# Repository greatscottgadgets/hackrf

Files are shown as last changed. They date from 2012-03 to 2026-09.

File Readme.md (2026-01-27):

# HackRF

This repository contains hardware designs and software for HackRF,
a low cost, open source Software Defined Radio platform.

HackRF One

(photo by fd0 from https://github.com/fd0/hackrf-one-pictures)

principal author: Michael Ossmann <mike@ossmann.com>

Information on HackRF and purchasing HackRF: https://greatscottgadgets.com/hackrf/

--------------------

# Documentation

Documentation for HackRF can be viewed on [Read the Docs](https://hackrf.readthedocs.io/en/latest/). The raw documentation files for HackRF are in the [docs folder](https://github.com/mossmann/hackrf/tree/master/docs) in this repository and can be built locally by installing [Sphinx Docs](https://www.sphinx-doc.org/en/master/usage/installation.html) and running `make html`. Documentation changes can be submitted through pull request and suggestions can be made as GitHub issues. 

To create a PDF of the HackRF documentation from the HackRF repository while on Ubuntu:
* run `sudo apt install latexmk texlive-latex-extra`
* navigate to hackrf/docs on command line
* run the command `make latex`
* run the command `make latexpdf`

--------------------

# Getting Help

Before asking for help with HackRF, check to see if your question is listed on the [troubleshooting page](https://hackrf.readthedocs.io/en/latest/troubleshooting.html).

For assistance with HackRF general use or development, please look at the [issues on the GitHub project](https://github.com/greatscottgadgets/hackrf/issues). This is the preferred place to ask questions so that others may locate the answer to your question in the future.

We invite you to join our community discussions on [Discord](https://discord.gg/rsfMw3rsU8). Note that while technical support requests are welcome here, we do not have support staff on duty at all times. Be sure to also submit an issue on GitHub if you've found a bug or if you want to ensure that your request will be tracked and not overlooked.

If you wish to see past discussions and questions about HackRF, you may also view the [mailing list archives](https://pairlist9.pair.net/pipermail/hackrf-dev/).

GitHub issues on this repository that are labelled "technical support" by Great Scott Gadgets employees can expect a response time of two weeks. We currently do not have expected response times for other GitHub issues or pull requests for this repository.

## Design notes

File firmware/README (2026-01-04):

The primary firmware source code for USB HackRF devices is hackrf_usb.  Most of
the other directories contain firmware source code for test and development.
The common directory contains source code shared by multiple HackRF firmware
projects.  The cpld directory contains HDL source for the CPLD.

The firmware is set up for compilation with the GCC toolchain available here:

https://developer.arm.com/open-source/gnu-toolchain/gnu-rm/downloads

Required dependency:

https://github.com/mossmann/libopencm3

If you are using git, the preferred way to install libopencm3 is to use the
submodule:

$ cd ..
$ git submodule init
$ git submodule update

To build and install a standard firmware image for HackRF One:

$ cd hackrf_usb
$ mkdir build
$ cd build
$ cmake ..
$ make
$ hackrf_spiflash -w hackrf_usb.bin

If you have a HackRF Pro, add -DBOARD=PRALINE to the cmake command.
If you have a Jawbreaker, add -DBOARD=JAWBREAKER to the cmake command.
If you have a rad1o, use -DBOARD=RAD1O instead.

If you get the "`arm-none-eabi-gcc` is not a full path and was not found in the PATH"
error during `cmake ..`, install the
[ARM GNU toolchain](https://developer.arm.com/Tools%20and%20Software/GNU%20Toolchain).
This toolchain is pre-packaged on many platforms and distributions, e.g. on Debian/Ubuntu
you can run `sudo apt-get install gcc-arm-none-eabi` to install it.

If you get the "ModuleNotFoundError: No module named 'yaml'" error during `make`,
run `pip install pyyaml` to install the Python yaml pip package.

It is possible to use a USB Device Firmware Upgrade (DFU) method to load
firmware into RAM.  This is normally only required to recover a device that has
had faulty firmware loaded, but it can also be useful for firmware developers.

For loading firmware into RAM with DFU you will need:

http://dfu-util.sourceforge.net/

To start up HackRF One or HackRF Pro in DFU mode, hold down the DFU button
while powering it on or while pressing and releasing the RESET button.  Release
the DFU button after the 3V3 LED illuminates.

A .dfu file is built by default when building firmware.  Alternatively you can
use a known good .dfu file from a release package.  Load the firmware into RAM
with:

$ dfu-util --device 1fc9:000c --alt 0 --download hackrf_usb.dfu

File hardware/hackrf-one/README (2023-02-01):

HackRF One is a wideband software radio transceiver with a USB interface.

hardware notes:

Schematic and layout files were designed in KiCad, an open source electronic
design automation package.

order of copper layers:
    Copper 1:  C1F (front)
    Copper 2:  C2
    Copper 3:  C3
    Copper 4:  C4B (back)

PCB description: 4 layer PCB 1.6 mm
    Copper    1   0.035 mm
    Prepreg 1-2   0.2104 mm
    Copper    2   0.0152 mm
    Core    2-3   1.065 mm
    Copper    3   0.0152 mm
    Prepreg 3-4   0.2104 mm
    Copper    4   0.035 mm

7628 prepreg with Er=4.6 (+/- 0.1)
required impedance: 50 ohm (+/- 5%) 11.55 mil microstrip impedance
double side solder mask green
single side silkscreen white
5 mil min trace width and
5 mil min isolation

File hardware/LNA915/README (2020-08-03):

Copyright (c) 2014-2020 Great Scott Gadgets <info@greatscottgadgets.com>

These files are part of HackRF.

This is a free hardware design; you can redistribute it and/or modify
it under the terms of the GNU General Public License as published by
the Free Software Foundation; either version 2, or (at your option)
any later version.

This design is distributed in the hope that it will be useful,
but WITHOUT ANY WARRANTY; without even the implied warranty of
MERCHANTABILITY or FITNESS FOR A PARTICULAR PURPOSE.  See the
GNU General Public License for more details.

You should have received a copy of the GNU General Public License
along with this design; see the file COPYING.  If not, write to
the Free Software Foundation, Inc., 51 Franklin Street,
Boston, MA 02110-1301, USA.

LNA915 is a SAW filter and LNA for the 902 to 928 MHz ISM band.  It is designed
for in-line connection between an antenna and HackRF One and is powered by the
HackRF One.

hardware notes:

Schematic and layout files were designed in KiCad, an open source electronic
design automation package.

The PCB is designed to fit the Crystek SMA-KIT-1.5MF housing.

order of copper layers:
    Copper 1:  F (front)
    Copper 2:  In1
    Copper 3:  In2
    Copper 4:  B (back)

PCB description: 4 layer PCB 0.8 mm
    Copper       1:  0.035 mm (1 oz)
    Dielectric 1-2:  0.2 mm prepreg
    Copper       2:  0.0175 mm (0.5 oz)
    Dielectric 2-3:  0.265 mm core
    Copper       3:  0.0175 mm (0.5 oz)
    Dielectric 3-4:  0.2 mm prepreg
    Copper       4:  0.035 mm (1 oz)

7628 prepreg with Er=4.6
double side solder mask green
double side silkscreen white
7 mil minimum trace width
5 mil minimum isolation

PCBs of this specification are available from JLCPCB (JLC7628 4-layer 0.8 mm stackup).

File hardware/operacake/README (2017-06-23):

Copyright 2012 - 2016 Great Scott Gadgets

These files are part of HackRF.

This is a free hardware design; you can redistribute it and/or modify
it under the terms of the GNU General Public License as published by
the Free Software Foundation; either version 2, or (at your option)
any later version.

This design is distributed in the hope that it will be useful,
but WITHOUT ANY WARRANTY; without even the implied warranty of
MERCHANTABILITY or FITNESS FOR A PARTICULAR PURPOSE.  See the
GNU General Public License for more details.

You should have received a copy of the GNU General Public License
along with this design; see the file COPYING.  If not, write to
the Free Software Foundation, Inc., 51 Franklin Street,
Boston, MA 02110-1301, USA.

Opera Cake is an RF switching add-on for HackRF One.

hardware notes:

Schematic and layout files were designed in KiCad, an open source electronic
design automation package.

order of copper layers:
    Copper 1:  C1F (front)
    Copper 2:  C2
    Copper 3:  C3
    Copper 4:  C4B (back)

PCB description: 4 layer PCB 0.0646 in
    Copper       1:  1 oz copper (1.4 mil)
    Dielectric 1-2:  6.7 mil prepreg
    Copper       2:  0.5 oz copper (0.7 mil)
    Dielectric 2-3:  47 mil core
    Copper       3:  0.5 oz copper (0.7 mil)
    Dielectric 3-4:  6.7 mil prepreg
    Copper       4:  1 oz copper (1.4 mil)

FR408 or similar substrate with Er=3.66 (+/- 0.1)
double side solder mask green
double side silkscreen white
6 mil min trace width and
6 mil min isolation

PCBs of this specification are available from OSH Park.

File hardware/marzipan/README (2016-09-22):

Copyright 2012 - 2016 Great Scott Gadgets

These files are part of HackRF.

This is a free hardware design; you can redistribute it and/or modify
it under the terms of the GNU General Public License as published by
the Free Software Foundation; either version 2, or (at your option)
any later version.

This design is distributed in the hope that it will be useful,
but WITHOUT ANY WARRANTY; without even the implied warranty of
MERCHANTABILITY or FITNESS FOR A PARTICULAR PURPOSE.  See the
GNU General Public License for more details.

You should have received a copy of the GNU General Public License
along with this design; see the file COPYING.  If not, write to
the Free Software Foundation, Inc., 51 Franklin Street,
Boston, MA 02110-1301, USA.

Marzipan is a wideband software radio transceiver capable of running Linux.

hardware notes:

Schematic and layout files were designed in KiCad, an open source electronic
design automation package.

order of copper layers:
    Copper 1:  C1F (front)
    Copper 2:  C2
    Copper 3:  C3
    Copper 4:  C4B (back)

PCB description: 4 layer PCB 0.062 in
    Copper        1   0.5 oz foil plated to approximately 0.0017 in
    Dielectric  1-2   0.0119 in
    Copper        2   1 oz foil (0.0014 in)
    Dielectric  2-3   0.0280 in
    Copper        3   1 oz foil (0.0014 in)
    Dielectric  3-4   0.0119 in
    Copper        4   0.5 oz foil plated to approximately 0.0017 in

FR4 or similar substrate with Er=4.5 (+/- 0.1)
double side solder mask green
single side silkscreen white
6 mil min trace width and
6 mil min isolation

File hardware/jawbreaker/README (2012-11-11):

Copyright 2012 Michael Ossmann

These files are part of HackRF.

This is a free hardware design; you can redistribute it and/or modify
it under the terms of the GNU General Public License as published by
the Free Software Foundation; either version 2, or (at your option)
any later version.

This design is distributed in the hope that it will be useful,
but WITHOUT ANY WARRANTY; without even the implied warranty of
MERCHANTABILITY or FITNESS FOR A PARTICULAR PURPOSE.  See the
GNU General Public License for more details.

You should have received a copy of the GNU General Public License
along with this design; see the file COPYING.  If not, write to
the Free Software Foundation, Inc., 51 Franklin Street,
Boston, MA 02110-1301, USA.

Jawbreaker is the first complete HackRF platform, a wideband software radio
transceiver with a USB interface.

hardware notes:

Schematic and layout files were designed in KiCad, an open source electronic
design automation package.

order of copper layers:
    Copper 1: Front
    Copper 2: Inner3
    Copper 3: Inner2
    Copper 4: Back

PCB description: 4 layer PCB 0.062 in
    Copper        1   0.5 oz foil plated to approximately 0.0017 in
    Dielectric  1-2   0.0119 in
    Copper        2   1 oz foil (0.0014 in)
    Dielectric  2-3   0.0280 in
    Copper        3   1 oz foil (0.0014 in)
    Dielectric  3-4   0.0119 in
    Copper        4   0.5 oz foil plated to approximately 0.0017 in
FR4 or similar substrate with Er=4.5 (+/- 0.1)
double side solder mask black
double side silkscreen white
6 mil min trace width and
6 mil min isolation

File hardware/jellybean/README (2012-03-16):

Copyright 2012 Michael Ossmann

These files are part of HackRF.

This is a free hardware design; you can redistribute it and/or modify
it under the terms of the GNU General Public License as published by
the Free Software Foundation; either version 2, or (at your option)
any later version.

This design is distributed in the hope that it will be useful,
but WITHOUT ANY WARRANTY; without even the implied warranty of
MERCHANTABILITY or FITNESS FOR A PARTICULAR PURPOSE.  See the
GNU General Public License for more details.

You should have received a copy of the GNU General Public License
along with this design; see the file COPYING.  If not, write to
the Free Software Foundation, Inc., 51 Franklin Street,
Boston, MA 02110-1301, USA.

Jellybean is a microcontroller platform based on the LPC43xx.  It is designed
to control Lemondrop.

hardware notes:

Schematic and layout files were designed in KiCad, an open source electronic
design automation package.

order of copper layers:
    Front
    Inner3
    Inner2
    Back

PCB description: 4 layer PCB 1.6 mm
    Copper        1   35 um
    Dielectric  1-2   0.35 mm
    Copper        2   18 um
    Dielectric  2-3   0.76 mm
    Copper        3   18 um
    Dielectric  3-4   0.35 mm
    Copper        4   35 um
DE104iML or equivalent substrate (Er=4.42@2.4GHz TanD=0.016)
double side solder mask black
double side silkscreen white
6 mil min trace width and
6 mil min isolation

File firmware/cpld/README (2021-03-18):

The primary CPLD image is: sgpio_if/default.xsvf

This is a binary file built from HDL source in sgpio_if.  You do not need
Xilinx tools unless you want to make your own modifications.

CPLD images are automatically included in HackRF firmware.  You do not normally
need to update the bitstream stored in the CPLD's flash memory as it is
superseded by the image loaded into SRAM by the firmware.

If you want to update the bitstream in CPLD flash for some reason, first update
the firmware, libhackrf, and hackrf-tools.
Then:

$ hackrf_cpldjtag -x sgpio_if/default.xsvf

After a few seconds, three LEDs should start blinking.  This indicates that the
CPLD has been programmed successfully.  Reset the HackRF device by pressing the
RESET button or by unplugging it and plugging it back in.

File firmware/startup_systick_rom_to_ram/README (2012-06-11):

This program is an example of the startup sequence for HackRF (Jellybean with
Lemondrop attached).
LED1, LED2, and LED3 are blinking at exactly a frequency of 1Hz upon success.

Required Lemondrop -> Jellybean connections:

SCL: Lemondrop P7 pin 3 -> Jellybean P6 pin 3
SDA: Lemondrop P7 pin 5 -> Jellybean P6 pin 5
SDA: Lemondrop P7 pin 6 -> Jellybean P6 pin 6
VCC: Lemondrop P4 pin 2, 4, or 6 -> Jellybean P17 pin 2, 4, or 6
1V8: Lemondrop P11 pin 2, 4, or 6 -> Jellybean P16 pin 2, 4, or 6
GND: Lemondrop P5 -> Jellybean P13

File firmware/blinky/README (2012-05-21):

This is the simplest example firmware for HackRF.  It flashes three LEDs.

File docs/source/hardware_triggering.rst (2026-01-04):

.. _hardware_triggering:

===================
Hardware Triggering
===================

HackRF transmit and receive operations can be synchronized with another HackRF or with other external equipment by using the trigger input and output. Triggering provides time synchronization with error of less than one sample period.

HackRF Pro has two configurable SMA ports, P1 and P2, which can be set up to provide both clock synchronization and triggering.

HackRF One has CLKIN and CLKOUT ports for clock synchronization, but hardware triggering requires opening the case to access the P28 header.

Clock Synchronization
~~~~~~~~~~~~~~~~~~~~~

When triggering one HackRF from another, it is often desirable to first ensure that the two devices share a common frequency reference. This has an added benefit of grounding the HackRFs to each other, eliminating one of the wires required for triggering. See :ref:`External Clock Interface <external_clock_interface>` for instructions.

Either HackRF may serve as the clock source for the other regardless of which is providing the trigger output.

Usage
~~~~~

Use ``hackrf_info`` to discover the serial numbers of both HackRFs. Using the serial number of the HackRF to be triggered, use ``hackrf_transfer -H`` to set up a triggered operation. For example:

* ``hackrf_transfer -H -d <serial number> -a 0 -l 32 -g 32 -r rx1.cs8``

The command will print "Waiting for trigger..." until a trigger signal is detected on the device's trigger input.

In another terminal, use the serial number of the triggering HackRF One to initiate an operation to take place at the same time as the triggered operation. For example:

* ``hackrf_transfer -d <serial number> -a 0 -l 32 -g 32 -r rx2.cs8``

Note that no special argument is required to activate the trigger output.

Both ``hackrf_transfer`` commands will start sampling RF signals at the same time, accurate to less than one sample period.

Additional Devices
~~~~~~~~~~~~~~~~~~

Multiple HackRFs may be triggered by a single HackRF. Ensure that all the devices share a common ground and then connect one device's trigger output to the trigger inputs of the other devices (with jumpers connected via a breadboard, for example).

Equipment other than a HackRF may be connected to a HackRF's trigger input or output. The trigger signal is a 3.3 V pulse that triggers on the rising edge.

HackRF One Triggering Requirements
~~~~~~~~~~~~~~~~~~~~~~~~~~~~~~~~~~

To connect two HackRF Ones for triggering you will need:

    * a male-to-male jumper wire for 0.1" pin headers
    * an SMA cable for clock synchronization or a second jumper wire

.. _open_your_hackrf_one:

Open Your HackRF One
~~~~~~~~~~~~~~~~~~~~

If your HackRF Ones are not bare boards, you will need to open up their cases to access the pin headers on the HackRF Ones. Each HackRF One case has small plastic clips holding it together. These clips may be damaged when the case is opened, but typically the case can still be used after such damage. Please follow the instructions in `this video <https://www.youtube.com/watch?v=zuXJtpTSEJM>`__ by `Jared Boone <https://twitter.com/sharebrained>`__ to open your HackRF One cases.

Identify the Trigger Pins
~~~~~~~~~~~~~~~~~~~~~~~~~

HackRF One has four normally-populated pin headers, three of which are arranged in a 'C' shape. On the circuit board these are marked P28, P22, and P20. P28 is the header nearest to the center of the board. Locate pins 15 (trigger output) and 16 (trigger input) on header P28.

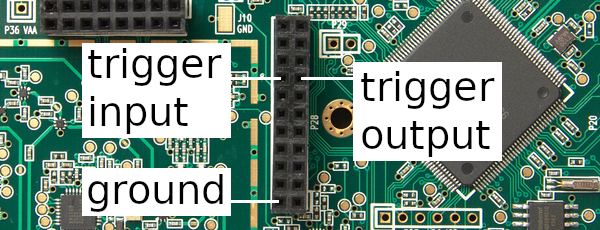
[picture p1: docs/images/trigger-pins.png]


Connect the Trigger Output to the Trigger Input
~~~~~~~~~~~~~~~~~~~~~~~~~~~~~~~~~~~~~~~~~~~~~~~

First ensure that the two devices share a common ground. This may be accomplished by connecting one's CLKIN to the other's CLKOUT as recommended above. Alternatively, connect a jumper wire from P28 pin 2 on one HackRF One to P28 pin 2 on the other HackRF One.

Next use a jumper wire to connect P28 pin 15 (trigger output) on one HackRF One to P28 pin 16 (trigger input) on the other HackRF One.

References
~~~~~~~~~~

HackRF's trigger mechanism was contributed by the authors of `Synchronisation of Low-Cost Open Source SDRs for Navigation Applications <http://spcomnav.uab.es/docs/conferences/Bartolucci_NAVITEC_2016.pdf>`__ which provides details about the implementation and background.

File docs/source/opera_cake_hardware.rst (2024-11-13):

========
Hardware
========

Block Diagram
~~~~~~~~~~~~~

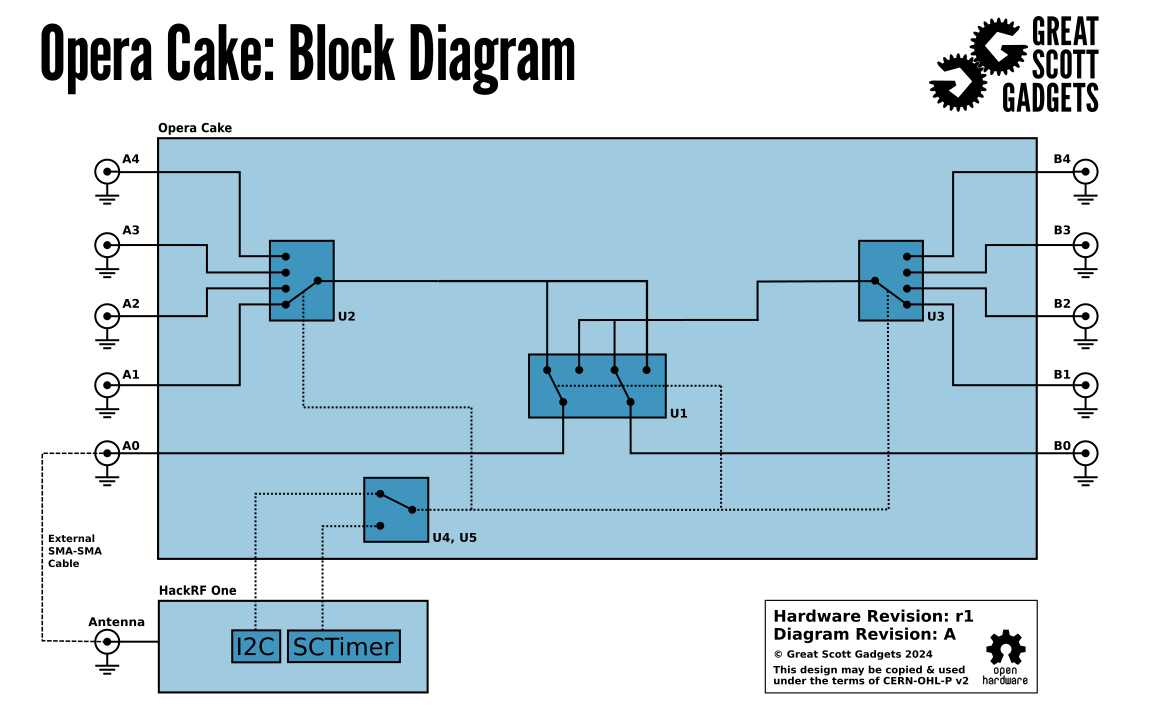
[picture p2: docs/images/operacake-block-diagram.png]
Opera Cake Block Diagram


Banks
~~~~~

The ports on Opera Cake are grouped in two banks (or "sides"), one on each end of the board. Bank A consists of ports A0 through A4 while bank B consists of ports B0 through B4.

Ports
~~~~~

Opera Cake has two primary ports, A0 and B0, each of which can be switched to any of eight secondary ports, A1-A4 and B1-B4. Each primary port is always connected to one secondary port. By default, A0 is connected to A1, and B0 is connected to B1. It is not possible to connect both primary ports to secondary ports in the same bank at the same time.

LEDs
~~~~

Port selections are indicated by LEDs next to each port's connector. Port A0 and the secondary port connected to A0 are indicated with a green LED. Port B0 and the secondary port connected to B0 are indicated with a yellow LED.

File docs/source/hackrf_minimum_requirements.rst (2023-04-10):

============================================
Minimum Host System Requirements for HackRF
============================================

HackRF requires you to supply 500 mA at 5 V DC to your HackRF via the USB port. If your host computer has difficulty meeting this requirement, you may need to use a powered USB hub.

There is no specific minimum CPU requirement for the host computer when using a HackRF, but SDR is generally a CPU-intensive application. If you have a slower CPU, you may be unable to run certain SDR software or you may only be able to operate at lower sample rates.

Most users will want to stream data to or from the HackRF at high speeds. This requires that the host computer supports Hi-Speed USB. Some Hi-Speed USB hosts are better than others, and you may have multiple host controllers on your computer. If you have difficulty operating your HackRF at high sample rates (10 Msps to 20 Msps), try using a different USB port on your computer. If possible, arrange things so that the HackRF is the only device on the bus.

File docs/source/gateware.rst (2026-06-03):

================================================
Gateware
================================================

One of the significant hardware changes in :ref:`HackRF Pro <hackrf_pro>` is the replacement of the CPLD with a FPGA. While the older CPLD primarily provided glue logic between the MCU and RF front end, the FPGA in HackRF Pro introduces more logic and DSP capability. This enables offloading digital signal processing tasks from the MCU.

FPGAs are highly flexible devices whose behavior is defined by *gateware*: hardware descriptions that configure the internal logic fabric. HackRF Pro gateware is written in `Amaranth HDL <https://amaranth-lang.org/>`__, a Python-based hardware description language.

The specific FPGA device used in HackRF Pro is the Lattice iCE40UP5K, which features 
5280 LUT4s and 8 dedicated DSP (multiply-accumulate) blocks. We rely on the `open-source iCE40 FPGA toolchain <https://github.com/YosysHQ/icestorm>`__ to build the required bitstreams that are bundled in the firmware.

All gateware source code lives under `firmware/fpga/` in the HackRF repository. Top-level designs reside in `firmware/fpga/top/` and are the primary entry points for different operational modes.

By default, a standard gateware configuration is loaded at boot. However, the firmware can dynamically reconfigure the FPGA at runtime to switch between different gateware variants.

Standard gateware
~~~~~~~~~~~~~~~~~

The standard gateware is used by default when the firmware has not requested an alternative bitstream.

The standard gateware provides a balanced configuration optimized for general-purpose operation. It implements configurable digital signal processing paths for the reception and transmission paths, capable of (limited) frequency translation and supporting a wide range of sample rates.

Block diagram
^^^^^^^^^^^^^

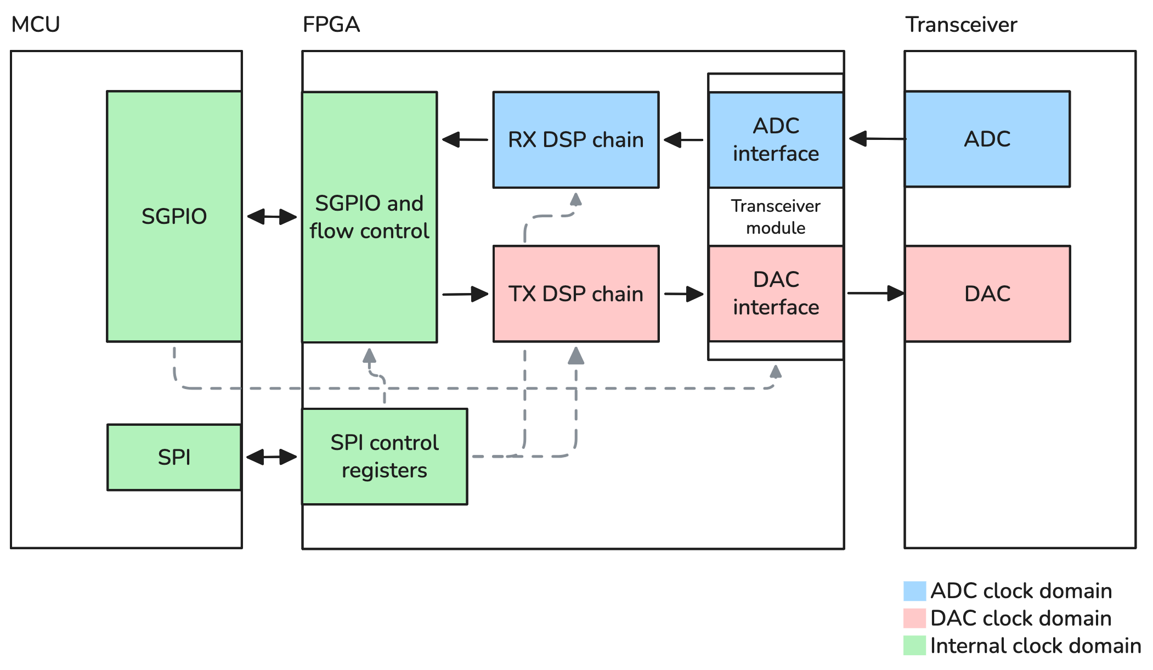
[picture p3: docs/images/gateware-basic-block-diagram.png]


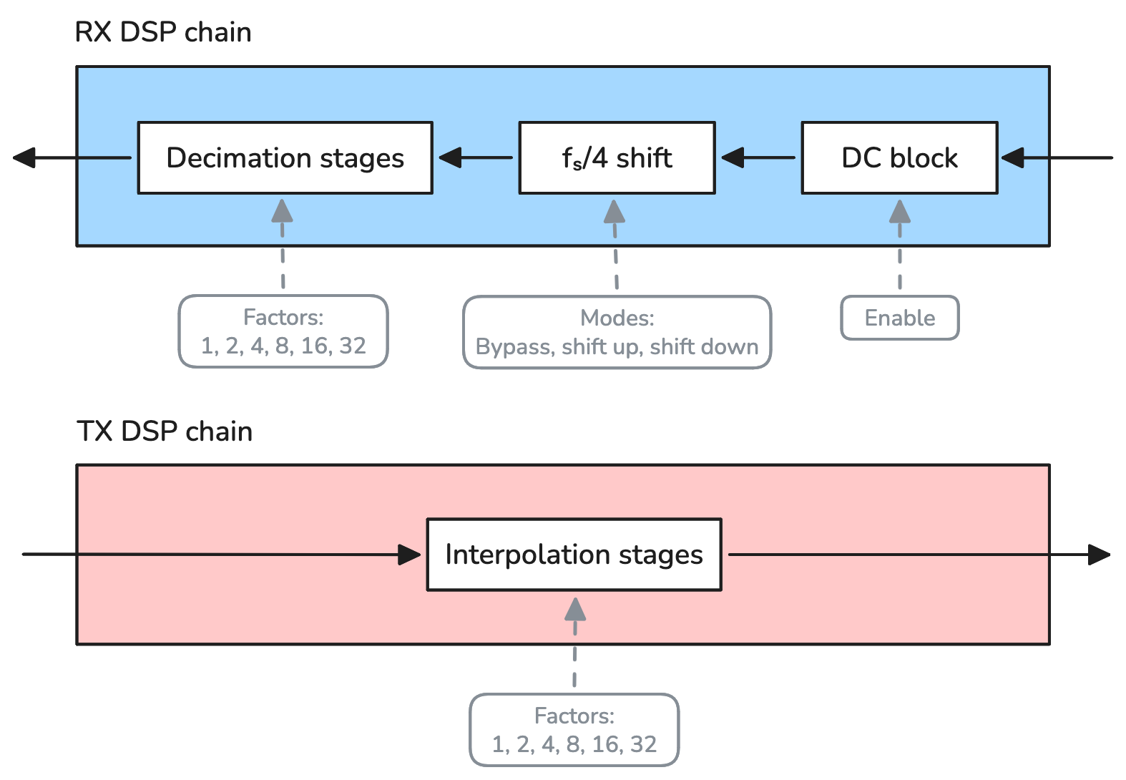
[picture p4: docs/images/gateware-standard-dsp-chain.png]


Features
^^^^^^^^
* 8-bit I, 8-bit Q data format
* Receiver signal chain:
    * Optional DC offset removal (DC blocker)
    * Configurable fs/4 shifter (quarter sample rate): bypass, shift up or shift down
    * Configurable decimation rates: 1x, 2x, 4x, 8x, 16x, 32x
* Transmitter signal chain:
    * Configurable interpolation rates: 1x, 2x, 4x, 8x, 16x, 32x
* SPI control interface for register configuration
* Double data rate (DDR) interface to RF transceiver
* Interface to MCU (SGPIO)

Half-precision gateware
~~~~~~~~~~~~~~~~~~~~~~~

The half-precision gateware reduces sample width to 4 bits per I/Q component, enabling higher throughput within the constraints of the USB interface (up to 40 Msps).

This configuration is intended for applications where bandwidth is more critical than dynamic range, such as wideband spectrum monitoring.

Block diagram
^^^^^^^^^^^^^



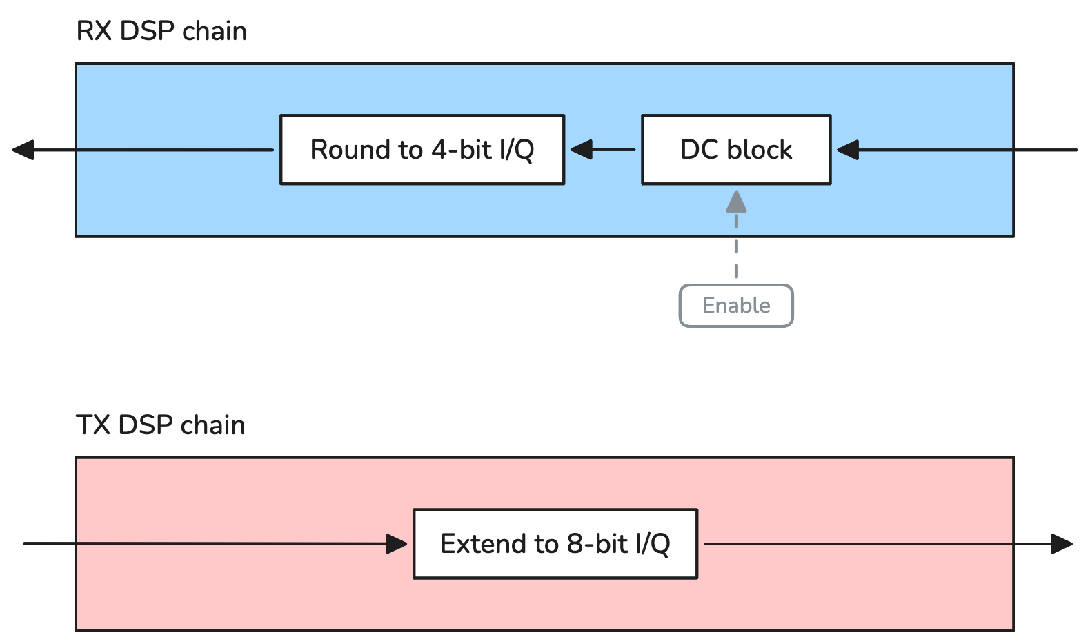
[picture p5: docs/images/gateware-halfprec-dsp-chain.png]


Features
^^^^^^^^
* 4-bit I, 4-bit Q data format
* Receiver signal chain:
    * Optional DC offset removal (DC blocker)
    * Round to 4-bit I/Q
* Transmitter signal chain:
    * Extend width to 8-bit I/Q
* SPI control interface for register configuration
* Double data rate (DDR) interface to RF transceiver
* Interface to MCU (SGPIO)

Extended-precision gateware (RX and TX)
~~~~~~~~~~~~~~~~~~~~~~~~~~~~~~~~~~~~~~~

The extended-precision gateware increases internal signal processing precision and output sample width to improve signal quality. The main drawback is that the minimum decimation or interpolation factor is 16x. Due to increased logic requirements, this gateware is split in two top-level designs (RX and TX).

Samples are 16-bit I/Q, while the effective number of bits (ENOB) depends on the selected configuration and typically ranges between 9 and 11 bits.

The increased dynamic range of the output makes it particularly useful for weak and/or narrowband signals.

Block diagram (RX)
^^^^^^^^^^^^^^^^^^

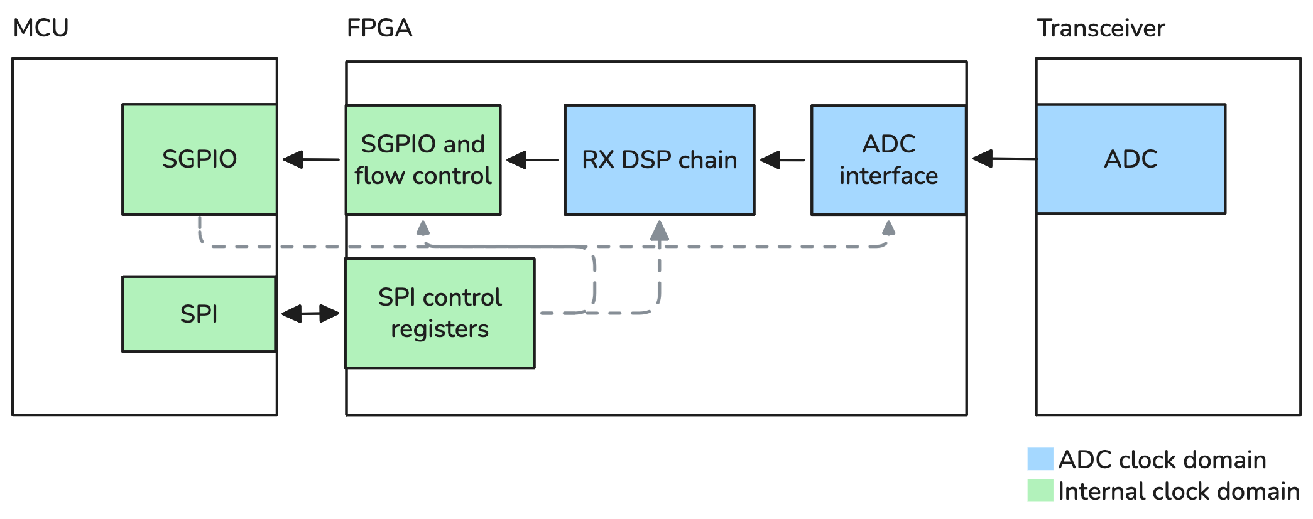
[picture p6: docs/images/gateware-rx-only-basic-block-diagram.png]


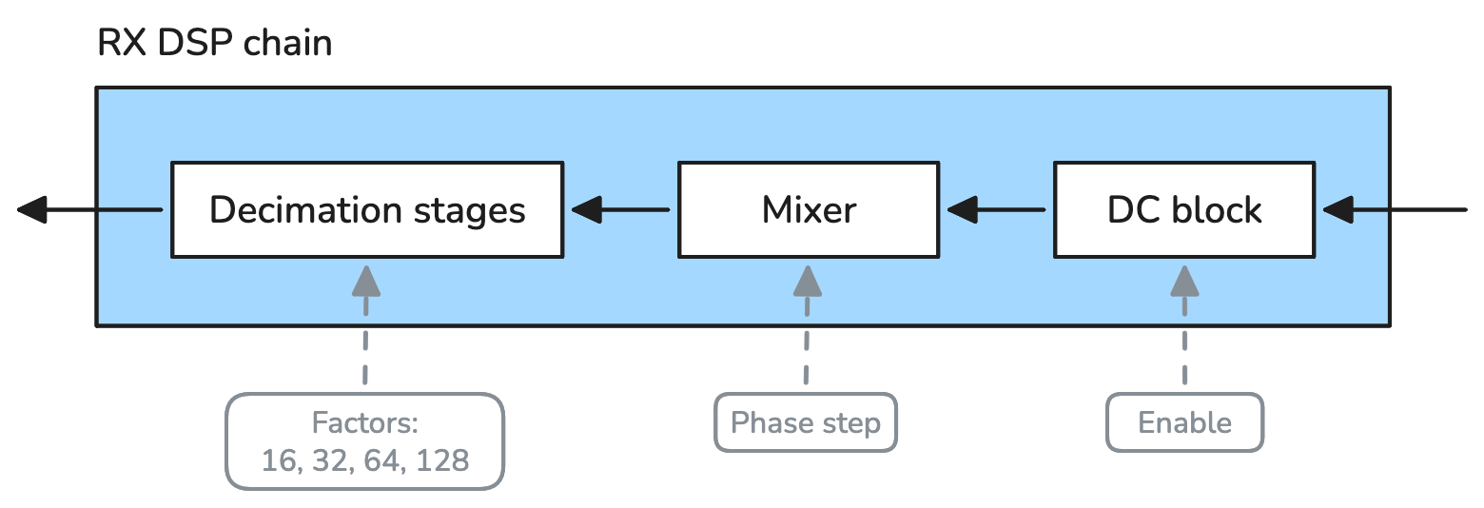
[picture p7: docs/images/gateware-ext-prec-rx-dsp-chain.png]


Block diagram (TX)
^^^^^^^^^^^^^^^^^^

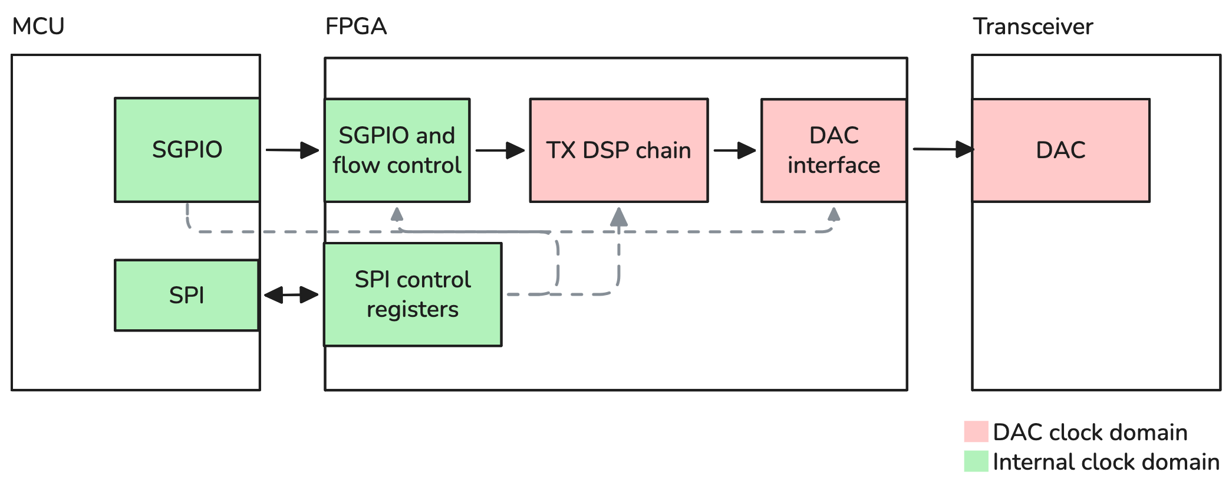
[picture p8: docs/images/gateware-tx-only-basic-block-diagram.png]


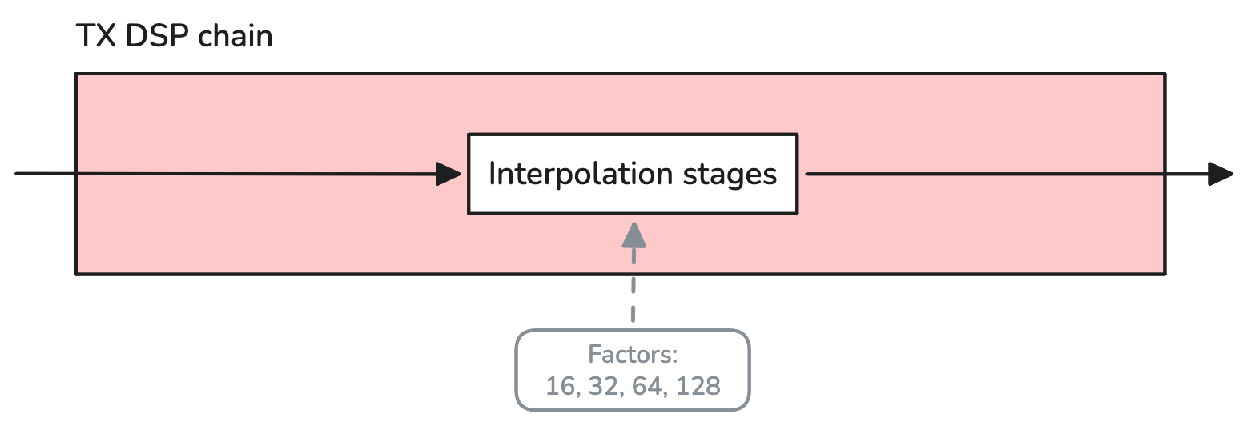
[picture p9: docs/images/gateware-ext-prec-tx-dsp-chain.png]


Features
^^^^^^^^
* 16-bit I, 16-bit Q data format
* Receiver signal chain (RX extended-precision gateware):
    * Optional DC offset removal (DC blocker)
    * Configurable mixer (in fs/128 steps)
    * Configurable decimation rates: 16x, 32x, 64x, 128x
* Transmitter signal chain (TX extended-precision gateware):
    * Configurable interpolation rates: 16x, 32x, 64x, 128x
* SPI control interface for register configuration
* Double data rate (DDR) interface to RF transceiver
* Interface to MCU (SGPIO)

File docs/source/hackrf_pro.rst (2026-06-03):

================================================
HackRF Pro
================================================

.. _hackrf_pro:

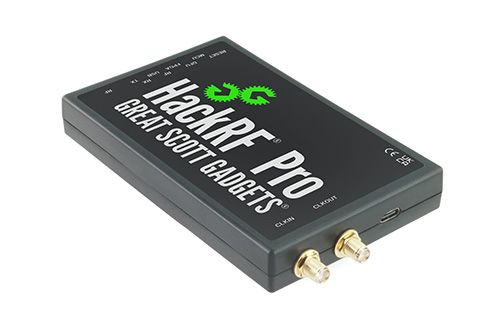
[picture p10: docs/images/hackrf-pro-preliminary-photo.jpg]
HackRF Pro


HackRF Pro is the current hardware platform for the HackRF project. It is a Software Defined Radio peripheral capable of transmission or reception of radio signals from 100 kHz to 6 GHz. HackRF Pro is designed to be backwards compatible with software and hardware developed for use with
:ref:`HackRF One <hackrf_one>`,
whilst introducing many new features and improvements.

| `Product page <https://greatscottgadgets.com/hackrf/pro/>`_
| `Where to buy <https://greatscottgadgets.com/hackrf/pro/#purchasing>`_

Features
~~~~~~~~

    * 100 kHz to 6 GHz operating frequency
    * Tunable from 0 Hz to 7.1 GHz
    * Half-duplex transceiver
    * Up to 20 million samples per second
    * 8-bit quadrature samples (8-bit I and 8-bit Q)
    * Compatible with GNU Radio, SDR#, and more
    * Software-configurable RX and TX gain and baseband filter
    * Software-controlled RF port power (50 mA at 3.3 V)
    * SMA RF connector
    * SMA clock input and output for synchronization and triggering
    * Convenient buttons for programming
    * Internal pin headers for expansion
    * High-Speed USB 2.0 with Type-C connector
    * USB-powered
    * Open source hardware

Compared to HackRF One, HackRF Pro introduces a host of new and updated features, including:

    * Wider operating frequency range
    * Improved RF performance with flatter frequency response
    * Modern USB Type-C connector
    * Built-in TCXO crystal oscillator for superior timing stability
    * Logic upgrade from a CPLD to a power-efficient FPGA
    * Elimination of the DC spike
    * Extended-precision mode with 16-bit samples for low sample rates (typical ENOB: 9-11)
    * Half-precision mode with 4-bit samples at up to 40 Msps
    * More RAM and flash memory for custom firmware
    * Installed shielding around the radio section
    * Trigger input and output accessible through clock connectors
    * Cutout in the PCB provides space for future add-ons
    * Improved power management
    * Enhanced RF port protection
    * Facility to hardware-disable transmit mode

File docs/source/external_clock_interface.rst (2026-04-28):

========================
External Clock Interface
========================

.. _external_clock_interface:

HackRF Pro
~~~~~~~~~~

HackRF Pro has two configurable SMA ports, P1 and P2. By default, P1 is configured as CLKIN and P2 as CLKOUT. The default behaviour of these signals is as described for HackRF One below.

A second CLKIN signal is available on header P22 pin 2. Unlike HackRF One, HackRF Pro's P22_CLKIN is a separate signal from P1_CLKIN. To enable P22_CLKIN instead of P1_CLKIN use ``hackrf_clock -c p22``.

Various internal signals can be connected to P1 or P2 instead of the default CLKIN and CLKOUT signals. Use ``hackrf_clock -1`` or ``hackrf_clock -2`` to select a different signal.

HackRF One
~~~~~~~~~~

HackRF One produces a 10 MHz clock signal on the CLKOUT SMA port. The signal is a 3.3 V, 10 MHz square wave intended for a high impedance load.

The CLKIN SMA port on HackRF One is a high impedance input that expects 3.3 V square wave at 10 MHz. Do not exceed 3.3 V or drop below 0 V on this input. Do not connect a clock signal at a frequency other than 10 MHz (unless you modify the firmware to support this). You may directly connect the CLKOUT port of one HackRF One to the CLKIN port of another HackRF.

The CLKIN signal is also connected to header P22 pin 2. Unlike HackRF Pro, HackRF One has only one CLKIN signal shared between P22 pin 2 and the CLKIN port. Do not connect input signals to both CLKIN and P22 pin 2 simultaneously.

HackRF One uses CLKIN instead of the internal crystal when a clock signal is detected on CLKIN. The switch to or from CLKIN only happens when a transmit or receive operation begins.

To verify that a signal has been detected on CLKIN, use ``hackrf_clock -i``. The expected output with a clock detected is `CLKIN status: clock signal detected`. The expected output with no clock detected is `CLKIN status: no clock signal detected`.

To activate CLKOUT, use ``hackrf_clock -o 1``. To switch it off, use ``hackrf_clock -o 0``.

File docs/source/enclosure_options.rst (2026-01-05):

Enclosure Options
~~~~~~~~~~~~~~~~~

Commercial versions of both HackRF Pro and HackRF One from Great Scott Gadgets ship with an injection molded plastic enclosure but are also designed to fit two optional enclosures:

    * Hammond 1455J1201: Both HackRF Pro and HackRF One fit this extruded aluminum enclosure and other similar models from Hammond Manufacturing. In order to use the enclosure's end plates, you will have to drill them. An end plate template can be found in the HackRF One KiCad layout.

    * Acrylic sandwich: You can also use a laser cut acrylic enclosure with either HackRF Pro or HackRF One. This is a good option for access to the expansion headers. A design can be found in the HackRF hardware directory. Use any laser cutting service or purchase from a `reseller <https://greatscottgadgets.com/hackrf/acrylic-case/>`__.

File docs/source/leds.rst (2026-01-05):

====
LEDs
====

HackRF Pro
~~~~~~~~~~

When HackRF Pro is plugged in to a USB host, four LEDs should turn on: MCU, FPGA, RF, and USB. The MCU LED indicates that the primary internal power supply is working properly and that firmware is running. The FPGA and RF LEDs indicate that firmware has switched on additional internal power supplies. The USB LED indicates that the HackRF Pro is communicating with the host over USB.

HackRF One
~~~~~~~~~~

When HackRF One is plugged in to a USB host, four LEDs should turn on: 3V3, 1V8, RF, and USB. The 3V3 LED indicates that the primary internal power supply is working properly. The 1V8 and RF LEDs indicate that firmware is running and has switched on additional internal power supplies. The USB LED indicates that the HackRF One is communicating with the host over USB.

Both versions
~~~~~~~~~~~~~

The RX and TX LEDs indicate that a receive or transmit operation is currently in progress.

Each LED is a single color. There are no multi-colored LEDs on either HackRF One or HackRF Pro. Adjacent LEDs are different colors in order to make them easier to distinguish from one another. The colors do not mean anything.

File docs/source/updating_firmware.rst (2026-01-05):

.. _updating_firmware:

================================================
Updating Firmware
================================================

HackRF devices ship with firmware on the SPI flash memory. The firmware can be updated with a USB cable and host computer.

These instructions allow you to upgrade the firmware in order to take advantage of new features or bug fixes.

Updating the SPI Flash Firmware
~~~~~~~~~~~~~~~~~~~~~~~~~~~~~~~

To update the firmware on HackRF Pro, use the hackrf_spiflash program:

.. code-block :: sh

	hackrf_spiflash -w hackrf_pro_usb.bin

You can find the firmware binary (hackrf_pro_usb.bin) in the firmware-bin directory of the latest `release package <https://github.com/greatscottgadgets/hackrf/releases/latest>`__ or you can compile your own from the `source <https://github.com/greatscottgadgets/hackrf/tree/master/firmware>`__. For HackRF One or other platforms, use the ".bin" file with the appropriate name for your platform such as hackrf_one_usb.bin. If you compile from source, the file will be called hackrf_usb.bin.

The hackrf_spiflash program is part of hackrf-tools.

When writing a firmware image to SPI flash, be sure to select firmware with a filename ending in ".bin".

After writing the firmware to SPI flash, you may need to reset the HackRF device by pressing the RESET button or by unplugging it and plugging it back in.

If you get an error that mentions HACKRF_ERROR_NOT_FOUND, it is often a permissions problem on your OS.

.. _recovering_firmware:

Only if Necessary: Recovering the SPI Flash Firmware
~~~~~~~~~~~~~~~~~~~~~~~~~~~~~~~~~~~~~~~~~~~~~~~~~~~~

If the firmware installed in SPI flash has been damaged or if you are programming a home-made HackRF for the first time, you will not be able to immediately use the hackrf_spiflash program as listed in the above procedure. Follow these steps instead:

    #. Follow the DFU Boot instructions to start the HackRF in DFU boot mode.
    #. Type ``dfu-util --device 1fc9:000c --alt 0 --download hackrf_pro_usb.dfu`` to load firmware from a release package into RAM. For HackRF One or other platforms, use the ".dfu" file with the appropriate name for your platform such as hackrf_one_usb.dfu.
    #. Follow the SPI flash firmware update procedure above to write the ".bin" firmware image to SPI flash.

Only if Necessary: DFU Boot
~~~~~~~~~~~~~~~~~~~~~~~~~~~

DFU boot mode is normally only needed if the firmware is not working properly or has never been installed.

The LPC43xx microcontroller on HackRF is capable of booting from several different code sources. By default, HackRF boots from SPI flash memory (SPIFI). It can also boot HackRF in DFU (USB) boot mode. In DFU boot mode, HackRF will enumerate over USB, wait for code to be delivered using the DFU (Device Firmware Update) standard over USB, and then execute that code from RAM. The SPIFI is normally unused and unaltered in DFU mode.

To start up HackRF Pro or HackRF One in DFU mode, hold down the DFU button while powering it on or while pressing and releasing the RESET button. Then release the DFU button. On HackRF One, the 3V3 LED should illuminate. On HackRF Pro, all LEDs should remain off. At this point the HackRF is ready to receive firmware over USB.

To start up Jawbreaker in DFU mode, short two pins on one of the "BOOT" headers while power is first supplied. The pins that must be shorted are pins 1 and 2 of header P32 on Jawbreaker. Header P32 is labeled "P2_8" on most Jawbreakers but may be labeled "2" on prototype units. Pin 1 is labeled "VCC". Pin 2 is the center pin. After DFU boot, you should see VCCLED illuminate and note that 1V8LED does not illuminate. At this point Jawbreaker is ready to receive firmware over USB.

You should only use a firmware image with a filename ending in ".dfu" over DFU, not firmware ending in ".bin".

Obtaining DFU-Util
~~~~~~~~~~~~~~~~~~

On fresh installs of your OS, you may need obtain a copy of DFU-Util. For most Linux distributions it should be available as a package, for example on Debian/Ubuntu

.. code-block :: sh

	sudo apt-get install dfu-util

If you are using a platform without a dfu-util package, build instruction can be found `here on the dfu-util source forge build page <http://dfu-util.sourceforge.net/build.html>`__.

.. code-block :: sh

	cd ~
	sudo apt-get build-dep dfu-util
	sudo apt-get install libusb-1.0-0-dev
	git clone git://git.code.sf.net/p/dfu-util/dfu-util
	cd dfu-util
	./autogen.sh
	./configure
	make
	sudo make install

Now you will have the current version of DFU Util installed on your system.

Updating the CPLD
~~~~~~~~~~~~~~~~~

Older versions of HackRF firmware (prior to release 2021.03.1) require an additional step to program a bitstream into the CPLD.

To update the CPLD image, first update the SPI flash firmware, libhackrf, and hackrf-tools to the version you are installing. Then:

.. code-block :: sh

	hackrf_cpldjtag -x firmware/cpld/sgpio_if/default.xsvf

After a few seconds, three LEDs should start blinking. This indicates that the CPLD has been programmed successfully. Reset the HackRF device by pressing the RESET button or by unplugging it and plugging it back in.

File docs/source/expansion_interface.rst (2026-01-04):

Expansion Interface
~~~~~~~~~~~~~~~~~~~

The common HackRF expansion interface consists of headers P20, P22, and P28. These headers are present on both HackRF Pro and HackRF One, and support hardware add-ons including PortaPack and Opera Cake.

P20 GPIO
^^^^^^^^

Providing access to GPIO, ADC, RTC, and power.

.. list-table :: 
  :header-rows: 1
  :widths: 1 1 

  * - Pin 
    - Function
  * - 1   
    - VBAT
  * - 2   
    - RTC_ALARM (One) / PB_5 (Pro)
  * - 3   
    - VCC (One) / 3V3AUX (Pro)
  * - 4   
    - WAKEUP
  * - 5   
    - GPIO3_8
  * - 6   
    - GPIO3_0 (One) / GPIO3_9 (Pro)
  * - 7   
    - GPIO3_10
  * - 8   
    - GPIO3_11
  * - 9   
    - GPIO3_12
  * - 10  
    - GPIO3_13
  * - 11  
    - GPIO3_14
  * - 12  
    - GPIO3_15
  * - 13  
    - GND
  * - 14  
    - ADC0_6
  * - 15  
    - GND
  * - 16  
    - ADC0_2
  * - 17  
    - VBUSCTRL
  * - 18  
    - ADC0_5
  * - 19  
    - GND
  * - 20  
    - ADC0_0
  * - 21  
    - VBUS
  * - 22  
    - VIN

P22 I2S
^^^^^^^

I2S, SPI, I2C, UART, GPIO, and clocks.

.. list-table :: 
  :header-rows: 1
  :widths: 1 1 

  * - Pin     
    - Function
  * - 1   
    - CLKOUT (One) / P2 (Pro)
  * - 2   
    - CLKIN
  * - 3   
    - RESET
  * - 4   
    - GND
  * - 5   
    - I2C1_SCL
  * - 6   
    - I2C1_SDA
  * - 7   
    - SPIFI_MISO (One) / PB_1 (Pro)
  * - 8   
    - SPIFI_SCK (One) / PB_3 (Pro)
  * - 9   
    - SPIFI_MOSI (One) / PA_4 (Pro)
  * - 10  
    - GND
  * - 11  
    - VCC (One) / 3V3AUX (Pro)
  * - 12  
    - I2S0_RX_SCK (One) / PA_3 (Pro)
  * - 13  
    - I2S0_RX_SDA (One) / I2S0_TX_SDA (Pro)
  * - 14  
    - I2S0_RX_MCLK (One) / PB_0 (Pro)
  * - 15  
    - I2S0_RX_WS
  * - 16  
    - I2S0_TX_SCK
  * - 17  
    - I2S0_TX_MCLK
  * - 18  
    - GND
  * - 19  
    - U0_RXD
  * - 20  
    - U0_TXD
  * - 21  
    - P2_9
  * - 22  
    - P2_13
  * - 23  
    - P2_8
  * - 24  
    - SDA
  * - 25  
    - CLK6 (One) / AUX_CLK2 (Pro)
  * - 26  
    - SCL

P28 SD
^^^^^^

SDIO, GPIO, clocks, and CPLD.

.. list-table :: 
  :header-rows: 1
  :widths: 1 1 

  * - Pin     
    - Function
  * - 1   
    - VCC (One) / 3V3AUX (Pro)
  * - 2   
    - GND
  * - 3   
    - SD_CD
  * - 4   
    - SD_DAT3
  * - 5   
    - SD_DAT2
  * - 6   
    - SD_DAT1
  * - 7   
    - SD_DAT0
  * - 8   
    - SD_VOLT0
  * - 9   
    - SD_CMD
  * - 10  
    - SD_POW
  * - 11  
    - SD_CLK
  * - 12  
    - GND
  * - 13  
    - GCK2 (One) / P5_6 (Pro)
  * - 14  
    - GCK1 (One) / P5_7 (Pro)
  * - 15  
    - Trigger out: B1AUX14 (One) / TRIGGER.OUT (Pro)
  * - 16  
    - Trigger in: B1AUX13 (One) / TRIGGER.IN (Pro)
  * - 17  
    - CPLD_TCK
  * - 18  
    - BANK2F3M2 (One) / PE_0 (Pro)
  * - 19  
    - CPLD_TDI (One) / I2S0_RX_SDA (Pro)
  * - 20  
    - BANK2F3M6 (One) / P9_1 (Pro)
  * - 21  
    - BANK2F3M12 (One) / P5_3 (Pro)
  * - 22  
    - BANK2F3M4 (One) / P1_7 (Pro)

P9 Baseband (HackRF One)
^^^^^^^^^^^^^^^^^^^^^^^^

A direct analog interface to the high speed dual ADC and dual DAC.

.. list-table ::
  :header-rows: 1
  :widths: 1 1

  * - Pin
    - Function
  * - 1
    - GND
  * - 2
    - GND
  * - 3
    - GND
  * - 4
    - RXBBQ-
  * - 5
    - RXBBI-
  * - 6
    - RXBBQ+
  * - 7
    - RXBBI+
  * - 8
    - GND
  * - 9
    - GND
  * - 10
    - TXBBI-
  * - 11
    - TXBBQ+
  * - 12
    - TXBBI+
  * - 13
    - TXBBQ-
  * - 14
    - GND
  * - 15
    - GND
  * - 16
    - GND

Additional unpopulated headers and test points are available for test and development, but they may be incompatible with some enclosure or expansion options.

Refer to the schematics and component documentation for more information.

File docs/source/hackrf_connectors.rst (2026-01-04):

==========
Connectors
==========

The connectors on both HackRF Pro and HackRF One are SMA.

**Note:** SMA connectors and RP-SMA connectors are visually very similar. If you connect an RP-SMA antenna to a HackRF, it will seem to connect snugly but won't function at all because neither the male nor female side has a center pin. RP-SMA connectors are most common on 2.4 GHz antennas and are popular on Wi-Fi equipment. Adapters are available.

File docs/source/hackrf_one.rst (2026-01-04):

================================================
HackRF One
================================================

.. _hackrf_one:

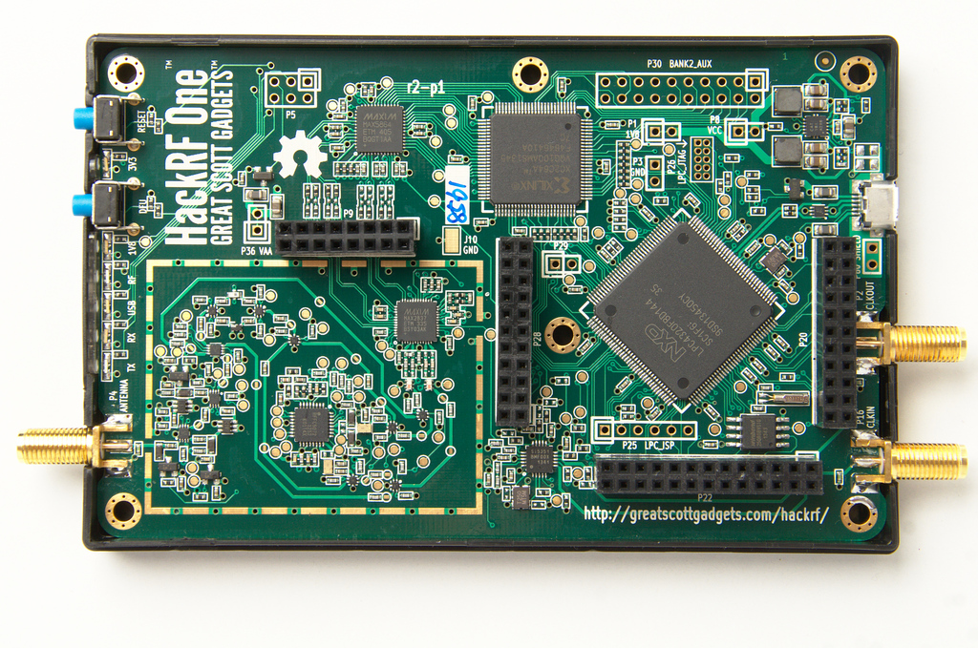
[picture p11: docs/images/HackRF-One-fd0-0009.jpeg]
HackRF One


HackRF One was the first production hardware platform for the HackRF project. It is a Software Defined Radio peripheral capable of transmission or reception of radio signals from 1 MHz to 6 GHz. Designed to enable test and development of modern and next generation radio technologies, HackRF One is an open source hardware platform that can be used as a USB peripheral or programmed for stand-alone operation.

| `Product page <https://greatscottgadgets.com/hackrf/one/>`_
| `Where to buy <https://greatscottgadgets.com/hackrf/one/#purchasing>`_

Features
~~~~~~~~

    * half-duplex transceiver
    * operating freq: 1 MHz to 6 GHz
    * supported sample rates: 2 Msps to 20 Msps (quadrature)
    * resolution: 8 bits
    * interface: High Speed USB (with USB Micro-B connector)
    * power supply: USB bus power
    * software-controlled antenna port power (max 50 mA at 3.0 to 3.3 V)
    * SMA female antenna connector (50 ohms)
    * SMA female clock input and output for synchronization
    * convenient buttons for programming
    * pin headers for expansion
    * portable
    * open source

Maximum input power
~~~~~~~~~~~~~~~~~~~

The maximum input power of HackRF One is -5 dBm. Exceeding -5 dBm can result in permanent damage!

In theory, HackRF One can safely accept up to 10 dBm with the front-end RX amplifier disabled. However, a simple software or user error could enable the amplifier, resulting in permanent damage. It is better to use an external attenuator than to risk damage.

Minimum detectable input power
~~~~~~~~~~~~~~~~~~~~~~~~~~~~~~

This isn't a question that can be answered for a general purpose SDR platform such as HackRF. Any answer would be very specific to a particular application. For example, an answerable question might be: What is the minimum power level in dBm of modulation M at frequency F that can be detected by HackRF One with software S under configuration C at a bit error rate of no more than E%? Changing any of those variables (M, F, S, C, or E) would change the answer to the question. Even a seemingly minor software update might result in a significantly different answer. To learn the exact answer for a specific application, you would have to measure it yourself.

HackRF's concrete specifications include operating frequency range, maximum sample rate, and dynamic range in bits. These specifications can be used to roughly determine the suitability of HackRF for a given application. Testing is required to finely measure performance in an application. Performance can typically be enhanced significantly by selecting an appropriate antenna, external amplifier, and/or external filter for the application.

Typical maximum transmit power
~~~~~~~~~~~~~~~~~~~~~~~~~~~~~~

HackRF One's maximum TX power varies by operating frequency:

    * 1 MHz to 10 MHz: 5 dBm to 15 dBm, generally increasing as frequency increases (see this `blog post <https://greatscottgadgets.com/2015/05-15-hackrf-one-at-1-mhz/>`__)
    * 10 MHz to 2170 MHz: 5 dBm to 15 dBm, generally decreasing as frequency increases
    * 2170 MHz to 2740 MHz: 13 dBm to 15 dBm
    * 2740 MHz to 4000 MHz: 0 dBm to 5 dBm, decreasing as frequency increases
    * 4000 MHz to 6000 MHz: -10 dBm to 0 dBm, generally decreasing as frequency increases

Through most of the frequency range up to 4 GHz, the maximum TX power is between 0 and 10 dBm. The frequency range with best performance is 2170 MHz to 2740 MHz.

Overall, the output power is enough to perform over-the-air experiments at close range or to drive an external amplifier. If you connect an external amplifier, you should also use an external bandpass filter for your operating frequency.

Before you transmit, know your laws. HackRF One has not been tested for compliance with regulations governing transmission of radio signals. You are responsible for using your HackRF One legally.

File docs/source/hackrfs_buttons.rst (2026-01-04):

=======
Buttons
=======

This information is applicable to both HackRF Pro and HackRF One.

The **RESET button** resets the microcontroller. This is a reboot that should result in a USB re-enumeration.

The **DFU button** invokes a USB DFU bootloader located in the microcontroller's ROM. This bootloader makes it possible to unbrick a HackRF with damaged firmware because the ROM cannot be overwritten.

The DFU button only invokes the bootloader during reset. This means that it can be used for other functions by custom firmware.

To invoke DFU mode: Press and hold the DFU button. While holding the DFU button, reset the HackRF either by pressing and releasing the RESET button or by powering on the HackRF. Release the DFU button.

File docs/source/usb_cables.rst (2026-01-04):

==========
USB Cables
==========

The USB cable you choose can make a big difference in what you see when using your HackRF and especially when using it around between 120 and 480 MHz where USB is doing all its work.

    #. Use a shielded USB cable. The best way to guarantee RF interference from USB is to use an unshielded cable. You can test that your cable is shielded by using a continuity tester to verify that the shield on one connector has continuity to the shield on the connector at the other end of the cable.

    #. Use a short USB cable. Trying anything larger than a 6ft cable may yield poor results. The longer the cable, the more loss you can expect and when making this post a 15ft cable was tried and the result was the HackRF would only power up half way.

    #. For best results, select a cable with a ferrite core. These cables are usually advertised to be noise reducing and are recognizable from the plastic block towards one end.

Screenshot before and after changing to a noise reducing cable (`view full size image <http://i.imgur.com/e64LASK.jpg>`__): 

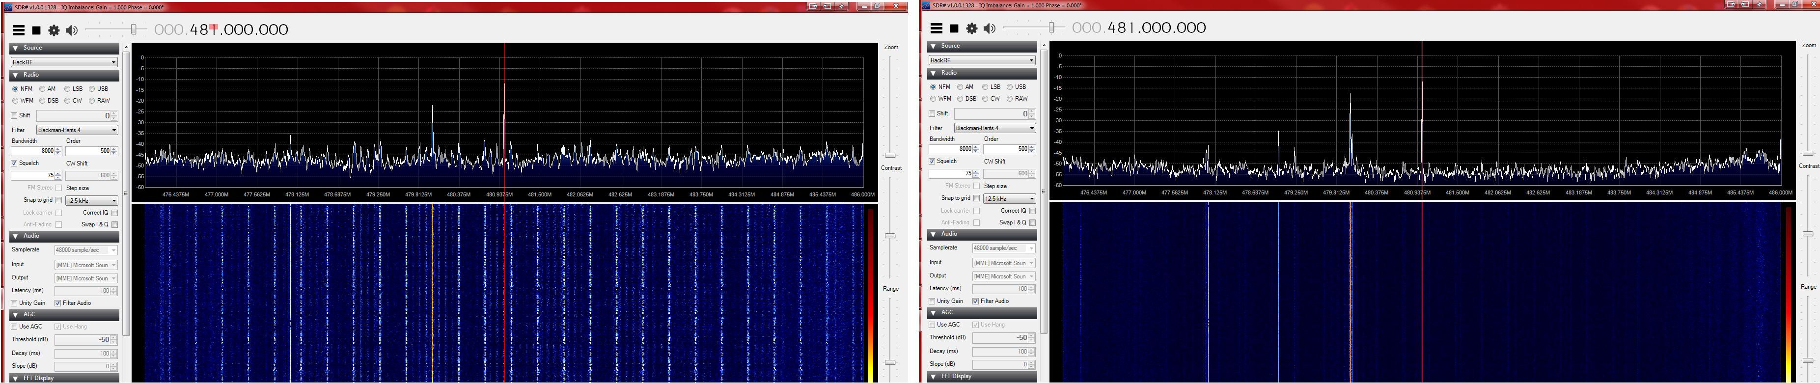
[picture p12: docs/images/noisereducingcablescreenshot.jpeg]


A shielded cable with ferrite core was used in the right-hand image.

The before and after images were both taken with the preamp on and the LNA and VGA both set to 24db.

Why isn't my HackRF detectable after I plug it into my computer?
~~~~~~~~~~~~~~~~~~~~~~~~~~~~~~~~~~~~~~~~~~~~~~~~~~~~~~~~~~~~~~~~~~~~

If your HackRF isn't immediately detectable it is very possible that your USB cable is not meeting HackRF's requirements. HackRF requires quite a bit of supply current and solid USB 2.0 high speed communications to operate. It is common for HackRF to reveal cables with deficiencies such as carrying power but not data, carrying data but not enough power, etc. Please try multiple cables to resolve this issue. More than once people have gotten their HackRF to work after trying their fifth cable.

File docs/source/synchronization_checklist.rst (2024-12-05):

.. _synchronization_checklist:

================================================
Synchronization Checklist
================================================

There are many scenarios where you may want to use multiple HackRF One devices
synchronized with each other. For instance, multiple devices can be used with a
phased antenna array to implement direction finding or beamforming.

If you're having trouble achieving fully synchronized operation, the following
checklist may be useful for troubleshooting:

* **Are you running the latest firmware and host software versions?**

    There have been many bug fixes, so please use the latest releases.

* **Are you applying settings to the right target devices?**

    With more than one HackRF device connected, you need to take care to specify
    which device should be used where. When using our command line tools, use the
    ``-d`` option with a serial number on the command line to specify which
    device each command should target.

* **Are all HackRFs sharing a clock?**

    If the HackRFs are not sharing a clock, frequencies and sample rates will
    not match exactly. See the
    :ref:`external clock interface <external_clock_interface>`
    section for how to connect the clock signals.

* **Is the clock input being detected?**

    Use ``hackrf_clock`` with the ``-i`` option to check for clock input.
    Use the ``-d`` option to specify the serial number.

    This requires ``2022.09.1`` or later host software.

    The older way of checking using ``hackrf_debug`` will not work correctly on
    some hardware revisions.

* **If the clock source is CLKOUT of another HackRF, has it been enabled?**

    Use ``hackrf_clock`` with the ``-o`` option to enable the clock output.
    Use the ``-d`` option to specify the serial number.

* **Is the CLKIN waveform correct?**

    * It should be a 10 MHz square wave between 0 V and 3.0 to 3.3 V.
    * A sine wave is OK, but may give greater phase noise.
    * An unbuffered TCXO output may not have sufficient voltage.
    * Some hardware revisions are less tolerant of out-of-spec
      clock input than others.

* **Is your hardware faulty?**

    Some HackRF clones were sold with a non-functional CLKIN port.

* **Are all HackRFs being started together using hardware triggering?**

    If hardware triggering is not used, start times will not match exactly.
    See the :ref:`hardware triggering <hardware_triggering>` section for how
    to connect the necessary trigger signals.

    Use ``hackrf_transfer`` with the ``-H`` option to wait for trigger input.

    If launching multiple ``hackrf_transfer`` instances, make sure that those
    running with ``-H`` have had time to reach the ``Waiting for trigger...``
    state before the trigger signal is sent.

    .. note:: There is currently no support for hardware triggering via the
              Osmocom or Soapy blocks in GNU Radio. The Osmocom block may look
              like it supports this but the options have no effect. 

* **Are any samples being lost due to USB throughput problems?**

    If RX samples are dropped or TX samples delayed, signals will become out
    of sync.

    Use ``hackrf_debug -S`` on each HackRF after running your software to check
    if there were throughput problems. If the shortfall count reported is
    non-zero, some samples were dropped on RX or late for TX, and signals will
    be out of sync as a result.

    This requires ``2022.09.1`` or later host software.

    To force shortfalls to stop the device at runtime, use
    ``hackrf_debug -T 0 -R 0`` to set zero tolerance for shortfalls.

* **Are your HackRFs sharing a USB bus?**

    A single HackRF One at 20 MHz sample rate uses practically all the bandwidth
    of a single USB 2.0 bus. Unless using very low sample rates, each HackRF
    should be connected to its own bus.

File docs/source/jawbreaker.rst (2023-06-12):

==========
Jawbreaker
==========

HackRF Jawbreaker is the beta test hardware platform for the HackRF project.

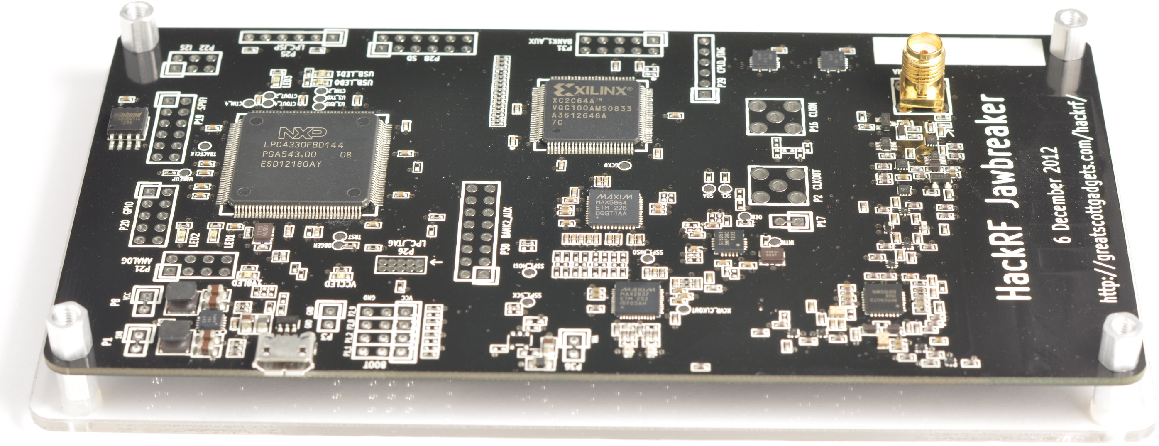
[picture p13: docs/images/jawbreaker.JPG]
Jawbreaker


(Jawbreaker picture provided by `fd0 <https://github.com/fd0>`__ with Creative Commons License CC BY 3.0.)

Features
~~~~~~~~

    * half-duplex transceiver
    * operating freq: 30 MHz to 6 GHz
    * supported sample rates: 8 Msps to 20 Msps (quadrature)
    * resolution: 8 bits
    * interface: High Speed USB (with USB Micro-B connector)
    * power supply: USB bus power
    * portable
    * open source

Hardware Documentation
~~~~~~~~~~~~~~~~~~~~~~

Schematic diagram, assembly diagram, and bill of materials can be found at `https://github.com/greatscottgadgets/hackrf/tree/master/hardware <https://github.com/greatscottgadgets/hackrf/tree/master/hardware>`__

Transmit Power
~~~~~~~~~~~~~~

The maximum TX power for Jawbreaker varies by operating frequency:

    * 30 MHz to 100 MHz: 5 dBm to 15 dBm, increasing as frequency decreases
    * 100 MHz to 2300 MHz: 0 dBm to 10 dBm, increasing as frequency decreases
    * 2170 MHz to 2740 MHz: 10 dBm to 15 dBm
    * 2700 MHz to 4000 MHz: -5 dBm to 5 dBm, increasing as frequency decreases
    * 4000 MHz to 6000 MHz: -15 dBm to 0 dBm, increasing as frequency decreases

Overall, the output power is enough to perform over-the-air experiments at close range or to drive an external amplifier. If you connect an external amplifier, you should also use an external bandpass filter for your operating frequency.

Before you transmit, know the laws for the region you are transmitting in. Jawbreaker has not been tested for compliance with regulations governing transmission of radio signals. You are responsible for using your Jawbreaker legally.

SMA, not RP-SMA
~~~~~~~~~~~~~~~

The connectors on Jawbreaker are SMA, not RP-SMA. SMA connectors and RP-SMA connectors look extremely similar, the difference is that SMA connectors have a center pin. RP-SMA connectors are common on 2.4 GHz antennas and are popular on Wi-Fi equipment. If you connect an RP-SMA antenna to Jawbreaker, it will seem to connect snugly but won't function at all because neither the male nor female side has a center pin. 

Recommended PCB and Antenna Changes
~~~~~~~~~~~~~~~~~~~~~~~~~~~~~~~~~~~

Jawbreaker has an SMA antenna connector and it also includes a built-in PCB antenna intended for operation near 900 MHz. The built-in PCB antenna isn't a very good antenna. A paperclip stuck into the SMA connector of the Jawbreaker is likely to be better. We recommend that you free your Jawbreaker to operate with better antennas by cutting the PCB trace to the PCB antenna with a knife. This enables the SMA connector to be used without interference from the PCB antenna.

The trace to be cut is between the two solder pads inside a box labeled R44. There is an arrow printed on the board that points to the R44 box. A video that demonstrates the antenna modification is on YouTube: `HackRF Antenna Modification <http://youtu.be/B2gwgNoqMxI>`__.

Due to a manufacturing error, there is solder on the pads in box R44 that you should try to remove before you cut the trace. R44 may appear as a single solder blob. If you have a soldering iron and solder wick/braid, use a soldering iron and fine solder wick to remove as much solder as you can from the two R44 pads. Then, use a pen knife to gently cut away the area between the two R44 pads. Make multiple, gentle cuts, instead of one or two forceful cuts. As you cut, you'll break through the black solder mask, then the copper trace between the pads, and stop when you reach fiberglass. Remove the copper trace completely, so just the two R44 pads remain. Use a multimeter or continuity tester to verify that the two R44 pads are no longer connected. If you don't have a soldering iron, you can cut through the copper trace and the solder blob all at once, but it requires a bit more effort. The only reason not to cut the PCB trace is if you want to try Jawbreaker but don't have any antenna with an SMA connector (or adapter).

If you want to restore the PCB antenna for some reason, you can install a 10 nF capacitor or a 0 ohm resistor on the R44 pads or you may be able to simply create a solder bridge.

Expansion Interface
~~~~~~~~~~~~~~~~~~~

LPC
^^^
Boot config
+++++++++++

Default boot configuration is SPIFI. Install headers and jumpers (and optionally resistors) to reconfigure.

.. list-table :: 
  :header-rows: 1
  :widths: 1 1 1 1 1

  * - Pin 	
    - P43 	
    - P32 	
    - P42 	
    - P27
  * - 1 	
    - VCC 	
    - VCC 	
    - VCC 	
    - VCC
  * - 2 	
    - P2_9 	
    - P2_8 	
    - P1_2 	
    - P1_1
  * - 3 	
    - GND 	
    - GND 	
    - GND 	
    - GND

The table below shows which pins to short per header for a given selection.

.. list-table :: 
  :header-rows: 1
  :widths: 1 1 1 1 1

  * - Selection 	
    - P43 	
    - P32 	
    - P42 	
    - P27
  * - USART0 	
    - 2-3 	
    - 2-3 	
    - 2-3 	
    - 2-3
  * - SPIFI 	
    - 2-3 	
    - 2-3 	
    - 2-3 	
    - 1-2
  * - USB0 	
    - 2-3 	
    - 1-2 	
    - 2-3 	
    - 1-2
  * - USSP0 	
    - 2-3 	
    - 1-2 	
    - 1-2 	
    - 1-2
  * - USART3 	
    - 1-2 	
    - 2-3 	
    - 2-3 	
    - 2-3

P19 SPIFI Intercept header
++++++++++++++++++++++++++

Traces may be cut to install header and jumpers or use off-board SPI flash.

.. list-table :: 
  :header-rows: 1
  :widths: 1 1

  * - Pin 	
    - Function
  * - 1 	
    - Flash DO
  * - 2 	
    - SPIFI_MISO
  * - 3 	
    - Flash DI
  * - 4 	
    - SPIFI_MOSI
  * - 5 	
    - Flash CLK
  * - 6 	
    - SPIFI_SCK
  * - 7 	
    - Flash CS
  * - 8 	
    - SPIFI_CS
  * - 9 	
    - Flash Hold
  * - 10 	
    - SPIFI_SIO3
  * - 11 	
    - Flash WP
  * - 12 	
    - SPIFI_SIO2

P20 GPIO
++++++++

.. list-table :: 
  :header-rows: 1
  :widths: 1 1

  * - Pin 	
    - Function
  * - 1 	
    - GPIO3_8
  * - 2 	
    - GPIO3_9
  * - 3 	
    - GPIO3_10
  * - 4 	
    - GPIO3_11
  * - 5 	
    - GPIO3_12
  * - 6 	
    - GPIO3_13
  * - 7 	
    - GPIO3_14
  * - 8 	
    - GPIO3_15
  * - 9 	
    - GND
  * - 10 	
    - GND

P21 Analog
++++++++++

.. list-table :: 
  :header-rows: 1
  :widths: 1 1

  * - Pin 	
    - Function
  * - 1 	
    - GND
  * - 2 	
    - ADC0_6
  * - 3 	
    - GND
  * - 4 	
    - ADC0_2
  * - 5 	
    - GND
  * - 6 	
    - ADC0_5
  * - 7 	
    - GND
  * - 8 	
    - ADC0_0

P22 I2S
+++++++

.. list-table :: 
  :header-rows: 1
  :widths: 1 1

  * - Pin 	
    - Function
  * - 1 	
    - VCC
  * - 2 	
    - I2S0_TX_SDA
  * - 3 	
    - I2S0_TX_WS
  * - 4 	
    - I2S0_TX_SCK
  * - 5 	
    - I2S0_TX_MCLK
  * - 6 	
    - GND

P25 LPC_ISP
+++++++++++

.. list-table :: 
  :header-rows: 1
  :widths: 1 1

  * - Pin 	
    - Function
  * - 1 	
    - GND
  * - 2 	
    - ISP
  * - 3 	
    - NC
  * - 4 	
    - U0_RXD
  * - 5 	
    - U0_TXD
  * - 6 	
    - RESET

P26 LPC_JTAG
++++++++++++

.. list-table :: 
  :header-rows: 1
  :widths: 1 1

  * - Pin 	
    - Function
  * - 1 	
    - VCC
  * - 2 	
    - TMS
  * - 3 	
    - GND
  * - 4 	
    - TCK
  * - 5 	
    - GND
  * - 6 	
    - TDO
  * - 7 	
    - NC
  * - 8 	
    - TDI
  * - 9 	
    - GND
  * - 10 	
    - RESET

P28 SD
++++++

.. list-table :: 
  :header-rows: 1
  :widths: 1 1

  * - Pin 	
    - Function
  * - 1 	
    - GND
  * - 2 	
    - VCC
  * - 3 	
    - SD_CD
  * - 4 	
    - SD_DAT3
  * - 5 	
    - SD_DAT2
  * - 6 	
    - SD_DAT1
  * - 7 	
    - SD_DAT0
  * - 8 	
    - SD_VOLT0
  * - 9 	
    - SD_CMD
  * - 10 	
    - SD_POW
  * - 11 	
    - SD_CLK
  * - 12 	
    - NC

CPLD
^^^^

P29 CPLD_JTAG
+++++++++++++

.. list-table :: 
  :header-rows: 1
  :widths: 1 1

  * - Pin 	
    - Function
  * - 1 	
    - CPLD_TMS
  * - 2 	
    - CPLD_TDI
  * - 3 	
    - CPLD_TDO
  * - 4 	
    - CPLD_TCK
  * - 5 	
    - GND
  * - 6 	
    - NCC

P30 BANK2_AUX
+++++++++++++

.. list-table :: 
  :header-rows: 1
  :widths: 1 1

  * - Pin 	
    - Function
  * - 1 	
    - B2AUX1
  * - 2 	
    - B2AUX2
  * - 3 	
    - B2AUX3
  * - 4 	
    - B2AUX4
  * - 5 	
    - B2AUX5
  * - 6 	
    - B2AUX6
  * - 7 	
    - B2AUX7
  * - 8 	
    - B2AUX8
  * - 9 	
    - B2AUX9
  * - 10 	
    - B2AUX10
  * - 11 	
    - B2AUX11
  * - 12 	
    - B2AUX12
  * - 13 	
    - B2AUX13
  * - 14 	
    - B2AUX14
  * - 15 	
    - B2AUX15
  * - 16 	
    - B2AUX16

P31 BANK1_AUX
+++++++++++++

.. list-table :: 
  :header-rows: 1
  :widths: 1 1

  * - Pin 	
    - Function
  * - 1 	
    - B1AUX9
  * - 2 	
    - B1AUX10
  * - 3 	
    - B1AUX11
  * - 4 	
    - B1AUX12
  * - 5 	
    - B1AUX13
  * - 6 	
    - B1AUX14
  * - 7 	
    - B1AUX15    
  * - 8 	
    - B1AUX16
  * - 9 	
    - GND
  * - 10 	
    - GND

External clock
^^^^^^^^^^^^^^

P2 CLKOUT
+++++++++

Install C165 and R92 as necessary to match output. For CMOS output, install 0 ohm resistor in place of C165; do not install R92.

.. list-table :: 
  :header-rows: 1
  :widths: 1 1

  * - Pin 	
    - Function
  * - 1 	
    - CLKOUT
  * - 2 	
    - GND
  * - 3 	
    - GND
  * - 4 	
    - GND
  * - 5 	
    - GND

P16 CLKIN
+++++++++

Install C118, C164, R45, R84 and R85 as necessary to match input.

For CMOS input, install 0 ohm resistors in place of C118 and C164; do not install R45, R84, or R85.

.. list-table :: 
  :header-rows: 1
  :widths: 1 1

  * - Pin 	
    - Function
  * - 1 	
    - CLKIN
  * - 2 	
    - GND
  * - 3 	
    - GND
  * - 4 	
    - GND
  * - 5 	
    - GND

P17 CLKIN_JMP
+++++++++++++

Cut P17 short (trace) to enable external clock input. If short is cut, a jumper should be used on P17 at all times when an external clock is not connected to P16.

.. list-table :: 
  :header-rows: 1
  :widths: 1 1

  * - Pin 	
    - Function
  * - 1 	
    - GND
  * - 2 	
    - CLKIN

More
^^^^

Additional headers are available. See the `board files <https://github.com/greatscottgadgets/hackrf/tree/master/hardware/jawbreaker>`__ for additional details.

Differences between Jawbreaker and HackRF One
~~~~~~~~~~~~~~~~~~~~~~~~~~~~~~~~~~~~~~~~~~~~~

Jawbreaker was the beta platform that preceded HackRF One. HackRF One incorporates the following changes and enhancements (at minimum):

    * Antenna port: No modification is necessary to use the SMA antenna port on HackRF One.
    * PCB antenna: Removed.
    * Size: HackRF One is smaller at 120 mm x 75 mm (PCB size).
    * Enclosure: The commercial version of HackRF One from Great Scott Gadgets ships with an injection molded plastic enclosure. HackRF One is also designed to fit other enclosure options.
    * Buttons: HackRF One has a RESET button and a DFU button for easy programming.
    * Clock input and output: Installed and functional without modification.
    * USB connector: HackRF One features a new USB connector and improved USB layout.
    * Expansion interface: More pins are available for expansion, and pin headers are installed on HackRF One.
    * Real-Time Clock: An RTC is installed on HackRF One.
    * LPC4320 microcontroller: Jawbreaker had an LPC4330.
    * RF shield footprint: An optional shield may be installed over HackRF One's RF section.
    * Antenna port power: HackRF One can supply up to 50 mA at 3.0 to 3.3 V DC on the antenna port for compatibility with powered antennas and other low power amplifiers.
    * Enhanced frequency range: The RF performance of HackRF One is better than Jawbreaker, particularly at the high and low ends of the operating frequency range. HackRF One can operate at 1 MHz or even lower.

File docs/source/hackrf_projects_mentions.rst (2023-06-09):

================================================
HackRF Community Projects and Mentions
================================================

Have you done something cool with HackRF or mentioned HackRF in one of your presentations? Let us know and we might post a link here!

* `HackRF vs. Tesla Model S <https://www.youtube.com/watch?v=575TcQJJWok>`__ (Sam Edwards)
* `Jawbreaker/VFD spectrum analyzer <http://www.sharebrained.com/2013/05/21/maker-faire-radio-spectrum-analyzer/>`__ (Jared Boone)
* `LEGO car <http://ossmann.blogspot.com/2013/06/hackrf-lego-car.html>`__ (Michael Ossmann)
* `wireless microphones <http://www.sharebrained.com/2013/06/15/wireless-microphones-and-hackrf/>`__ (Jared Boone)
* `Tesla Charging Port Opener <https://github.com/rgerganov/tesla-opener>`__ (Radoslav Gerganov)
* `Hacking my smart tooth brush <https://kuenzi.dev/toothbrush/>`__ (Cyrill Künzi)

Retired Projects
~~~~~~~~~~~~~~~~

* Automotive Remote Keyless Entry Systems (Mike Kershaw)
* Decoding Pocsag Pagers With The HackRF (BinaryRF)
* Sniffing GSM with HackRF (BinaryRF)

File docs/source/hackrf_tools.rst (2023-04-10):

============
HackRF Tools
============

Great Scott Gadgets provides some commandline tools for interacting with HackRF. 
    * **hackrf_info** Read device information from HackRF such as serial number and firmware version.

    * **hackrf_transfer** Send and receive signals using HackRF. Input/output files are 8-bit signed quadrature samples.

    * **hackrf_sweep**, a command-line spectrum analyzer.

    * **hackrf_clock** Read and write clock input and output configuration.

    * **hackrf_operacake** Configure Opera Cake antenna switch connected to HackRF.

    * **hackrf_spiflash** A tool to write new firmware to HackRF. See: :ref:`Updating Firmware <updating_firmware>`.

    * **hackrf_debug** Read and write registers and other low-level configuration for debugging.

hackrf_sweep
~~~~~~~~~~~~

Usage
^^^^^

.. code-block:: sh 

    [-h] # this help
    [-d serial_number] # Serial number of desired HackRF
    [-a amp_enable] # RX RF amplifier 1=Enable, 0=Disable
    [-f freq_min:freq_max] # minimum and maximum frequencies in MHz
    [-p antenna_enable] # Antenna port power, 1=Enable, 0=Disable
    [-l gain_db] # RX LNA (IF) gain, 0-40dB, 8dB steps
    [-g gain_db] # RX VGA (baseband) gain, 0-62dB, 2dB steps
    [-w bin_width] # FFT bin width (frequency resolution) in Hz, 2445-5000000
    [-1] # one shot mode
    [-N num_sweeps] # Number of sweeps to perform
    [-B] # binary output
    [-I] # binary inverse FFT output
    -r filename # output file

Output fields
^^^^^^^^^^^^^

``date, time, hz_low, hz_high, hz_bin_width, num_samples, dB, dB, ...``

Running ``hackrf_sweep -f 2400:2490`` gives the following example results:

.. list-table :: 
  :header-rows: 1
  :widths: 1 1 1 1 1 1 1 1 1 1 1

  * - Date  
    - Time  
    - Hz Low    
    - Hz High   
    - Hz bin width  
    - Num Samples   
    - dB    
    - dB    
    - dB    
    - dB    
    - dB
  * - 2019-01-03    
    - 11:57:34.967805   
    - 2400000000    
    - 2405000000    
    - 1000000.00    
    - 20    
    - -64.72    
    - -63.36    
    - -60.91    
    - -61.74    
    - -58.58
  * - 2019-01-03    
    - 11:57:34.967805   
    - 2410000000    
    - 2415000000    
    - 1000000.00    
    - 20    
    - -69.22    
    - -60.67    
    - -59.50    
    - -61.81    
    - -58.16
  * - 2019-01-03    
    - 11:57:34.967805   
    - 2405000000    
    - 2410000000    
    - 1000000.00    
    - 20    
    - -61.19    
    - -70.14    
    - -60.10    
    - -57.91    
    - -61.97
  * - 2019-01-03    
    - 11:57:34.967805   
    - 2415000000    
    - 2420000000    
    - 1000000.00    
    - 20    
    - -72.93    
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

Each sweep across the entire specified frequency range is given a single time stamp.

The fifth column tells you the width in Hz (1 MHz in this case) of each frequency bin, which you can set with ``-w``. The sixth column is the number of samples analyzed to produce that row of data.

Each of the remaining columns shows the power detected in each of several frequency bins. In this case there are five bins, the first from 2400 to 2401 MHz, the second from 2401 to 2402 MHz, and so forth.

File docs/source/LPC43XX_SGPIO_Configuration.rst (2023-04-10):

================================================
LPC43xx SGPIO Configuration
================================================

The LPC43xx SGPIO peripheral is used to move samples between USB and the ADC/DAC chip (MAX5864). The SGPIO is a peripheral that has a bunch of 32-bit shift registers. These shift registers can be configured to act as a parallel interface of different widths. For HackRF, we configure the SGPIO to transfer eight bits at a time. The SGPIO interface can also accept an external clock, which we use to synchronize transfers with the sample clock.

In the current HackRF design, there is a CPLD which manages the interface between the MAX5864 and the SGPIO interface. There are four SGPIO signals that control the SGPIO data transfer:

    * Clock: Determines when a value on the SGPIO data bus is transferred.
    * Direction: Determines whether the MAX5864 DA (ADC) data is driven onto the SGPIO lines, or if the SGPIO lines drive the data bus with data for the MAX5864 DD (DAC) signals.
    * Data Valid: Indicates a sample on the SGPIO data bus is valid data.
    * Transfer Enable: Allows SGPIO to synchronize with the I/Q data stream. The MAX5864 produces/consumes two values (quadrature/complex value) per sample period -- an I value and a Q value. These two values are multiplexed on the SGPIO lines. This signal suspends data valid until the I value should be transferred.

Why not use GPDMA to transfer samples through SGPIO?
~~~~~~~~~~~~~~~~~~~~~~~~~~~~~~~~~~~~~~~~~~~~~~~~~~~~

It would be great if we could, as that would free up lots of processor time. Unfortunately, the GPDMA scheme in the LPC43xx does not seem to support peripheral-to-memory and memory-to-peripheral transfers with the SGPIO peripheral.

You might observe that the SGPIO peripheral can generate requests from SGPIO14 and SGPIO15, using an arbitrary bit pattern in the slice shift register. The pattern in the slice determines the request interval. That's a good start. However, how do you specify which SGPIO shadow registers are read/written at each request, and in which order those registers are transferred with memory? It turns out you can't. In fact, it appears that an SGPIO request doesn't cause any transfer at all, if your source or destination is "peripheral". Instead, the SGPIO request is intended to perform a memory-to-memory transfer synchronized with SGPIO. But you're on your own as far as getting data to/from the SGPIO shadow registers. I believe this is why the SGPIO camera example in the user manual describes an SGPIO interrupt doing the SGPIO shadow register transfer, and the GPDMA doing moves from one block of RAM to another.

Perhaps if we transfer only one SGPIO shadow register, using memory-to-memory? Then we don't have to worry about the order of SGPIO registers, or which ones need to be transferred. It turns out that when you switch over to memory-to-memory transfers, you lose peripheral request generation. So the GPDMA will transfer as fast as possible -- far faster than words are produced/consumed by SGPIO.

I'd really love to be wrong about all this, but all my testing has indicated there's no workable solution to using GPDMA that's any better than using SGPIO interrupts to transfer samples. If you want some sample GPDMA code to experiment with, please contact Jared (sharebrained on #hackrf in Discord or IRC).

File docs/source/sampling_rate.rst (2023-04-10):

Sampling Rate and Baseband Filters
~~~~~~~~~~~~~~~~~~~~~~~~~~~~~~~~~~

Using a sampling rate of less than 8MHz is not recommended. Partly, this is because the MAX5864 (ADC/DAC chip) isn't specified to operate at less than 8MHz, and therefore, no promises are made by Maxim about how it performs. But more importantly, the baseband filter in the MAX2837 has a minimum bandwidth of 1.75MHz. It can't provide enough filtering at 2MHz sampling rate to remove substantial signal energy in adjacent spectrum (more than +/-1MHz from the tuned frequency). The MAX2837 datasheet suggests that at +/-1MHz, the filter provides only 4dB attenuation, and at +/-2MHz (where a signal would alias right into the center of your 2MHz spectrum), it attenuates about 33dB. That's significant. Here's a picture:

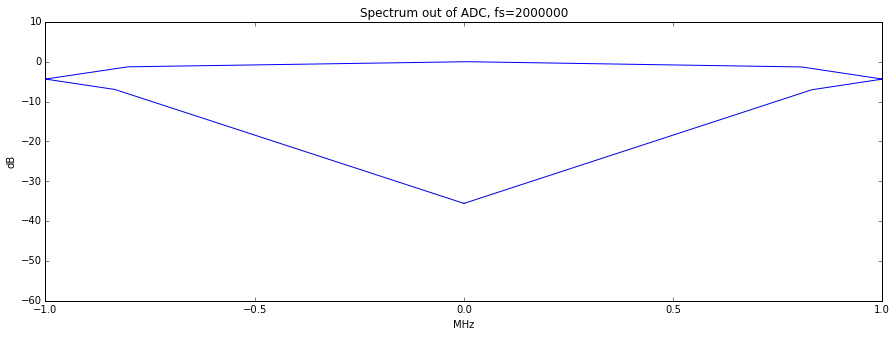
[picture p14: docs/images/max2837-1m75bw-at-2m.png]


At 8MHz sampling rate, and using the minimum 1.75MHz bandwidth filter, this is the response:

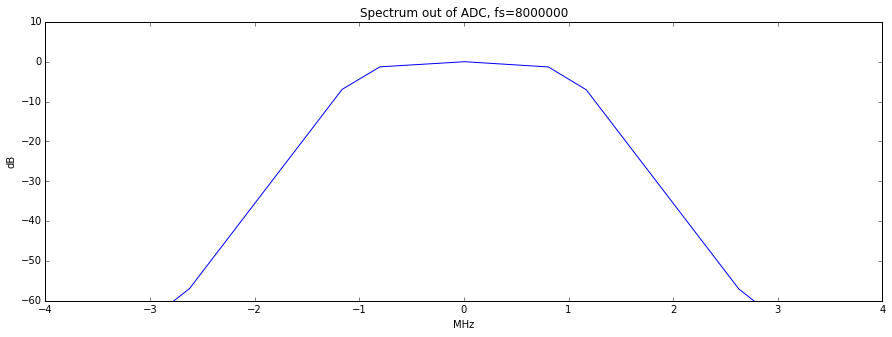
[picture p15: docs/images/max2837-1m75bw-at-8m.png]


You can see that the attenuation is more than 60dB at +/-2.8MHz, which is more than sufficient to remove significant adjacent spectrum interference before the ADC digitizes the baseband. If using this configuration to get a 2MHz sampling rate, use a GNU Radio block after the 8MHz source that performs a 4:1 decimation with a decently sharp low pass filter (complex filter with a cut-off of <1MHz).

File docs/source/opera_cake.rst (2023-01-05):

==========
Opera Cake
==========

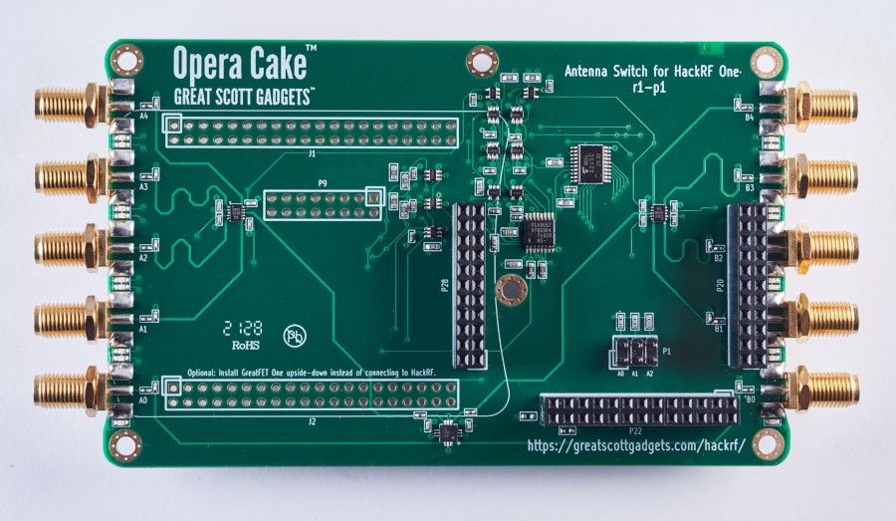
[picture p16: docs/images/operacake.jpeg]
Opera Cake


Opera Cake is an antenna switching add-on board for HackRF One. Consisting of two 1x4 switches, Opera Cake also has a cross-over switch that permits operation as a 1x8 switch. Up to eight Opera Cakes may be stacked onto a single HackRF One provided that each Opera Cake is configured with a different board address.

Opera Cake can be used as a 1x8 switch to connect your HackRF One to a variety of antennas at once, such as a long wire antenna for HF bands, a discone for VHF and UHF, a dipole for 2.4 GHz, and a dish for a satellite band. Once connected to your Opera Cake you can switch between all of your antennas in software instead of making physical hardware swaps.

When set up as a pair of 1x4 switches you could use Opera Cake as a switched filter bank. To do this, connect port A1 to B1, A2 to B2, A3 to B3, and A4 to B4 through physical SMA filters and cables of your choosing. This setup allows you to change your transmit or receive to be through the filter of your choosing without having to reconnect hardware every time you would like to use a different filter.

Opera Cake is configured with the ``hackrf_operacake`` command-line tool.

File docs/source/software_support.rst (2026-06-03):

===========================================
Third-Party Software Compatible With HackRF
===========================================

Software That Has Direct Support For HackRF
~~~~~~~~~~~~~~~~~~~~~~~~~~~~~~~~~~~~~~~~~~~

* GQRX

    * `http://gqrx.dk/ <http://gqrx.dk/>`__

* GNU Radio

    * https://www.gnuradio.org/

* GNU Radio Mode-S/ADS-B

    * `https://github.com/bistromath/gr-air-modes <https://github.com/bistromath/gr-air-modes>`__

* QSpectrumAnalyzer

    * `https://github.com/xmikos/qspectrumanalyzer <https://github.com/xmikos/qspectrumanalyzer>`__

* SDR# 

    * `https://airspy.com/download/ <https://airspy.com/download/>`__
    * Windows OS only
    * Only nightly builds currently support HackRF One  

* SDR Console

    * https://www.sdr-radio.com/Console

* Spectrum Analyzer GUI for hackrf_sweep for Windows 

    * `https://github.com/pavsa/hackrf-spectrum-analyzer <https://github.com/pavsa/hackrf-spectrum-analyzer>`__

* Universal Radio Hacker (Windows/Linux) 

    * `https://github.com/jopohl/urh <https://github.com/jopohl/urh>`__

* Web-based APRS tracker 

    * `https://xakcop.com/aprs-sdr <https://xakcop.com/aprs-sdr/>`__

* SigDigger (Windows/Linux/macOS)

    * `https://github.com/BatchDrake/SigDigger <https://github.com/BatchDrake/SigDigger>`__
    * Supports HackRF through SoapySDR / SoapyHackRF

Software That Can Use Data From HackRF
~~~~~~~~~~~~~~~~~~~~~~~~~~~~~~~~~~~~~~
* Baudline 

    * `http://www.baudline.com/ <http://www.baudline.com/>`__ 
    * Can view/process HackRF data, e.g. hackrf_transfer

* Inspectrum 

    * `https://github.com/miek/inspectrum <https://github.com/miek/inspectrum>`__
    * Capture analysis tool with advanced features

* Matlab

    .. code-block :: sh

        fid = open('samples.bin',  'r');
        len = 1000; % 1000 samples
        y = fread(fid, 2*len, 'int8');
        y = y(1:2:end) + 1j*y(2:2:end);
        fclose(fid)

Troubleshooting Recommendations
~~~~~~~~~~~~~~~~~~~~~~~~~~~~~~~

Many of these tools require libhackrf and at times HackRF Tools. It may help you to have updated libhackrf and HackRF Tools when troubleshooting these applications. 

It is also strongly suggested, and usually required, that your HackRF Tools and HackRF firmware match.

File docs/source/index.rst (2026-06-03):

==================================
Welcome to HackRF's documentation!
==================================

.. toctree::
   :maxdepth: 2
   :caption: User Documentation

   getting_help
   troubleshooting
   synchronization_checklist
   hackrf_projects_mentions

.. toctree::
   :maxdepth: 2
   :caption: Hardware Platforms

   hackrf_pro
   hackrf_one
   rad1o
   jawbreaker

.. toctree::
   :maxdepth: 2
   :caption: Hardware Information

   hackrf_minimum_requirements
   list_of_hardware_revisions
   hardware_components 
   leds 
   hackrfs_buttons
   hackrf_connectors
   external_clock_interface
   expansion_interface
   hardware_triggering
   enclosure_options    
   usb_cables
   rf_shield_installation   

.. toctree::
   :maxdepth: 2
   :caption: Firmware

   updating_firmware
   firmware_development_setup
   LPC43XX_Debugging
   LPC43XX_SGPIO_Configuration

.. toctree::
   :maxdepth: 2
   :caption: Software

   installing_hackrf_software
   hackrf_tools
   software_support
   sampling_rate
   setting_gain
   virtual_machines

.. toctree::
   :maxdepth: 2
   :caption: Gateware

   gateware

.. toctree::
   :maxdepth: 2
   :caption: Opera Cake Documentation

   opera_cake
   opera_cake_faq
   opera_cake_hardware
   opera_cake_board_addressing
   opera_cake_port_configuration
   opera_cake_modes_of_operation

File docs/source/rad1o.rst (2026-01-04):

=====
rad1o
=====

rad1o is the badge from the 2015 Chaos Communication Camp.

The rad1o badge contains a full-featured SDR (software defined radio) half-duplex transceiver, operating in a frequency range of about 50 MHz - 4000 MHz, and is software compatible to the HackRF.

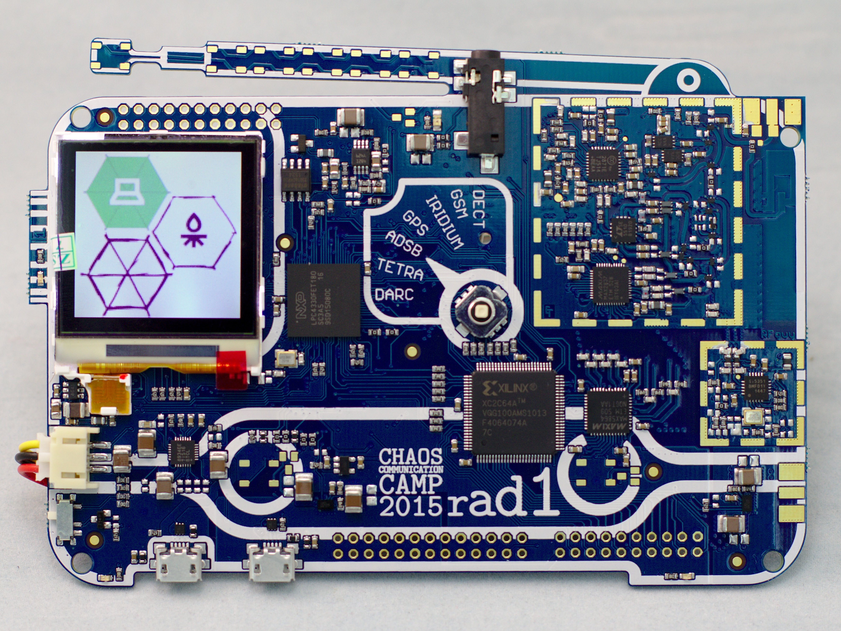
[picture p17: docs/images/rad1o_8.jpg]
rad1o


(rad1o picture provided by Christoph Krichenbauer with Creative Commons License CC-BY-NC_SA)

More information can be found at the `rad1o badge wiki <https://rad1o.badge.events.ccc.de/start>`__

Compared to HackRF One, the rad1o badge uses a different mixer (MAX2871) with a reduced frequency range.

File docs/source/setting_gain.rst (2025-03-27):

============================
Setting Gain Controls for RX
============================

Gain controls
~~~~~~~~~~~~~

HackRF One provides three different analog gain controls on RX and two on TX.

The three RX gain controls are at these stages:

- RF ("amp", 0 or ~11 dB)
- IF ("lna", 0 to 40 dB in 8 dB steps)
- baseband ("vga", 0 to 62 dB in 2 dB steps)
 
The two TX gain controls are at these stages:

- RF (0 or ~11 dB)
- IF (0 to 47 dB in 1 dB steps)

Note: in some documents, the RF gain was erroneously quoted to be 14 dB. The confusion was based on the fact that the MGA-81563 amplifier is advertised as a "14 dBm" amplifier, but that specifies its output power, not its amplification. See `Martin Ling's comment on issue #1059 <https://github.com/greatscottgadgets/hackrf/issues/1059#issuecomment-1060038293>`__ for some details!

The TX and RX RF amplifiers have two settings: on or off. In the off state, the amps are completely bypassed. They nominally provide around 11 dB of gain when on, but the actual amount of gain varies by frequency. In general, expect less gain at higher frequencies. For fine control of gain, use the IF and/or baseband gain options.

A good default setting to start with is RF=0 (off), IF=16, baseband=16. Increase or decrease the IF and baseband gain controls roughly equally to find the best settings for your situation. Turn on the RF amp if you need help picking up weak signals. If your gain settings are too low, your signal may be buried in the noise. If one or more of your gain settings is too high, you may see distortion (look for unexpected frequencies that pop up when you increase the gain) or the noise floor may be amplified more than your signal is.

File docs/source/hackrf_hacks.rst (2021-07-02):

================================================
HackRF Hacks
================================================

Have you done something cool with HackRF? Let us know and we will post a link here!

    * `Jawbreaker/VFD spectrum analyzer <http://www.sharebrained.com/2013/05/21/maker-faire-radio-spectrum-analyzer/>`__ (Jared Boone), see also the `extended demo on Hak5 <http://hak5.org/episodes/hak5-1417>`__
    * `wireless microphones <http://www.sharebrained.com/2013/06/15/wireless-microphones-and-hackrf/>`__ (Jared Boone)
    * `LEGO car <http://ossmann.blogspot.com/2013/06/hackrf-lego-car.html>`__ (Michael Ossmann)
    * `automotive remote keyless entry systems <http://blog.kismetwireless.net/2013/08/playing-with-hackrf-keyfobs.html>`__ (Mike Kershaw)
    * `Sniffing GSM with HackRF <http://binaryrf.com/viewtopic.php?t=6&f=9>`__ (BinaryRF - Unavailable as of 19Nov2014: `archived version <https://web.archive.org/web/20140228134513/http://binaryrf.com/viewtopic.php?f=9&t=6>`__)
    * `Decoding Pocsag Pagers With The HackRF <http://binaryrf.com/viewtopic.php?f=9&t=8>`__ (BinaryRF - Unavailable as of 19Nov2014: `archived version <https://web.archive.org/web/20130825000155/http://binaryrf.com/viewtopic.php?f=9&t=8>`__)
    * `HackRF vs. Tesla Model S <https://www.youtube.com/watch?v=575TcQJJWok>`__ (Sam Edwards)

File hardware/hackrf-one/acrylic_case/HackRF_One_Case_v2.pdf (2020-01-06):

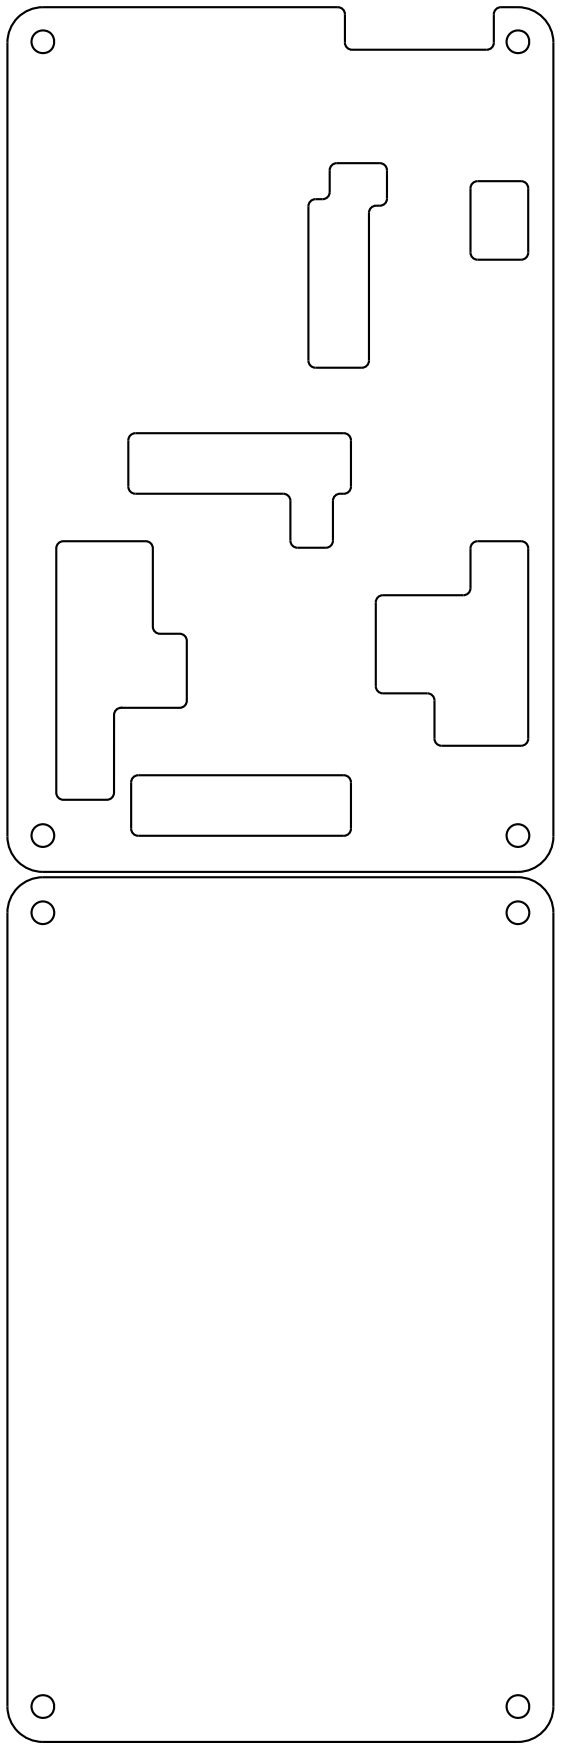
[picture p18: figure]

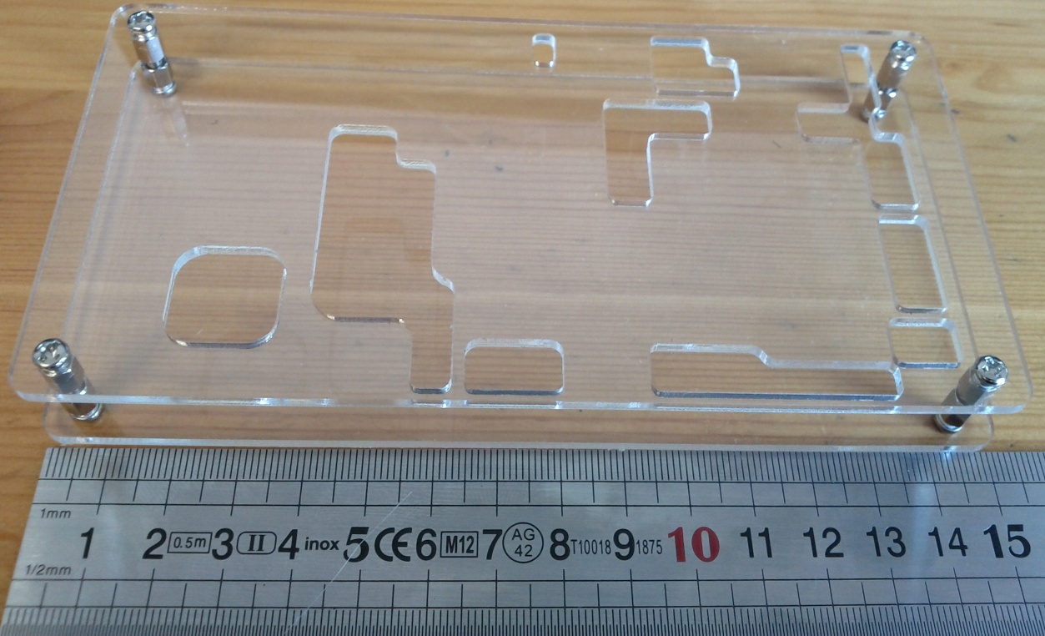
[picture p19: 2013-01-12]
hardware/jawbreaker/SoBv1_DP17298/SoBv1-DP17298-jawbreaker.jpg

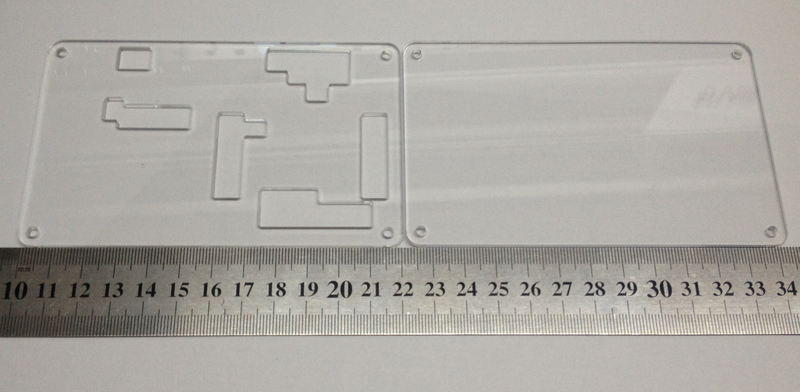
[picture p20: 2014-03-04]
hardware/hackrf-one/PlasticCase_CAD/HackRF_One_Case.png

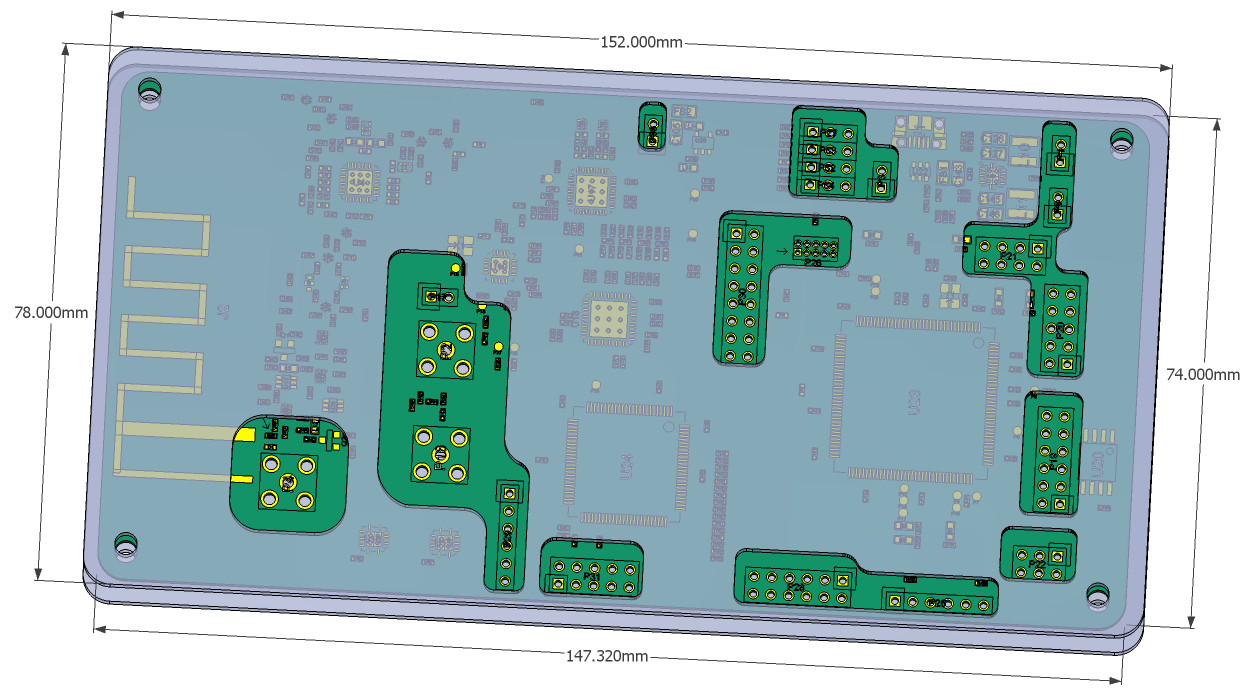
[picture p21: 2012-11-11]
hardware/jawbreaker/SoBv1_DP17298/jawbreaker_and_case.png

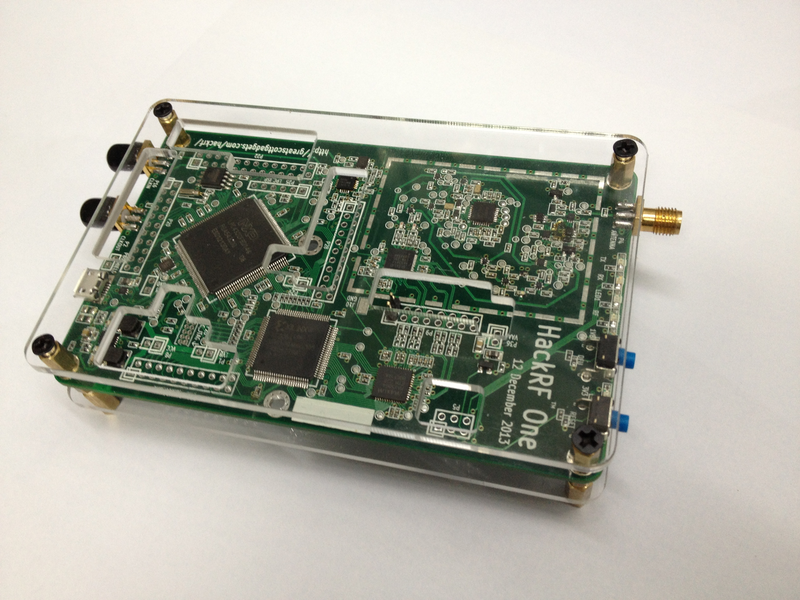
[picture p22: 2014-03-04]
hardware/hackrf-one/PlasticCase_CAD/Case_With_HackRF.png

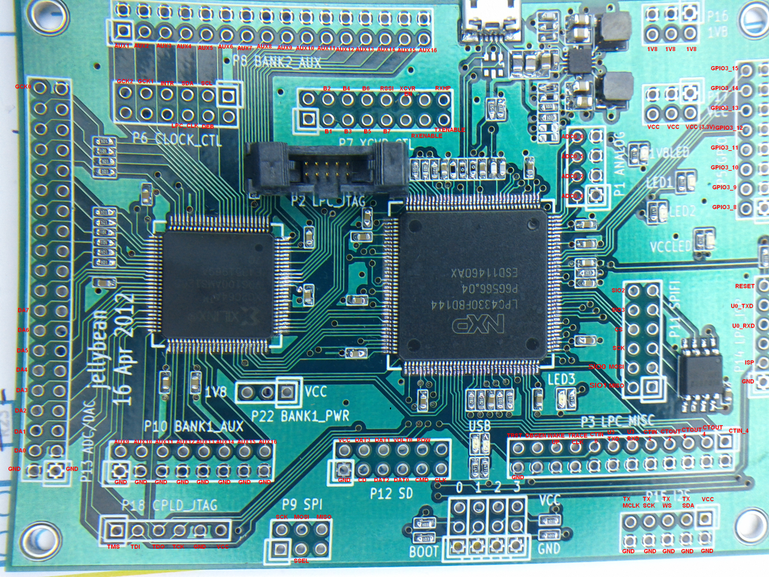
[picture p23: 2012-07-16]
hardware/jellybean/JellyBean_pins.png

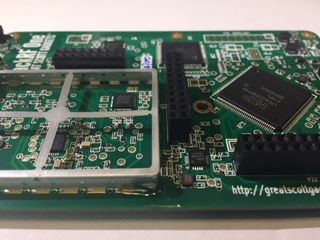
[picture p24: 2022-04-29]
docs/images/rf_shield_4.jpg

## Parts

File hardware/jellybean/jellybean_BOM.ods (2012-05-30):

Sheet: JellyBean_BOM
Ref | Value | Manufacturer | Footprint | Details | DigiKey Quantity | DigiKey PN
R1 | 0 | Panasonic | ERJ-3GEY0R00V | RES 0.0 OHM 1/10W 0603 SMD | 2 | P0.0GCT-ND
R2 | 0 | Panasonic | ERJ-3GEY0R00V | RES 0.0 OHM 1/10W 0603 SMD
R18 | 100 | Panasonic | ERJ-3GEYJ101V | RES 100 OHM 1/10W 5% 0603 SMD | 10 | P100GCT-ND
R19 | 100 | Panasonic | ERJ-3GEYJ101V | RES 100 OHM 1/10W 5% 0603 SMD
R20 | 100 | Panasonic | ERJ-3GEYJ101V | RES 100 OHM 1/10W 5% 0603 SMD
R21 | 100 | Panasonic | ERJ-3GEYJ101V | RES 100 OHM 1/10W 5% 0603 SMD
R22 | 100 | Panasonic | ERJ-3GEYJ101V | RES 100 OHM 1/10W 5% 0603 SMD
R23 | 100 | Panasonic | ERJ-3GEYJ101V | RES 100 OHM 1/10W 5% 0603 SMD
R24 | 100 | Panasonic | ERJ-3GEYJ101V | RES 100 OHM 1/10W 5% 0603 SMD
R25 | 100 | Panasonic | ERJ-3GEYJ101V | RES 100 OHM 1/10W 5% 0603 SMD
R26 | 100 | Panasonic | ERJ-3GEYJ101V | RES 100 OHM 1/10W 5% 0603 SMD
R27 | 100 | Panasonic | ERJ-3GEYJ101V | RES 100 OHM 1/10W 5% 0603 SMD
R12 | 470 | Panasonic | ERJ-3GEYJ471V | RES 470 OHM 1/10W 5% 0603 SMD | 7 | P470GCT-ND
R13 | 470 | Panasonic | ERJ-3GEYJ471V | RES 470 OHM 1/10W 5% 0603 SMD
R15 | 470 | Panasonic | ERJ-3GEYJ471V | RES 470 OHM 1/10W 5% 0603 SMD
R29 | 470 | Panasonic | ERJ-3GEYJ471V | RES 470 OHM 1/10W 5% 0603 SMD
R3 | 470 | Panasonic | ERJ-3GEYJ471V | RES 470 OHM 1/10W 5% 0603 SMD
R8 | 470 | Panasonic | ERJ-3GEYJ471V | RES 470 OHM 1/10W 5% 0603 SMD
R9 | 470 | Panasonic | ERJ-3GEYJ471V | RES 470 OHM 1/10W 5% 0603 SMD
R30 | 1k8 | Panasonic | ERJ-3GEYJ182V | RES 1.8K OHM 1/10W 5% 0603 SMD | 2 | P1.8KGCT-ND
R31 | 1k8 | Panasonic | ERJ-3GEYJ182V | RES 1.8K OHM 1/10W 5% 0603 SMD
R16 | 10k | Panasonic | ERJ-3GEYJ103V | RES 10K OHM 1/10W 5% 0603 SMD | 13 | P10KGCT-ND
R17 | 10k | Panasonic | ERJ-3GEYJ103V | RES 10K OHM 1/10W 5% 0603 SMD
R28 | 10k | Panasonic | ERJ-3GEYJ103V | RES 10K OHM 1/10W 5% 0603 SMD
R32 | 10k | Panasonic | ERJ-3GEYJ103V | RES 10K OHM 1/10W 5% 0603 SMD
R39 | 10k | Panasonic | ERJ-3GEYJ103V | RES 10K OHM 1/10W 5% 0603 SMD
R4 | 10k | Panasonic | ERJ-3GEYJ103V | RES 10K OHM 1/10W 5% 0603 SMD
R40 | 10k | Panasonic | ERJ-3GEYJ103V | RES 10K OHM 1/10W 5% 0603 SMD
R41 | 10k | Panasonic | ERJ-3GEYJ103V | RES 10K OHM 1/10W 5% 0603 SMD
R42 | 10k | Panasonic | ERJ-3GEYJ103V | RES 10K OHM 1/10W 5% 0603 SMD
R43 | 10k | Panasonic | ERJ-3GEYJ103V | RES 10K OHM 1/10W 5% 0603 SMD
R5 | 10k | Panasonic | ERJ-3GEYJ103V | RES 10K OHM 1/10W 5% 0603 SMD
R6 | 10k | Panasonic | ERJ-3GEYJ103V | RES 10K OHM 1/10W 5% 0603 SMD
R7 | 10k | Panasonic | ERJ-3GEYJ103V | RES 10K OHM 1/10W 5% 0603 SMD
R14 | 12k | Panasonic | ERJ-3EKF1202V | RES 12.0K OHM 1/10W 1% 0603 SMD | 1 | P12.0KHCT-ND
R10 | 15k | Panasonic | ERJ-3GEYJ153V | RES 15K OHM 1/10W 5% 0603 SMD | 1 | P15KGCT-ND
R11 | 33k | Panasonic | ERJ-3GEYJ333V | RES 33K OHM 1/10W 5% 0603 SMD | 1 | P33KGCT-ND
R36 | 160k+560k in parallel (to obtain 3,3V instead of 2.7V) | Panasonic | ERJ-3EKF1603V | RES 160K OHM 1/10W 1% 0603 SMD | 1 | P160KHCT-ND
R35 | 180k | Panasonic | ERJ-3EKF1803V | RES 180K OHM 1/10W 1% 0603 SMD | 1 | P180KHCT-ND
R37 | 360k | Panasonic | ERJ-3EKF3603V | RES 360K OHM 1/10W 1% 0603 SMD | 1 | P360KHCT-ND
R38 | 560k | Panasonic | ERJ-3EKF5603V | RES 560K OHM 1/10W 1% 0603 SMD | 2 | P560KHCT-ND
C24 | 22pF | Murata | GRM1885C1H220JA01D | CAP CER 22PF 50V 5% NP0 0603 | 10 | 490-1411-1-ND
C18 | 47pF | Murata | GRM1885C1H470JA01D | CAP CER 47PF 50V 5% NP0 0603 | 10 | 490-1419-1-ND
C1 | 100nF | Murata | GRM188R71C104KA01D | CAP CER 0.1UF 16V 10% X7R 0603 | 30 | 490-1532-1-ND
C10 | 100nF | Murata | GRM188R71C104KA01D | CAP CER 0.1UF 16V 10% X7R 0603
C11 | 100nF | Murata | GRM188R71C104KA01D | CAP CER 0.1UF 16V 10% X7R 0603
C12 | 100nF | Murata | GRM188R71C104KA01D | CAP CER 0.1UF 16V 10% X7R 0603
C13 | 100nF | Murata | GRM188R71C104KA01D | CAP CER 0.1UF 16V 10% X7R 0603
C14 | 100nF | Murata | GRM188R71C104KA01D | CAP CER 0.1UF 16V 10% X7R 0603
C15 | 100nF | Murata | GRM188R71C104KA01D | CAP CER 0.1UF 16V 10% X7R 0603
C17 | 100nF | Murata | GRM188R71C104KA01D | CAP CER 0.1UF 16V 10% X7R 0603
C19 | 100nF | Murata | GRM188R71C104KA01D | CAP CER 0.1UF 16V 10% X7R 0603
C2 | 100nF | Murata | GRM188R71C104KA01D | CAP CER 0.1UF 16V 10% X7R 0603
C20 | 100nF | Murata | GRM188R71C104KA01D | CAP CER 0.1UF 16V 10% X7R 0603
C22 | 100nF | Murata | GRM188R71C104KA01D | CAP CER 0.1UF 16V 10% X7R 0603
C23 | 100nF | Murata | GRM188R71C104KA01D | CAP CER 0.1UF 16V 10% X7R 0603
C25 | 100nF | Murata | GRM188R71C104KA01D | CAP CER 0.1UF 16V 10% X7R 0603
C26 | 100nF | Murata | GRM188R71C104KA01D | CAP CER 0.1UF 16V 10% X7R 0603
C29 | 100nF | Murata | GRM188R71C104KA01D | CAP CER 0.1UF 16V 10% X7R 0603
C3 | 100nF | Murata | GRM188R71C104KA01D | CAP CER 0.1UF 16V 10% X7R 0603
C32 | 100nF | Murata | GRM188R71C104KA01D | CAP CER 0.1UF 16V 10% X7R 0603
C33 | 100nF | Murata | GRM188R71C104KA01D | CAP CER 0.1UF 16V 10% X7R 0603
C4 | 100nF | Murata | GRM188R71C104KA01D | CAP CER 0.1UF 16V 10% X7R 0603
C5 | 100nF | Murata | GRM188R71C104KA01D | CAP CER 0.1UF 16V 10% X7R 0603
C7 | 100nF | Murata | GRM188R71C104KA01D | CAP CER 0.1UF 16V 10% X7R 0603
C8 | 100nF | Murata | GRM188R71C104KA01D | CAP CER 0.1UF 16V 10% X7R 0603
C9 | 100nF | Murata | GRM188R71C104KA01D | CAP CER 0.1UF 16V 10% X7R 0603
C16 | 100pF | Murata | GRM1885C1H101JA01D | CAP CER 100PF 50V 5% NP0 0603 | 10 | 490-1427-1-ND
C6 | 4u7 | Taiyo Yuden | LMK212BJ475KD-T | CAP CER 4.7UF 10V 10% X5R 0805 | 1 | 587-1297-1-ND
C21 | 10uF | Murata | GRM21BR61A106KE19L | CAP CER 10UF 10V 10% X5R 0805 | 10 | 490-1709-1-ND
C27 | 10uF | Murata | GRM21BR61A106KE19L | CAP CER 10UF 10V 10% X5R 0805
C28 | 10uF | Murata | GRM21BR61A106KE19L | CAP CER 10UF 10V 10% X5R 0805
C30 | 10uF | Murata | GRM21BR61A106KE19L | CAP CER 10UF 10V 10% X5R 0805
C31 | 10uF | Murata | GRM21BR61A106KE19L | CAP CER 10UF 10V 10% X5R 0805
L1 | 4u7 | Taiyo Yuden | NRG4026T4R7M | INDUCTOR 4.7UH 1.6A 20% SMD | 2 | 587-2382-1-ND
L2 | 4u7 | Taiyo Yuden | NRG4026T4R7M | INDUCTOR 4.7UH 1.6A 20% SMD
FB1 | FILTER | Murata | BLM21PG221SN1D | FERRITE CHIP 220 OHM 2000MA 0805 | 1 | 490-1054-1-ND
U1 | GSG-IP4220CZ6 | NXP | IP4220CZ6,125 | IC USB DUAL ESD PROTECT 6TSOP | 1 | 568-3529-1-ND
J1 | GSG-USB-MICRO-B | FCI | 10103594-0001LF | CONN RCPT STD MICRO USB TYPE B | 1 | 609-4050-1-ND
U4 | GSG-XC2C64A-7VQG100C | Xilinx | XC2C64A-7VQG100C | IC CR-II CPLD 64MCELL 100-VQFP | 1 | 122-1409-ND
U2 | LPC43XXFBD144 | NXP | LPC4330FBD144,551 | IC MCU 32BIT 144LQFP | 1 | 568-9450-ND
U5 | TPS62410 | Texas Instruments | TPS62410DRCR | IC BUCK SYNC DUAL ADJ 0.8A 10SON | 1 | 296-25488-1-ND
D3 | LED3 | Everlight | QTLP601CRTR | LED RED STD BRIGHT 0603 SMD | 1 | 1080-1407-1-ND
D5 | 1V8LED | Everlight | QTLP600CYTR | LED YLW SUPER BRIGHT 0606 SMD | 3 | 1080-1404-1-ND
D2 | LED2 | Everlight | QTLP600CYTR | LED YLW SUPER BRIGHT 0606 SMD
D7 | USBLED0 | Everlight | QTLP600CYTR | LED YLW SUPER BRIGHT 0606 SMD
D1 | LED1 | Everlight | QTLP601C4TR | LED GREEN STD BRIGHT 0603 SMD | 3 | 1080-1405-1-ND
D6 | USBLED1 | Everlight | QTLP601C4TR | LED GREEN STD BRIGHT 0603 SMD
D4 | VCCLED | Everlight | QTLP601C4TR | LED GREEN STD BRIGHT 0603 SMD
U3 | W25Q80BV | Winbond | W25Q80BVSSIG | IC FLASH 8MBIT 8SOIC | 1 | W25Q80BVSSIG-ND
P2 | LPC_JTAG | Samtec Inc | EHF-105-01-L-D | CONN HEADER .05" 10POS DUAL T/H | 1 | SAM8205-ND
P16 | 1V8
P13 | ADC/DAC
P1 | ANALOG
P10 | BANK1_AUX
P22 | BANK1_PWR
P8 | BANK2_AUX
P4 | BOOT0
P19 | BOOT1
P20 | BOOT2
P21 | BOOT3
P6 | CLOCK_CTL
P18 | CPLD_JTAG
R33 | DNP
R34 | DNP
P5 | GPIO
P15 | I2S
P14 | LPC_ISP
P3 | LPC_MISC
P12 | SD
P9 | SPI
P11 | SPIFI
P7 | XCVR_CTL
P17 | VCC

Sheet: ImportPart_DigiKey
2,P0.0GCT-ND
10,P100GCT-ND
7,P470GCT-ND
2,P1.8KGCT-ND
13,P10KGCT-ND
1,P12.0KHCT-ND
1,P15KGCT-ND
1,P33KGCT-ND
1,P160KHCT-ND
1,P180KHCT-ND
1,P360KHCT-ND
2,P560KHCT-ND
10,490-1411-1-ND
10,490-1419-1-ND
30,490-1532-1-ND
10,490-1427-1-ND
1,587-1297-1-ND
10,490-1709-1-ND
2,587-2382-1-ND
1,490-1054-1-ND
1,568-3529-1-ND
1,609-4050-1-ND
1,122-1409-ND
1,568-9450-ND
1,296-25488-1-ND
1,1080-1407-1-ND
3,1080-1404-1-ND
3,1080-1405-1-ND
1,W25Q80BVSSIG-ND
1,SAM8205-ND

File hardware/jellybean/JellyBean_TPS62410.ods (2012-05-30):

 | TPS62410 VCC |  | TPS62410 1V8
R36 (OHM) | 160000 | R35 (OHM) | 180000
R38 (OHM) | 560000 | R37 (OHM) | 360000
 | VCC (Converter1) |  | 1V8
Out Voltage | 2,7 | Out Voltage | 1,8
After Fix 3.3V
 | TPS62410 VCC
R36 (OHM) | 124444 | 160KOHM in // with 560KOHM
R38 (OHM) | 560000
 | VCC (Converter1)
Out Voltage | 3,3

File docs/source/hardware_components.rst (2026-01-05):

================================================
Hardware Components
================================================

Block Diagrams
~~~~~~~~~~~~~~

HackRF Pro Block Diagram
^^^^^^^^^^^^^^^^^^^^^^^^

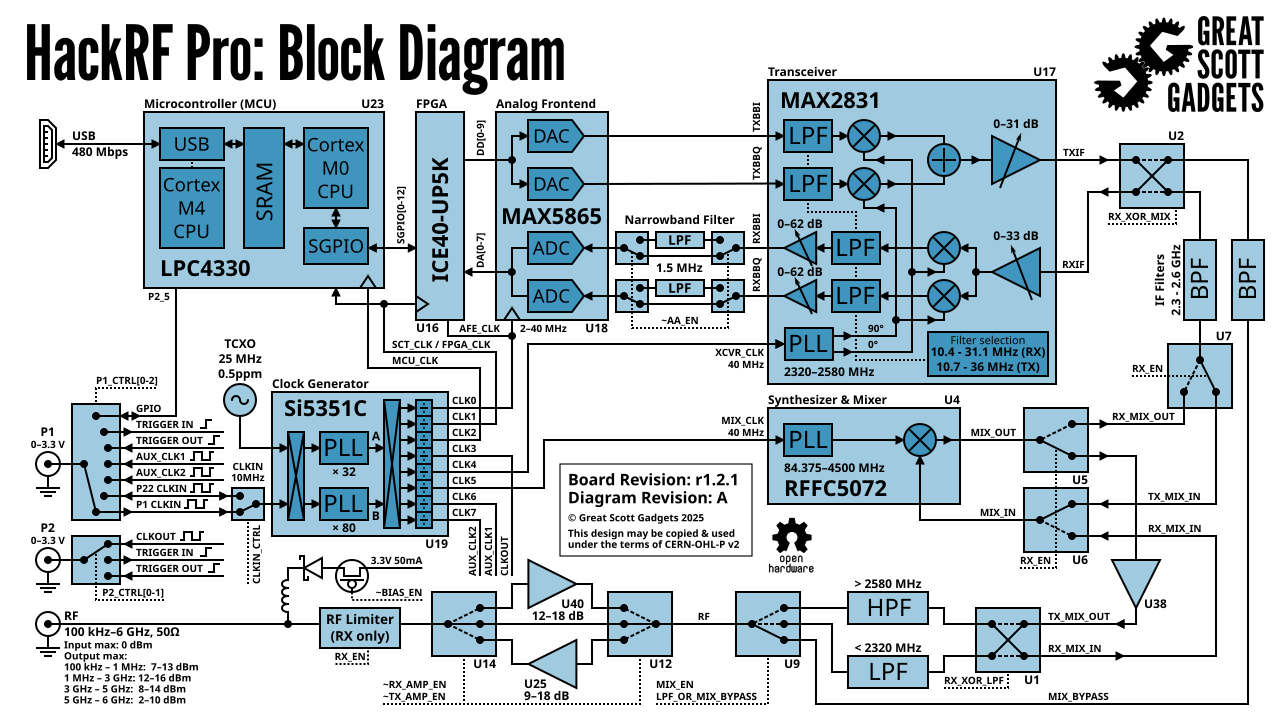
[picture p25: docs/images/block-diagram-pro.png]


|

HackRF One r1-r8 Block Diagram
^^^^^^^^^^^^^^^^^^^^^^^^^^^^^^

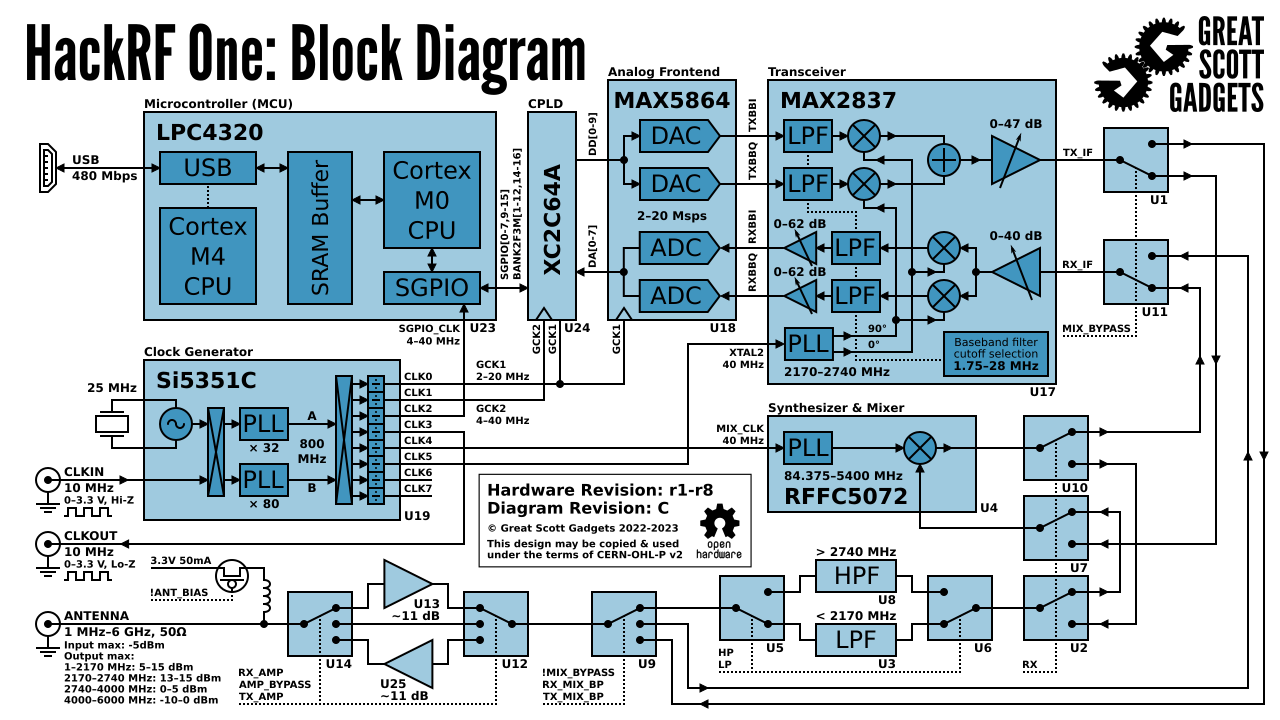
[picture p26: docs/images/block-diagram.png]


|

HackRF One r9 Block Diagram
^^^^^^^^^^^^^^^^^^^^^^^^^^^

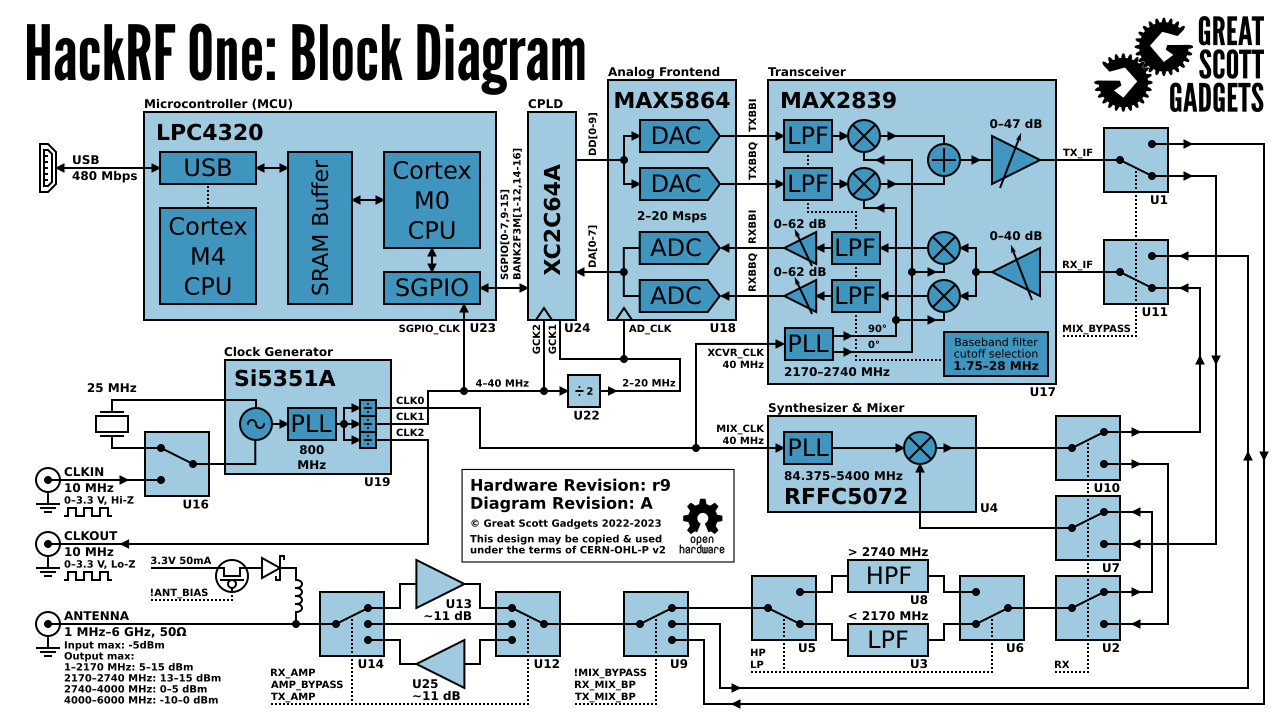
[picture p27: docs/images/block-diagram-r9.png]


|

Key Components
~~~~~~~~~~~~~~

Major parts used in HackRF:

* `MAX2831 2.3 to 2.6 GHz transceiver <https://www.analog.com/en/products/max2831.html>`__
    * Used on HackRF Pro.
    * `Datasheet <https://www.analog.com/media/en/technical-documentation/data-sheets/MAX2831-MAX2832.pdf>`__

* `MAX2837 2.3 to 2.7 GHz transceiver <https://www.analog.com/en/products/max2837.html>`__
    * Used on HackRF One (except revision r9), Jawbreaker and rad1o.
    * `Datasheet <https://www.analog.com/media/en/technical-documentation/data-sheets/max2837.pdf>`__
* `MAX2839 2.3 to 2.7 GHz transceiver <https://www.analog.com/en/products/max2839.html>`__
    * Substitution for MAX2837, used on HackRF One revision r9.
    * `Datasheet <https://www.analog.com/media/en/technical-documentation/data-sheets/max2839.pdf>`__
* `MAX5864 ADC/DAC <https://www.analog.com/en/products/max5864.html>`__
    * `Datasheet <https://www.analog.com/media/en/technical-documentation/data-sheets/MAX5864.pdf>`__
* `Si5351 clock generator <http://www.silabs.com/products/clocksoscillators/clock-generator/Pages/lvcmos-clocks-5-outputs.aspx>`__
    * `AN619: Manually Generating an Si5351 Register Map <http://www.silabs.com/Support%20Documents/TechnicalDocs/AN619.pdf>`__
    * `Datasheet <http://www.silabs.com/Support%20Documents/TechnicalDocs/Si5351.pdf>`__ - see AN619 for the complete register map.
    * `Other Documentation <http://www.silabs.com/products/clocksoscillators/clock-generators-and-buffers/Pages/clock+vcxo.aspx>`__ - includes application notes, user guides, and white papers.
* `ice40 UltraPlus FPGA <https://www.latticesemi.com/en/Products/FPGAandCPLD/iCE40UltraPlus>`__ (HackRF Pro)
* CoolRunner-II CPLD (all other platforms)
* `LPC43xx ARM Cortex-M4 microcontroller <http://www.nxp.com/products/microcontrollers-and-processors/arm-processors/lpc-arm-cortex-m-mcus/lpc-dual-core-cortex-m0-m4f/lpc4300:MC_1403790133078>`__
    * `User Manual <http://www.nxp.com/documents/user_manual/UM10503.pdf>`__
    * `Datasheet <http://www.nxp.com/documents/data_sheet/LPC4350_30_20_10.pdf>`__
    * `Other Documentation (LPC4330FBD144) <http://www.nxp.com/products/microcontrollers/cortex_m4/lpc4300/LPC4330FBD144.html#documentation>`__ - includes errata and application notes.
    * `ARM-standard JTAG/SWD connector pinout <http://www.keil.com/support/man/docs/ulink2/ulink2_hw_connectors.htm>`__
    * `BSDL file for the LPC43xx (For boundary scan) <http://www.lpcware.com/system/files/LPC18xx_43xx%20BSDL%20files%2020121127_0.zip>`__
* `RFFC5072 mixer/synthesizer <http://www.rfmd.com/store/rffc5072-1.html>`__
    * `Datasheet <http://www.rfmd.com/CS/Documents/RFFC5071_2DS.pdf>`__
    * `Other Documentation <http://www.rfmd.com/store/rffc5072-1.html>`__ ; click "Technical Documents" - includes programming guides and application notes.
* `W25Q32 32M-bit Flash <https://www.winbond.com/resource-files/W25Q32JV%20RevJ%2012242024%20Plus.pdf>`__ (HackRF Pro)
* `W25Q80BV 8M-bit Flash <https://www.winbond.com/resource-files/w25q80bv%20revk%2020151203.pdf>`__ (all other platforms)

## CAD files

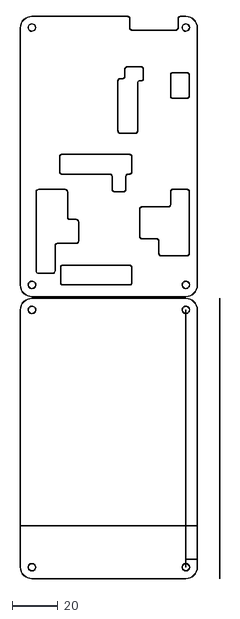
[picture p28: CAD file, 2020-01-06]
hardware/hackrf-one/acrylic_case/HackRF_One_Case_v2.dxf
86.7 x 244.8

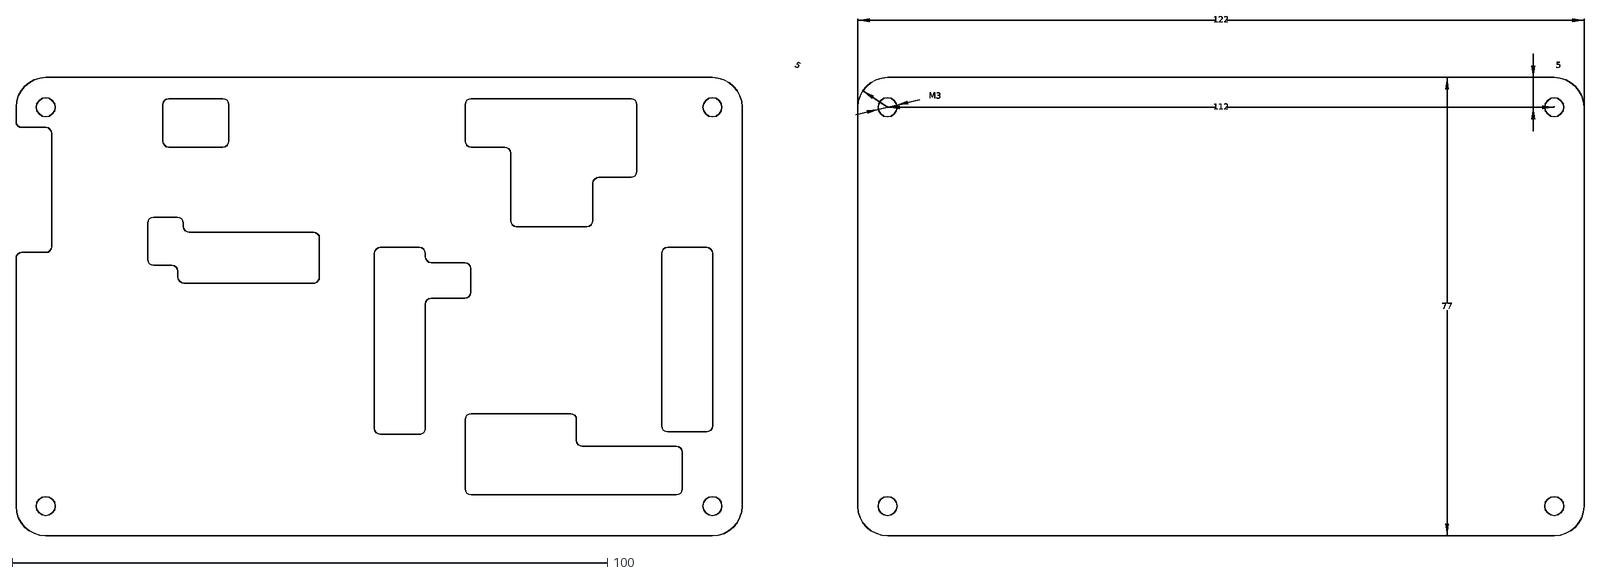
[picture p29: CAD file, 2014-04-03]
hardware/hackrf-one/PlasticCase_CAD/HackRF_One_Case_With_Button_CutOuts.dxf
5
M3
112
122
77

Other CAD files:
hardware/jawbreaker/SoBv1_DP17298/SoBv1-DP17298-jawbreaker-Bottom.skp
hardware/jawbreaker/SoBv1_DP17298/SoBv1-DP17298-jawbreaker-Top.skp

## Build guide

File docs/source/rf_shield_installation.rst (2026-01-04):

===============================================
RF Shield Installation Instructions
===============================================

HackRF Pro ships with an RF shield as standard.

Official Great Scott Gadgets HackRF Ones do not come from the factory with an RF shield installed around the radio section of the PCB. They do, however, have pads in place so that one may be installed if a user has a reason and an inclination to do so. The reason that they do not come preinstalled is that early testing revealed that the RF shield did little to improve the performance of the HackRF One. The recommended RF shield is the BMI-S-230-F-R (frame) with the BMI-S-230-C (shield). A two part RF shield is recommended because the shield section can be removed to allow access to the RF section of the HackRF One. This can be important if it becomes necessary to probe any part of the RF section, or to replace any parts of the RF section. However, even with a two part RF shield, it can be difficult to access the RF section of the HackRF One in certain situations. The following steps are a basic set of instructions for installing a RF shield on a HackRF One.

**CAUTION: Soldering a RF shield onto a HackRF One comes with a certain amount of risk. Beyond the inherent risks of soldering itself, this process may damage the HackRF One and no warranty is available to cover damage incurred from this process. If you do choose to install a RF shield on your HackRF One please proceed with caution.**

1. Remove the HackRF One from the injection molded plastic case. 

  **BE WARNED: Opening the plastic case of your HackRF One will most likely destroy the tabs that hold it together.**  

  Instructions for removing a HackRF One from its case can be found :ref:`here <open_your_hackrf_one>`.

2. Prepare the HackRF One PCB for soldering on the shield frame, by adding flux to the RF shield pads around the radio section on the PCB.

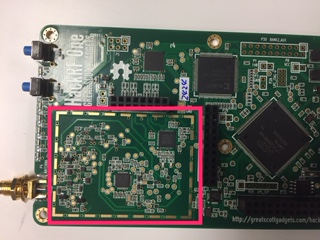
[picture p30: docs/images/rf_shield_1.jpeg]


3. Place the RF shield frame on the HackRF One, aligning it so that it makes contact with all of the pads around the RF section of the board.

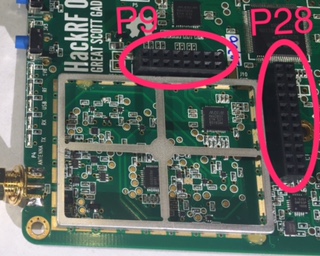
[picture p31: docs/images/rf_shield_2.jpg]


4. Solder the shield to one pad to anchor it to the H1. Visually inspect the frame to assure that it is still aligned properly.

+---------------------------------------+---------------------------------------+
| 
+---------------------------------------+---------------------------------------+

5. Connect the frame to another pad on the opposite side from the first connection. Again, check that the frame is still aligned properly.

+---------------------------------------+---------------------------------------+
| 
+---------------------------------------+---------------------------------------+

6. Connect at least one more pad, and then remove the pick and place bridge from the frame. *Removing the pick and place bridge is optional, but it is recommended.*

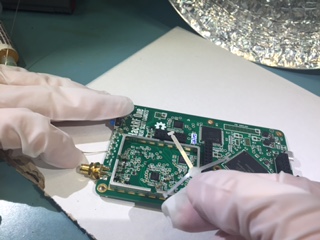
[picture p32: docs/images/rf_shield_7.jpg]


7. Continue soldering the rest of the pads to the frame.

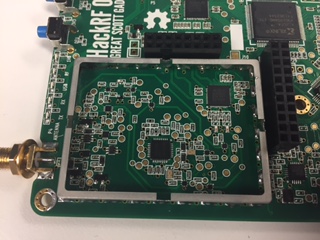
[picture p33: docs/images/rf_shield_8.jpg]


8. Clean the flux and soldering residue with the appropriate solvent for the type of flux used. Be sure to let the HackRF One dry completely before plugging it in to a power source.

9. Place the RF shield onto the frame and snap it into place.

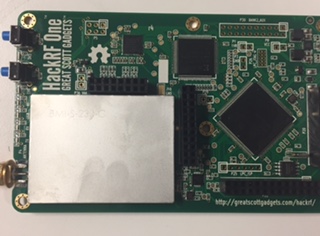
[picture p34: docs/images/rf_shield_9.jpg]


10. If desired, put the HackRF One back into the plastic case, if it is still able to click together.

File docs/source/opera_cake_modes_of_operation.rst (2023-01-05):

==================
Modes of Operation
==================

Opera Cake supports three modes of operation: ``manual``, ``frequency``, and ``time``. The operating mode can be set with the ``--mode`` or ``-m`` option, and the active operating mode is displayed with the ``--list`` or ``-l`` option.

Manual Mode
~~~~~~~~~~~

The default mode of operation is ``manual``. In manual mode, fixed port connections are configured with the ``-a`` and ``-b`` options as in the :ref:`port configuration examples <portconfiguration>`. If the operating mode has been changed, it can be changed back to manual mode with:

.. code-block:: sh

	hackrf_operacake -m manual

Frequency Mode
~~~~~~~~~~~~~~

In frequency mode, the A0 port connection switches automatically whenever the HackRF is tuned to a different frequency. This is useful when antennas for different frequency bands are connected to various ports.

The bands are specified in priority order. The final band specified will be used for frequencies not covered by the other bands specified.

To assign frequency bands to ports you must use the ``-f <port:min:max>`` option for each band, with the minimum and maximum frequencies specified in MHz. For example, to use port A1 for 100 MHz to 600 MHz, A3 for 600 MHz to 1200 MHz, and B2 for 0 MHz to 4 GHz:

.. code-block:: sh

	hackrf_operacake -m frequency -f A1:100:600 -f A3:600:1200 -f B2:0:4000

If tuning to precisely 600 MHz, A1 will be used as it is listed first. Tuning to any frequency over 4 GHz will use B2 as it is the last listed and therefore the default port.

Only the A0 port connection is specified in frequency mode. Whenever the A0 connection is switched, the B0 connection is also switched to the secondary port mirroring A0's secondary port. For example, when A0 switches to B2, B0 is switched to A2.

Once configured, an Opera Cake will remain in frequency mode until the mode is reconfigured or until the HackRF One is reset. You can pre-configure the Opera Cake in frequency mode, and the automatic switching will continue to work while using other software.

Although multiple Opera Cakes on a single HackRF One may be set to frequency mode at the same time, they share a single switching plan. This can be useful, for example, for a filter bank consisting of eight filters.

Time Mode
~~~~~~~~~

In time mode, the A0 port connection switches automatically over time, counted in units of the sample period. This is useful for experimentation with pseudo-doppler direction finding.

To cycle through four ports, one port every 1000 samples:

.. code-block:: none

	hackrf_operacake -m time -t A1:1000 -t A2:1000 -t A3:1000 -t A4:1000

When the duration on multiple ports is the same, the ``-w`` option can be used to set the default dwell time:

.. code-block:: none

	hackrf_operacake --mode time -w 1000 -t A1 -t A2 -t A3 -t A4

Only the A0 port connection is specified in time mode. Whenever the A0 connection is switched, the B0 connection is switched to the secondary port mirroring A0's secondary port. For example, when A0 switches to B2, B0 is switched to A2.

Once configured, an Opera Cake will remain in time mode until the mode is reconfigured or until the HackRF One is reset. You can pre-configure the Opera Cake in time mode, and the automatic switching will continue to work while using other software.

Although multiple Opera Cakes on a single HackRF One may be set to time mode at the same time, they share a single switching plan.

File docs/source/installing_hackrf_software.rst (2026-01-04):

.. _operating_system_tips:

==========================
Installing HackRF Software
==========================

HackRF software includes HackRF Tools and libhackrf. HackRF Tools are the commandline utilities that let you interact with your HackRF. libhackrf is a low level library that enables software on your computer to operate with HackRF. 

Install Using Package Managers
~~~~~~~~~~~~~~~~~~~~~~~~~~~~~~

Unless developing or testing new features for HackRF, we highly recommend that most users use build systems or package managers provided for their operating system. **Our suggested operating system for use with HackRF is Ubuntu**.

FreeBSD
+++++++

You can use the binary package: ``# pkg install hackrf``

You can also build and install from ports:

.. code-block :: sh

	# cd /usr/ports/comms/hackrf
	# make install

Linux: Arch
+++++++++++

.. code-block :: sh

	pacman -S hackrf

Linux: Fedora / Red Hat
+++++++++++++++++++++++

``sudo dnf install hackrf -y``

Linux: Gentoo
+++++++++++++

.. code-block :: sh

	emerge -a net-wireless/hackrf-tools

Linux: Ubuntu / Debian
++++++++++++++++++++++

``sudo apt-get install hackrf``

OS X (10.5+): Homebrew
++++++++++++++++++++++

``brew install hackrf``

OS X (10.5+): MacPorts
++++++++++++++++++++++

``sudo port install hackrf``

Windows: Binaries
+++++++++++++++++

Windows users can use `radioconda <https://github.com/ryanvolz/radioconda>`__ to get the required binaries installed.

Alternatively, binaries are available as build artifacts under the 'Actions'-tab on github `here <https://github.com/greatscottgadgets/hackrf/actions>`__ (GitHub Login needed).

-----------

Installing From Source
~~~~~~~~~~~~~~~~~~~~~~

Linux / OS X / \*BSD: Building HackRF Software From Source
++++++++++++++++++++++++++++++++++++++++++++++++++++++++++

Acquire the source for the HackRF tools from either a `release archive <https://github.com/greatscottgadgets/hackrf/releases>`__ or git: ``git clone https://github.com/greatscottgadgets/hackrf.git``

Once you have the source downloaded, the host tools can be built as follows:

.. code-block :: sh

	cd hackrf/host
	mkdir build
	cd build
	cmake ..
	make
	sudo make install
	sudo ldconfig

If you have HackRF hardware, you may need to :ref:`update the firmware <updating_firmware>` to match the host tools versions.

Windows: Building HackRF Software From Source
+++++++++++++++++++++++++++++++++++++++++++++

Install `Visual Studio Community <https://visualstudio.microsoft.com/vs/community/>`__ (2015 or later) and `CMake <https://cmake.org/>`__ (at least version 3.21.4).

Install library dependencies using `vcpkg <https://vcpkg.io/en/>`__:

.. code-block :: winbatch

	git clone https://github.com/microsoft/vcpkg
	cd vcpkg
	bootstrap-vcpkg.bat
	vcpkg install libusb fftw3 pthreads pkgconf

Open the Visual Studio Developer Command Prompt, and change to the directory where you unpacked the HackRF source.

The following steps assume you installed vcpkg in ``C:\vcpkg``.

Configure CMake and build the code:

.. code-block :: winbatch

	set PKG_CONFIG=C:\vcpkg\installed\x64-windows\tools\pkgconf\pkgconf.exe
	set PKG_CONFIG_PATH=C:\vcpkg\installed\x64-windows\lib\pkgconfig
	set CMAKE_TOOLCHAIN_FILE=C:\vcpkg\scripts\buildsystems\vcpkg.cmake
	cmake -B host\build host
	cmake --build host\build

CMake will generate a ``HackRF.sln`` project file which you can open in Visual Studio for editing and development.

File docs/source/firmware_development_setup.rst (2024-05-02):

================================================
Firmware Development Setup
================================================

Firmware build instructions are included in the repository under firmware/README:

`https://github.com/greatscottgadgets/hackrf/blob/master/firmware/README <https://github.com/greatscottgadgets/hackrf/blob/master/firmware/README>`__

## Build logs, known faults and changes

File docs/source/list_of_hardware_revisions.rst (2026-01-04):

================================================
Hardware Revisions
================================================

Hardware revisions exist mainly to deal with changes in component availability. Each revision of a product meets the same performance specifications that are measured in the factory.

HackRF Pro
~~~~~~~~~~

The initial production revision of HackRF Pro is r1.2.1.

HackRF One
~~~~~~~~~~

HackRF One r1–r4
^^^^^^^^^^^^^^^^

The first revision of HackRF One shipped by Great Scott Gadgets starting in 2014 was labeled r1. Subsequent manufacturing runs incremented the revision number up to r4 without modification to the hardware design. Manufacturing years: 2014–2020

HackRF One r5
^^^^^^^^^^^^^

This experimental revision has not been manufactured.

HackRF One r6
^^^^^^^^^^^^^

SKY13350 RF switches were replaced by SKY13453. Although the SKY13453 uses simplified control logic, it did not require a firmware modification. Hardware revision detection pin straps were added. Manufacturing year: 2020

HackRF One r7
^^^^^^^^^^^^^

SKY13453 RF switches were reverted to SKY13350. USB VBUS detection resistor values were updated. Manufacturing year: 2021

HackRF One r8
^^^^^^^^^^^^^

SKY13350 RF switches were replaced by SKY13453. Manufacturing years: 2021–2022

HackRF One r9
^^^^^^^^^^^^^

MAX2837 was replaced by MAX2839. Si5351C was replaced by Si5351A with additional clock distribution. A series diode was added to the antenna port power supply. Manufacturing year: 2023

HackRF One r10
^^^^^^^^^^^^^^

This revision is based on r8, reverting most of the changes made in r9. A series diode was added to the antenna port power supply. Manufacturing year: 2024

Hardware Revision Identification
~~~~~~~~~~~~~~~~~~~~~~~~~~~~~~~~

HackRF Ones manufactured by Great Scott Gadgets have the revision number printed on the PCB top silkscreen layer near the MAX5864 (U18).

Starting with HackRF One r6, hardware revisions are detected by firmware and reported by ``hackrf_info``.

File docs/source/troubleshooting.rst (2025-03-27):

.. _troubleshooting:

================================================
Troubleshooting
================================================

HackRF not detected / "No HackRF boards found."
~~~~~~~~~~~~~~~~~~~~~~~~~~~~~~~~~~~~~~~~~~~~~~~

If the software you're using is unable to detect the HackRF hardware and/or `hackrf_info` returns "No HackRF boards found.", this can be caused by a number of different software or hardware issues.

Solution
--------

    #. If you are using a PortaPack addon, make sure to select "HackRF" mode from the main menu.

    #. If you are using a virtual machine or Windows Subsystem for Linux (WSL), make sure that it is configured to pass through the USB device.

    #. Check whether the device appears in ``lsusb`` (Linux), Device Manager (Windows), or System Report (macOS). If it doesn't not appear, it could either be a firmware issue, an issue with the cable, or another hardware issue.

    #. Try booting the HackRF in DFU mode by holding the "DFU" button when plugging in the device. It should now appear as `NXP Semiconductors LPC4330FET180 [ARM Cortex M4 + M0] (device firmware upgrade mode)` in the locations listed above. If it does appear, then it was likely a firmware issue and you can follow the instructions to :ref:`recover the SPI flash firmware <recovering_firmware>`.

    #. If the device does not appear in DFU mode then it is likely to be an issue with the USB cable. Charge-only cables (which do not include the data lines) have become very common and will cause this symptom. Ideally, test the cable you're using with another device that does some sort of data transfer to be sure that it works, or just try other cables.

    #. If the device still does not appear, it may be a less common issue or possibly a fault with the hardware. See :doc:`Getting Help <getting_help>` for information on where to ask for more support, and please include as much detail as you can about what you've already tried.

.. _bigspike:

There is a big spike in the center of the received spectrum
~~~~~~~~~~~~~~~~~~~~~~~~~~~~~~~~~~~~~~~~~~~~~~~~~~~~~~~~~~~

If you see a large spike in the center of your FFT display regardless of the frequenecy you are tuned to, you are seeing a DC offset (or component or bias). The term "DC" comes from "Direct Current" in electronics. It is the unchanging aspect of a signal as opposed to the "alternating" part of the signal (AC) that changes over time.

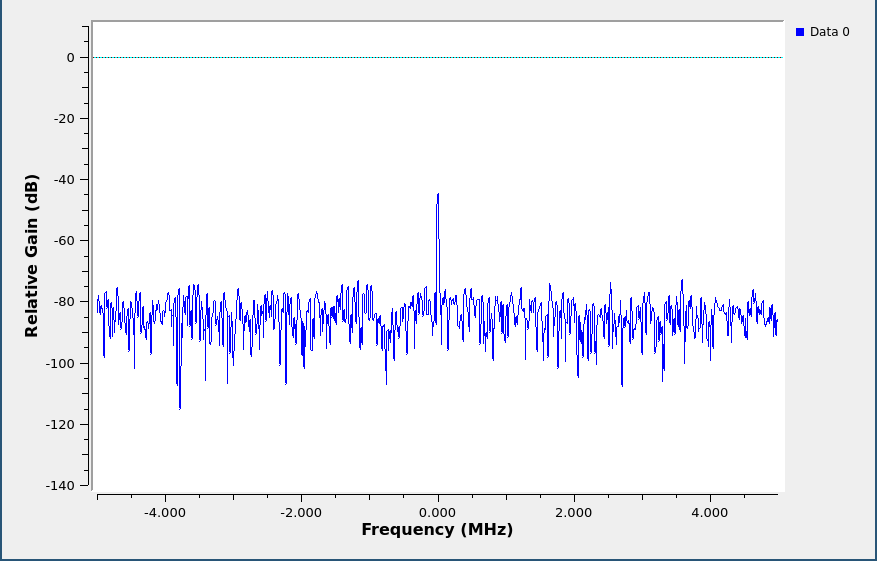
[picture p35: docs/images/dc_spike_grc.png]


   DC spike

Take, for example, the signal represented by the digital sequence:

.. code-block:: sh

	-2, -1, 1, 6, 8, 9, 8, 6, 1, -1, -2, -1, 1, 6, 8, 9, 8, 6, 1, -1, -2, -1, 1, 6, 8, 9, 8, 6, 1, -1

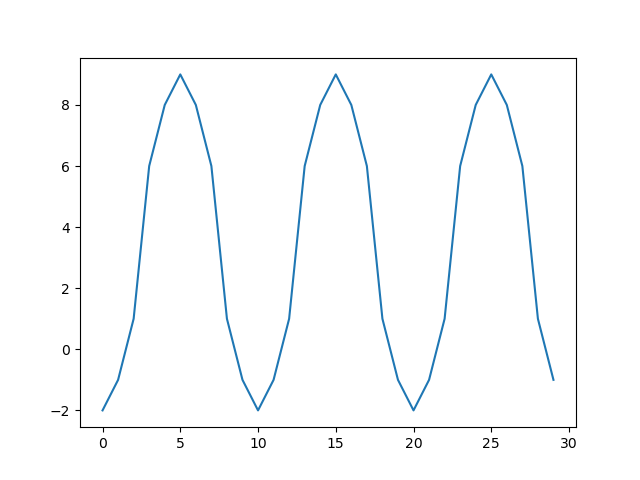
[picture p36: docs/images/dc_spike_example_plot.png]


   Example signal

This periodic signal contains a strong sinusoidal component spanning from -2 to 9. If we plot the spectrum of this signal, you can see one spike at the frequency of this sinusoid and a second spike at 0 Hz (DC).

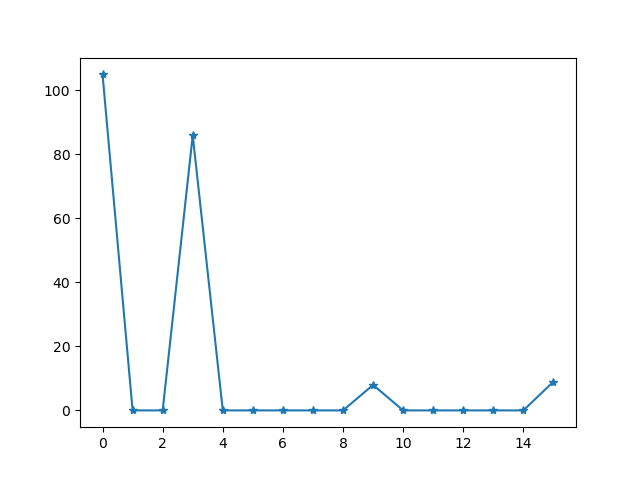
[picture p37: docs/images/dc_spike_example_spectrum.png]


   Spectrum of example signal

If the signal spanned from values -2 to 2 (centered around zero), there would be no DC offset. Since it is centered around 3.5 (the number midway between -2 and 9), there is a DC component.

Samples produced by HackRF are measurements of radio waveforms, but the measurement method is prone to a DC bias introduced by HackRF. It's an artifact of the measurement system, not an indication of a received radio signal. DC offset is not unique to HackRF; it is common to all quadrature sampling systems.

A high DC offset is also one of a few symptoms that can be caused by a software version mismatch. A common problem is that people run an old version of gr-osmosdr with newer firmware.

Solution
--------

There are a few options:

    #. Ignore it. For many applications it isn't a problem. You'll learn to ignore it.

    #. Avoid it. The best way to handle DC offset for most applications is to use offset tuning; instead of tuning to your exact frequency of interest, tune to a nearby frequency so that the entire signal you are interested in is shifted away from 0 Hz but still within the received bandwidth. If your algorithm works best with your signal centered at 0 Hz (many do), you can shift the frequency in the digital domain, moving your signal of interest to 0 Hz and your DC offset away from 0 Hz. HackRF's high maximum sampling rate can be a big help as it allows you to use offset tuning even for relatively wideband signals.

    #. Correct it. There are various ways of removing the DC offset in software. However, these techniques may degrade parts of the signal that are close to 0 Hz. It may look better, but that doesn't necessarily mean that it is better from the standpoint of a demodulator algorithm, for example. Still, correcting the DC offset is often a good choice.

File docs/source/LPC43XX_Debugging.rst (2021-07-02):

================================================
LPC43xx Debugging
================================================

Various debugger options for the LPC43xx exist.

Black Magic Probe
~~~~~~~~~~~~~~~~~

`https://github.com/blacksphere/blackmagic <https://github.com/blacksphere/blackmagic>`__

An example of using gdb with the Black Magic Probe:

.. code-block :: sh

	arm-none-eabi-gdb -n blinky.elf
	target extended-remote /dev/ttyACM0
	monitor swdp_scan
	attach 1
	set {int}0x40043100 = 0x10000000
	load
	cont

It is possible to attach to the M0 instead of the M4 if you use jtag_scan instead of swdp_scan, but the Black Magic Probe had some bugs when trying to work with the M0 the last time I tried it.  

LPC-Link
~~~~~~~~

(included with LPCXpresso boards)

TitanMKD has had some success. See the tutorial in hackrf/doc/LPCXPresso_Flash_Debug_Tutorial.pdf or .odt (PDF and OpenOffice document) Doc Link [https://github.com/mossmann/hackrf/tree/master/doc)

ST-LINK/V2
~~~~~~~~~~

Hardware Configuration
^^^^^^^^^^^^^^^^^^^^^^

Start with an STM32F4-Discovery board. Remove the jumpers from CN3. Connect the target's SWD interface to CN2 "SWD" connector.

Software Configuration
^^^^^^^^^^^^^^^^^^^^^^

I'm using libusb-1.0.9.

Install OpenOCD-0.6.0 dev
+++++++++++++++++++++++++

.. code-block:: sh

	# Cloned at hash a21affa42906f55311ec047782a427fcbcb98994
	git clone git://openocd.git.sourceforge.net/gitroot/openocd/openocd
	cd openocd
	./bootstrap
	./configure --enable-stlink --enable-buspirate --enable-jlink --enable-maintainer-mode
	make
	sudo make install

OpenOCD configuration files
+++++++++++++++++++++++++++

openocd.cfg

.. code-block:: sh

	#debug_level 3
	source [find interface/stlink-v2.cfg]
	source ./lpc4350.cfg

lpc4350.cfg

.. code-block :: sh

	set _CHIPNAME lpc4350
	set _M0_CPUTAPID 0x4ba00477
	set _M4_SWDTAPID 0x2ba01477
	set _M0_TAPID 0x0BA01477
	set _TRANSPORT stlink_swd

	transport select $_TRANSPORT

	stlink newtap $_CHIPNAME m4 -expected-id $_M4_SWDTAPID
	stlink newtap $_CHIPNAME m0 -expected-id $_M0_TAPID

	target create $_CHIPNAME.m4 stm32_stlink -chain-position $_CHIPNAME.m4
	#target create $_CHIPNAME.m0 stm32_stlink -chain-position $_CHIPNAME.m0

target.xml, nabbed from an OpenOCD mailing list thread, to fix a communication problem between GDB and newer OpenOCD builds.

.. code-block:: sh

	<?xml version="1.0"?>
	<!DOCTYPE target SYSTEM "gdb-target.dtd">
	<target>
	  <feature name="org.gnu.gdb.arm.core">
	    <reg name="r0" bitsize="32" type="uint32"/>
	    <reg name="r1" bitsize="32" type="uint32"/>
	    <reg name="r2" bitsize="32" type="uint32"/>
	    <reg name="r3" bitsize="32" type="uint32"/>
	    <reg name="r4" bitsize="32" type="uint32"/>
	    <reg name="r5" bitsize="32" type="uint32"/>
	    <reg name="r6" bitsize="32" type="uint32"/>
	    <reg name="r7" bitsize="32" type="uint32"/>
	    <reg name="r8" bitsize="32" type="uint32"/>
	    <reg name="r9" bitsize="32" type="uint32"/>
	    <reg name="r10" bitsize="32" type="uint32"/>
	    <reg name="r11" bitsize="32" type="uint32"/>
	    <reg name="r12" bitsize="32" type="uint32"/>
	    <reg name="sp" bitsize="32" type="data_ptr"/>
	    <reg name="lr" bitsize="32"/>
	    <reg name="pc" bitsize="32" type="code_ptr"/>
	    <reg name="cpsr" bitsize="32" regnum="25"/>
	  </feature>
	  <feature name="org.gnu.gdb.arm.fpa">
	    <reg name="f0" bitsize="96" type="arm_fpa_ext" regnum="16"/>
	    <reg name="f1" bitsize="96" type="arm_fpa_ext"/>
	    <reg name="f2" bitsize="96" type="arm_fpa_ext"/>
	    <reg name="f3" bitsize="96" type="arm_fpa_ext"/>
	    <reg name="f4" bitsize="96" type="arm_fpa_ext"/>
	    <reg name="f5" bitsize="96" type="arm_fpa_ext"/>
	    <reg name="f6" bitsize="96" type="arm_fpa_ext"/>
	    <reg name="f7" bitsize="96" type="arm_fpa_ext"/>
	    <reg name="fps" bitsize="32"/>
	  </feature>
	</target>

Run ARM GDB
~~~~~~~~~~~

Soon, I should dump this stuff into a .gdbinit file.

.. code-block:: sh

	arm-none-eabi-gdb -n
	target extended-remote localhost:3333
	set tdesc filename target.xml
	monitor reset init
	monitor mww 0x40043100 0x10000000
	monitor mdw 0x40043100   # Verify 0x0 shadow register is set properly.
	file lpc4350-test.axf    # This is an ELF file.
	load                     # Place image into RAM.
	monitor reset init
	break main               # Set a breakpoint.
	continue                 # Run to breakpoint.
	continue                 # To continue from the breakpoint.
	step                     # Step-execute the next source line.
	stepi                    # Step-execute the next processor instruction.
	info reg                 # Show processor registers.

More GDB tips for the GDB-unfamiliar:

.. code-block:: sh

	# Write the variable "buffer" (an array) to file "buffer.u8".
	dump binary value buffer.u8 buffer

	# Display the first 32 values in buffer whenever you halt
	# execution.
	display/32xh buffer

	# Print the contents of a range of registers (in this case the
	# CGU peripheral, starting at 0x40050014, for 46 words):
	x/46 0x40050014

And still more, for debugging ARM Cortex-M4 Hard Faults:

.. code-block :: sh

	# Assuming you have a hard-fault handler wired in:
	display/8xw args

	# Examine fault-related registers:

	# Configurable Fault Status Register (CFSR) contains:
	# CFSR[15:8]: BusFault Status Register (BFSR)
	#   "Shows the status of bus errors resulting from instruction
	#   prefetches and data accesses."
	#   BFSR[7]: BFARVALID: BFSR contents valid.
	#   BFSR[5]: LSPERR: fault during FP lazy state preservation.
	#   BFSR[4]: STKERR: derived bus fault on exception entry.
	#   BFSR[3]: UNSTKERR: derived bus fault on exception return.
	#   BFSR[2]: IMPRECISERR: imprecise data access error.
	#   BFSR[1]: PRECISERR: precise data access error, faulting
	#            address in BFAR.
	#   BFSR[0]: IBUSERR: bus fault on instruction prefetch. Occurs
	#            only if instruction is issued.
	display/xw 0xE000ED28

	# BusFault Address Register (BFAR)
	# "Shows the address associated with a precise data access fault."
	# "This is the location addressed by an attempted data access that
	# was faulted. The BFSR shows the reason for the fault and whether
	# BFAR_ADDRESS is valid..."
	# "For unaligned access faults, the value returned is the address
	# requested by the instruction. This might not be the address that
	# faulted."
	display/xw 0xE000ED38

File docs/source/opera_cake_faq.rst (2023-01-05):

=====================================
Frequently Asked Questions
=====================================

Why the name 'Opera Cake'?
~~~~~~~~~~~~~~~~~~~~~~~~~~

Internally at Great Scott Gadgets, HackRF related boards are code named with a candy or confection name. The Opera Cake code name was fun enough that we didn't change from it when we released the project.

When was Opera Cake first for sale?
~~~~~~~~~~~~~~~~~~~~~~~~~~~~~~~~~~~

Great Scott Gadgets first released Opera Cake for sale in 2022. The open source project for Opera Cake has been available since 2016 from Great Scott Gadgets.

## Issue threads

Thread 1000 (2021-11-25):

I have no clue how to set up the Opera Cake

0xGSMonkey, 2021-11-25:
I have no clue what to do to set up the opera cake after I built it.

I keep getting "Operacakes found: None" error

I am not sure what I am supposed to do in order to get it to work.

gozu42, 2021-11-25:
what version of hackrf firmware + userspace are you using?
please post the output of "hackrf_info".

0xGSMonkey, 2021-11-25:
Lol, it could be that I solder some things together wrong. I just thought about that. I don't have the LEDs soldered on.

But, requested info:
hackrf_info version: git-5f1536c*
libhackrf version: git-5f1536c*(0.6)
Firmware Version: 2018.01.1 (API:1.02)

I took out the Index, serial number, board id and part id.

gozu42, 2021-11-25:
that userland is from 2021-04, the firmware is ... a bit older.
can you please update both to current git head?
there has been at least one change related to operacake since april, and even though i dont think it matters here, it would help if everyone involved is staring at the same code while trying to figure this out.

0xGSMonkey, 2021-11-26:
hackrf_info version: git-26c0f70
libhackrf version: git-26c0f70 (0.6)
Firmware Version: git-26c0f70 (API:1.05)

root@user-Space-Shuttle-888:/home/user/Hacking/hackrf/firmware/hackrf_usb/build# hackrf_operacake -l
Opera Cakes found: None

I really believe I might have messed up putting the board together. It shorts the board out when I stack Opera Cake on top of the HackRF One. Unless there It isn't shorting out the HackRF

gozu42, 2021-11-26:
great.
if you want someone to take a look at your soldering, please post reasonably high resolution pictures of your board.
"shorts the board out" doesnt sound too good, really.

but we can continue a bit without that too.
if you look at the code for "hackrf_operacake -l" [here](https://github.com/greatscottgadgets/hackrf/blob/22267f3b8e71bd064337921444b0e40509f47b43/host/hackrf-tools/src/hackrf_operacake.c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), it basicly just calls hackrf_get_operacake_boards, for which the other end is [here](https://github.com/greatscottgadgets/hackrf/blob/22267f3b8e71bd064337921444b0e40509f47b43/firmware/hackrf_usb/usb_api_operacake.c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), and that just returns the currently-known-to-the-firmware list of operacakes.
that list gets populated during operacake_init [here](https://github.com/greatscottgadgets/hackrf/blob/22267f3b8e71bd064337921444b0e40509f47b43/firmware/common/operacake.c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), and is basicly just some i2c probing.
which means if the list is empty, that probing fails, meaning the hackrf firmware fails to talk (in the right way) to the PCA9557PW on the operacake board.
so, besides investigating the general "shorting out the board" situation, i would recommend to focus on that for now.

0xGSMonkey, 2021-11-26:
I got it. I think. But, if I have any more problems I will definitely let everyone know. If this thread can stay open for the next couple of weeks I would appreciate that. But, yeah my soldering definitely needs some work. One of the capacitors on the board is not on the pad at all. I am going to try to fix that this week if I can.

hackrf_info:
hackrf_info version: git-5f1536c*
libhackrf version: git-5f1536c*(0.6)
Firmware Version: git-22267f3 (API:1.05) [+]

[+] this branch(?) seemed to fix it. or I got super lucky. And it just didn't short.

After compiling from github source and not using the tar.bz2 file I was able to get opera cake to work.

gozu42, 2021-11-26:
note that in this last post your hackrf_info+libhackrf versions have gone back to the 2021-04 version (5f1536c), i would recommend you stick to the "git head" version (26c0f70) you had 2h earlier for anything operacake related.
(there really has been a lot of work on operacake in the last months)

for reworking the soldering and testing the result, recommend you start with the i2c connection, and then work towards the sma sockets, if that makes any sense. also, populating the LEDs means you get visual feedback on what the switches think they are doing, which might help a lot.

keeping the issue open for a while is probably no problem, straithe is _supposed_ to be on vacation and not closing it, but i also thought it meant not _labeling_ issues. but, even if you or someone else closes it, you can always just reopen it if another question pops up.

for slightly more interactive support, you could also join #hackrf on [the GSG discord](https://discord.gg/rsfMw3rsU8).

straithe, 2021-11-29:
I'm happy to keep this issue for a while. The advice given by @gozu42 is sound.

I will be adding a lot more documentation on Opera Cake over the next while as Great Scott Gadgets ramps up production. ☺️

straithe, 2021-12-28:
@0xGSMonkey do you need any more assistance, or may I close this issue?

straithe, 2022-01-28:
I'm going to close this as there hasn't been a response in a while, but please open a new issue if you need further assistance.

Closed 2022-01-28.

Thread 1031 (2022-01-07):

HackRF One no work and very very hot

sastre, 2022-01-07:
Hi people.
I have a problem with my HackRF One. I will try to explain the problem
- I have been using it during some years with SDR#: all OK.
- A few years ago, I bought the Portapack H2 with HAVOC firmware: all OK
- 4 days ago, I tried to update the HAVOC to MAYHEM firmware.
- My PC correctly detected but I could not get the update because my version of Windows is old (apparently ...)
- I confirm you my USB cable work OK and I have not made any hardware modifications. Only try to update the firmware
- After what I have described, when I had to use the USB cable to charge HackRF One+Portapack H2, the device do not well
- Sometimes the LCD mean with light or the blue Led of rotary encoder mean On.
- Then, I disconnected the HackRF one from Portapack H2 to check both devices to check it separately.
- Finally, I discovered that, after 1 sec or less after connecting the USB cable, the main IC (LPC4320 ...) reaches a very very very high temperature.
- If I switch on with the Portapack H2 with your internal LiPo battery, (without USB cable) the exact same thing happens.

 I can not belive...
Both devices always work OK. Together or alone. But now, no work
Could someyone help me?
```

gozu42, 2022-01-08:
lets debug this in steps, starting with just the hackrf.
please remove the portapack from the hackrf.
press+hold the DFU button, plug in the hackrf (or press+release reset if already plugged in), release the DFU button.
do you see an NXP dfu device on the host after this?

do you have any linux around, even if its just a random raspi or so? (in my exp, that makes usb debugging somewhat easier)

also, could you please post pictures of the front and back of the hackrf board?

sastre, 2022-01-08:
Hi! The portapack already disconnected from the HackRF One. When I switch
on with the USB cable the HackRF One not work and the IC LPC4320... gets
very very hot in 1 second only.
I have used DFU and RESET buttons but the problem remind. I have not Linux.
Only I have W10 32bits.
I think that there is some electronic component of HackRF One damaged ...

El sáb, 8 ene 2022 a las 1:50, gozu42 ***@***.***>) escribió:

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

straithe, 2022-01-10:
Which version of the Portapack do you have? Can you add a picture here?

sastre, 2022-01-10:
I use Portapack H2 (see photos). Until a few days ago, I always use HackRF
One with Portapack H2 Havoc firmware HAVOC with no problem

El lun, 10 ene 2022 a las 8:51, Straithe ***@***.***>)
escribió:

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

straithe, 2022-01-10:
I do not see any photos. If you are responding to this GitHub issue from email, attachments will not be seen.

Can you make sure you get pictures of all USB ports while your HackRF is in the Portapack?

sastre, 2022-01-10:
And now?

El lun, 10 ene 2022 a las 23:22, Straithe ***@***.***>)
escribió:

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

straithe, 2022-01-10:
Can you please open your issue in GitHub and respond with pictures via the website and not through your email?

sastre, 2022-01-11:
OK. Here the photos of may portapack H2
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

Closed 2022-01-11.

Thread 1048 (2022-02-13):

possible hardware defect

ecc1, 2022-02-13:
I have 2 HackRF Ones. I've been using one for years, and it works fine. The other was still in a sealed box until today, when I wanted to upgrade the firmware on both units. The second unit seems to be defective.

### Steps to reproduce
Use gqrx to listen to a local FM station.

### Expected behaviour
FM reception should continue indefinitely.

### Actual behaviour
Reception stops after approximately 5 minutes (sooner if changing frequency), with error messages like
"Failed to stop RX streaming (-1000)" and
"hackrf_set_freq(4.51291e+08) has failed (-1000) No such device (it may have been disconnected)".

### Version information
Debian testing
hackrf and libhackrf0 packages version  2021.03.1-2

hackrf_info version: unknown
libhackrf version: unknown (0.6)
Found HackRF
Index: 0
Serial number: 0000000000000000909864c8389869cf
Board ID Number: 2 (HackRF One)
Firmware Version: 2021.03.1 (API:1.04)
Part ID Number: 0xa000cb3c 0x006a435e

Photos of the suspect unit are attached. I have some basic test equipment (multimeter, oscilloscope) if there's anything I should check.

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

martinling, 2022-02-13:
You say you have one unit failing and the other working - have you tried them both on the exact same USB cable plugged into the same port? It sounds like it's just disappearing off the USB bus completely, so I'd just like to rule out any other hardware factors.

ecc1, 2022-02-13:
Yes, I'm just switching the micro end of the USB cable from one unit to the other.

martinling, 2022-02-13:
It may be worth checking again with current git master versions of the firmware & host packages, as there are a few intermittent bugs caused by race conditions that we've fixed since the 2021.03.01 release.

In particular, we had some problems that were showing up as a loss of reception when changing parameters in gqrx (#883) and those were fixed with the changes in PR #1029.

ecc1, 2022-02-13:
But is there enough variability between hardware builds that this problem could occur consistently with one unit and never with another?

straithe, 2022-02-14:
No. That is abnormal.

martinling, 2022-02-14:
For firmware problems that have a race condition involved it's plausible for one unit to be more prone than another, e.g. due to slight differences in oscillator frequencies.

I'm certainly not ruling out a hardware fault here - but it does seem odd to have a fault that shows up only after several minutes _and_ happens more quickly if making changes in gqrx. It's hard to see what failure mechanism would give that sort of result, whereas I just fixed several race conditions with very similar symptoms.

So it'd be interesting to know if you get the same result on current master - or for that matter the previous 2018.01.1 release, since that release seems to have been less prone to timing bugs. If the behaviour is the same with other firmware versions, then it seems like it must be a hardware fault, albeit a strange one. Whereas if it works with some different version, then that may indicate there is yet another race condition I need to track down and fix in the firmware.

So I would much rather find it's a hardware fault! We have a simple solution for those: you contact your reseller for a return.

roadmutt, 2022-02-14:
I need to re solder a tiny little resistor on one of my hacked sdrs

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

ecc1, 2022-02-14:
I built and flashed the current firmware from git, but the same problem occurs:

> Failed to stop RX streaming (-1000)
> Failed to close HackRF (-1000) No such device (it may have been disconnected)

It doesn't always take 5 minutes to fail; sometimes it happens almost immediately (that was the case for the released version too).

martinling, 2022-02-14:
OK, thank you for the additional testing to confirm.

It seems pretty clear that this is a hardware fault. You can contact your reseller to arrange a return.

Closed 2022-02-24.

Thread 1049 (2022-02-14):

i put 19v in the rf :(

andreasr81, 2022-02-14:
hi, i make a dump mistak yesterday, i switched the sat cable that providing 19v for the lnb and put it in my hackrf, the hackrf is still recognicing by the pc for a moment, and is also receiving,  but near the usb plug its getting very hot,  and the usb light beginn to dimming i think there is a shortage somewhere, maybe someone had a simular problem and no what to do?

martinling, 2022-02-14:
Hmm. I'm impressed that it's still working at all after getting 19V on the RF input, since that would lead to current going through the body diode of Q4 into VAA, and from there through Q3 into VCC. I would have expected widespread damage to parts all over the board.

But perhaps that route has also somehow saved you, if something downstream managed to effectively clamp the input to a lower level, burning itself out in the process. So it might be possible to repair if you want to do so.

If you can identify exactly which component is getting hot, then if you're lucky, replacing that component might be sufficient. Close to the USB port, my guesses would be either the regulator U21 in the corner, or the TVS array U15.

In fact U15 seems quite likely, since the current path I described above might continue backwards through the regulator and the body diode of Q5, eventually getting clamped to ~6.5V by U15. For a brief period, that might make the event survivable.

If U15 is the problem, you can actually remove it completely for testing purposes. Its function is to protect the USB VBUS and data lines from transient voltage events. So the HackRF will be vulnerable to static discharge at the USB port without it, but it will still connect to a host.

andreasr81, 2022-02-15:
thanks a lot for giving me that informations, i have to ask a friend to help me there.

helmet21, 2022-04-12:
Hi!

Sorry to post in a closed issue but I tried to access the discord to send my question but was unable due to problems with the registration process. Also I thought it might be better to post in this issue since my question is very similar.

I also suspect I fed voltage into the RF input and the result is a component becoming very hot. The HackRF seems to turn on normally for a second or two but then the LEDs start flickering and dim.

I checked the components and there is one becoming very hot (almost instantly goes to 47 degrees celsius). The text on the component says "CAT OCI AVHR" but I can't find any information about it online and I can't find it on the schematics.

So I was wondering if maybe someone could tell me which component this is and how I can find a replacement.

Best regards
helmet21

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

straithe, 2022-04-12:
Please open a new GitHub issue and we'll be happy to help you out.

Closed 2022-03-17.

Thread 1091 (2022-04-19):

Multiple questions regarding the clocking signals

Algafix, 2022-04-19:
### Introduction

I was using the HackRF with a TCXO and the firmware 2018.01.1 to transmit a signal, but the RF signal produced was drifting. So I decided to output an RF sinusoidal signal at 40MHz and compare it with the one produced at the clock out port using an oscilloscope. Then I saw that the RF signal was not stable and was drifting all the time. In other words, when setting the trigger on the clock out signal, the RF signal was a blur: changing phase all the time.

### Exploring solutions

Therefore I decided to check the clocking signals produced by the Si5351C and realized that they are completely different that the ones indicated on the block diagram on this github:
* The CLK4 is transmitting to the RFFC5072 a 50MHz clocking signal
* The CLK7 is on.

So, assuming that this had to do with the firmware revision, I installed the 2021.03.1. Now, when I check the registers of the Si5351C, I see exactly the values indicated in the block diagram. But comparing the values with the 2018.01.1 I realize that:
* The CLK1 signal is Inverted
* The CLK4 signal is Inverted and at 40MHz.

### Questions

After exploring the documentation for the HackRF and the chips, I have some unresolved doubts:

* What is the reason behind inverting some clocking signals?
* Why was the RFFC5072 clock frequency changed from 50MHz to 40MHz?
  * Can I select an arbitrary frequency (assuming that the Si5351 can generate it)?
* Reading the lemondrop report on the signal phases I realized that maybe setting the MS4 as input for the CLK5 may help with the drifting problem (as both PLL would receive the same 40MHz signal), has someone tried that?

Thank you for the great work with HackRF.

mossmann, 2022-04-28:
>     * What is the reason behind inverting some clocking signals?
>
>     * Why was the RFFC5072 clock frequency changed from 50MHz to 40MHz?

The CPLD clock (CLK1) was inverted to increase timing margin. The RFFC5072 reference clock (CLK4) was changed to 40 MHz in an effort to reduce spurious emissions (which can show up as spurs in RX mode). Reducing the number of different clock frequencies on the board also reduces the number of clock harmonics. It was inverted with the intent that it would have the opposite phase of the similar MAX2837 reference clock (CLK5) in hopes that this would reduce power consumption noise at the clock generator.

>       * Can I select an arbitrary frequency (assuming that the Si5351 can generate it)?

You could modify that clock frequency in firmware if the new frequency is supported by both the RFFC5072 and the Si5351C. You can see how such a modification was made in acaf0d1.

>     * Reading the lemondrop report on the signal phases I realized that maybe setting the MS4 as input for the CLK5 may help with the drifting problem (as both PLL would receive the same 40MHz signal), has someone tried that?

I actually thought that this was done in acaf0d1, but it looks like it was not. The intent was to have CLK4 and CLK5 always be perfectly out of phase, and I believe they must share a multisynth for that to be the case. If you try it, please let us know how it goes!

Algafix, 2022-05-12:
Thank you for the answers and clarifications!

To discard other problems I did the same tests with an external much more precise clock generator instead of the TCXO. It took me a while since the clock signal was centered at 0V and the HackRF asks for 0V to 3.3V. But with a capacitor, 2 resistors and the Vcc pin I raised the signal from -1.6V/1.6V to 0V/3.3V.

My experiments with this external clock signal where precise enough, so I guess the problem was a faulty TCXO.

I did play with the RFFC5072 and its synths without getting any conclusive results. I had work to do and, once it worked out with the external clock, I did not progress further on that side. If in the future I see any improvement I'll let you know!

Thanks again!

Closed 2022-05-12.

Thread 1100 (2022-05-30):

Do not confuse the power injector connectors when connecting

H6LS1S, 2022-05-30:
### Steps to reproduce
1. Connect the power injector ( for Mini Whip )  to the HackRF One with the reverse side
2. Apply 9V power
3. Congrats you broke something

### Actual behaviour
I collected all the necessary parts for the Mini Whip antenna and confused up the inputs on the power injector. HackRF began to whistle strangely (similar to the whistle of chokes or an electrolytic capacitor). Without the injector HackRF works longer and even outputs some kind of signal in CubicSDR. But after a while (10 seconds + - ) the USB turns off. Two coils near the USB input (marking *H) get very hot.

By LED indication:
- constantly 3v3
- flickers 1v8 and RF
- the other are disabled

Can you please tell me what I broke?

### Version information

**hackrf_info output:**
hackrf_info version: unknown
libhackrf version: unknown (0.6)
Found HackRF
Index: 0
Serial number: 0000000000000000f77c60dc299656c3
Board ID Number: 2 (HackRF One)
Firmware Version: 2021.03.1 (API:1.04)
Part ID Number: 0xa000cb3c 0x00664358

martinling, 2022-05-30:
The bad news is that all sorts of things could be damaged. Excess voltage at the RF port can get onto the 3.3V rail through the body diode of Q4 in the bias tee circuit. In theory the resulting voltages can fry everything on the board.

The good news is that in practice, it seems that often either the regulator (U21) or the USB TVS array (U15) will clamp the downstream voltages to a low enough level to prevent damage, burning themselves out but saving the rest of the components.

The coils you mention getting hot are associated with the regulator (U21) - it's the chip between those two coils, and is probably where the heat is coming from. In at least one case (#668) a board with the same symptoms could be salvaged by replacing U21. However, it's also possible that the regulator is only getting hot because components downstream of it have failed, and are now drawing too much current from the regulator.

Unfortunately, that part (TPS62410DRCR) is out of stock in most places right now, so it might be hard to replace.

H6LS1S, 2022-05-31:
I was able to find TPS62410DRCR it at my place, in Kharkiv UA, I hope the warehouse was not damaged - http://www.kosmodrom.com.ua/prodlist.php?name=TPS62410

martinling, 2022-05-31:
That's great news to find some there, I hope the supplier is OK and been able to get back to business. Let us know how you get on.

Closed 2022-06-13.

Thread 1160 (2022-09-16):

[Tech Support]:

waldo545, 2022-09-16:
### Have you read the HackRF [troubleshooting documentation](https://hackrf.readthedocs.io/en/latest/troubleshooting.html)?

yes

### What outcome were you hoping for?

After a great exposition of Rf, hackrf stopped receiving. Changed U13 and hoped to fix the device

### What outcome actually happened?

What happened was that it didn't received anything.
I have observed that in test point 52 there is 3,5V and in test point 49 0V, so no voltage in U13 and no antenna switch in U14

### What operating systems are you seeing the problem on?

Debian Bullseye

### What is the output of ```hackrf_info```?

eduardo@waldo2:~$ hackrf_info
hackrf_info version: unknown
libhackrf version: unknown (0.5)
Found HackRF
Index: 0
Serial number: 000000000000000017c467dc3962a4c3
Board ID Number: 2 (HackRF One)
Firmware Version: 2021.03.1 (API:1.04)
Part ID Number: 0xa000cb3c 0x00544756

### Are you using any third-party software?

GNU Radio, Gqrx

### Are you using any third-party hardware?

No

mmm545, 2022-09-16:
Does test point P49 become high when turning on the RF AMP option in your software?

waldo545, 2022-09-17:
Thanks for the comment,
That was the point, I had not enabled the rf amp, I think I'm too old for this rock and roll.
Nevertheless sensitivity is very low, so I'll have to keep looking the other circuitry phases for if another MGA or SKY has passed away.
I'll be in touch with the progress, if any.
Thanks again mmm545
waldo

waldo545, 2022-09-17:
Sorry, issue is closed

Closed 2022-09-18.

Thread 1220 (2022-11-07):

[Question]: HackRf not being recognized by USB

jozamm, 2022-11-07:
### What would you like to know?

Dear all,

I have a PortaPack H2 with an internal battery

I charged the battery and by mistake plugged the port into Quick charge port 3.0.  It seems that the battery charged correctly than all lights switched off

After this event the HackRFone + PortPack H2 did not work. After removing the PortaPack and attaching the HackRF to the Laptop alone, only the 3.3V, RF and 1.8V LED's came on and no USB connectivity. Under Linux I could not open the device. When trying to use the DFU method the 3.3V and RF LED's light up with no USB connection. Previously it worked with the laptop so it not a port and cable issue.

I ran some other tests as follows and I totally baffled

Tests run
DC Voltage on 1.8V and 3.3V correct - Checked by multimeter
Current Consumption 170mA, DFU mode 70mA (Approx)

The LPC oscillator is running at 25MHz - Checked by Oscilloscope at XTAL pins
I checked the W25Q80, the LPC is accessing it as I aw activity using an oscilloscope on the CLK, DI and DO lines
There is no activity on the D+ and D- USB Lines
I ran some other activity tests for example I2S0_TX_SCK and there is a signal on it.
So the LPC seems to be running

Both in normal and DFU mode it is not detected in Linux, tried on Linux 22.10 latest hackrf package

Maybe there is a problem with U15 - VBUS54CV?

I troubleshooted the PortaPack H2 board and there is a short circuit caused by the battery charger IC but that is another story
Thanks for any help, Much appreciated

straithe, 2022-11-07:
Can you please re-open this issue as a technical support issue?

Closed 2022-11-07.

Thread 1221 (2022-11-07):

[Tech Support]: HackRf not being recognized by USB

jozamm, 2022-11-07:
### Have you read the HackRF [troubleshooting documentation](https://hackrf.readthedocs.io/en/latest/troubleshooting.html)?

yes

### What outcome were you hoping for?

Correct Operation of HackRF

### What outcome actually happened?

I charged the battery and by mistake plugged the port into Quick charge port 3.0.  It seems that the battery charged correctly than all lights switched off

After this event the HackRFone + PortPack H2 did not work. After removing the PortaPack and attaching the HackRF to the Laptop alone, only the 3.3V, RF and 1.8V LED's came on and no USB connectivity. Under Linux I could not open the device. When trying to use the DFU method the 3.3V and RF LED's light up with no USB connection. Previously it worked with the laptop so it not a port and cable issue.

I ran some other tests as follows and I totally baffled

Tests run

DC Voltage on 1.8V and 3.3V correct - Checked by multimeter
Current Consumption 170mA, DFU mode 70mA (Approx)
The LPC oscillator is running at 25MHz - Checked by Oscilloscope at XTAL pins
I checked the W25Q80, the LPC is accessing it as I saw activity using an oscilloscope on the CLK, DI and DO lines
There is no activity on the D+ and D- USB Lines

I ran some other activity tests for example I2S0_TX_SCK and there is a signal on it.

So the LPC seems to be running

### What operating systems are you seeing the problem on?

Windows 10
Ubuntu Linux 20.04 and 22.10

Both in normal and DFU mode the board is not detected in Linux, tried on Linux 22.10 latest hackrf package

### What is the output of ```hackrf_info```?

HackRf said that No Boards Detected

### Are you using any third-party software?

No

### Are you using any third-party hardware?

Board was attached PortaPack H2 when it stopped working

straithe, 2022-11-07:
In your description it says that you have tried the board on Windows and Linux, but that the board is not detected on Linux. Is the board detected on Windows?

jozamm, 2022-11-07:
Hi,

On windows it is not detected neither in normal mode nor DFU mode.

However I noted that the LPC went into DFU mode because when I switched to DFU the W25Q80 was not accessed by the LPV

straithe, 2022-11-07:
The outcome you have listed is "correct operation of HackRF One". Could you please be more detailed? What do you want to be able to do with the HackRF?

jozamm, 2022-11-07:
Hi, I need to get HackRF to establish a USB connection to the PC. That way I would confirm that it works.

After connect it to PortaPack H2 again

Thanks

straithe, 2022-11-07:
Can you please add a picture of your HackRF (not in the Portapack) to this issue?

jozamm, 2022-11-07:
Hi I, Here is a photo

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

straithe, 2022-11-07:
This is not a Great Scott Gadgets HackRF. It sounds like you do have a hardware issue. Please contact the person or company that you purchased your HackRF from to see if they can offer you a replacement.

Closed 2022-11-07.

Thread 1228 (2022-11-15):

[Question]: How to enable Bias Tee in HackRF One to power an antenna or amplifier?

alexeysirenko, 2022-11-15:
### What would you like to know?

Hello. I was unable to find a way to power an LNA using HackRF built-in ability to supply 3.3V over the coax cable. For instance, with RTL-SDR dongles it can be done simply using a bash script. With Hack RF it is not that easy. I found a couple of, as I thought, solutions, based on the `hackrf_transfer` utility (I used the one that comes with the PothosSDR software):
`hackrf_transfer -p 1` - it should have enabled the power, but this command can not be executed without extra parameters, that, if applied, start transferring data to/from the device and, since the device is busy, it no longer can be used as a source in SDR# or other similar software. Is there a workaround? For SDR# in particular. Thank you

P.S. I am using SDR# because of the plugins, I've heard that some other tools like SDR++ have an `enable bias tee` checkbox available for the HackRF, but if the only option would be to move to another software utility, I'll have to buy some other SDR receiver instead, unfortunately, so I am hoping for a solution suitable for SDR# too

P.P.S. This is the solution that I found, but it does not work:
https://www.reddit.com/r/RTLSDR/comments/8om4tg/biast_for_hackrf_on_sdr/
This is what I receive when I follow the instructions:
```
hackrf_transfer -p 1

specify one of: -t, -c, -r, -w

Usage:

-h # this help

[-d serial_number] # Serial number of desired HackRF.

-r <filename> # Receive data into file (use '-' for stdout).

-t <filename> # Transmit data from file (use '-' for stdin).

-w # Receive data into file with WAV header and automatic name.

# This is for SDR# compatibility and may not work with other software.

[-f freq_hz] # Frequency in Hz [0MHz to 7250MHz].

[-i if_freq_hz] # Intermediate Frequency (IF) in Hz [2150MHz to 2750MHz].

[-o lo_freq_hz] # Front-end Local Oscillator (LO) frequency in Hz [84MHz to 5400MHz].

[-m image_reject] # Image rejection filter selection, 0=bypass, 1=low pass, 2=high pass.

[-a amp_enable] # RX/TX RF amplifier 1=Enable, 0=Disable.

[-p antenna_enable] # Antenna port power, 1=Enable, 0=Disable.

[-l gain_db] # RX LNA (IF) gain, 0-40dB, 8dB steps

[-g gain_db] # RX VGA (baseband) gain, 0-62dB, 2dB steps

[-x gain_db] # TX VGA (IF) gain, 0-47dB, 1dB steps

[-s sample_rate_hz] # Sample rate in Hz (2-20MHz, default 10MHz).

[-n num_samples] # Number of samples to transfer (default is unlimited).

[-c amplitude] # CW signal source mode, amplitude 0-127 (DC value to DAC).

[-R] # Repeat TX mode (default is off)

[-b baseband_filter_bw_hz] # Set baseband filter bandwidth in Hz.

Possible values: 1.75/2.5/3.5/5/5.5/6/7/8/9/10/12/14/15/20/24/28MHz, default <= 0.75 * sample_rate_hz.

[-C ppm] # Set Internal crystal clock error in ppm.
```

P.P.P.S. I assume that there is a `hackrf_set_antenna_enable(1: uint)` function in hackrf.dll which is called by the `hackrf_transfer` util. So the best way would have been to have a checkbox added to the SDR# that, apparently, uses the same library, and when the device is started, calls this function. It is strange that this functionality is not implemented, but I really need the ability to power up an amplifier via bias tee as soon as possible, so a workaround would be fine

martinling, 2022-11-16:
The `hackrf_transfer` program shows you the usage message because you haven't given it anything to actually do. It's expecting to be given one of the `-r` (RX) `-t` (TX) or `-c` (CW signal generator) options. The `-p` option just makes it turn on the bias tee whilst it does that operation.

As soon as the HackRF leaves TX or RX mode, the firmware turns the bias tee off. I think that when that advice on Reddit was written, that user must have been using some old firmware version which failed to turn the bias tee off.

The right way for this to work is that SDR# needs to add a checkbox for the bias tee, and call the `hackrf_set_antenna_enable` function. There isn't any way to force it by running a helper program first, because the firmware turns the bias tee off as soon as it goes back to idle mode.

If you need a quick workaround without the hassle of modifying the SDR# UI, I see two options:

- Build your own copy of SDR# from source, adding a call to `hackrf_set_antenna_enable(device, 1)`. The place to put this would be just before wherever it calls `hackrf_start_rx`.

- Build your own copy of the HackRF firmware from source, and add a call to `rf_path_set_antenna(rf_path, 1)`. The place to put this would be in the `RF_PATH_DIRECTION_RX` block in `rf_path_set_direction`.

Either option would force the HackRF to always have the bias tee on when in RX mode.

straithe, 2022-11-28:
@alexeysirenko it looks like your question has been answered. May I close this issue?

alexeysirenko, 2022-11-29:
Yes, thank you

Closed 2022-11-29.

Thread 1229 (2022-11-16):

HELP ! Broken hardware component.. How to fix it ?

HaroGaro1312, 2022-11-16:
### What would you like to know?

  Hi,

  A few weeks ago I’ve bought a HackRF One  (Great Scott Gadgets) and a Portapack H2+ (clone), when I tried to mount the Portapack onto the HackRF One unfortunately the battery pushed onto a component and finished to broke the component.. (see the pictures)
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
the Portapack was initially hard to fit on, so I didn’t noticed when it reached the component.. I left that on side for a few weeks because I was disgusted of what happened.. But now I’m back.

  So, anyway, here’s my questions, does anyone have a solution for that ? Or an idea to fix it ? If it’s fixable of course.. Oh god.. Please tell me that’s fixable..

  I precise the HackRF One is still recognized on mac m1 with hackrf_info

  The broken piece’s still hanging on but if I push a little bit under and on the side of it, the broken mark disappears (see the 2nd picture) but I think that doesn’t solve anything, am I wrong ? (I know that doesn’t solve anything but right now like the UFOs "I want to believe" that will work..)

  Well if it doesn’t work (lol).. No seriously if you’ve got an idea of where I can get this component to replace the original broken one please tell me.. (See pictures) 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 And If I can repair it, is there is anything to do on the software/firmware or I just have to replace the component ? Or maybe if you know a repair shop where I can send the HackRF One for repair (if possible in France or Europe but even if it’s in US or New Zealand, I’ll take it). Honestly I’ll take any solution that can help me so if you have one please tell me, because I really need help..

  Well, a very big thanks in advance to anyone who come to help, seriously thank you very much if you can help on that problem.

  Cordially, Anthony.

mmm545, 2022-11-16:
It's totally fixable! It's a 4.7μH inductor, the original part is NRG4026T4R7M, however other parts like the LQH44PN4R7MPRL is a good option.

martinling, 2022-11-16:
That part is a 4.7uH inductor which is part of the 5V to 3.3V DC-DC converter circuit. Physically, it's a coil of wire wound around a ferrite spool, and what you've cracked is just a corner of the flat plate at one end of the spool.

Honestly, missing that piece is unlikely to affect anything. If the coil were broken, the HackRF wouldn't function at all. If the broken corner will come away cleanly you can probably just remove it and leave it off. If it's still partially attached, it may be best not to pull on it. To keep the broken part in place you could drip a spot of liquid cyanoacrlyate glue into the crack and hold it shut till it dries.

If you do want to replace the part it's a straightforward soldering job. The part suggested above would be fine, another option is NRS4018T4R7MDGJ. Anything that's 4x4mm with the same inductance and similar current rating.

HaroGaro1312, 2022-11-17:
Hello

  Oooooh thanks !! I was so freaked out ! That was terrible, thanks very much for your fast answers both of you, it reassures me so much !

  The little part is still attached to the rest, so i push on the side (like on the 2nd picture) and I just have to put a little drop of superglue and that's it ? Cyanoacrylate is superglue right ? (Sorry my English isn't very good)

I will just have a last problem, it's that the battery will still touch the inductor and impeach to put the HackRF with the Portapack in the case so I was wondering if maybe you've got an idea of which battery will be good for the HackRF to replace the original one which is a bit too thick ? I mean do you know which Ampere value is the battery ? (I don't have a multimeter around me) The one I've got have a little PCB attached to it and the values are 3.7V / 2500mAh (see the picture) 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so have you got idea of a battery with the same value but less thick ?

  Thanks again for your answer, I'm glad that seems not as severe as I was thinking at the beginning, and thank you by advance if you know the right battery to use if you don't that's not a problem, anyway thanks again for all you help,

  Cordially, Anthony.

martinling, 2022-11-17:
Yes cyanoacrylate is the type called "super glue" or "crazy glue" in most places.

For the battery issues you'll need to take that up with the manufacturer of your PortaPack. The [original PortaPack design](https://www.sharebrained.com/) doesn't use an internal battery. It's something the clones have added.

HaroGaro1312, 2022-11-17:
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

  Well, it seems to be good, the cyanoacrylate have take in really fast so it was easy, I just had to pushed a bit on the side with a little screwdriver put a bit of superglue with a guitar cord and that was finished in 5min !

  Thank you very much for your answers if I had a problem with this part now I have the reference and a repair technic so thank you !

  If you know the answer to my precedent post, which type of battery choose to replace the original one which is too thick to fit in the case with the Portapack so if someone got an answer, I'll take it !

  Well anyway, thank you again very much for all your help and answers, really thank you very much for all.

  Cordially, Anthony.

mmm545, 2022-11-17:
You're welcome!
You may close this issue unless you need further help!

Closed 2022-11-22.

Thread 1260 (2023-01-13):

hackrf_sweep sometimes doesn't work on Raspberry Pi Zero 2 W

CodingSylvi, 2023-01-13:
### What type of issue is this?

permanent - occurring repeatedly

### What issue are you facing?

After about five to ten times of running the hackrf_sweep function on the Raspberry Pi Zero 2 W, it stops working and outputs:
0 total sweeps completed, 0.00 sweeps/second

My question is, if it's supposed to work on the Raspberry Pi Zero 2 W.
(I have tried the same thing on the Raspberry Pi 4 B, and it doesn't work.)

### What are the steps to reproduce this?

run   $ hackrf_sweep -f 10:6010 -B -w 1000000 -l 16 -g 24 -1    repeatedly

### Can you provide any logs? (output, errors, etc.)

$ uname -a
Linux raspberry pi 5.10.103-v7+ #1529 SMP Tue Mar 8 12:21:37 GMT 2022 armv7l GNU/Linux

$ hackrf_info
hackrf_info version: git-b6acd66c
libhackrf version: git-b6acd66c (0.7)
Found HackRF
Index: 0
Serial number: 00000000000000000f77c60dc279182c3
Board ID Number: 2 (HackRF One)
Firmware Version: git-6f26b74e (API:1.07)
Part ID Number: 0xa000cb3c 0x00544754
Hardware Revision: r7
Hardware appears to have been manufactured by Grat Scott Gadgets.
Hardware supported by installed firmware:
	HackRF One

CodingSylvi, 2023-01-18:
I checked, and I already have the newest `libusb` version installed.
Has somebody already tested `hackrf_sweep` on the relatively new Raspberry Pi Zero 2 W.
Is it possible that the problem is related to the usb connection (speed, supply voltage, ...)
Maybe the problem is my fault:
I am calling `hackrf_sweep` as a subprocess in a python program repeatedly.
$ hackrf_sweep -f 10:6010 -B -w 1000000 -l 16 -g 24 -1

martinling, 2023-01-18:
Running it repeatedly shouldn't be an issue. This is exactly what [QSpectrumAnalyzer](https://github.com/xmikos/qspectrumanalyzer) does behind the scenes, for instance. Could you try running that and see if it works?

USB problems could certainly be involved. A HackRF One is a fairly demanding USB 2.0 device: it draws close to the maximum allowed current, requires high speed operation, can use nearly all the available bandwidth, and wants as little latency as possible. So it can certainly show up problems on platforms with poor USB implementations. Poor quality USB cables are also sometimes a cause - can you try a different one?

A useful test of the USB stack is to just try RX mode with buffer stats enabled:
`hackrf_transfer -r /dev/null -s 10e6 -B`

This should print lines like:
`19.9 MiB / 1.000 sec = 19.9 MiB/second, average power -35.4 dBfs, 5280 bytes free in buffer, 0 overruns, longest 0 bytes`

Then try increasing from the 10Msps sample rate `10e6` and see where you start getting overruns. Many hosts will get some if you go up to 20Msps but lower rates should be OK. However, even if the host is struggling to maintain throughput, this should not cause sweeps to stop completely, they will just take longer. Something else is going wrong there.

Another useful bit of info would be to retrieve the M0 state with `hackrf_debug -S` after a sweep run fails:

This will print something like:
```
M0 state:
Requested mode: 0 (IDLE) [complete]
Active mode: 0 (IDLE)
M0 count: 30046496 bytes
M4 count: 30031872 bytes
Number of shortfalls: 0
Longest shortfall: 0 bytes
Shortfall limit: 0 bytes
Mode change threshold: 30048256 bytes
Next mode: 0 (IDLE)
Error: 0 (NONE)
```

If however the counts are all zeros, that would indicate that the HackRF had been reset while running the sweep, which could be due to not getting enough power from the USB port.

dmaltsiniotis, 2023-01-19:
Running many sweep one-shots (starting and stopping the device in rapid succession) has been known (#916) in previous versions of the firmware/hackrf libs to cause the HackRF One to get into a state where it needs to be reset. This looks awfully familiar to that issue. Also, unless I am mistaken, I think QSpectrumAnalyzer works on the stream of continuous data coming from hackrf_sweep, and not in a loop calling start() and stop() in rapid one-shot successions.

However that issue was resolved with the refactor of how USB transfers are handled with libusb, so unfortunately I'm at a bit of a loss as for additional recommendations beyond those already suggested.

straithe, 2023-04-07:
I'm closing this as there hasn't been a response in over 30 days. Please re-open this issue or open a new one if you still need assistance.

khs4github, 2023-06-04:
My colleague CodingSylvi raised the technical support request "hackrf_sweep sometimes doesn't work on Raspberry Pi Zero 2 W #1260". I should finish the content.

As recommended on January 18th I tested the USB stack by "hackrf_transfer -r /dev/null -s 10e6 -B".
10e06, 11e06, 12e06 and 13e06 work fine without overruns. From 14e06 and above it doesn't work anymore.

Is there a simple way to limit the sampling rate?
Thank you for your support!

martinling, 2023-06-05:
In sweep mode the sampling rate is fixed at 20Msps.

However, during sweep the device is only sampling 1/3 of the time, so the USB data rate in sweep mode is only 6.66Msps. Given that you've tested up to 13Msps successfully with `hackrf_transfer`, I don't think USB throughput capability of the Pi is your problem.

Your problem might be related to the way that the `hackrf_sweep` subprocess is created and used by your Python program. If the output stream is not being read promptly enough, or is directed to a pipe with an insufficient buffer size, then the `hackrf_sweep` process could be blocked in a print call, preventing it from reading further data from the device.

Try simply running your `hackrf_sweep` command in a loop from the shell:

```$ while 1; do hackrf_sweep -f 10:6010 -B -w 1000000 -l 16 -g 24 -1; done```

Do you still see failures then? If not, then the problem is with the Python program.

khs4github, 2023-06-13:
The situation is:
* Raspberry Pi Zero 2W
* Raspberry Pi OS with desktop, May 3rd 2023, 64-bit (6.1)
* Connections:
** microUSB/PWR IN for Power
** microUSB/USB 2.0 OTG: HackRF One with an Adapter to USB A
** MINI HDMI PORT: not used

* WLAN with a fixed IP-Adress
* Putty as Terminal

What happens:
* "hackrf_transfer -r /dev/null -s 10e6 -B" => 0 overruns
* "hackrf_transfer -r /dev/null -s 12e6 -B" => 0 overruns
* "hackrf_transfer -r /dev/null -s 14e6 -B" => overruns!

* "hackrf_info" see file below.
* "hackrf_sweep -f 10:6010 -w 1000000 -l 16 -g 24 -1" for 2...3 times
  => "0 total sweeps completed, 0.00 sweeps/second" see file below.
* "hackrf_debug -S" see file below.

* Using htop: There seems to be enough memory and CPU.

File:
[TerminalRPI_01.txt](https://github.com/greatscottgadgets/hackrf/files/11739402/TerminalRPI_01.txt)

What could my next steps be?
+ Raspberry Pi OS Lite?
+ 64-bit => 32-bit
+ Installing from github "cmake .." brings the following warning:
  CMake Warning (dev) at /usr/share/cmake-3.18/Modules/FindPackageHandleStandardArgs.cmake:273 (message):
  The package name passed to `find_package_handle_standard_args` (LIBUSB)
  does not match the name of the calling package (USB1).  This can lead to
  problems in calling code that expects `find_package` result variables
  (e.g., `_FOUND`) to follow a certain pattern.
  ???
+ I could document the entire installation in detail?
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
khs4github, 2023-08-22:
If I can help in any way, e.g. test with a modified version, please let me know!
In any case, thank you very much!

martinling, 2023-10-27:
Thanks to @ai6aj there is now a proposed fix for this on PR #1366. I don't have an RPi Zero 2 W to test with, so if anyone here is able to test the git branch from #1366 and see if it fixes the issue on that platform, that would be much appreciated.

ai6aj, 2023-10-27:
I'm quite interested to see if this fixes the issue as well.  I don't have a Pi Zero 2W but I developed/tested on a RPi 4 and I'm amazed at how incredibly slow planning is on that platform.  The Zero 2W has a slower processor and is bound to be even worse.

If you use the -W option to store FFTW wisdom, subsequent runs are pretty fast.

khs4github, 2023-10-27:
I will try to run the tests on Raspberry Pi 4B and Raspberry Pi Zero 2W with buster, bullseye and bookworm in the next 2 weeks.

ai6aj, 2023-10-27:
FFTW's documentation suggests using the "estimate" plan if you need a plan to execute quickly.  I just tried **-P estimate** _without_ using wisdom and it starts up quite quickly on the RPi 4.  If the FFT it produces works fast enough on the Pi 2W I suggest making it the default.

khs4github, 2023-10-31:
So far I have assembled the software as follows:
- sudo apt install cmake build-essential pkg-config git
- sudo apt install libusb-1.0-0-dev usbutils libfftw3-3 libfftw3-dev ... J
- sudo apt update
- sudo apt upgrade
- mkdir LPSpec
- cd LPSpec
- git clone http://github.com/mossmann/hackrf.git
- cd hackrf
- git checkout v2023.01.1
- cd host
- mkdir build
- cd build
- cmake ..
- make
- sudo make install
- sudo ldconfig
- python3 --version
- hackrf_info
- hackrf_sweep -f 10:6000 -w 100000 -1
- hackrf_sweep -f 10:6000 -w 100000

What needs to be done to incorporate the changed release?

martinling, 2023-10-31:
I think this should be sufficient:
```
git remote add ai6aj https://github.com/ai6aj/hackrf.git
git fetch ai6aj
git checkout ai6aj_20231023_1366
make
sudo make install
```
Then re-run `hackrf_sweep` to test.

khs4github, 2023-11-02:
**Raspberry PI 4B/4GB/bullseye/64-bit:**
Creating the new version of hackrf_sweep works as described:
- sudo apt install cmake build-essential pkg-config git
- sudo apt install libusb-1.0-0-dev usbutils libfftw3-3 libfftw3-dev ... J
- sudo apt update
- sudo apt upgrade
- mkdir LPSpec
- cd LPSpec
- git clone http://github.com/mossmann/hackrf.git
- cd hackrf
- git checkout v2023.01.1
- git remote add ai6aj https://github.com/ai6aj/hackrf.git
- git fetch ai6aj
- git checkout ai6aj_20231023_1366
- cd host
- mkdir build
- cd build
- cmake ..
- make
- sudo make install
- sudo ldconfig
WiFi was switched off to obtain comparable results, the result seems to be good:
"hackrf_info" is OK.
"hackrf_sweep -f 10:6000 -w 100000 -1" is OK
"hackrf_sweep -f 10:6000 -w 100000" is OK even after more than 10 hours, the memory consumption remains constant (approx. 424M), there is no swapping (0K/100.0M).

**Should certain numbers be determined for comparison ("hackrf_sweep -f ???") or is it enough for hackrf_sweep to run and the result to be OK?**

martinling, 2023-11-02:
That looks like it's fixed! The swept frequency range shouldn't affect this so that test looks sufficient to me.

Thank you @khs4github for your work on testing this, and @ai6aj for the fix.

I'm going to approve PR #1368 now, and once that's merged this issue will be automatically closed.

khs4github, 2023-11-07:
**Raspberry PI Zero 2 W/bullseye/64-bit:**
I have now created and tested the new release on the Raspberry Pi Zero 2 W exactly as described above for the Raspberry Pi 4B. In addition, it makes sense to use a swap file with 2048 MB on the Raspberry Pi Zero 2 W.
WiFi was switched off to obtain comparable results, the result seems to be good:
"hackrf_info" is OK.
"hackrf_sweep -f 10:6000 -w 100000 -1" is OK
"hackrf_sweep -f 10:6000 -w 100000" is OK even after more than 10 hours, the memory consumption remains constant.
On the Raspberry Pi 4B there are approx. 51000 sweeps in 37600 seconds, on the Raspberry Pi Zero 2 W there are approx. 17800 sweeps in 36000 seconds.

On the weak Raspberry Pi Zero 2 W, the 4 cores of the CPU are constantly occupied at approx. 100%, 55%, 25% and 5%.
This means that hackrf_sweep now runs (albeit correspondingly slowly) on the Raspberry Pi Zero 2 W.

When will there be a new release of the software including this fix?
Thank you very much!

perfectglitch, 2023-12-03:
A dirty hack that worked for me on Raspberry 3B with Python (I do this after every time after hackrf_sweep subprocess has finished):

`pip install pyusb`

`
from usb.core import find as finddev
dev = finddev(idVendor=0x1d50, idProduct=0x6089)
dev.reset()
`

Closed 2023-11-02.

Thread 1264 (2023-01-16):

TVS Diode/ Board issue

pat28475, 2023-01-16:
### Have you read the HackRF [troubleshooting documentation](https://hackrf.readthedocs.io/en/latest/troubleshooting.html)?

yes

### What outcome were you hoping for?

Hello,

I recently had an issue with my Hack RF and it seems the center conductor for the coax connector became loose and took the pad off the board with it. During my attempt to re flow the solder, I believe the TVS Diode fell off and I cannot find it. It still receives signal by jumping the trace further up the line, I did not check transmitting.
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

### What outcome actually happened?

I would like some help either replacing the broken and missing diode or some guidance on what to do.

Thank you!

### What operating systems are you seeing the problem on?

Windows 11, various SDR programs

### What is the output of ```hackrf_info```?

N/A

### Are you using any third-party software?

N/A

### Are you using any third-party hardware?

EMI Shield

martinling, 2023-01-16:
The TVS diode is connected between signal and ground, so its absence won't stop the HackRF from working, but it does leave the RF port exposed to ESD damage.

The original part is [Murata LXES15AAA1-100](https://media.digikey.com/pdf/Data%20Sheets/Murata%20PDFs/LXES15AAA1-100.pdf). That part is now obsolete but you can use any similarly specified one. The key requirement is that it should have very low capacitance (the original is 0.05pF), otherwise it will degrade performance at high frequencies.

pat28475, 2023-01-17:
Perfect! Thank you!

pat28475, 2023-01-18:
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

I found this one, just wondering what are your thoughts. Thank you again

https://m.littelfuse.com/~/media/electronics/datasheets/pulseguard_esd_suppressors/littelfuse_pulseguard_pgb1_datasheet.pdf.pdf

martinling, 2023-01-18:
The capacitance on that looks fine. It doesn't supress an ESD spike as much as the original part but should still provide some protection. But this is an area where there are no perfect solutions - there's a limit to how much can be done if you still want to be able to get 6GHz signals through.

pat28475, 2023-01-19:
Okay I will keep looking and make a decision soon. Thank you

straithe, 2023-02-23:
I'm closing this as there hasn't been an update in over 30 days. Please re-open this issue or open a new one if you still need assistance.

Closed 2023-02-23.

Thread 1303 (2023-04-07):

External Crystal

apppie123, 2023-04-07:
### What would you like to know?

I've been having issues with my HackRF device with external 0.1ppm TCXO from amazon.
The HackRF used to work fine to transmit GPS signals, but since a week the GPS receiver is starting to have issues with getting a lock. I have the HackRF powered 24/7 for a month or two now.

This is the crystal I'm using:
https://www.amazon.com/Precision-External-PPM0-1-HackRF-Application/dp/B07NXSFFLB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

Perhaps this one is prone to drift over time? Current temperature in the room is about 10 degree celsius.

I ordered the 0.5ppm from NooElec but I believe that one doesn't work with the more recent HackRF's.
I have not found any other crystals, other than ordering PCB's myself and soldering one together.

Anyone have any ideas? Perhaps suggestions for an OCXO?
https://www.amazon.com/Frequency-Standard-Oscillator-Reference-Constant/dp/B0BQYXYKHJ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

straithe, 2023-04-07:
Please know that some TCXOs do not meet the 3.3 V signal requirement of HackRF One even though they are advertised as working with HackRF. These TCXOs happened to work with older hardware versions of HackRF One, but do not work with the latest revision. I suggest double checking any TCXOs you are looking at to make sure they meet that 3.3 V requirement.

apppie123, 2023-04-07:
I have read that in another issue(I think I went through all of them by now). This first one has been working for weeks without issues, so I don't know if the TCXO is the issue(due to temperature?) or if there is something else. I don't have a freq. counter unfortunately.

It's hard to find a compatible TCXO or OCXO that would not require to order circuitboards.

straithe, 2023-05-04:
Your best way to move forward is to contact the company you purchased your TCXO from.

Closed 2023-05-04.

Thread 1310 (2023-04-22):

My HackRF is receiving a Signal at least 20db less than it Should

erd0spy, 2023-04-22:
### Have you read the HackRF [troubleshooting documentation](https://hackrf.readthedocs.io/en/latest/troubleshooting.html)?

yes

### What outcome were you hoping for?

## Steps to reproduce
1. Used 2 HackRF One devices with the same antenna, same software, same USB port, and at the same time
2. Utilized GQRX (latest version)
3. Conducted an experiment: Attempted to receive any signal

### What outcome actually happened?

I had borrowed a HackRF from my Professor because the signal strength of my HackRF (for both RX and TX) was very low and could not receive almost any signal except FM signals. Although both appeared to be the same, in my measurements with GQRX and other software, I noticed that my own HackRF received at least 20dB less signal strength than my Professor's HackRF. In my tests with a signal analyzer in the laboratory, I could hardly see the signal I was sending.

HackRF Images:

The one belonging to my professor was on the left, and mine was on the right

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

I tested with the same antenna, same USB cable, same USB port, and at the same time.

## GQRX Images:

My Professor's HackRF:

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

My HackRF:

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

## PCB of My HackRF:

Front:
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

Back:
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

### What operating systems are you seeing the problem on?

Ubuntu 20.04

### What is the output of ```hackrf_info```?

```bash
$ hackrf_info
hackrf_info version: git-ebe1ca00
libhackrf version: git-ebe1ca00 (0.8)
Found HackRF
Index: 0
Serial number: 0000000000000000a06063c82547b45f
Board ID Number: 2 (HackRF One)
Firmware Version: 2022.09.1 (API:1.06)
Part ID Number: 0xa000cb3c 0x0057435c
Hardware Revision: older than r6
Hardware supported by installed firmware:
    HackRF One
```

### Are you using any third-party software?

Gnu Radio, GQRX

### Are you using any third-party hardware?

No

martinling, 2023-04-22:
The screenshots don't show your gain settings. Were you using the same settings on the "Input controls" tab in both cases? I think GQRX may save these separately for different units.

erd0spy, 2023-04-22:
>

Yes, I am using same gain settings.

erd0spy, 2023-04-22:
> The screenshots don't show your gain settings. Were you using the same settings on the "Input controls" tab in both cases? I think GQRX may save these separately for different units.

Yes, I am using same gain settings.

erd0spy, 2023-04-22:
When I transmitted a signal using hackrf_transfer with my own HackRF, I was unable to see any results on the signal analyzer.

erd0spy, 2023-04-22:
I'm certain that something is malfunctioning for both TX and RX, even though the firmware and device seem to be functioning properly.

martinling, 2023-04-22:
I noticed from your photos that the CLKOUT port is damaged, as if perhaps the unit has been dropped and landed on it.

If the board has been exposed to a large shock then there are a lot of possible ways it may have been damaged, e.g. cracked capacitors or solder joints, which might explain the performance issues.

Are you testing with or without the RF amplifiers enabled? Those are fairly easy to replace, but damage elsewhere may be harder to track down.

erd0spy, 2023-04-23:
LNA and VGA Gain seem to work. Although it does not allow me to receive more signals, it increases the value of the current signal. When I test it in C programs, the value HACKRF_SUCCESS is returned for the lna_gain, vga_gain, amp_enable, and antenna_enable functions (although I'm not sure this can be used for hardware failure testing). Unfortunately, it may have been damaged by hardware damage.

straithe, 2023-05-26:
I am closing this issue as hardware damage, as suggested by @martinling, is likely the cause of the issues you are seeing.

Closed 2023-05-26.

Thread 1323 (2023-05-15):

Broken timing in hackrf_transfer on OpenBSD, due to SIGALRM being delivered to transfer thread

bsdmp, 2023-05-15:
### What type of issue is this?

permanent - occurring repeatedly

### What issue are you facing?

while doing simple `hackrf_transfer -r /dev/null` I face following error

`Couldn't transfer any bytes for one second.`

full log:

```
call hackrf_set_sample_rate(10000000 Hz/10.000 MHz)
call hackrf_set_hw_sync_mode(0)
call hackrf_set_freq(900000000 Hz/900.000 MHz)
Stop with Ctrl-C
 7.9 MiB / 1.006 sec =  7.8 MiB/second, average power -28.5 dBfs
 7.6 MiB / 1.000 sec =  7.6 MiB/second, average power -28.4 dBfs
 7.6 MiB / 2.000 sec =  3.8 MiB/second, average power -28.5 dBfs
 0.0 MiB / 1.000 sec =  0.0 MiB/second, average power -nan dBfs

Couldn't transfer any bytes for one second.

Exiting... hackrf_is_streaming() result: streaming stopped (-1003)
Total time: 5.00616 s
hackrf_stop_rx() done
hackrf_close() done
hackrf_exit() done
fclose() done
exit
```

`v2021.03.1` works fine though, I have done a bisect and it came up to the following commit:

```
a09e9a20ed42567b1fe979ab4db12f9f2590b2a4 is the first bad commit
commit a09e9a20ed42567b1fe979ab4db12f9f2590b2a4
Author: Martin Ling <martin-git@earth.li>
Date:   Fri Aug 5 15:43:25 2022 +0100

    Overhaul timing in hackrf_transfer.

    Rather than using sleep() for 1s at a time, set up an interval timer
    that will fire once per second, and wait in the main loop for either
    this or some other event.

    On POSIX, the timing is set up with setitimer(), which generates a
    SIGALRM signal each time the timer fires. The main loop runs pause() to
    wait for any signal.

    On Windows, the timing is set up using CreateWaitableTimer, which
    provides an event handle that is set each time the timer fires. The main
    loop runs WaitForMultipleObjects() to wait on this and an interrupt
    event.

    The TX and RX callbacks can now stop the main loop immediately when they
    stop streaming. This fixes #1019.

 host/hackrf-tools/src/hackrf_transfer.c | 71 ++++++++++++++++++++++++++++++---
```

### What are the steps to reproduce this?

run `hackrf_transfer -r /dev/null` on `OpenBSD 7.3 GENERIC.MP#1175 amd64` (openbsd current)

### Can you provide any logs? (output, errors, etc.)

```
# hackrf_info
hackrf_info version: 2023.01.1
libhackrf version: 2023.01.1 (0.8)
Found HackRF
Index: 0
Serial number: XXXX
Board ID Number: 2 (HackRF One)
Firmware Version: 2023.01.1 (API:1.07)
Part ID Number: XXX XXX
Hardware Revision: older than r6
Hardware supported by installed firmware:
    HackRF One
```

martinling, 2023-05-15:
Thanks for taking the time to bisect this to my commit.

OpenBSD is not a platform we actively develop and test on, and I don't personally have a system available to reproduce this at the moment, so all I have to go on for the moment is the symptoms in your logs.

From those symptoms, I'm not sure what's going wrong. In theory, the timing code introduced in this commit should work on any POSIX-compatible system, and indeed I think this particular API originated in BSD in the first place.

Something fishy is definitely happening though, because after setting up the interval timer and `SIGALRM`, the first two messages happen on time, but the third is a whole second late:

```
 7.9 MiB / 1.006 sec
 7.6 MiB / 1.000 sec
 7.6 MiB / 2.000 sec
```

If the OS is implementing the timer and signals correctly I don't understand how that can happen, given what `hackrf_transfer` is doing at that point. Since you're not running with `-B` to enable `display_stats`, there's hardly anything happening in the main loop - all it does is call `pause` to wait for the signal, `gettimeofday` to see how much time has passed, and then `fprintf` to write the message. The values in the message all come from global variables.

So either the signal is arriving a whole second late, or the main thread is getting blocked for a whole second. But I don't see what could be blocking it. The USB I/O is all happening in a separate thread.

I wonder if the whole process is hanging for a second, due to some USB I/O issue perhaps? It may be that this commit merely makes an existing problem now cause an error, when it previously didn't.

martinling, 2023-05-21:
Ah, that makes sense, and I think your testing with that change confirms that must be what's going on - the signal is sometimes delivered to the transfer thread rather than the main thread.

I'm not sure modifying libhackrf like that is the right fix, though. It works for the specific case of `SIGALRM` as used by `hackrf_transfer`, but other programs may run into this issue with other signals.

I think ideally, libraries should not be messing with decisions about signals. As a process-wide issue, that's normally a matter for the author of the overall program. However, since libhackrf creates its own threads behind the scenes, I guess we have to make the decisions about how we configure those threads.

A better solution might be for libhackrf to mask *all* signals for its internal threads, which should ensure they always stay out of the way of whatever signal handling the program is doing. There may be some downside to this I haven't thought of, though.

martinling, 2023-05-22:
That looks reasonable to me. Could you submit it as a pull request please?

Closed 2023-09-13.

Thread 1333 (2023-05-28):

Receiving and transmitting problem.

ArekPL77, 2023-05-28:
### Have you read the HackRF [troubleshooting documentation](https://hackrf.readthedocs.io/en/latest/troubleshooting.html)?

no

### What outcome were you hoping for?

N/A

### What outcome actually happened?

I have a problem that I cannot solve. Please advise.
I bought my first HackRf device a few years ago, it worked flawlessly until a path on the PCB from the antenna socket broke. I added a piece of wire between the antenna socket and the resistor on the PCB, but the device no longer worked as before. It transmits and receives with very low power. I have now bought a new device - and here's a surprise it transmits and receives just as poorly as the old damaged device.

I understand that a component in the old one was damaged, but why does the new one have the same problem? Please advise why this is so?

What component was damaged in the old device? Can I replace it myself?

I am attaching pictures showing the remote control signal reception from the RTL-SDR and the damaged and new HackRF to show how poorly they receive signals. At HackRF I marked the signals with a circle, you can hardly see them.

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

### What operating systems are you seeing the problem on?

Windows 10

### What is the output of ```hackrf_info```?

N/A

### Are you using any third-party software?

SDRSharp

### Are you using any third-party hardware?

original antenna

straithe, 2023-05-28:
Please add a picture of your board to this issue.

chris451gh, 2023-07-10:
Perform the following test:
Tune to a strong signal. Enable 'amp'. If the signal does not increase, the mga amp is blown, and with that it takes out two of them also the output buffer amp, which cuts down the output power. This is caused by ESD or a voltage more than 4 volts on the antenna. There is a tvs diode on the input but it does not limit the voltage enough. Replace the buffer amps MGA81563.
To prevent these from blowing out only operate with a limiter and dc block or a band pass filter, high pass filter or dc block.  I have 2 portapack mayhem's here and have changed these amps out twice on one unit and once on the other. Then, your amp(1) amp(0) setting will work and the signal will increase 12db when the amp is enabled. The reason TX is weak with a blown amp is it puts dc current on the RF switch which prevents it from working correctly. TX out will be down 20-30db and RX will be down 10-12db(with amp).
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

ArekPL77, 2023-09-25:
Hi. I am sorry that I write back so late, but I had a contract of several months and I was not at home.
Thank you for your interest in the problem and reply to my post.
Could you get to me how to turn on 'AMP'?

straithe, 2023-09-25:
How you turn on the amo depends on the software you are using with your HackRF. Please consult that manual for the software.

chris451gh, 2023-09-25:
OK for most versions of hackrf mayhem, turn it on with a click of selector button,
for the H2. H1 I think has a separate button for power. If you see LED but no display play with R L U D Center while turning it on that enab les the display.
From on hit center and click receive, then select audio, pick Audio RX.
It says NFM 161.975 32 32 ____signal bar___ 84
Or whatever freq it was last on, or default freq.
Highlight the first 32.  Below appears amp 0, use the knob to set this to 1.
If the amp is working the waterfall will brighten up, and signal to noise on a known signal that its tuned to will go up 14 db. If the amp is no good it will drop.
if something else is also bad there will be no signals. In the US it is convenient to tune in national weather service 162.4-162.55, and you can tune to 500.000 you will see a strong signal with lots of sidebands, rotate amp on it should turn red over much of the center.
For transmit, tune to a frequency

chris451gh, 2023-09-25:
for transmit: turn on the Hackrf. Click to pass the logo page.
Here make note of the software version at the bottom and write down.
Select utilities. Select signal generator.
Set up a receiver on a test channel such as 435mhz.
set the transmit frequency there, I used 499.9mhz. Using touch screen set start
Adjust gain until the signal is weak to moderate on the receiver 0-45db
Now highlight amp and rotate knob, 0 or 1 for off and on.
It should be about 14db stronger with amp set to 1. If the output amp is good then
from 3 feet away the signal will be full scale and should be even stronger with amp on.
I got full scale on an Icom R20 in NFM mode 3 feet way with gain 0 amp 0.
It gets stronger by 14db(more quieting) with amp on.
If the amp is bad the signal may be -70dbm, very weak and not too good with gain up.
If the signal gets stronger as gain goes up the variable gain amp and the switch are good, but the swich chip does not work right with a blown amp, becuase the blown chip obstructs the signal from getting through the switch, I think because its putting load on the input output of the switch chip and it doesnt work the way it should when that happens.
The fix is to replace the surface mount amp chips. I never had to change the switch chip nor the variable gain amps. Just the MGA815 amps. I got a strip of 10 of them from Ebay. There is an equivalent chip by hittite that would work as a replacement. I have not tested that. I run a limiter with most antennas so 2 units continue to work fine with that sma limiter (mini-circuits). That keeps voltage and too much power off of the input and output. I think its ESD or ground loops that are enough to blow the preamp chips. I have had to replace the L band chips in Icom receivers because they got blown too.

straithe, 2023-09-25:
@ArekPL77 please note that @chris451gh's advice only works if you are using a Portapack and the Mayhem firmware. Are you using a Portapack?

ArekPL77, 2023-09-28:
I did as you advised.
I attach links to the movies I recorded.
    http://hostuje.net/file.php?id=351938364179ff8088f416adfe0916e7
    http://hostuje.net/file.php?id=0d8a052e8a0b7de6e3fcfdebb2ff4914
Could you judge if I have done your instructions well?

When enabling AMP in both cases, the signal clearly weakened. So it seems to me that MGA81563 elements are damaged.
I ordered them from Aliexpress, they should come in about 3 weeks. Should only these elements replace?

straithe, 2023-12-11:
It does seem as though your device has a hardware issue. Please contact the person you bought your HackRF + Portapack from for further support.

Closed 2024-02-06.

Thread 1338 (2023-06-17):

Receiving and transmitting problem.

ArekPL77, 2023-06-17:
### Have you read the HackRF [troubleshooting documentation](https://hackrf.readthedocs.io/en/latest/troubleshooting.html)?

yes

### What outcome were you hoping for?

N/A

### What outcome actually happened?

I have a problem that I cannot solve. Please advise.
I bought my first HackRf device a few years ago, it worked flawlessly until a path on the PCB from the antenna socket broke. I added a piece of wire between the antenna socket and the resistor on the PCB, but the device no longer worked as before. It transmits and receives with very low power. I have now bought a new device - and here's a surprise it transmits and receives just as poorly as the old damaged device.

I understand that a component in the old one was damaged, but why does the new one have the same problem? Please advise why this is so?

What component was damaged in the old device? Can I replace it myself?

I am attaching pictures showing the remote control signal reception from the RTL-SDR and the damaged and new HackRF to show how poorly they receive signals. At HackRF I marked the signals with a circle, you can hardly see them.

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

### What operating systems are you seeing the problem on?

Windows 10

### What is the output of ```hackrf_info```?

N/A

### Are you using any third-party software?

SDRSharp

### Are you using any third-party hardware?

original antenna

straithe, 2023-09-13:
I am closing this issue as a duplicate to #1333

Closed 2023-09-13.

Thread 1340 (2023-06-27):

Phase sync coherence between two Hackrf One

ViniFS, 2023-06-27:
### Have you read the HackRF [troubleshooting documentation](https://hackrf.readthedocs.io/en/latest/troubleshooting.html)?

yes

### What outcome were you hoping for?

I was hoping for a time sampling GUI showing both HackRF One as RX sampling the same CW signal with synchronized samples of both IQs. A phase difference is OK but with constant jitter. It could be done by SMA clock or headers hardware triggering synchronization.

### What outcome actually happened?

When seeing the data of both HackRF One, one was being used as trigger so it's IQ was fixed on the same position in the visualization window, but the other one kept moving uncoordinatedly through the time domain. I have tried using on HackRF One to trigger the other one on both SMA connectors and also on headers pointed as hardware triggering, and I have tried also using an external square wave genrrator to trigger both of them. All these ways showed the same results.

### What operating systems are you seeing the problem on?

Linux 22.04

### What is the output of ```hackrf_info```?

N/A

### Are you using any third-party software?

GNU Radio

### Are you using any third-party hardware?

N/A

straithe, 2023-10-19:
Thank you for opening this issue. Unfortunately, I'm not sure I understand what you need assistance with. I feel you may be trying to get help with GNU Radio, is that correct?

888XFX888, 2023-11-21:
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

hello  I also encountered this issue, but I used the method you mentioned to synchronize both hardware sampling and clock. However, after collecting the signal through gnuradio, I calculated the phase difference between the two hackrfs. This parameter is not stable and fluctuates in the range of - pi to pi. I am not sure what is causing this.

888XFX888, 2023-11-21:
I used a **2.4GHz RF signal source  connect to the RF input ports of two hackrfs after passing through the power divider.**

At the same time, I also input the **same 10Mhz clock signal** on the clock input port. as well as  I **used the code**  `hackrf_ Transfer - r 1- d 600463dc2b426ec7- H 1 | hackrf_ Transfer - r 2- d 600463dc30a245c7- H 1 `Enable synchronous 。

Here is my GRC flowchart

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

But the phase I collected in this way is not stable,It will have a slow change。

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

 and **I want to know what is causing it**. Is there any other reason that can cause **unstable phase difference**

888XFX888, 2023-11-21:
This is my graduate project, and I really need your help. Thank you very much

888XFX888, 2023-11-21:
This is my graduate project, and I really need your help. Thank you very much

martinling, 2023-11-21:
Hi @888XFX888,

The OsmoSDR source block is misleading you a bit here. It can be used with a lot of different devices but does not support all features on all of them.  Although it has options for clock source and time source, those settings do not do anything for HackRF. These options are currently only implemented in OsmoSDR for the USRP and BladeRF.

The external clock input is used automatically on HackRF if it is detected, so you do not need any setting in the GNU Radio source block to select this. However you should check that your clock input is suitable and that it is being detected. You can check this on the command line with `hackrf_clock -i`, which should display either `CLKIN status: clock signal detected` or `CLKIN status: no clock signal detected`. The clock signal should normally be a 3.3V square wave, though a sine wave is also OK. If the peak-to-peak voltage of the clock signal is less than 3V, whether it will work depends on which revision of the hardware you have.

Getting the two HackRFs to start sampling at exactly the same time (within 1 sample period) is not currently possible using GNU Radio. The simplest solution is to use `hackrf_transfer` with the `-H` option to capture the samples instead.  You can use the `-r <filename>` option on each `hackrf_transfer` command to tell it where to save the samples, and then use two `File Source` blocks in your GNU Radio flowgraph to read those samples, instead of using the OsmoSDR source. If you need to process in realtime, you could pipe each `hackrf_transfer` process to a TCP socket using `netcat` or a similar program, and use two `TCP Source` blocks in the flowgraph to receive the samples. Or, you could modify the [OsmoSDR code](https://github.com/osmocom/gr-osmosdr/blob/master/lib/hackrf/hackrf_source_c.cc) to make it support hardware sync, using the `hackrf_set_hw_sync_mode` function.

schneider42, 2023-11-21:
Is the hardware sync actually allowing for phase coherence between two HackRFs? I think that is what the OP wants to achieve. Start of sampling withing a certain time period is not good enough for them. They want a stable phase between the two devices between two runs.

martinling, 2023-11-22:
Hi @888XFX888,

That's a good trick you've found which I hadn't thought of. Because OsmoSDR never changes the hardware sync mode at all, it does indeed work to use `hackrf_transfer` with the `-H` option to enable hardware sync before starting GNU Radio.

Your time sink plot comes out wrong because the output format of `hackrf_transfer` is not floating point but rather signed 8-bit values directly from the ADC. You can use an `IChar to Complex` block with a scale factor of 127 to convert the data:

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

Could you please post the output of `hackrf_info` with both your HackRFs connected?

888XFX888, 2023-11-23:
Hi，@martinling.

Here is my hackrf_info :
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

martinling, 2023-11-23:
Hi @888XFX888,

Thanks for the info.

I wanted to see what hardware you were using, because the phase drift you see suggests that the clock synchronization is not working properly, and the possible causes for that depend on the hardware revision.

However, your boards were not manufactured by Great Scott Gadgets. So I cannot be sure of all the hardware details, and the boards have not been through our factory testing. There may be some hardware problem preventing the clock synchronization from working, but you would need to ask for support for that from the manufacturer or seller you bought them from.

It may be helpful for me to explain some background here about the external clock support.

In HackRF One revisions r1 to r8, the clock generator for the board is an Si5351C, which has built-in support for an external clock input. During the global chip shortage in 2020 onwards, the Si5351C part was not available, and we had to redesign the board to use the Si5351A instead, which does not have this feature. We needed to add some additional circuitry to enable support for an external clock input when using the Si5351A. This was done in the r9 version of the hardware design.

During the shortage, at least one manufacturer produced clones of the HackRF One that simply swapped the Si5351C for the Si5351A, without adding the additional circuitry. These clones did not work with an external clock at all, but were sold with the CLKIN port anyway. So in general I do not trust other manufacturers to ensure that this feature works properly.

Your boards identify as the r9 version, which means that in theory they should have the extra circuitry. And you say that the clock input is detected with `hackrf_clock`. But because the boards were not made by GSG, I cannot be sure that all the hardware is correct. The design may have been modified, or necessary components could have been substituted or left out.

888XFX888, 2023-12-07:
Hi，@martinling

It's been a while, and I finally found the problem with the unstable phase difference.

After replacing the received data cable, the phase difference between the two hackrfs received data became very stable.

I think it may be a problem with the data cable that causes unstable or unsynchronized data transmission, and these unstable or unsynchronized data can lead to problems with the final calculated phase difference.

So，There's no problem with Si5351A.

Thank you very much for your previous answer。

martinling, 2023-12-07:
Ah! That would make sense. If the USB link were unreliable due to a poor cable, then that would cause retransmissions to be needed, but at some point the buffer on the device will overflow and samples would have to be dropped, which would cause the two signals to get of sync.

This could have been detected using `hackrf_debug -S`  to check the shortfall counts, but I didn't think of it.

It seems that it would be useful to have a checklist for synchronization issues in the documentation. I'll open an issue for that.

martinling, 2023-12-07:
I've now put together a checklist in issue #1386 for troubleshooting synchronisation between multiple HackRFs, including all the points discussed here. At some point this should be transferred into the [HackRF documentation](https://hackrf.readthedocs.io/en/latest/).

I'm going to close this issue now since @888XFX888 has resolved their problem and there hasn't been an update from @ViniFS since their original post. If anyone's still having trouble after going through the checklist, please open a new issue and we'll do our best to help.

AlMasz2837, 2024-03-07:
hi, is it possible to set the frequency of a rectangular pulse or submit it to hackrf.  frequency less than 10 MHz, for example 1 kHz, with an amplitude of 3.3 V?

AlMasz2837, 2024-03-07:
hi, is it possible to set the frequency of a rectangular pulse or submit it to hackrf. frequency less than 10 MHz, for example 1 kHz, with an amplitude of 3.3 V?

Saiqin, 2024-07-19:
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

Hi all i do the same synchronization like above illustration, why i still have the delay for the two device.
thanks.

martinling, 2024-07-19:
@Saiqin please go through the checklist in #1386, and then open your own issue if you're still having problems.

Closed 2023-12-07.

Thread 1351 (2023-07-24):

TCXO Not Detected (Firmware Version:2023.01.01)

muuzoo, 2023-07-24:
### What type of issue is this?

transient - occurring only once

### What issue are you facing?

I have two Hackrf One devices. The TCXO module detected on one device but not the other.

Information about the working device with TCXO:

```
hackrf_info
hackrf_info version: git-13dacd81
libhackrf version: git-13dacd81 (0.8)
Found HackRF
Index: 0
Serial number: 0000000000000000579c61dc232a609f
Board ID Number: 2 (HackRF One)
Firmware Version: local-57ed3eb (API:1.04)
Part ID Number: 0xa000cb3c 0x005d4766

hackrf_debug --si5351c -n 0 -r
[  0] -> 0x01

hackrf_clock -a
MS0:
	clock control = Up, Frac Mode, PLL src A, MULTISYNTH SELF, 8 mA
	p1 = 4608
	p2 = 0
	p3 = 0
	output divider = 2
MS1:
	clock control = Up, Int Mode, PLL src A, Inverted, MULTISYNTH 0 4, 2 mA
	p1 = 4608
	p2 = 0
	p3 = 1
	Output (800Mhz PLL): 20.0000000000 Mhz
	output divider = 1
MS2:
	clock control = Up, Int Mode, PLL src A, MULTISYNTH 0 4, 2 mA
	p1 = 4608
	p2 = 0
	p3 = 1
	Output (800Mhz PLL): 20.0000000000 Mhz
	output divider = 1
MS3:
	clock control = Down, Int Mode, PLL src A, XTAL, 2 mA
	p1 = 0
	p2 = 0
	p3 = 0
	output divider = 1
MS4:
	clock control = Up, Int Mode, PLL src A, Inverted, MULTISYNTH SELF, 6 mA
	p1 = 2048
	p2 = 0
	p3 = 1
	Output (800Mhz PLL): 40.0000000000 Mhz
	output divider = 1
MS5:
	clock control = Up, Int Mode, PLL src A, MULTISYNTH SELF, 4 mA
	p1 = 2048
	p2 = 0
	p3 = 1
	Output (800Mhz PLL): 40.0000000000 Mhz
MS6:
	clock control = Down, Int Mode, PLL src A, XTAL, 2 mA
	p1_int = 0
	output divider = 1
MS7:
	clock control = Down, Int Mode, PLL src A, XTAL, 2 mA
	p1_int = 0
	output divider = 1
```

Information about the  failed device:

```
hackrf_info
hackrf_info version: git-13dacd81
libhackrf version: git-13dacd81 (0.8)
Found HackRF
Index: 0
Serial number: 0000000000000000f75461dc278e3fc3
Board ID Number: 4 (HackRF One)
Firmware Version: 2023.01.1 (API:1.07)
Part ID Number: 0xa000cb3c 0x005d435d
Hardware Revision: r9
Hardware does not appear to have been manufactured by Great Scott Gadgets.
Hardware supported by installed firmware:
    HackRF One

hackrf_debug --si5351c -n 0 -r
[  0] -> 0x51

hackrf_clock -a
MS0:
	clock control = Up, Int Mode, PLL src A, MULTISYNTH SELF, 6 mA
	p1 = 2048
	p2 = 0
	p3 = 1
	Output (800Mhz PLL): 40.0000000000 Mhz
	output divider = 1
MS1:
	clock control = Up, Frac Mode, PLL src A, MULTISYNTH SELF, 4 mA
	p1 = 4608
	p2 = 0
	p3 = 0
	output divider = 1
MS2:
	clock control = Down, Int Mode, PLL src A, XTAL, 2 mA
	p1 = 0
	p2 = 0
	p3 = 0
	output divider = 1
MS3:
	clock control = Down, Frac Mode, PLL src A, XTAL, 2 mA
	p1 = 0
	p2 = 0
	p3 = 0
	output divider = 1
MS4:
	clock control = Down, Frac Mode, PLL src A, XTAL, 2 mA
	p1 = 0
	p2 = 0
	p3 = 0
	output divider = 1
MS5:
	clock control = Down, Frac Mode, PLL src A, XTAL, 2 mA
	p1 = 0
	p2 = 0
	p3 = 0
	output divider = 1
MS6:
	clock control = Down, Int Mode, PLL src A, XTAL, 2 mA
	p1_int = 0
	output divider = 1
MS7:
	clock control = Down, Int Mode, PLL src A, XTAL, 2 mA
	p1_int = 0
	output divider = 1
```

### What are the steps to reproduce this?

Just install external TCXO module  (ex: Tiny TCXO 0.5 PPM) on connector P22

### Can you provide any logs? (output, errors, etc.)

_No response_

Caian, 2023-08-01:
I'm also experiencing this issue with a newly bought TXCO and HackRF One (Same board ID number 4 and FW)

dmaltsiniotis, 2023-08-01:
What TCXO is in use here? It's been found recently that some popular TCXO's on the market do not conform to the the proper voltage specifications the HackRF One requires. Previous board revisions have been more forgiving about misbehaving TCXO's but more recent revisions require TCXO's to perform within spec.

Caian, 2023-08-01:
> What TCXO is in use here? It's been found recently that some popular TCXO's on the market do not conform to the the proper voltage specifications the HackRF One requires. Previous board revisions have been more forgiving about misbehaving TCXO's but more recent revisions require TCXO's to perform within spec.

It's a generic TCXO that the seller sent with HackRF. I'll see if I can get better one.

muuzoo, 2023-08-02:
I tried two different TCXOs on r9 board and it didn't work. I also have Portapack H2 and the TCXO on it didn't work either with r9 board.

Here is the image of TCXOs:

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

straithe, 2023-08-24:
Do you have purchasing links to the TCXOs? I'll need to see specs for them. You'll want to make sure that they are 3.3 V.

sreevaishnav-git, 2023-08-24:
@straithe both the TCXO's OP posted are rated for 3.3V. I am also experiencing the same problem.

sreevaishnav-git, 2023-08-24:
@straithe I'm also experiencing the same issue. I have a tiny TCXO (left blue one on the above pic). [Link](https://robosavvy.co.uk/hackrf-one-tiny-tcxo-10mhz-0-5ppm-tcxo-module.html)

jolyfra, 2023-08-26:
I see the same behavior with my v9 in 2023.01.1 but there is a mismatch between hackrf_clock -i => Ok and hackrf_debug --si5351c -n 0 -r => Ko

$ hackrf_clock -i
CLKIN status: clock signal detected

$ hackrf_debug --si5351c -n 0 -r
[  0] -> 0x51

Is there any other way to verify TCXO detection?

It is stated in the HackRF release note that on v9 the Si5351C has been replaced by a Si5351A.
Does the current firmware really take this into account?

https://hackrf.readthedocs.io/en/latest/list_of_hardware_revisions.html
https://www.skyworksinc.com/en/Products/Timing/CMOS-Clock-Generators

straithe, 2023-09-13:
> @straithe I'm also experiencing the same issue. I have a tiny TCXO (left blue one on the above pic). [Link](https://robosavvy.co.uk/hackrf-one-tiny-tcxo-10mhz-0-5ppm-tcxo-module.html)

I'm not seeing whether this TCXO is 3.3 V. Can you confirm with the reseller?

straithe, 2023-09-13:
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

There are some TCXO modules out there which are not compatible with the R9 hardware since they do not output the necessary voltage. We've always specified that a 3.3.V signal is required. Some modules were apparently being sold that didn't provide enough voltage, yet worked by chance with earlier HackRF One revisions.

straithe, 2023-09-13:
@muuzoo have you been able to find a TCXO with 3.3 V?

Caian, 2023-09-15:
> Do you have purchasing links to the TCXOs? I'll need to see specs for them. You'll want to make sure that they are 3.3 V.

I bough it in a bundle with HackRF https://www.aliexpress.com/item/32972753170.html

straithe, 2023-09-15:
> > Do you have purchasing links to the TCXOs? I'll need to see specs for them. You'll want to make sure that they are 3.3 V.
>
> I bough it in a bundle with HackRF https://www.aliexpress.com/item/32972753170.html

Please contact that seller to verify that the TCXO is 3.3 V.

sizzlik, 2023-09-27:
on my devices i noticed that none of the small TCXO like the nooelec work on R9 clones, no matter wich seller, but the bulky silver ones do.

straithe, 2023-10-11:
I am closing this issue as there has not been a response from the original poster in over a month. If you are not the original poster and still need assistance, please open a new issue.

Closed 2023-10-11.

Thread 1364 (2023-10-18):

Which MOSFETs and high-pass filters are used in HackRF?

surpscare, 2023-10-18:
I've got my RX amplifier additional transistor (Q1) fried, so once I enable the AMP tick in the receiver, the sensitivity drops significantly, and the driving MOSFET begins to heat up so much that it starts producing a light smoke. The MGA-81563 itself is still intact though, and it does not make any heat, but the absence of additional power from the transistor makes it closely unable to receive something at the 5G band from a distance of more than 10 centimeters away. Which SMD transistor can be used for replacement?
Also, for some reason, the Highpass SAW filter broke down, despite that all other elements in the chain including SKY13350's are okay, and the device got nearly blind to anything above 2740MHz and also no TX output at all. I had to short-circuit it to regain the ability to RX/TX in the microwave band, but now the mirror signals from the lower bands are present, so an external filter must be used to eliminate them. Which SAW filter can be used for a replacement?

martinling, 2023-10-18:
The original part for Q1 is Yangzhou Yangjie YJL2301C. Many similar transistors could also be used. The DC supply current that it needs to carry to the MGA-81563 is at most around 50mA, but allow plenty of headroom on the current rating.

The original part for the highpass filter U8 is TDK DEA162400HT-8004B1. This is out of production, but there are similar types available that could be substituted, such as DEA162400HT-8053A1.

Note that the full BOM can be found in the [release packages](https://github.com/greatscottgadgets/hackrf/releases) from this repository, in `doc/hardware/hackrf-one-bom.csv`. Part numbers are also included in the KiCAD schematic files.

Closed 2023-10-23.

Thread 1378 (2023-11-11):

Correct Driver for SDR# on Windows 10?

AlexLandherr, 2023-11-11:
### What would you like to know?

I’m in the process of setting up my HackRF One for Windows 10 with SDR#, WXtoImg and Orbitron.

My SDR# version is `v1.0.0.1361`; which is the version that worked with the “VB-Cable” audio driver for piping audio from SDR# to WXtoImg.

I think I have the right driver for the HackRF One based on that SDR# is receiving data and the FFT and waterfall diagrams are updating.

What worries me is the indicator lights on the HackRF One seen below:
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

Does the indicator lights seem okay to someone more experienced?

And what Zadig shows me:
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

I’m only using it for reception of APT signals (137 MHz).

My antenna is the “V-dipole” kit from RTL-SDR.

martinling, 2023-11-11:
You have 3.3V (green), 1.8V (yellow) and RF (red) LEDs lit indicating that the three power supplies are on, you have the USB (green) LED indicating that it's connected to the host, and you have the RX (yellow) LED indicating that it's in receive mode. That all looks correct.

If you press the stop button in SDR# then you should see the RX LED go out. If you transmit then the TX LED (red) will come on. Aside from that you should not normally see the others change.

However, I think you may have missed a little assembly detail. If you find the original plastic case that came with your HackRF One, inside it will be a transparent plastic piece that goes over the LEDs. You can take that out and put it in the aluminium case - there is a recess in the end panel that it fits into. It's not essential, but it helps prevent the light from the LEDs leaking over to the adjacent holes, which makes it clearer which are lit and which are not.

The Zadig screenshot looks fine, but note that there should be no need to use Zadig at all. Any instructions suggesting you need to use it are long out of date. Since 2016 the firmware includes a WCID descriptor which tells Windows to use the WinUSB driver, so everything is automatic. This is indicated by the green tick and WINUSB text in the Zadig screenshot.

AlexLandherr, 2023-11-11:
Ok, thanks!

I tried for almost a week to find anything current for 2023 or so. Did not find much.

I do have a few follow-up questions if that's okay:

1. Is there any modern way for me to connect SDR# with Orbitron so that SDR# can receive Doppler corrections?
For some older versions of SDR# there's plenty of instructions that use a plugin called "SatelliteTracker2" for which I have the files. I have no idea if they work with modern SDR# releases.

2. Due to the layout of my house I have to use an SMA cable that is a few meters long (that is two connected ones from separate RTL-SDR V-dipole antenna kits).
This makes the signal received by HackRF look somewhat weak (poor SNR I think is the right term).
Other than shortening the SMA cable length what can I do to improve the SNR situation?

Closed 2023-11-18.

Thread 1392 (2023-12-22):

HackRF One: Replace micro-USB with USB type C

raleighlittles, 2023-12-22:
### What feature would you like to see and why?

Can someone update the HackRF One to use a USB-c connector instead of a microUSB? The pinout and everything else can stay the same (no interface updates, etc), I just need it to have the USB-c connector.

Thanks for your consideration.

M0rn1ng574r, 2023-12-25:
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

It's a very good idea, I thought the same thing, technically it's possible for charging, but wouldn't there be a problem for data transmission?

M0rn1ng574r, 2023-12-25:
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

It's a very good idea, I thought the same thing, technically it's possible for charging, but wouldn't there be a problem for data transmission?

raleighlittles, 2023-12-25:
No, there shouldn't be a problem, USB-c is backwards compatible with the USB 2.0 interface.

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

You would just need to remove the micro USB connector, replace it with a USB-c one, and then reroute the 4 standard USB pins: VBUS, GND, D+ and D-. The other pins can just be set to low (I think, not 100% sure, but they _can_ be unused).

> It's a very good idea, I thought the same thing, technically it's possible for charging, but wouldn't there be a problem for data transmission?

CRD716, 2024-03-05:
Wonder if there would be any use for a 3.1 speed connection.

tdjastrzebski, 2024-04-14:
Changing connector to USB-C would be a very simple and very appreciated improvement.
Let's face it, USB-C gained wide acceptance everywhere and in 2024 it is really time to move forward.
Anyone who says that adapter could be uses clearly missies the point.
Note that, with more some improvements, this may allow for higher power supply voltage and more output power.

straithe, 2024-04-15:
USB-C is not a simple change to the board. As you've mentioned, there is a difference in power supply. That change alone would require a lot more engineering work than substituting one type of USB connector for another. If you want to understand the depth of changes required I recommend doing a deep dive into the different USB spec documents: https://usb.org/documents

raleighlittles, 2024-04-15:
@straithe I explained this in my original comment above.. the goal of this feature request was really just to replace the connector itself. You _can_ use the USB-c connector with the legacy USB 2.0 interface. Moving to the USB 3.0+ interface would, as you pointed out, require engineering work, but simply switching the connector type would just be a part replacement. All you would have to do is add a second set of V, G, D+, D- pin routes.

tdjastrzebski, 2024-04-15:
@straithe The change required to use full USB-C power delivery (PD) potential in sink mode, that is, ability to negotiate higher voltage and/or higher current is not a small change, likely additional chip like [TPS25730](https://www.ti.com/product/TPS25730) would be required to avoid dealing with CC lines directly.

However, the above is just an option. Simple socket change is much easier, would require just two 5.1k CC1/CC2 pull-down resistors and overshoot protection circuit (a TVS Schottky Diode and RC Snubber). To be super safe, half of the [LS24062RQ23](https://www.littelfuse.com/products/protection-ic/efuse/ls24062rq23) chip could be used. That is all what is needed.

ICantMakeThings, 2024-07-04:
https://github.com/ICantMakeThings/hackrf/blob/master/hardware/hackrf-one/hackrf-one.kicad_pcb
here, i also made a issue with USB-c
@raleighlittles

martinling, 2024-07-04:
We know that it would be possible to change the connector to USB-C, but there are some practical issues with doing so from a production and business point of view.

- We ship HackRF One with an injection molded enclosure, which has an opening sized for the smaller USB Micro-B connector. If we changed the board to use USB-C, we'd need to remake the mold tooling, which is expensive. We’d need to manufacture new enclosures, and discard all our existing stock of enclosures.

- There are many enclosures offered by other manufacturers, including all those designed for the various Portapack add-ons. Changing the connector type would break compatibility with those enclosures.

- Currently all revisions of HackRF One are equivalent and have the same SKU. This keeps things simple for stock keeping, returns, users integrating the device into other systems, etc. A connector swap would mean that newer and older units would no longer be interchangeable, which would add a lot of unnecessary complication to operations for GSG, our resellers, and end users.

It's hard to justify the upheaval of this change, when the USB-C connector doesn't offer any functional advantage for a USB 2.0 device. It's not going to get you faster speeds, or different power capabilities, or any other benefits except reversibility. We know some folks prefer all their things to be USB-C so that they can use their USB-C cables everywhere, but we also have a lot of users with a lot of Micro-B cables. We can't please everyone.

As such, we’re not planning to make this change. If you really want a HackRF with a USB-C connector, you're welcome to design and build your own. All our hardware is open source, so that everyone is free to make changes and remix our designs in ways that suit them better.

Commander-Crash, 2024-07-21:
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

I have tried this with a few usb-c breakout's it works for a moment but will get "SV#4" crash or total disconnection for no reason. I think its the way the USB clock is being generated IDK.

CoelacanthusHex, 2025-02-05:
> It's not going to get you faster speeds, or different power capabilities, or any other benefits except reversibility.

Actually, Type-C provides higher power capability although without Power Delivery, just puts two 5.1k Ohm Rd on CC. It's capable to 5V @ 3A while Type-A/Type-B/Micro-B only have 5V @ 1.5A power at maximum. 15W is double of 7.5W.

tdjastrzebski, 2025-02-05:
Usually max current @ 5V is even slightly higher: 3.15A.
It is possible because USB-C uses four parallel pins for Vcc and four pins for ground.

Closed 2024-07-04.

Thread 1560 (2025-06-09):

Lighting Strike

zglozman, 2025-06-09:
### What outcome were you hoping for?

I had a serrious lighting strike nearby, and it totally bricked my hackrf, no leds turn on when powered, can someone tell me where to start trouble shooting ?

### What outcome actually happened?

help

### What operating systems are you seeing the problem on?

Linux

### What is the output of ```hackrf_info```?

nothing

### Are you using any third-party software?

sdr

### Are you using any third-party hardware?

a

Moji14, 2025-06-10:
I hope this helps...
https://eshop.sectron.eu/en/lightning-arrestor-sma-m-sma-f/p-1371/

martinling, 2025-06-19:
If you're comfortable reading a schematic and probing with a meter then you could try to identify what's damaged.

If no LEDs are on then you don't have a 3.3V supply. That supply comes from the U21 regulator.

The 5V supply from USB flows through FB1 and Q5 to reach U21. It's also possible for U15 to fail short. Check the voltage at each component to see if the 5V supply is getting to U21.

If it is, then you may need to replace U21 and possibly other components associated with it.

Note however that a lightning strike is a serious event and there could be multiple damaged components, so even after recovering the power supplies the board may not be recoverable.

Closed 2025-07-17.

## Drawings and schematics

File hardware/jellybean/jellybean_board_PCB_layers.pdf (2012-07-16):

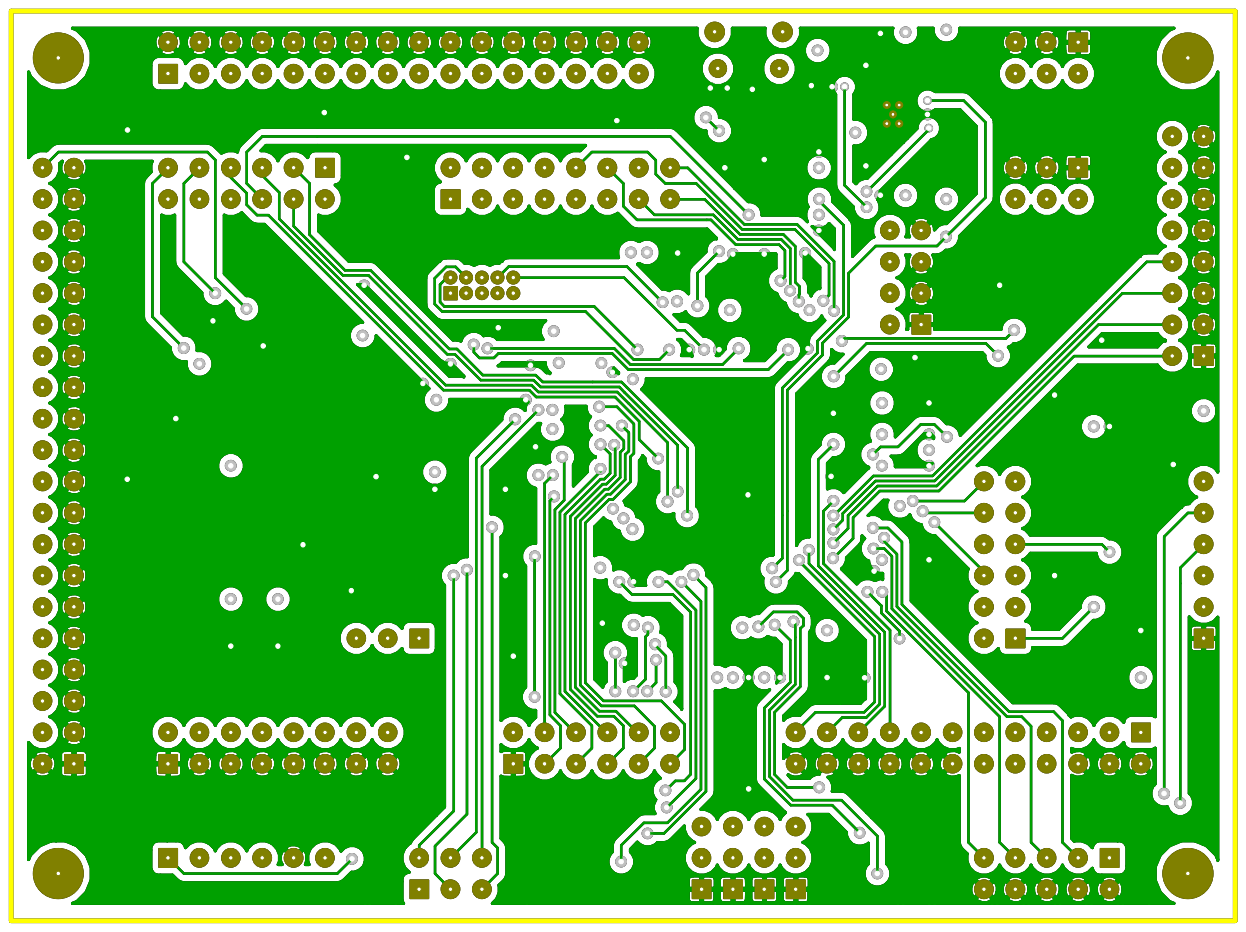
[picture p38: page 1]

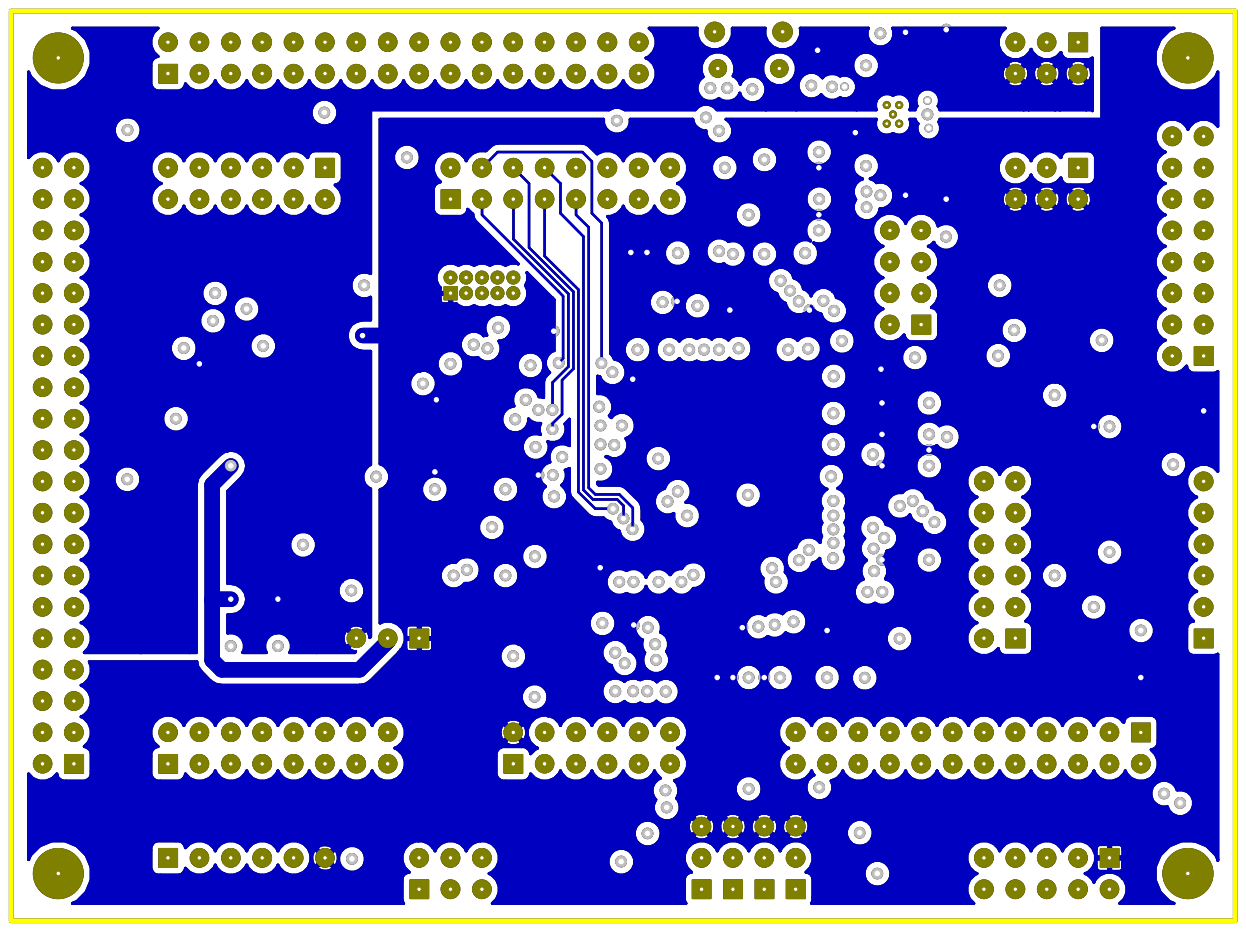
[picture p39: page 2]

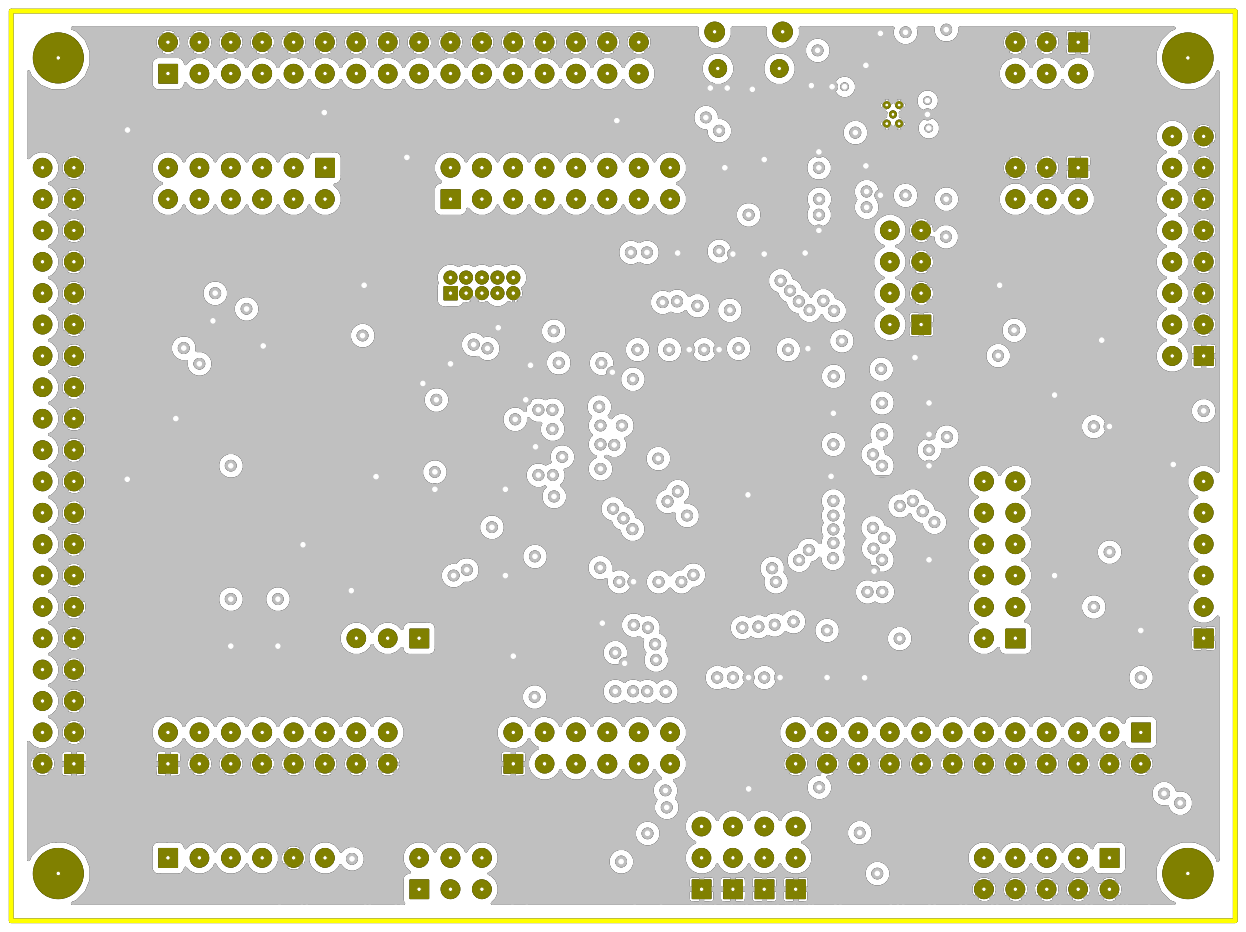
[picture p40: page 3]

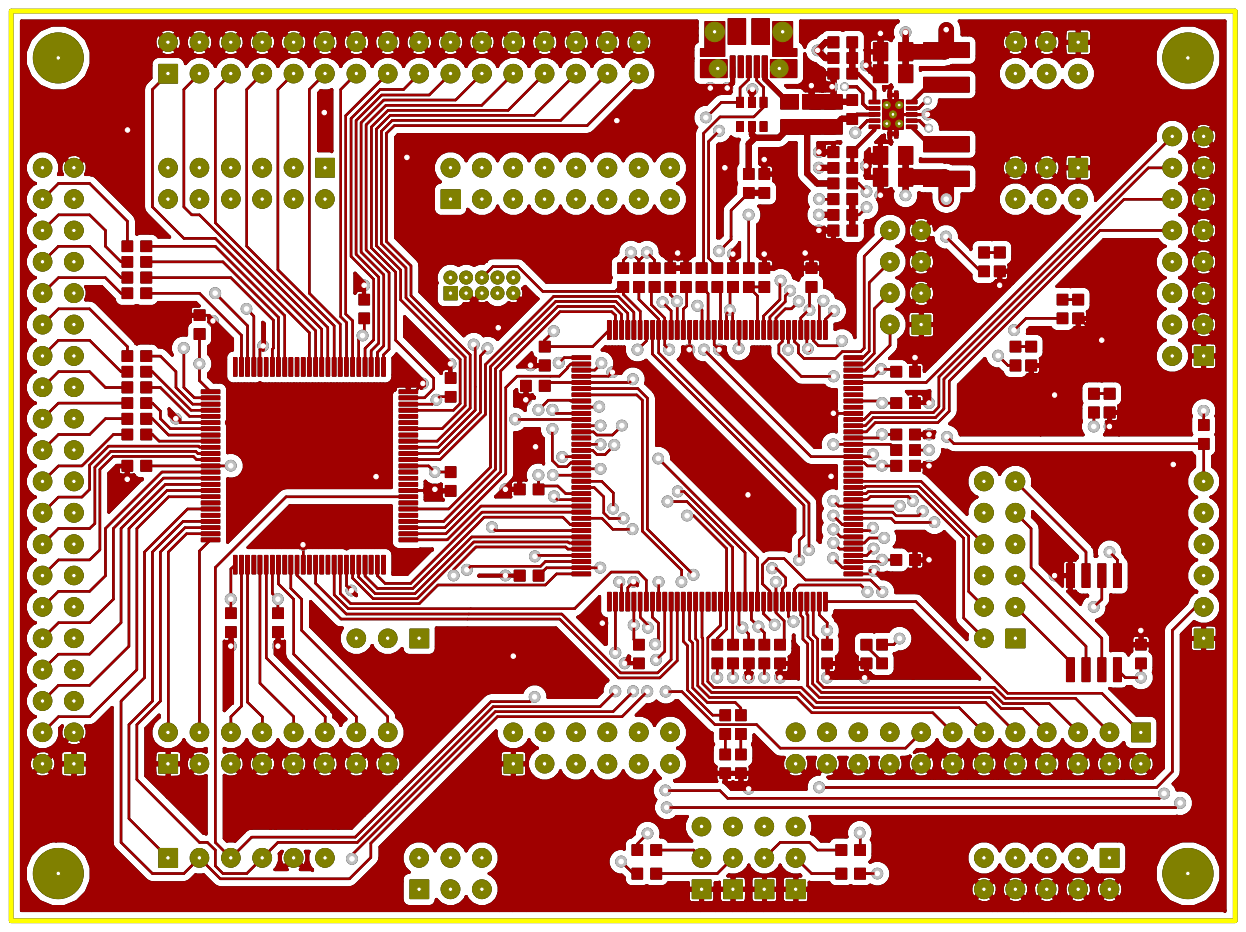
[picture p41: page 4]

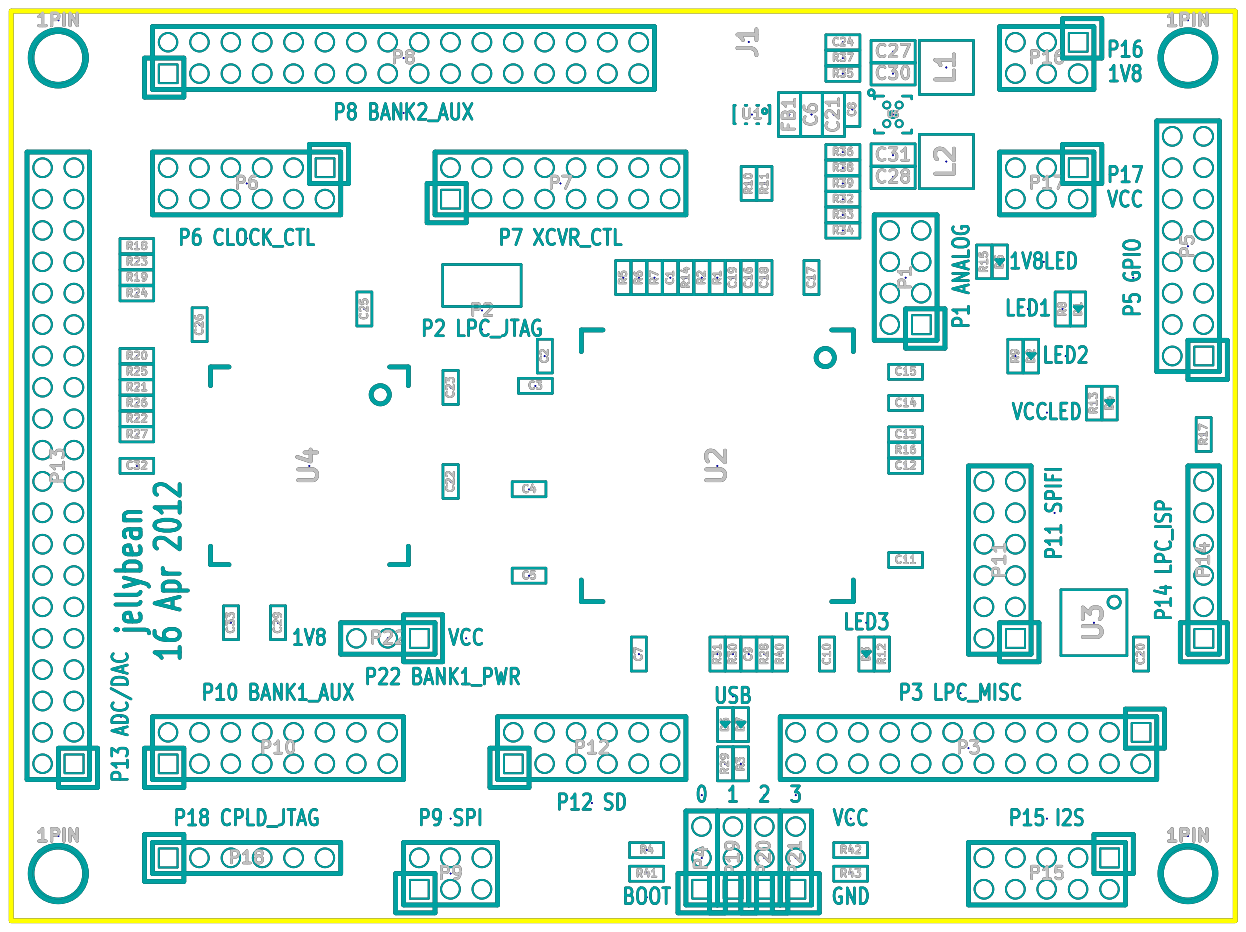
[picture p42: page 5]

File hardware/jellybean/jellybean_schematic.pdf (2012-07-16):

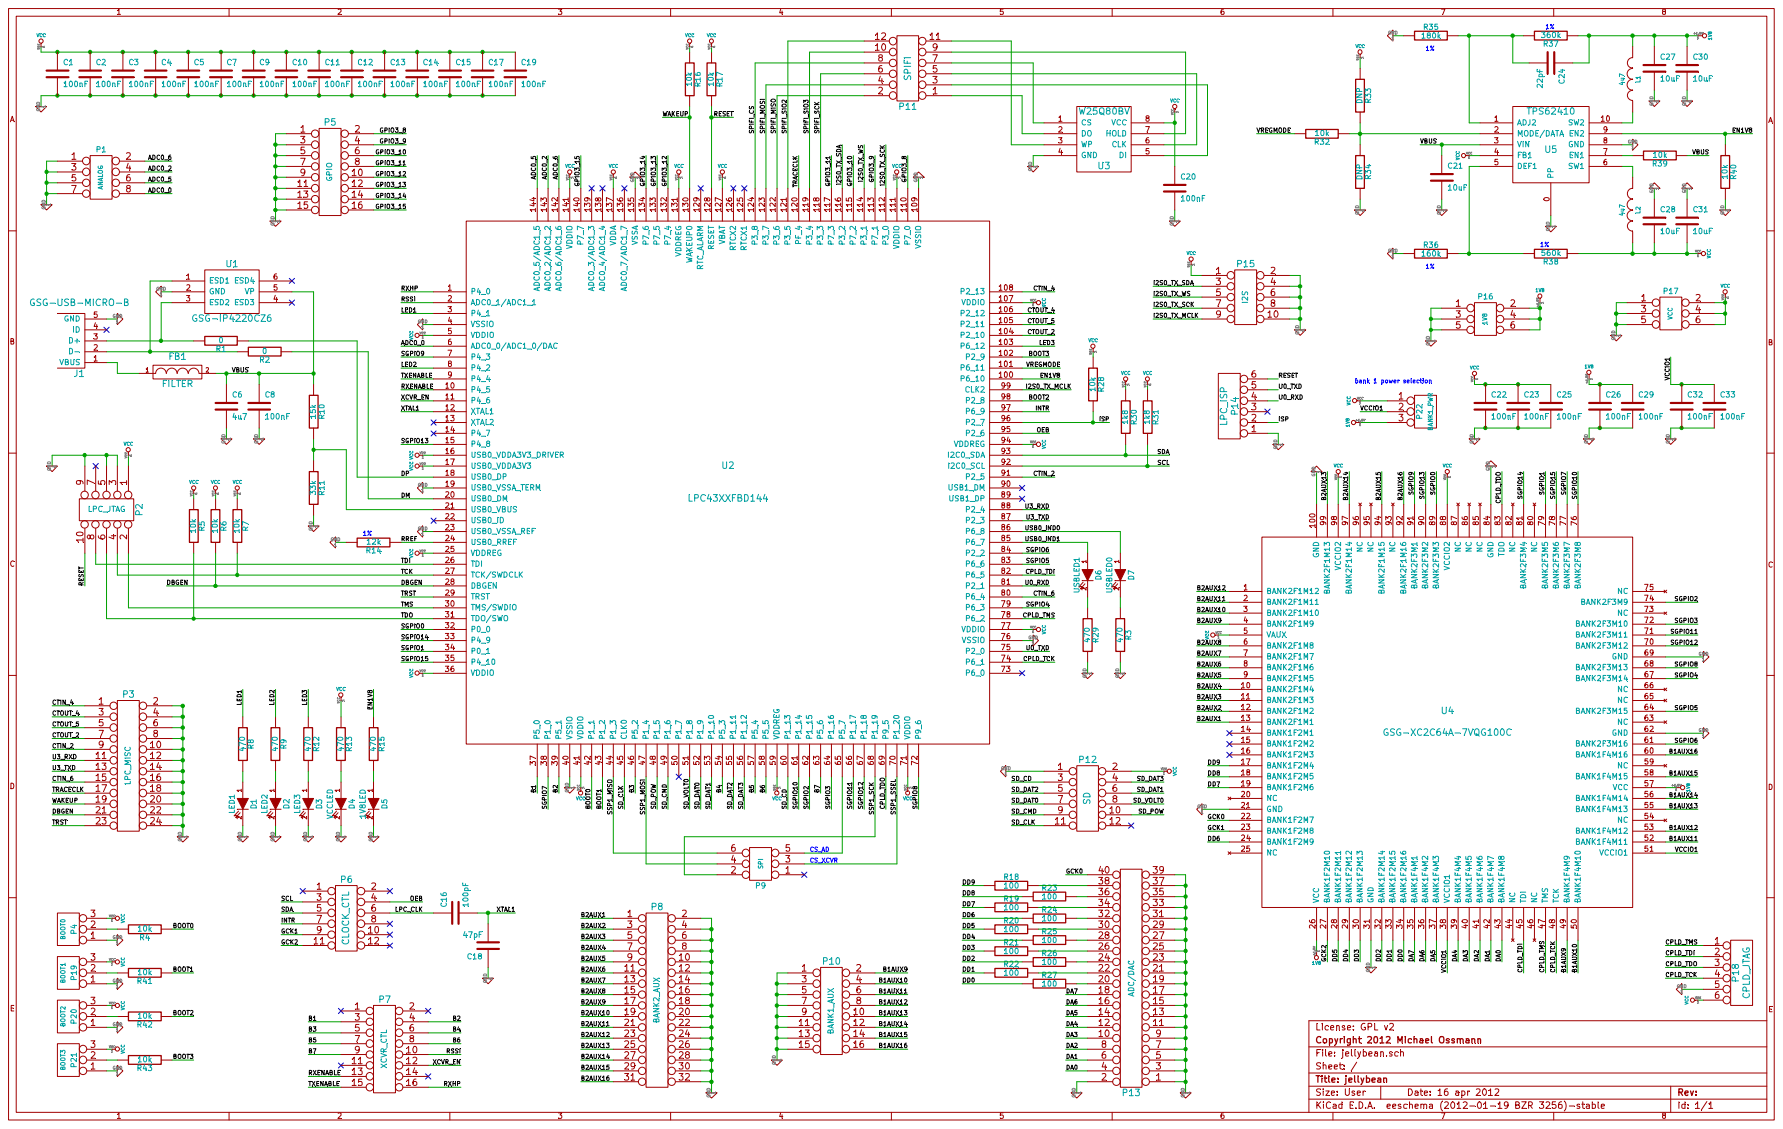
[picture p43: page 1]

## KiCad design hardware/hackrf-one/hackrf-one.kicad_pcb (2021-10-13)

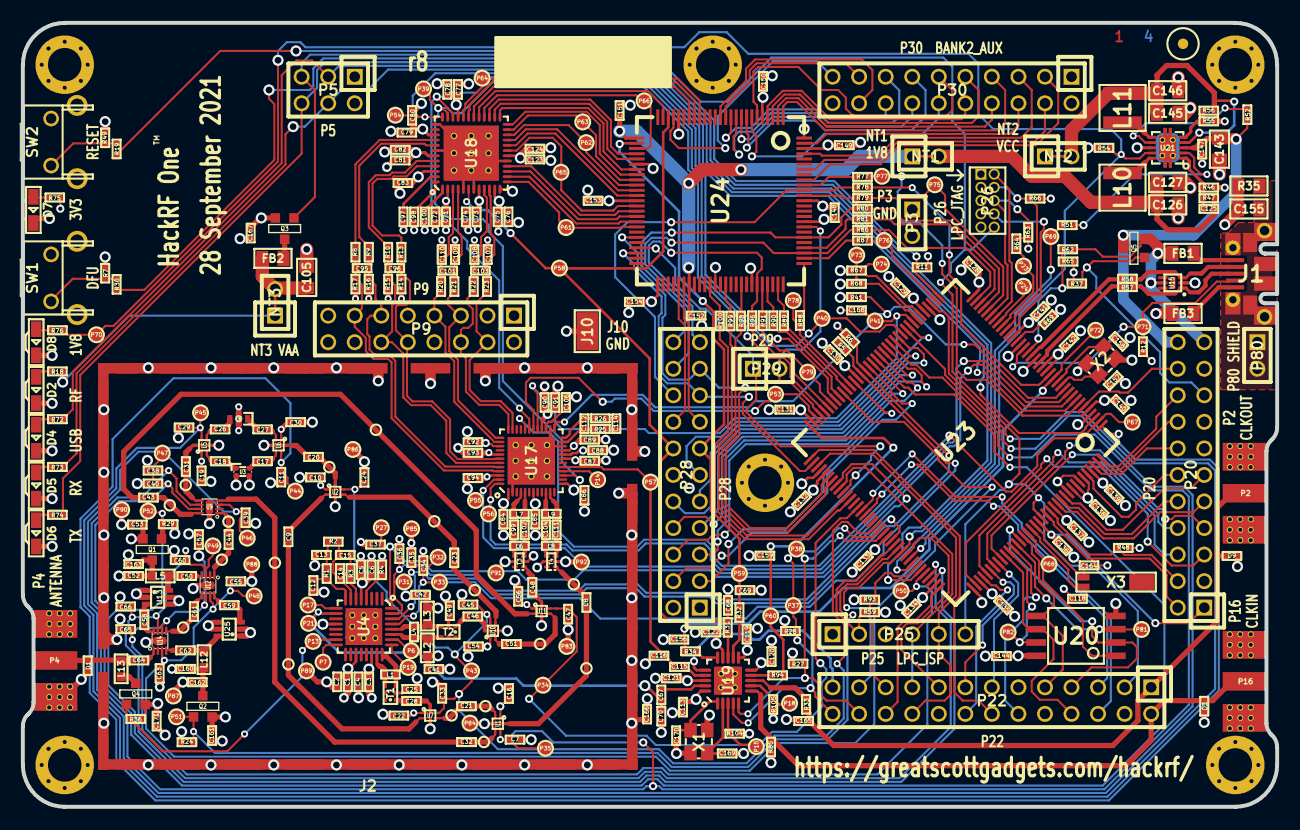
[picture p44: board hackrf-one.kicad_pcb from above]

Board: 4 copper layers, 120.0 x 75.0 mm, 431 parts (0 on the bottom side), 315 nets.

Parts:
C1, C3, C5, C7, C11, C24, C29, C33, C34, C35, C36, C37, C38, C39, C40, C45, C47, C55, C57, C60, C63, C65, C66, C67, C115, C125: 33pF; GSG-0402
C2, C4, C6, C10, C16, C19, C22, C30, C54, C56, C87, C88, C89, C92, C93, C162, C163: 10nF; GSG-0402
C8, C21, C32, C43, C48, C51, C84, C85, C86, C94, C95, C96, C99, C101, C102, C103, C107, C108, C109, C110: 22pF; GSG-0402
C9, C17, C18, C20, C23, C25, C28, C31, C44, C46, C49, C50, C58, C59, C61, C62, C64, C71, C73, C75, C77, C79, C81, C83, C91, C113, C119, C120, C121, C122, C123, C128, C129, C130, C131, C132, C133, C134, C135, C136, C137, C138, C139, C140, C141, C142, C144, C147, C148, C149, C150, C151, C152, C153, C154, C166, C167: 100nF; GSG-0402
C12, C13: 330pF; GSG-0402
C14: 8p2; GSG-0402
C15, C112: 180pF; GSG-0402
C26, C27, C116, C156: 47pF; GSG-0402
C41, C42, C52, C68, C69, C70, C90, C159, C160, C165, C168: 100pF; GSG-0402
C53, C106, C161, C171: 1uF; GSG-0402
C72, C74, C76, C78, C80, C82, C124: 2.2uF; GSG-0402
C97, C98, C100: 330nF; GSG-0402
C104, C111: 3pF; GSG-0402
C105, C126, C127, C143, C145, C146: 10uF; GSG-0805
C114: 3.3nF; GSG-0402
C118, C157, C158, C164: 18pF; GSG-0402
C155: DNP; GSG-0805
C169, C170: 1.8pF; GSG-0402
D1, D3, D9: GSG-DIODE-TVS-BI; GSG-0402
D2: VAALED; LTST-S220
D4: USBLED; LTST-S220
D5: RXLED; LTST-S220
D6: TXLED; LTST-S220
D7: VCCLED; LTST-S220
D8: 1V8LED; LTST-S220
FB1, FB2, FB3: FILTER; GSG-0805
J1: USB-MICRO-B; GSG-USB-MICROB-FCI-10103592-EXT
J2: RF-SHIELD-FRAME; GSG-SHIELD-BMI-S-230
J3: RF-SHIELD-COVER; GSG-NULL-MODULE
J4, J5, J6, J7, J8, J9: MOUNTING_HOLE; GSG-HOLE126MIL-COPPER
J10: GND_CLIP; GSG-TEST-POINT-S1751-46R
L1, L4, L6, L8, L9: DNP; GSG-0402
L2, L3, L5, L12, L13: 10uH; GSG-0603
L7: 6.2nH; GSG-0402
L10, L11: 4u7; GSG-NRG4026
MARK1MM: VAL**; GSG-MARK1MM
NT1: 1V8; HEADER-1x2-SHORTED
NT2: VCC; HEADER-1x2-SHORTED
NT3: VAA; HEADER-1x2-SHORTED
P2: CLKOUT; GSG-SMA-73251-2120
P3: GND; GSG-HEADER-NOMARK-1x2
P4: ANTENNA; GSG-SMA-73251-2120
P5: LEDS; GSG-HEADER-2x3
P6: GPO4; GSG-TESTPOINT-50MIL
P7: GPO2; GSG-TESTPOINT-50MIL
P9: BASEBAND; GSG-HEADER-2x8
P13: GPO1; GSG-TESTPOINT-50MIL
P14: XCVR_CLKOUT; GSG-TESTPOINT-50MIL
P15: INTR; GSG-TESTPOINT-50MIL
P16: CLKIN; GSG-SMA-73251-2120
P17: GPO6; GSG-TESTPOINT-50MIL
P18: OEB; GSG-TESTPOINT-50MIL
P19: GPO3; GSG-TESTPOINT-50MIL
P20: GPIO; GSG-HEADER-2x11
P21: REF_IN; GSG-TESTPOINT-50MIL
P22: I2S; GSG-HEADER-2x13
P23: DBGEN; GSG-TESTPOINT-50MIL
P24: TRST; GSG-TESTPOINT-50MIL
P25: LPC_ISP; GSG-HEADER-1x6
P26: LPC_JTAG; GSG-50MIL-HEADER-2x5-TH
P27: MIXER_SDATA; GSG-TESTPOINT-50MIL
P28: SD; GSG-HEADER-2x11
P29: CPLD_JTAG; GSG-HEADER-1x2
P30: BANK2_AUX; GSG-HEADER-2x10
P31: MIXER_SCLK; GSG-TESTPOINT-50MIL
P32: MIXER_ENX; GSG-TESTPOINT-50MIL
P33: MIXER_RESETX; GSG-TESTPOINT-50MIL
P34: MIX_BYPASS; GSG-TESTPOINT-50MIL
P35: !MIX_BYPASS; GSG-TESTPOINT-50MIL
P37: SCL; GSG-TESTPOINT-50MIL
P38: SDA; GSG-TESTPOINT-50MIL
P39: SSP1_SCK; GSG-TESTPOINT-50MIL
P40: SSP1_COPI; GSG-TESTPOINT-50MIL
P41: SSP1_CIPO; GSG-TESTPOINT-50MIL
P43: RX; GSG-TESTPOINT-50MIL
P44: HP; GSG-TESTPOINT-50MIL
P45: LP; GSG-TESTPOINT-50MIL
P46: TX_MIX_BP; GSG-TESTPOINT-50MIL
P47: RX_MIX_BP; GSG-TESTPOINT-50MIL
P48: TX_AMP; GSG-TESTPOINT-50MIL
P49: RX_AMP; GSG-TESTPOINT-50MIL
P50: AMP_BYPASS; GSG-TESTPOINT-50MIL
P51: !TX_AMP_PWR; GSG-TESTPOINT-50MIL
P52: !RX_AMP_PWR; GSG-TESTPOINT-50MIL
P53: CS_XCVR; GSG-TESTPOINT-50MIL
P54: CS_AD; GSG-TESTPOINT-50MIL
P55: TXENABLE; GSG-TESTPOINT-50MIL
P56: RXENABLE; GSG-TESTPOINT-50MIL
P57: XTAL2; GSG-TESTPOINT-50MIL
P58: GCK1; GSG-TESTPOINT-50MIL
P59: GCK2; GSG-TESTPOINT-50MIL
P60: SGPIO_CLK; GSG-TESTPOINT-50MIL
P61: DA0; GSG-TESTPOINT-50MIL
P62: DA7; GSG-TESTPOINT-50MIL
P63: DD0; GSG-TESTPOINT-50MIL
P64: DD9; GSG-TESTPOINT-50MIL
P65: DA4; GSG-TESTPOINT-50MIL
P66: DD5; GSG-TESTPOINT-50MIL
P67: RSSI; GSG-TESTPOINT-50MIL
P68: SPIFI_CS; GSG-TESTPOINT-50MIL
P69: VREGMODE; GSG-TESTPOINT-50MIL
P70: EN_1V8; GSG-TESTPOINT-50MIL
P71: ID; GSG-TESTPOINT-50MIL
P72, P75, P76, P77, P78, P79: GP_CLKIN; GSG-TESTPOINT-50MIL
P73: P1_2; GSG-TESTPOINT-50MIL
P74: P1_1; GSG-TESTPOINT-50MIL
P80: SHIELD; GSG-HEADER-NOMARK-1x2
P81: SPIFI_SIO2; GSG-TESTPOINT-50MIL
P82: SPIFI_SIO3; GSG-TESTPOINT-50MIL
P83, P84, P85, P86, P87, P88, P89, P90, P91, P92: GND; GSG-TESTPOINT-50MIL
Q1, Q2, Q3, Q4, Q5: MOSFET_P; SOT23-3
R1, R2, R72, R75: 470; GSG-0402
R3: 22k; GSG-0402
R4: 51k; GSG-0402
R5, R6, R7, R11, R12, R24, R29, R36, R37, R41, R48, R49, R51, R52, R54, R59, R62, R63, R64, R66, R67, R68, R85, R93, R104, R105: 10k; GSG-0402
R8, R9, R10, R13, R73, R76: 1k; GSG-0402
R14, R15, R16, R17: 4k7; GSG-0402
R18, R27, R28, R74: 1k8; GSG-0402
R19, R30, R31, R32, R33, R34, R77, R78, R79, R80, R81, R86, R87, R88, R89, R90, R91, R94, R96, R98, R99, R100: 39; GSG-0402
R20, R21, R22, R23, R57, R58: 0; GSG-0402
R25, R26: 475; GSG-0402
R35: DNP; GSG-0805
R46, R55: 162k; GSG-0402
R47: 330k; GSG-0402
R56: 715k; GSG-0402
R65: 18k; GSG-0402
R69: 12k; GSG-0402
SW1: DFU; GSG-SWITCH-FSMRA
SW2: RESET; GSG-SWITCH-FSMRA
T1: MIX_IN_BALUN; GSG-B0310J50100AHF
T2: MIX_OUT_BALUN; GSG-B0310J50100AHF
T3: RX_BALUN; GSG-2500BL14M100
T4: TX_BALUN; GSG-2500BL14M100
TESTPOINT-30MIL-MASKONLY, TESTPOINT-30MIL-MASKONLY#2, TESTPOINT-30MIL-MASKONLY#3, TESTPOINT-30MIL-MASKONLY#4, TESTPOINT-30MIL-MASKONLY#5, TESTPOINT-30MIL-MASKONLY#6, TESTPOINT-30MIL-MASKONLY#7, TESTPOINT-30MIL-MASKONLY#8, TESTPOINT-30MIL-MASKONLY#9, TESTPOINT-30MIL-MASKONLY#10, TESTPOINT-30MIL-MASKONLY#11, TESTPOINT-30MIL-MASKONLY#12, TESTPOINT-30MIL-MASKONLY#13, TESTPOINT-30MIL-MASKONLY#14, TESTPOINT-30MIL-MASKONLY#15, TESTPOINT-30MIL-MASKONLY#16, TESTPOINT-30MIL-MASKONLY#17: VAL**; GSG-TESTPOINT-30MIL-MASKONLY
U1, U2, U5, U6, U7, U10, U11: SKY13453; SKY13350-385LF
U3: RX_LOWPASS_FILTER; GSG-LP0603
U4: RFFC5072; GSG-QFN32
U8: RX_HIGHPASS_FILTER; GSG-HP-DEA
U9, U12, U14: SKY13317; GSG-SKY13317-373LF
U13, U25: MGA-81563; GSG-SOT363
U15: TVS; GSG-LXES1TBCC2-004
U17: MAX2837; GSG-QFN48-6
U18: MAX5864; GSG-QFN48-7
U19: SI5351C; GSG-QFN20-4
U20: W25Q80; GSG-SOIC8-208
U21: TPS62410; GSG-S-PVSON-N10
U23: LPC4320FBD144; GSG-LQFP144
U24: GSG-XC2C64A-7VQG100C; GSG-VQ100
X1: GSG-XTAL4PIN; GSG-XTAL3.2x2.5mm
X2: MCU_XTAL; GSG-XTAL3.2x2.5mm
X3: RTC_XTAL; GSG-XTAL-AB26TRQ

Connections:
!MIX_BYPASS: C7.2, C38.2, P35.1, U1.5, U9.6, U23.50
!RX_AMP_PWR: P52.1, Q1.1, R29.2, U23.106
!TX_AMP_PWR: P51.1, Q2.1, R24.1, U23.97
!VAA_ENABLE: P5.5, Q3.1, R11.2, U23.37
+1V8: C151.1, C152.1, NT1.1, U24.26, U24.57
/baseband/CLK0: R31.2, U19.13
/baseband/CLK1: R32.2, U19.12
/baseband/CLK2: R94.2, U19.9
/baseband/CLK3: R33.2, U19.8
/baseband/CLK5: C115.1, U19.17
/baseband/COM: C97.1, U18.47
/baseband/CPOUT+: C112.2, R25.1, U17.23
/baseband/CPOUT-: C112.1, R26.1, U17.24
/baseband/IA+: C101.1, C110.1, R20.1, U18.3
/baseband/IA-: C101.2, C109.1, R21.1, U18.4
/baseband/ID+: R13.1, U18.45
/baseband/ID-: R10.1, U18.44
/baseband/INTR: P15.1, R104.2, U19.3
/baseband/OEB: P18.1, R105.2, U19.7
/baseband/QA+: C103.2, C107.1, R23.1, U18.10
/baseband/QA-: C103.1, C108.1, R22.1, U18.9
/baseband/QD+: R8.1, U18.40
/baseband/QD-: R9.1, U18.41
/baseband/REFN: C98.1, U18.48
/baseband/REFP: C100.1, U18.1
/baseband/RXBBI+: P9.7, R20.2, U17.38
/baseband/RXBBI-: P9.5, R21.2, U17.37
/baseband/RXBBQ+: P9.6, R22.2, U17.36
/baseband/RXBBQ-: P9.4, R23.2, U17.35
/baseband/TXBBI+: C96.1, P9.12, R10.2, R15.1, U17.43
/baseband/TXBBI-: C96.2, P9.10, R13.2, R14.1, U17.42
/baseband/TXBBQ+: C95.2, P9.11, R9.2, R16.1, U17.44
/baseband/TXBBQ-: C95.1, P9.13, R8.2, R17.1, U17.45
/baseband/XA: C170.2, U19.1, X1.3
/baseband/XB: C169.2, U19.2, X1.1
/baseband/XCVR_CLKOUT: P14.1, U17.16
/baseband/XTAL2: C115.2, C116.1, P57.1, U17.17
/frontend/!ANT_BIAS: P13.1, Q4.1, R36.1, U4.15
/frontend/REF_IN: C67.2, C70.1, P21.1, U4.10
/frontend/RX_AMP_IN: C58.1, U14.8
/frontend/RX_AMP_OUT: C50.2, U12.4
/frontend/TX_AMP_IN: C59.1, U12.8
/frontend/TX_AMP_OUT: C62.1, U14.4
/mcu/usb/power/ADC0_0: P20.20, U23.6
/mcu/usb/power/ADC0_2: P20.16, U23.143
/mcu/usb/power/ADC0_5: P20.18, U23.144
/mcu/usb/power/ADC0_6: P20.14, U23.142
/mcu/usb/power/B1AUX13: P28.16, U24.55
/mcu/usb/power/B1AUX14: P28.15, U24.56
/mcu/usb/power/B2AUX1: P30.18, U24.13
/mcu/usb/power/B2AUX2: P30.17, U24.12
/mcu/usb/power/B2AUX3: P30.16, U24.11
/mcu/usb/power/B2AUX4: P30.15, U24.10
/mcu/usb/power/B2AUX5: P30.14, U24.9
/mcu/usb/power/B2AUX6: P30.13, U24.8
/mcu/usb/power/B2AUX7: P30.12, U24.7
/mcu/usb/power/B2AUX8: P30.11, U24.6
/mcu/usb/power/B2AUX9: P30.10, U24.4
/mcu/usb/power/B2AUX10: P30.9, U24.3
/mcu/usb/power/B2AUX11: P30.8, U24.2
/mcu/usb/power/B2AUX12: P30.7, U24.1
/mcu/usb/power/B2AUX13: P30.6, U24.99
/mcu/usb/power/B2AUX14: P30.5, U24.97
/mcu/usb/power/B2AUX15: P30.4, U24.94
/mcu/usb/power/B2AUX16: P30.3, U24.92
/mcu/usb/power/BANK2F3M1: R77.2, U24.91
/mcu/usb/power/BANK2F3M2: P28.18, R78.2, U24.90
/mcu/usb/power/BANK2F3M3: R79.2, U24.89
/mcu/usb/power/BANK2F3M4: P28.22, R80.2, U24.81
/mcu/usb/power/BANK2F3M5: R81.2, U24.79
/mcu/usb/power/BANK2F3M6: P28.20, R86.2, U24.78
/mcu/usb/power/BANK2F3M7: R87.2, U24.77
/mcu/usb/power/BANK2F3M8: R88.2, U24.76
/mcu/usb/power/BANK2F3M9: R89.2, U24.74
/mcu/usb/power/BANK2F3M10: R90.2, U24.72
/mcu/usb/power/BANK2F3M11: R91.2, U24.71
/mcu/usb/power/BANK2F3M12: P28.21, R96.2, U24.70
/mcu/usb/power/BANK2F3M14: R98.2, U24.67
/mcu/usb/power/BANK2F3M15: R99.2, U24.64
/mcu/usb/power/BANK2F3M16: R100.2, U24.61
/mcu/usb/power/CPLD_TCK: P28.17, U23.74, U24.48
/mcu/usb/power/CPLD_TDI: P28.19, U23.78, U24.45
/mcu/usb/power/CPLD_TDO: P29.2, U23.69, U24.83
/mcu/usb/power/CPLD_TMS: P29.1, U23.82, U24.47
/mcu/usb/power/DBGEN: P23.1, R64.1, U23.28
/mcu/usb/power/DM: R58.1, U23.20
/mcu/usb/power/DP: R57.1, U23.18
/mcu/usb/power/EN1V8: P70.1, R54.2, R76.2, U21.9, U23.100
/mcu/usb/power/GCK0: P30.19, U24.22
/mcu/usb/power/GPIO3_8: P20.5, U23.110
/mcu/usb/power/GPIO3_9: P20.6, U23.113
/mcu/usb/power/GPIO3_10: P20.7, U23.115
/mcu/usb/power/GPIO3_11: P20.8, U23.117
/mcu/usb/power/GPIO3_12: P20.9, U23.132
/mcu/usb/power/GPIO3_13: P20.10, U23.133
/mcu/usb/power/GPIO3_14: P20.11, U23.134
/mcu/usb/power/GPIO3_15: P20.12, U23.140
/mcu/usb/power/GP_CLKIN: C156.1, P72.1, R34.1, U23.14
/mcu/usb/power/I2C1_SCL: P22.5, U23.88
/mcu/usb/power/I2C1_SDA: P22.6, U23.87
/mcu/usb/power/I2S0_RX_MCLK: P22.14, U23.73
/mcu/usb/power/I2S0_RX_SCK: P22.12, U23.120
/mcu/usb/power/I2S0_RX_SDA: P22.13, U23.116
/mcu/usb/power/I2S0_RX_WS: P22.15, U23.114
/mcu/usb/power/I2S0_TX_MCLK: P22.17, U23.99
/mcu/usb/power/I2S0_TX_SCK: P22.16, U23.112
/mcu/usb/power/ISP: P25.2, R59.2, U23.96
/mcu/usb/power/LED1: P5.3, R72.2, U23.3
/mcu/usb/power/LED2: P5.4, R73.2, U23.8
/mcu/usb/power/LED3: P5.6, R74.2, U23.103
/mcu/usb/power/P1_1: P74.1, R67.1, U23.42
/mcu/usb/power/P1_2: P73.1, R68.1, U23.43
/mcu/usb/power/P2_8: P22.23, R30.1, U23.98
/mcu/usb/power/P2_9: P22.21, R93.1, U23.102
/mcu/usb/power/P2_13: P22.22, U23.108
/mcu/usb/power/REG_OUT1: C145.2, C146.2, L11.1, NT2.2, R56.1, U21.4
/mcu/usb/power/REG_OUT2: C125.1, C126.1, C127.1, L10.2, NT1.2, R47.1
/mcu/usb/power/RESET: P22.3, P25.6, P26.10, R19.1, U23.128
/mcu/usb/power/RREF: R69.1, U23.24
/mcu/usb/power/RTCX1: C118.1, U23.125, X3.2
/mcu/usb/power/RTCX2: C164.1, U23.126, X3.1
/mcu/usb/power/RTC_ALARM: P20.2, U23.129
/mcu/usb/power/SD_CD: P28.3, U23.60
/mcu/usb/power/SD_CLK: P28.11, U23.45
/mcu/usb/power/SD_CMD: P28.9, U23.49
/mcu/usb/power/SD_DAT0: P28.7, U23.52
/mcu/usb/power/SD_DAT1: P28.6, U23.53
/mcu/usb/power/SD_DAT2: P28.5, U23.55
/mcu/usb/power/SD_DAT3: P28.4, U23.56
/mcu/usb/power/SD_POW: P28.10, U23.48
/mcu/usb/power/SD_VOLT0: P28.8, U23.51
/mcu/usb/power/SGPIO0: P75.1, R79.1, U23.32
/mcu/usb/power/SGPIO1: R81.1, U23.34
/mcu/usb/power/SGPIO2: R89.1, U23.62
/mcu/usb/power/SGPIO3: R90.1, U23.64
/mcu/usb/power/SGPIO4: R98.1, U23.79
/mcu/usb/power/SGPIO5: R99.1, U23.83
/mcu/usb/power/SGPIO6: R100.1, U23.84
/mcu/usb/power/SGPIO7: P76.1, R87.1, U23.38
/mcu/usb/power/SGPIO9: P77.1, R77.1, U23.7
/mcu/usb/power/SGPIO10: P78.1, R88.1, U23.61
/mcu/usb/power/SGPIO11: P79.1, R91.1, U23.66
/mcu/usb/power/SGPIO12: R96.1, U23.67
/mcu/usb/power/SGPIO13: R78.1, U23.15
/mcu/usb/power/SGPIO14: R80.1, U23.33
/mcu/usb/power/SGPIO15: R86.1, U23.35
/mcu/usb/power/SPIFI_CIPO: P22.7, U20.2, U23.122
/mcu/usb/power/SPIFI_COPI: P22.9, U20.5, U23.123
/mcu/usb/power/SPIFI_CS: P68.1, U20.1, U23.124
/mcu/usb/power/SPIFI_SCK: P22.8, U20.6, U23.118
/mcu/usb/power/SPIFI_SIO2: P81.1, U20.3, U23.121
/mcu/usb/power/SPIFI_SIO3: P82.1, U20.7, U23.119
/mcu/usb/power/TCK: P26.4, R66.2, U23.27
/mcu/usb/power/TDI: P26.8, U23.26
/mcu/usb/power/TDO: P26.6, R63.1, U23.31
/mcu/usb/power/TMS: P26.2, U23.30
/mcu/usb/power/U0_RXD: P22.19, P25.4, U23.81
/mcu/usb/power/U0_TXD: P22.20, P25.5, U23.75
/mcu/usb/power/USB_SHIELD: C155.1, J1.0, P80.1, P80.2, R35.1
/mcu/usb/power/VBAT: C136.1, P20.1, U23.127
/mcu/usb/power/VBUS: FB1.2, P20.21, Q5.2, R62.2, U15.5
/mcu/usb/power/VBUSCTRL: P20.17, Q5.1, R37.2
/mcu/usb/power/VIN: C143.1, C147.1, P20.22, Q5.3, R52.1, U21.3
/mcu/usb/power/VREGMODE: P69.1, R51.2, U23.101
/mcu/usb/power/WAKEUP: P20.4, R48.2, U23.130
/mcu/usb/power/XTAL1: C157.1, U23.12, X2.1
/mcu/usb/power/XTAL2: C158.1, U23.13, X2.3
AMP_BYPASS: C57.1, C65.2, P50.1, U12.6, U14.6, U23.104
CLK6: P22.25, U19.16
CLKIN: D3.2, P16.1, P22.2, R85.1, U19.6
CLKOUT: C165.1, D9.2, P2.1, P22.1, R33.1
CS_AD: P54.1, U18.36, U23.65
CS_XCVR: P53.1, U17.30, U23.70
DA0: P61.1, U18.13, U24.43
DA1: U18.14, U24.42
DA2: U18.15, U24.41
DA3: U18.16, U24.40
DA4: P65.1, U18.19, U24.39
DA5: U18.20, U24.37
DA6: U18.21, U24.36
DA7: P62.1, U18.22, U24.35
DD0: P63.1, U18.23, U24.34
DD1: U18.24, U24.33
DD2: U18.25, U24.32
DD3: U18.26, U24.30
DD4: U18.27, U24.29
DD5: P66.1, U18.28, U24.28
DD6: U18.29, U24.24
DD7: U18.30, U24.19
DD8: U18.31, U24.18
DD9: P64.1, U18.32, U24.17
GCK1: C68.1, P28.14, P58.1, R31.1, U18.6, U24.23
GCK2: C69.1, P28.13, P59.1, R32.1, U24.27
GND: C1.2, C2.2, C3.2, C4.2, C5.2, C6.2, C7.1, C10.1, C11.1, C12.2, C13.2, C16.2, C19.1, C22.1, C24.1, C25.2, C29.2, C30.2, C33.2, C34.2, C35.2, C36.2, C37.2, C38.1, C39.1, C40.1, C41.2, C42.2, C45.1, C47.1, C49.1, C52.2, C53.2, C54.2, C55.2, C56.2, C57.2, C60.1, C63.2, C65.1, C66.1, C68.2, C69.2, C70.2, C71.2, C72.2, C73.2, C74.2, C75.2, C76.2, C77.2, C78.2, C79.2, C80.2, C81.2, C82.2, C83.2, C84.2, C85.2, C86.2, C87.2, C88.2, C89.2, C90.2, C91.2, C92.2, C93.2, C94.2, C97.2, C98.2, C100.2, C105.2, C106.2, C107.2, C108.2, C109.2, C110.2, C113.2, C116.2, C118.2, C119.2, C120.2, C121.2, C122.2, C123.2, C124.2, C126.2, C127.2, C128.2, C129.2, C130.2, C131.2, C132.2, C133.2, C134.2, C135.2, C136.2, C137.2, C138.2, C139.2, C140.2, C141.2, C142.2, C143.2, C144.2, C145.1, C146.1, C147.2, C148.2, C149.2, C150.2, C151.2, C152.2, C153.2, C154.2, C155.2, C156.2, C157.2, C158.2, C159.2, C160.2, C161.2, C162.1, C163.1, C164.2, C165.2, C166.2, C167.2, C168.2, C169.1, C170.1, C171.2, D1.1, D2.1, D3.1, D4.1, D5.1, D6.1, D7.1, D8.1, D9.1, FB3.2, J2.0, J4.1, J5.1, J6.1, J7.1, J8.1, J9.1, J10.1, P2.2, P3.1, P3.2, P4.2, P5.1, P9.1, P9.2, P9.3, P9.8, P9.9, P9.14, P9.15, P9.16, P16.2, P20.13, P20.15, P20.19, P22.4, P22.10, P22.18, P25.1, P26.3, P26.5, P26.9, P28.2, P28.12, P30.2, P30.20, P83.1, P84.1, P85.1, P86.1, P87.1, P88.1, P89.1, P90.1, P91.1, P92.1, R4.1, R7.2, R14.2, R15.2, R16.2, R17.2, R35.2, R37.1, R41.1, R46.1, R54.1, R55.1, R65.1, R68.2, R69.2, R85.2, R93.2, SW1.0, SW2.0, SW2.1, T3.2, T3.5, T4.2, T4.5, U1.3, U2.3, U3.2, U3.3, U4.0, U4.12, U5.3, U6.3, U7.3, U8.2, U8.4, U9.0, U10.3, U11.3, U12.0, U13.1, U13.2, U13.4, U13.5, U14.0, U15.2, U17.0, U17.2, U17.22, U17.26, U18.0, U18.5, U18.7, U18.12, U18.17, U18.37, U18.42, U19.0, U20.4, U21.0, U21.8, U23.4, U23.19, U23.23, U23.40, U23.76, U23.109, U23.135, U23.138, U24.21, U24.31, U24.62, U24.69, U24.84, U24.100, U25.1, U25.2, U25.4, U25.5, X1.2, X1.4, X2.2, X2.4
HP: C11.2, P44.1, U6.5, U23.1
LP: C29.1, P45.1, U5.5, U23.39
MCU_CLK: R34.2, U19.15
MIXER_ENX: C35.1, P32.1, R6.2, U4.30, U23.57
MIXER_RESETX: C34.1, P33.1, R5.2, U4.29, U23.58
MIXER_SCLK: C36.1, P31.1, U4.31, U23.95
MIXER_SDATA: C37.1, P27.1, U4.32, U23.80
MIX_BYPASS: C47.2, P34.1, U11.5, U23.86
MIX_CLK: C67.1, U19.19
unnamed: C8.2, U1.6
unnamed: C9.1, U7.2
unnamed: C9.2, U2.2
unnamed: C12.1, R1.2, U4.8
unnamed: C13.1, R1.1, R2.2
unnamed: C14.1, C15.1, R2.1, U4.7
unnamed: C14.2, R3.1, U4.6
unnamed: C15.2, R3.2
unnamed: C17.1, U3.4
unnamed: C17.2, U6.4
unnamed: C18.1, U5.2
unnamed: C18.2, U3.1
unnamed: C20.1, U6.6
unnamed: C20.2, U2.6
unnamed: C21.1, U1.2
unnamed: C21.2, U7.4
unnamed: C23.1, U10.4
unnamed: C23.2, U2.4
unnamed: C25.1, T1.2
unnamed: C26.1, U8.3
unnamed: C26.2, U5.4
unnamed: C27.1, U8.1
unnamed: C27.2, U6.2
unnamed: C28.1, T1.1
unnamed: C28.2, U7.6
unnamed: C31.1, U9.5
unnamed: C31.2, U5.6
unnamed: C32.1, U1.4
unnamed: C32.2, U9.4
unnamed: C43.1, U9.8
unnamed: C43.2, U11.2
unnamed: C44.1, U12.1
unnamed: C44.2, U9.1
unnamed: C46.1, U10.6
unnamed: C46.2, T2.1
unnamed: C48.1, U11.6
unnamed: C49.2, T2.2
unnamed: C50.1, L5.2, U13.6
unnamed: C51.1, U11.4
unnamed: C51.2, U10.2
unnamed: C58.2, U13.3
unnamed: C59.2, U25.3
unnamed: C61.1, U14.5
unnamed: C61.2, U12.5
unnamed: C62.2, L12.2, U25.6
unnamed: C64.1, U14.1
unnamed: C64.2, D1.2, L13.2, P4.1
unnamed: C99.1, L7.1, U17.4
unnamed: C99.2, L6.1, T3.4
unnamed: C102.1, L7.2, U17.5
unnamed: C102.2, L6.2, T3.3
unnamed: C104.1, L9.1, U17.10
unnamed: C104.2, L8.1, T4.4
unnamed: C105.1, FB2.2, NT3.2
unnamed: C106.1, U17.27
unnamed: C111.1, L9.2, U17.11
unnamed: C111.2, L8.2, T4.3
unnamed: C114.1, R26.2
unnamed: C114.2, R25.2
unnamed: C125.2, R46.2, R47.2, U21.1
unnamed: C160.1, C162.2, L12.1, Q2.3
unnamed: C52.1, C163.2, L5.1, Q1.3
unnamed: D2.2, R18.1
unnamed: D4.2, R72.1
unnamed: D5.2, R73.1
unnamed: D6.2, R74.1
unnamed: D7.2, R75.1
unnamed: D8.2, R76.1
unnamed: FB1.1, J1.1
unnamed: FB2.1, Q3.3
unnamed: FB3.1, J1.5
unnamed: J1.2, R58.2, U15.3
unnamed: J1.3, R57.2, U15.1
unnamed: J1.4, P71.1, R12.2, U23.22
unnamed: L1.1, T1.4, U4.23
unnamed: L1.2, T1.3, U4.24
unnamed: L2.1, L4.2, T2.4, U4.27
unnamed: L3.1, L4.1, T2.3, U4.28
unnamed: L10.1, U21.10
unnamed: L11.2, U21.6
unnamed: L13.1, Q4.3
unnamed: P6.1, U4.26
unnamed: P7.1, U4.16
unnamed: P17.1, U4.9
unnamed: P19.1, U4.25
unnamed: P24.1, U23.29
unnamed: R4.2, U4.4
unnamed: R19.2, R49.2, SW2.2
unnamed: R7.1, R30.2, SW1.2
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

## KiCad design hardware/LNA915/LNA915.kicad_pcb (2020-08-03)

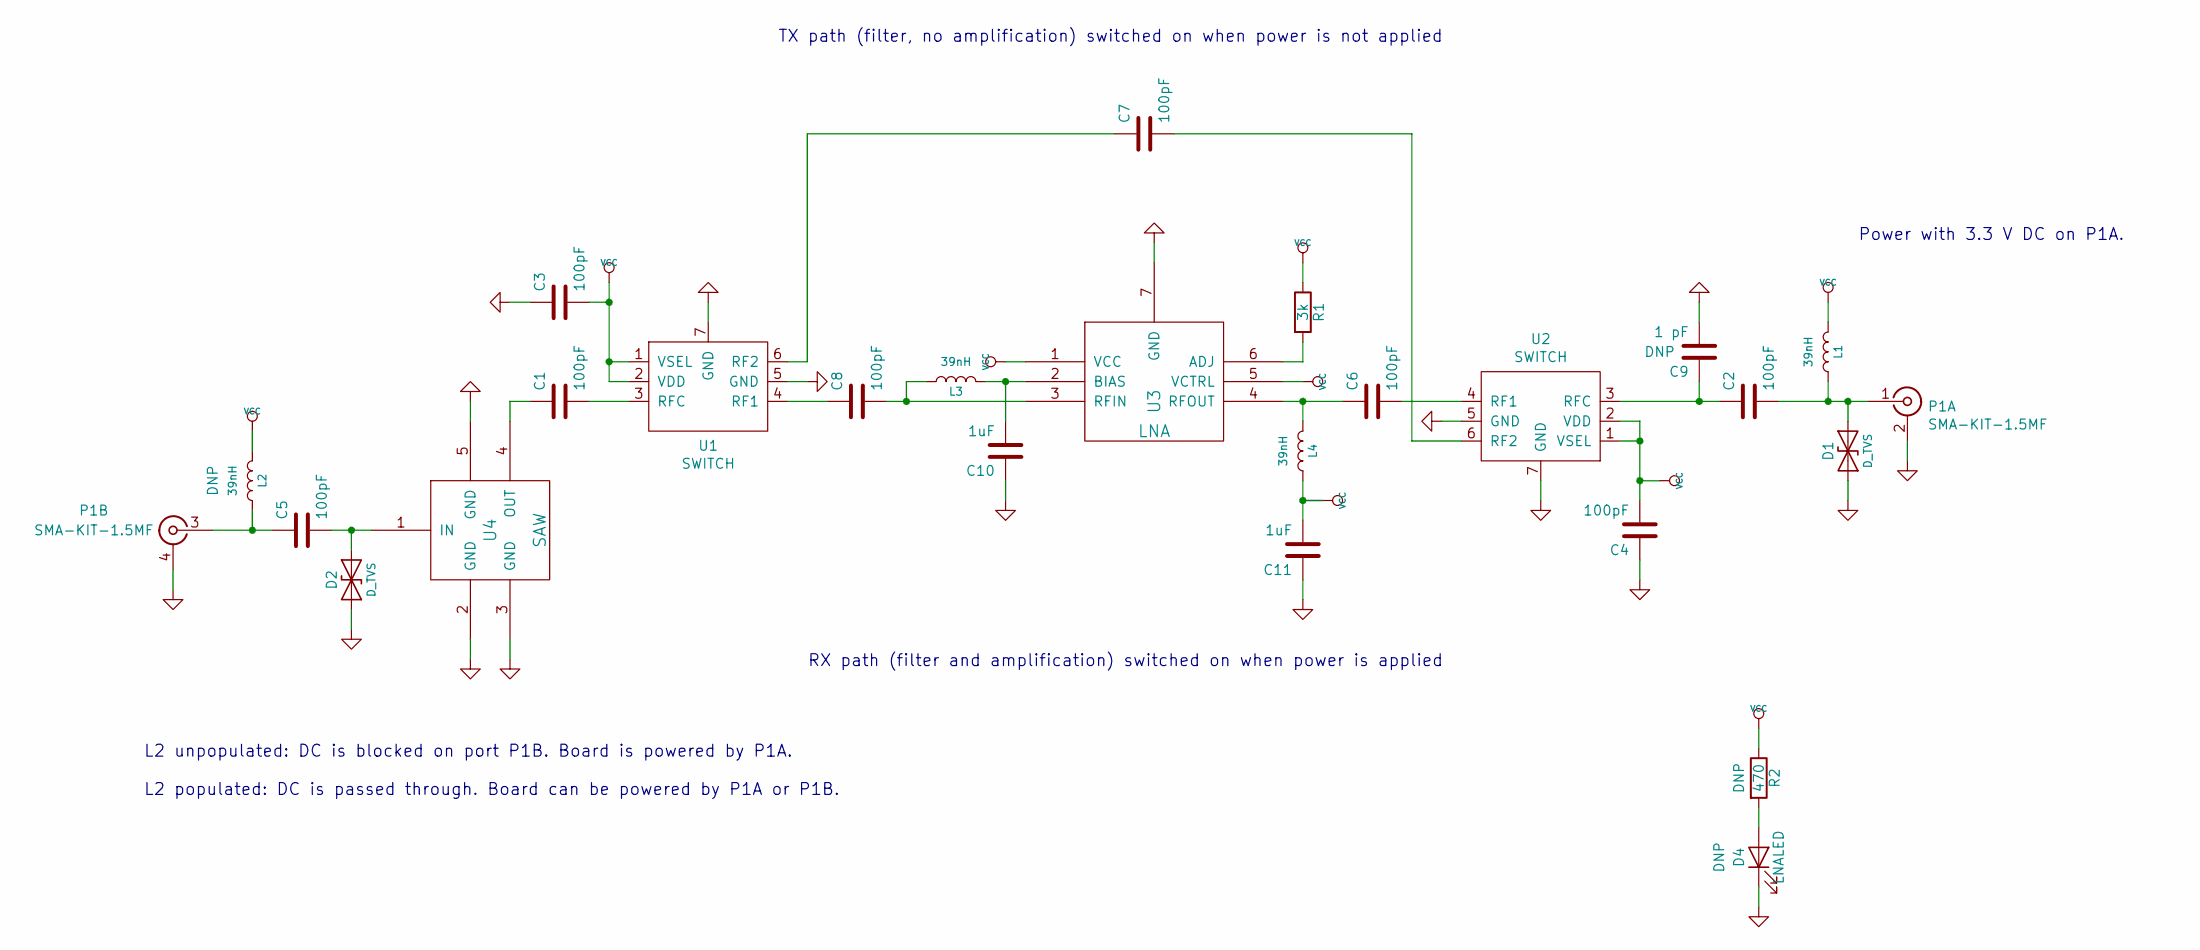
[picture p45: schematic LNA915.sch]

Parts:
C1, C2, C3, C4, C5, C6, C7, C8: 100pF; 0402; Part Number GCM1555C1H101JA16
C9: 1 pF; 0402
C10, C11: 1uF; 0402; Part Number LMK105BJ105KV-F
D1, D2: D_TVS; 0402; Part Number LXES15AAA1-153
D4: LNALED; 0402
L1, L2, L3, L4: 39nH; 0402; Part Number HK100539NJ-T
P1: SMA-KIT-1.5MF; Part Number SMA-KIT-1.5MF
R1: 3k; 0402; Part Number RMCF0402FT3K00
R2: 470; 0402; Part Number RMCF0402JT470R
U1, U2: SWITCH; GRF6011; Part Number GRF6011
U3: LNA; TSLP-7-1; Part Number BGB 741L7ESD E6327
U4: SAW; F5Q; Part Number FAR-F5QA-915M00-M2AK-J

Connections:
GND: C3.1, C4.1, C9.2, C10.1, C11.1, D1.1 (A1), D2.1 (A1), D4.1 (K), P1.2 (SHIELD), P1.4 (SHIELD), U1.5 (GND), U1.7 (GND), U2.5 (GND), U2.7 (GND), U3.7 (GND), U4.2 (GND), U4.3 (GND), U4.5 (GND)
unnamed: C1.1, U4.4 (OUT)
unnamed: C1.2, U1.3 (RFC)
unnamed: C2.1, C9.1, U2.3 (RFC)
unnamed: C2.2, D1.2 (A2), L1.1, P1.1 (RF)
unnamed: C5.1, L2.1, P1.3 (RF)
unnamed: C5.2, D2.2 (A2), U4.1 (IN)
unnamed: C6.1, L4.2, U3.4 (RFOUT)
unnamed: C6.2, U2.4 (RF1)
unnamed: C7.1, U1.6 (RF2)
unnamed: C7.2, U2.6 (RF2)
unnamed: C8.1, U1.4 (RF1)
unnamed: C8.2, L3.1, U3.3 (RFIN)
unnamed: C10.2, L3.2, U3.2 (BIAS)
unnamed: D4.2 (A), R2.2
unnamed: R1.2, U3.6 (ADJ)
VCC: C3.2, C4.2, C11.2, L1.2, L2.2, L4.1, R1.1, R2.1, U1.1 (VSEL), U1.2 (VDD), U2.1 (VSEL), U2.2 (VDD), U3.1 (VCC), U3.5 (VCTRL)

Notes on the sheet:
Power with 3.3 V DC on P1A.
TX path (filter, no amplification) switched on when power is not applied
RX path (filter and amplification) switched on when power is applied
L2 unpopulated: DC is blocked on port P1B. Board is powered by P1A. L2 populated: DC is passed through. Board can be powered by P1A or P1B.

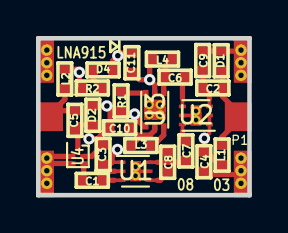
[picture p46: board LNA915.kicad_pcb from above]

Board: 4 copper layers, 11.7 x 8.7 mm, 25 parts (0 on the bottom side), 17 nets.

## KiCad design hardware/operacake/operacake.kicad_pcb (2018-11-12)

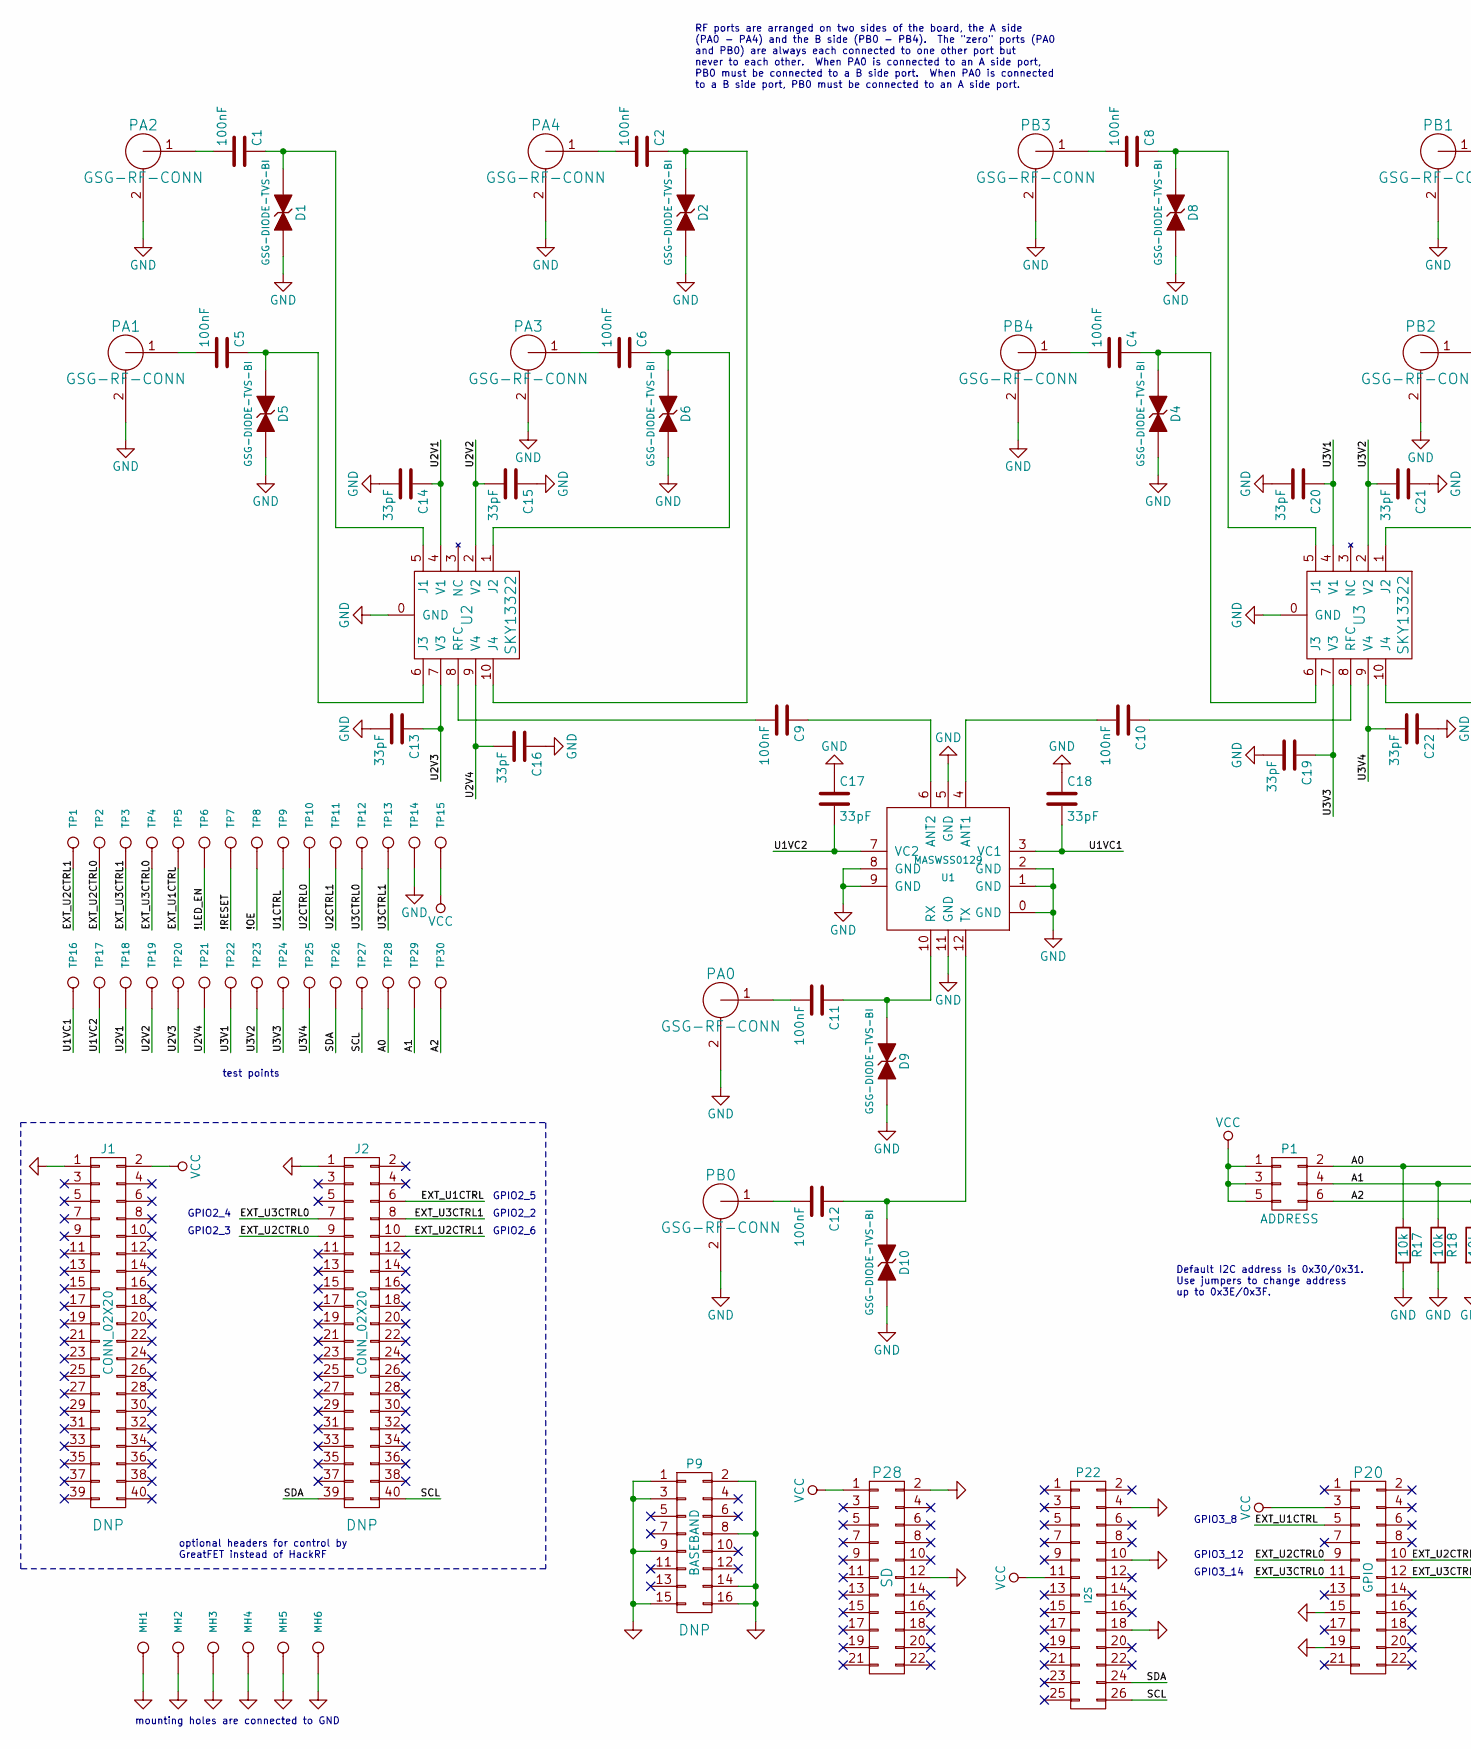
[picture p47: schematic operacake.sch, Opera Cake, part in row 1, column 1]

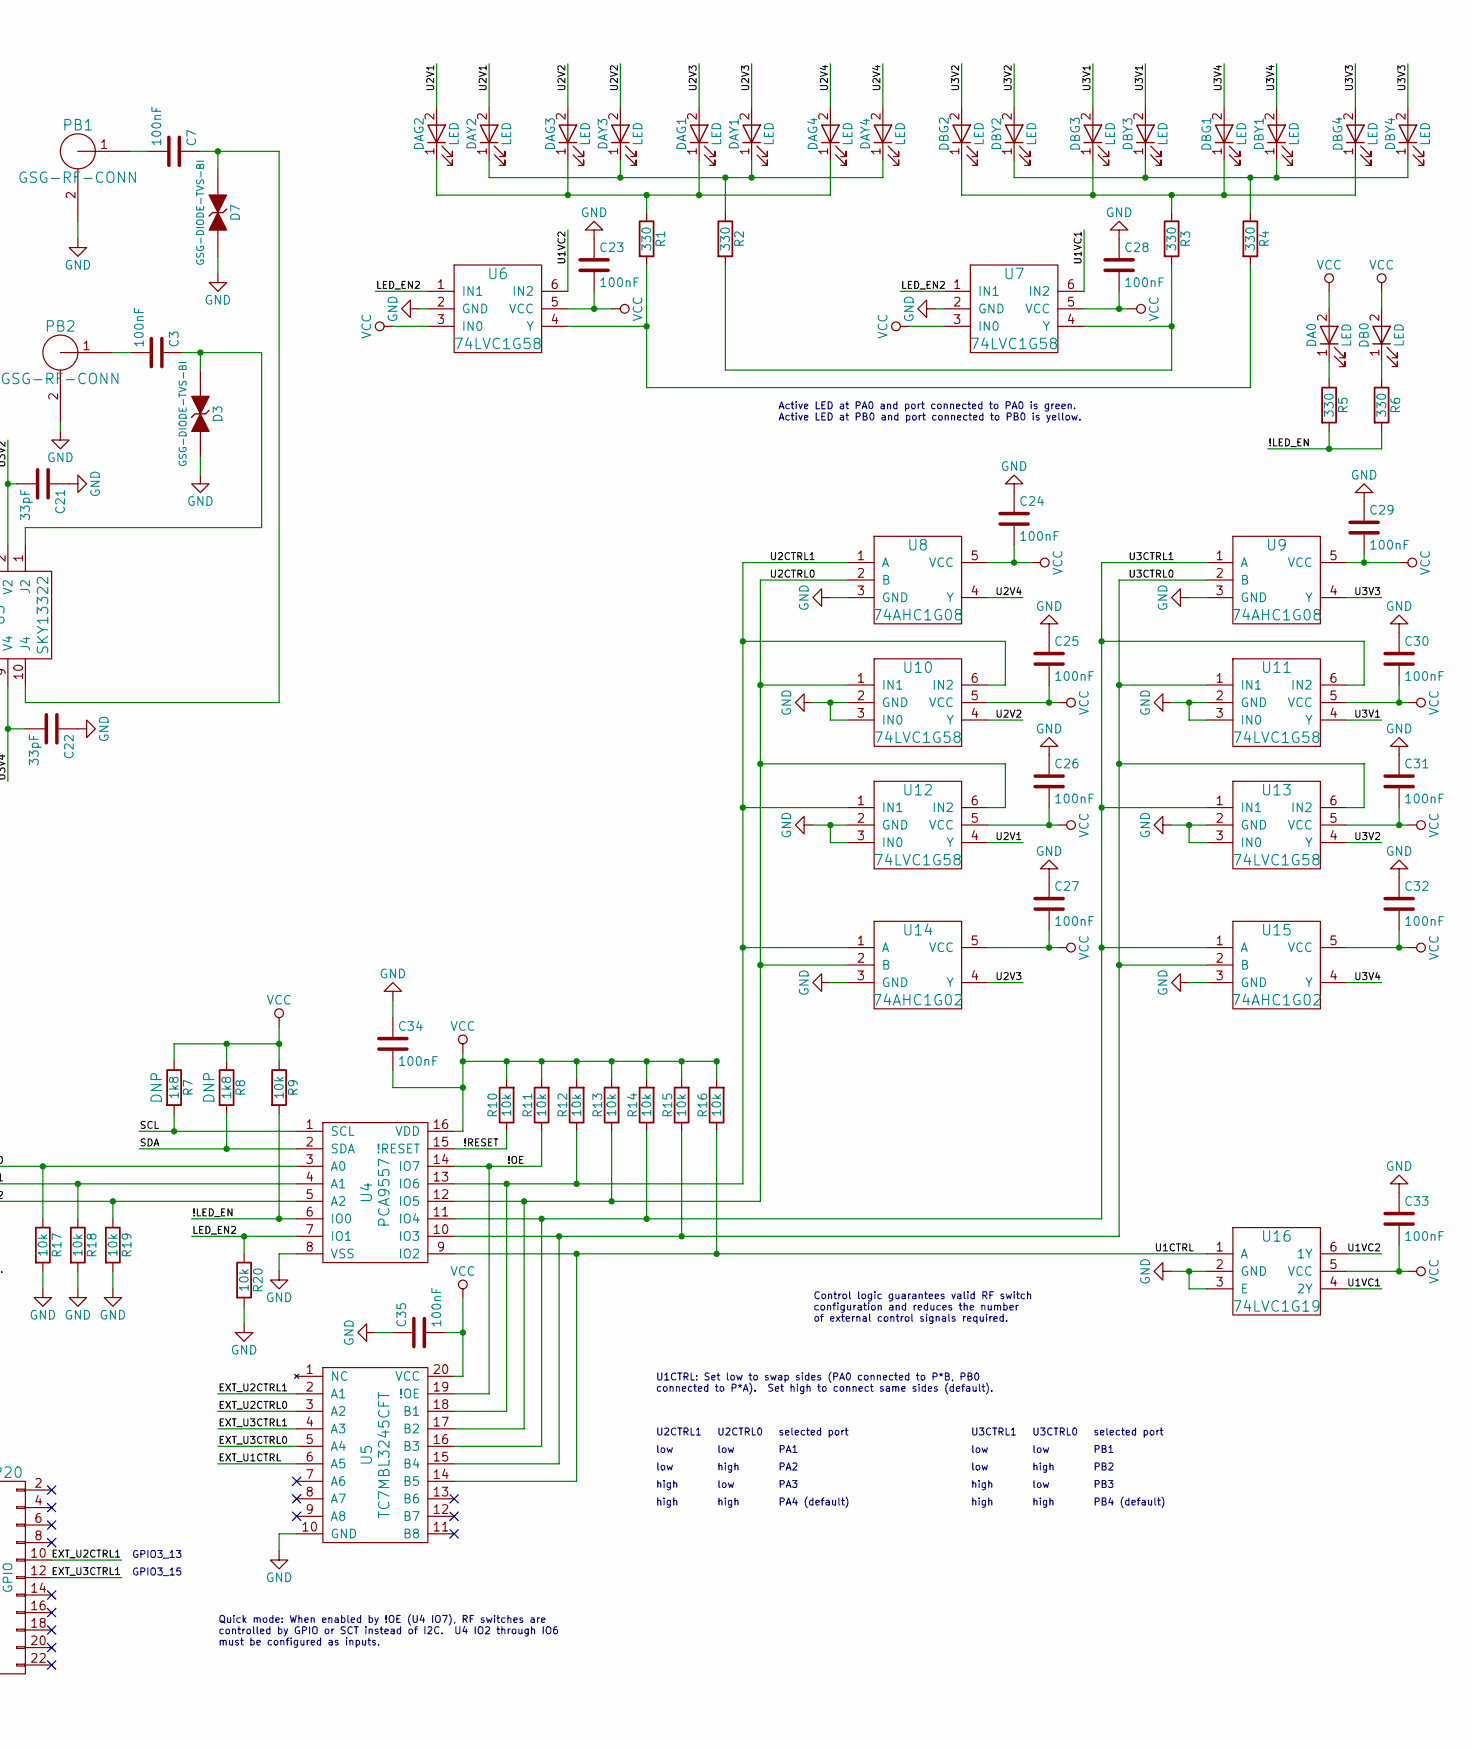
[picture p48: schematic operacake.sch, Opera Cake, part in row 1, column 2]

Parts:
C1, C2, C3, C4, C5, C6, C7, C8, C9, C10, C11, C12, C23, C24, C25, C26, C27, C28, C29, C30, C31, C32, C33, C34, C35: 100nF; 0402; Part Number GRM155R61A104KA01D
C13, C14, C15, C16, C17, C18, C19, C20, C21, C22: 33pF; 0402; Part Number GRM1555C1H330JA01D
D1, D2, D3, D4, D5, D6, D7, D8, D9, D10: GSG-DIODE-TVS-BI; 0402; Part Number LXES15AAA1-153
DA0: LED; 0603D; Part Number SML-LX0603GW-TR
DAG1, DAG2, DAG3, DAG4: LED; 0603D; Part Number SML-LX0603GW-TR
DAY1, DAY2, DAY3, DAY4: LED; 0603D; Part Number SML-LX0603YW-TR
DB0: LED; 0603D; Part Number SML-LX0603YW-TR
DBG1, DBG2, DBG3, DBG4: LED; 0603D; Part Number SML-LX0603GW-TR
DBY1, DBY2, DBY3, DBY4: LED; 0603D; Part Number SML-LX0603YW-TR
J1, J2: CONN_02X20; HEADER-2x20-REVERSE
MH1, MH2, MH3, MH4, MH5, MH6: MOUNTING_HOLE; HOLE126MIL-COPPER
P1: ADDRESS; HEADER-2x3; Part Number XG8T-0631
P9: BASEBAND; HEADER-2x8; Part Number SSQ-108-03-G-D
P20: GPIO; HEADER-2x11; Part Number SSQ-111-03-G-D
P22: I2S; HEADER-2x13; Part Number SSQ-113-03-G-D
P28: SD; HEADER-2x11; Part Number SSQ-111-03-G-D
PA0, PA1, PA2, PA3, PA4: GSG-RF-CONN; GSG-SMA-73251-2120; Part Number 73251-2121
PB0, PB1, PB2, PB3, PB4: GSG-RF-CONN; GSG-SMA-73251-2120; Part Number 73251-2121
R1, R2, R3, R4, R5, R6: 330; 0603; Part Number RMCF0603JT330R
R7, R8: 1k8; 0603
R9, R10, R11, R12, R13, R14, R15, R16, R17, R18, R19, R20: 10k; 0603; Part Number ERJ-3GEYJ103V
TP1, TP2, TP3, TP4, TP5, TP6, TP7, TP8, TP9, TP10, TP11, TP12, TP13, TP14, TP15, TP16, TP17, TP18, TP19, TP20, TP21, TP22, TP23, TP24, TP25, TP26, TP27, TP28, TP29, TP30: CONN_1; TESTPOINT-50MIL
U1: MASWSS0129; QFN12-3; Part Number MASWSS0129TR-3000
U2, U3: SKY13322; SKY13322-375LF; Part Number SKY13322-375LF
U4: PCA9557; TSSOP16; Part Number PCA9557PW,118
U5: TC7MBL3245CFT; TSSOP20; Part Number TC7MBL3245CFT(EL)
U6, U7, U10, U11, U12, U13: 74LVC1G58; SOT363; Part Number 74LVC1G58DW-7
U8, U9: 74AHC1G08; SOT353-1; Part Number 74AHC1G08SE-7
U14, U15: 74AHC1G02; SOT353-1; Part Number 74AHC1G02SE-7
U16: 74LVC1G19; SOT363; Part Number 74LVC1G19GW,125

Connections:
/!LED_EN: R5.2, R6.2, R9.2, TP6.1, U4.6 (IO0)
/!OE: R11.1, TP8.1, U4.14 (IO7), U5.19 (!OE)
/!RESET: R10.1, TP7.1, U4.15 (!RESET)
/A0: P1.2, R17.1, TP28.1, U4.3 (A0)
/A1: P1.4, R18.1, TP29.1, U4.4 (A1)
/A2: P1.6, R19.1, TP30.1, U4.5 (A2)
/EXT_U1CTRL: J2.6, P20.5, TP5.1, U5.6 (A5)
/EXT_U2CTRL0: J2.9, P20.9, TP2.1, U5.3 (A2)
/EXT_U2CTRL1: J2.10, P20.10, TP1.1, U5.2 (A1)
/EXT_U3CTRL0: J2.7, P20.11, TP4.1, U5.5 (A4)
/EXT_U3CTRL1: J2.8, P20.12, TP3.1, U5.4 (A3)
/LED_EN2: R20.1, U4.7 (IO1), U6.1 (IN1), U7.1 (IN1)
/SCL: J2.40, P22.26, R7.2, TP27.1, U4.1 (SCL)
/SDA: J2.39, P22.24, R8.2, TP26.1, U4.2 (SDA)
/U1CTRL: R16.1, TP9.1, U4.9 (IO2), U5.14 (B5), U16.1 (A)
/U1VC1: C18.2, TP16.1, U1.3 (VC1), U7.6 (IN2), U16.4 (2Y)
/U1VC2: C17.2, TP17.1, U1.7 (VC2), U6.6 (IN2), U16.6 (1Y)
/U2CTRL0: R13.1, TP10.1, U4.12 (IO5), U5.17 (B2), U8.2 (B), U10.1 (IN1), U12.6 (IN2), U14.2 (B)
/U2CTRL1: R12.1, TP11.1, U4.13 (IO6), U5.18 (B1), U8.1 (A), U10.6 (IN2), U12.1 (IN1), U14.1 (A)
/U2V1: C14.1, DAG2.2 (A), DAY2.2 (A), TP18.1, U2.4 (V1), U12.4 (Y)
/U2V2: C15.2, DAG3.2 (A), DAY3.2 (A), TP19.1, U2.2 (V2), U10.4 (Y)
/U2V3: C13.1, DAG1.2 (A), DAY1.2 (A), TP20.1, U2.7 (V3), U14.4 (Y)
/U2V4: C16.2, DAG4.2 (A), DAY4.2 (A), TP21.1, U2.9 (V4), U8.4 (Y)
/U3CTRL0: R15.1, TP12.1, U4.10 (IO3), U5.15 (B4), U9.2 (B), U11.1 (IN1), U13.6 (IN2), U15.2 (B)
/U3CTRL1: R14.1, TP13.1, U4.11 (IO4), U5.16 (B3), U9.1 (A), U11.6 (IN2), U13.1 (IN1), U15.1 (A)
/U3V1: C20.1, DBG3.2 (A), DBY3.2 (A), TP22.1, U3.4 (V1), U11.4 (Y)
/U3V2: C21.2, DBG2.2 (A), DBY2.2 (A), TP23.1, U3.2 (V2), U13.4 (Y)
/U3V3: C19.1, DBG4.2 (A), DBY4.2 (A), TP24.1, U3.7 (V3), U9.4 (Y)
/U3V4: C22.2, DBG1.2 (A), DBY1.2 (A), TP25.1, U3.9 (V4), U15.4 (Y)
GND: C13.2, C14.2, C15.1, C16.1, C17.1, C18.1, C19.2, C20.2, C21.1, C22.1, C23.1, C24.1, C25.1, C26.1, C27.1, C28.1, C29.1, C30.1, C31.1, C32.1, C33.1, C34.1, C35.1, D1.2 (K), D2.2 (K), D3.2 (K), D4.2 (K), D5.2 (K), D6.2 (K), D7.2 (K), D8.2 (K), D9.2 (K), D10.2 (K), J1.1, J2.1, MH1.1, MH2.1, MH3.1, MH4.1, MH5.1, MH6.1, P9.1, P9.2, P9.3, P9.8, P9.9, P9.14, P9.15, P9.16, P20.15, P20.19, P22.4, P22.10, P22.18, P28.2, P28.12, PA0.2 (GND), PA1.2 (GND), PA2.2 (GND), PA3.2 (GND), PA4.2 (GND), PB0.2 (GND), PB1.2 (GND), PB2.2 (GND), PB3.2 (GND), PB4.2 (GND), R17.2, R18.2, R19.2, R20.2, TP14.1, U1.0 (GND), U1.1 (GND), U1.2 (GND), U1.5 (GND), U1.8 (GND), U1.9 (GND), U1.11 (GND), U2.0 (GND), U3.0 (GND), U4.8 (VSS), U5.10 (GND), U6.2 (GND), U7.2 (GND), U8.3 (GND), U9.3 (GND), U10.2 (GND), U10.3 (IN0), U11.2 (GND), U11.3 (IN0), U12.2 (GND), U12.3 (IN0), U13.2 (GND), U13.3 (IN0), U14.3 (GND), U15.3 (GND), U16.2 (GND), U16.3 (E)
unnamed: C1.1, D1.1 (A), U2.5 (J1)
unnamed: C1.2, PA2.1 (RF)
unnamed: C2.1, D2.1 (A), U2.10 (J4)
unnamed: C2.2, PA4.1 (RF)
unnamed: C3.1, D3.1 (A), U3.1 (J2)
unnamed: C3.2, PB2.1 (RF)
unnamed: C4.1, D4.1 (A), U3.6 (J3)
unnamed: C4.2, PB4.1 (RF)
unnamed: C5.1, D5.1 (A), U2.6 (J3)
unnamed: C5.2, PA1.1 (RF)
unnamed: C6.1, D6.1 (A), U2.1 (J2)
unnamed: C6.2, PA3.1 (RF)
unnamed: C7.1, D7.1 (A), U3.10 (J4)
unnamed: C7.2, PB1.1 (RF)
unnamed: C8.1, D8.1 (A), U3.5 (J1)
unnamed: C8.2, PB3.1 (RF)
unnamed: C9.1, U1.6 (ANT2)
unnamed: C9.2, U2.8 (RFC)
unnamed: C10.1, U3.8 (RFC)
unnamed: C10.2, U1.4 (ANT1)
unnamed: C11.1, D9.1 (A), U1.10 (RX)
unnamed: C11.2, PA0.1 (RF)
unnamed: C12.1, D10.1 (A), U1.12 (TX)
unnamed: C12.2, PB0.1 (RF)
unnamed: DA0.1 (K), R5.1
unnamed: DAG1.1 (K), DAG2.1 (K), DAG3.1 (K), DAG4.1 (K), R1.1
unnamed: DAY1.1 (K), DAY2.1 (K), DAY3.1 (K), DAY4.1 (K), R2.1
unnamed: DB0.1 (K), R6.1
unnamed: DBG1.1 (K), DBG2.1 (K), DBG3.1 (K), DBG4.1 (K), R3.1
unnamed: DBY1.1 (K), DBY2.1 (K), DBY3.1 (K), DBY4.1 (K), R4.1
unnamed: R1.2, R4.2, U6.4 (Y)
unnamed: R2.2, R3.2, U7.4 (Y)
VCC: C23.2, C24.2, C25.2, C26.2, C27.2, C28.2, C29.2, C30.2, C31.2, C32.2, C33.2, C34.2, C35.2, DA0.2 (A), DB0.2 (A), J1.2, P1.1, P1.3, P1.5, P20.3, P22.11, P28.1, R7.1, R8.1, R9.1, R10.2, R11.2, R12.2, R13.2, R14.2, R15.2, R16.2, TP15.1, U4.16 (VDD), U5.20 (VCC), U6.3 (IN0), U6.5 (VCC), U7.3 (IN0), U7.5 (VCC), U8.5 (VCC), U9.5 (VCC), U10.5 (VCC), U11.5 (VCC), U12.5 (VCC), U13.5 (VCC), U14.5 (VCC), U15.5 (VCC), U16.5 (VCC)

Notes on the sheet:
mounting holes are connected to GND
test points
Quick mode: When enabled by !OE (U4 IO7), RF switches are controlled by GPIO or SCT instead of I2C. U4 IO2 through IO6 must be configured as inputs.
Control logic guarantees valid RF switch configuration and reduces the number of external control signals required.
Active LED at PA0 and port connected to PA0 is green. Active LED at PB0 and port connected to PB0 is yellow.
Default I2C address is 0x30/0x31. Use jumpers to change address up to 0x3E/0x3F.
optional headers for control by GreatFET instead of HackRF
GPIO3_13
GPIO3_15
GPIO3_12
GPIO3_14
GPIO3_8
GPIO2_5
GPIO2_4
GPIO2_2
GPIO2_6
GPIO2_3
RF ports are arranged on two sides of the board, the A side (PA0 - PA4) and the B side (PB0 - PB4). The "zero" ports (PA0 and PB0) are always each connected to one other port but never to each other. When PA0 is connected to an A side port, PB0 must be connected to a B side port. When PA0 is connec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
U1CTRL: Set low to swap sides (PA0 connected to P*B, PB0 connected to P*A). Set high to connect same sides (default).
U2CTRL1
U2CTRL0
selected port
low
high
PA1
PA2
PA3
PA4 (default)
U3CTRL1
U3CTRL0
PB1
PB2
PB3
PB4 (default)

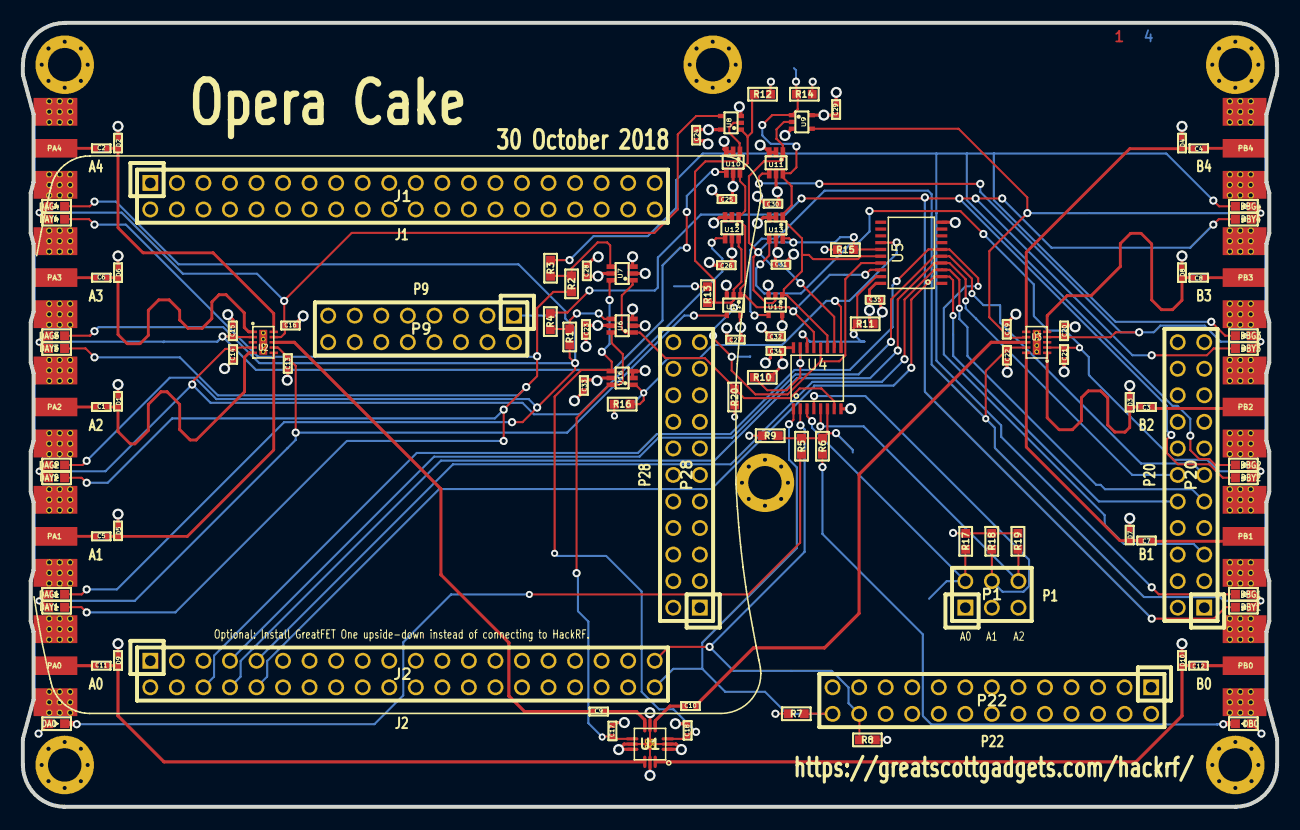
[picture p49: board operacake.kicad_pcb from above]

Board: 4 copper layers, 120.0 x 75.0 mm, 152 parts (0 on the bottom side), 63 nets.

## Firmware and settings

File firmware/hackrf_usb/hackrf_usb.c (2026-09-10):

/*
 * Copyright 2012-2026 Great Scott Gadgets <info@greatscottgadgets.com>
 * Copyright 2012 Jared Boone
 * Copyright 2013 Benjamin Vernoux
 *
 * This file is part of HackRF.
 *
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
 * You should have received a copy of the GNU General Public License
 * along with this program; see the file COPYING.  If not, write to
 * the Free Software Foundation, Inc., 51 Franklin Street,
 * Boston, MA 02110-1301, USA.
 */

#include <stdbool.h>
#include <stdint.h>
#include <string.h>

#include <libopencm3/cm3/nvic.h>
#include <libopencm3/lpc43xx/ipc.h>

#include <clock_gen.h>
#include <clock_io.h>
#include <cpld_jtag.h>
#include <cpu_clock.h>
#include <da7219.h>
#include <delay.h>
#include <fixed_point.h>
#include <hackrf_ui.h>
#include <i2c_bus.h>
#include <i2c_lpc.h>
#include <leds.h>
#include <operacake.h>
#include <mixer.h>
#include <pins.h>
#include <platform_detect.h>
#include <power.h>
#include <radio.h>
#include <rf_path.h>
#include <rom_iap.h>
#include <selftest.h>
#include <sgpio.h>
#include <transceiver_mode.h>
#include <tuning.h>
#include <usb.h>
#include <usb_queue.h>
#include <usb_request.h>
#include <usb_standard_request.h>
#include <usb_type.h>
#ifdef IS_EXPANSION_COMPATIBLE
	#include <portapack.h>
#endif
#ifdef IS_NOT_RAD1O
	#include <rffc5071.h>
#endif
#ifdef IS_PRALINE
	#include <fpga.h>
	#if !(defined(DFU_MODE) || defined(RAM_MODE))
		#include <lz4_buf.h>
		#include <spi_bus.h>
		#include <w25q80bv.h>
	#endif
#endif

#include "usb_api_adc.h"
#include "usb_api_board_info.h"
#include "usb_api_m0_state.h"
#include "usb_api_operacake.h"
#include "usb_api_radio.h"
#include "usb_api_register.h"
#include "usb_api_selftest.h"
#include "usb_api_spiflash.h"
#include "usb_api_sweep.h"
#include "usb_api_transceiver.h"
#include "usb_api_ui.h"
#include "usb_descriptor.h"
#include "usb_device.h"
#include "usb_endpoint.h"
#ifdef IS_PRALINE
	#include "usb_api_praline.h"
#endif
#ifdef IS_NOT_PRALINE
	#include "usb_api_cpld.h"
#endif

extern uint32_t __m0_start__;
extern uint32_t __m0_end__;
extern uint32_t __ram_m0_start__;
extern uint32_t __rtconfig_start__;
extern uint32_t __rtconfig_end__;
extern uint32_t __ram_rtconfig_start__;
extern uint32_t _etext_ram, _text_ram, _etext_rom;

static usb_request_handler_fn vendor_request_handler[] = {
	NULL,
	usb_vendor_request_set_transceiver_mode,
	usb_vendor_request_write_max283x,
	usb_vendor_request_read_max283x,
	usb_vendor_request_write_si5351c,
	usb_vendor_request_read_si5351c,
	usb_vendor_request_set_sample_rate_frac,
	usb_vendor_request_set_baseband_filter_bandwidth,
#ifdef IS_NOT_RAD1O
	usb_vendor_request_write_rffc5071,
	usb_vendor_request_read_rffc5071,
#else
	NULL, // write_rffc5071 not used
	NULL, // read_rffc5071 not used
#endif
	usb_vendor_request_erase_spiflash,
	usb_vendor_request_write_spiflash,
	usb_vendor_request_read_spiflash,
	NULL, // used to be write_cpld
	usb_vendor_request_read_board_id,
	usb_vendor_request_read_version_string,
	usb_vendor_request_set_freq,
	usb_vendor_request_set_amp_enable,
	usb_vendor_request_read_partid_serialno,
	usb_vendor_request_set_lna_gain,
	usb_vendor_request_set_vga_gain,
	usb_vendor_request_set_txvga_gain,
	NULL, // was set_if_freq
#if defined(IS_HACKRF_ONE) || defined(IS_PRALINE)
	usb_vendor_request_set_antenna_enable,
#else
	NULL,
#endif
	usb_vendor_request_set_freq_explicit,
	usb_vendor_request_read_wcid, // USB_WCID_VENDOR_REQ
	usb_vendor_request_init_sweep,
	usb_vendor_request_operacake_get_boards,
	usb_vendor_request_operacake_set_ports,
	usb_vendor_request_set_hw_sync_mode,
	usb_vendor_request_reset,
	usb_vendor_request_operacake_set_ranges,
	usb_vendor_request_set_clkout_enable,
	usb_vendor_request_spiflash_status,
	usb_vendor_request_spiflash_clear_status,
	usb_vendor_request_operacake_gpio_test,
#ifdef IS_HACKRF_ONE
	usb_vendor_request_cpld_checksum,
#else
	NULL,
#endif
	usb_vendor_request_set_ui_enable,
	usb_vendor_request_operacake_set_mode,
	usb_vendor_request_operacake_get_mode,
	usb_vendor_request_operacake_set_dwell_times,
	usb_vendor_request_get_m0_state,
	usb_vendor_request_set_tx_underrun_limit,
	usb_vendor_request_set_rx_overrun_limit,
	usb_vendor_request_get_clkin_status,
	usb_vendor_request_read_board_rev,
	usb_vendor_request_read_supported_platform,
	usb_vendor_request_set_leds,
	usb_vendor_request_user_config_set_bias_t_opts,
#ifdef IS_PRALINE
	usb_vendor_request_write_fpga_reg,
	usb_vendor_request_read_fpga_reg,
	usb_vendor_request_p2_ctrl,
	usb_vendor_request_p1_ctrl,
	usb_vendor_request_set_narrowband_filter,
	usb_vendor_request_set_fpga_bitstream,
	usb_vendor_request_clkin_ctrl,
#else
	NULL,
	NULL,
	NULL,
	NULL,
	NULL,
	NULL,
	NULL,
#endif
	usb_vendor_request_read_selftest,
	usb_vendor_request_adc_read,
	usb_vendor_request_test_rtc_osc,
	usb_vendor_request_write_radio_reg,
	usb_vendor_request_read_radio_reg,
	usb_vendor_request_get_buffer_size,
	usb_vendor_request_read_temperature,
	usb_vendor_request_lock_radio_reg,
	usb_vendor_request_open,
	usb_vendor_request_close,
	usb_vendor_request_set_radio_mode,
	usb_vendor_request_set_radio_frequency,
	usb_vendor_request_set_radio_frequency_explicit,
	usb_vendor_request_set_radio_sample_rate,
};

static const uint32_t vendor_request_handler_count =
	sizeof(vendor_request_handler) / sizeof(vendor_request_handler[0]);

usb_request_status_t usb_vendor_request(
	usb_endpoint_t* const endpoint,
	const usb_transfer_stage_t stage)
{
	usb_request_status_t status = USB_REQUEST_STATUS_STALL;

	if (endpoint->setup.request < vendor_request_handler_count) {
		usb_request_handler_fn handler =
			vendor_request_handler[endpoint->setup.request];
		if (handler) {
			status = handler(endpoint, stage);
		}
	}

	return status;
}

const usb_request_handlers_t usb_request_handlers = {
	.standard = usb_standard_request,
	.class = 0,
	.vendor = usb_vendor_request,
	.reserved = 0,
};

void usb_configuration_changed(usb_device_t* const device)
{
	/* Reset transceiver to idle state until other commands are received */
	request_transceiver_mode(TRANSCEIVER_MODE_OFF);
	if (device->configuration->number == 1) {
		// transceiver configuration
		led_on(LED1);
	} else {
		/* Configuration number equal 0 means usb bus reset. */
		led_off(LED1);
	}
	usb_endpoint_init(&usb_endpoint_bulk_in, false);
	usb_endpoint_init(&usb_endpoint_bulk_out, false);
}

void usb_set_descriptor_by_serial_number(void)
{
	iap_cmd_res_t iap_cmd_res;

	/* Read IAP Serial Number Identification */
	iap_cmd_res.cmd_param.command_code = IAP_CMD_READ_SERIAL_NO;
	iap_cmd_call(&iap_cmd_res);

	if (iap_cmd_res.status_res.status_ret == CMD_SUCCESS) {
		usb_descriptor_string_serial_number[0] =
			USB_DESCRIPTOR_STRING_SERIAL_BUF_LEN;
		usb_descriptor_string_serial_number[1] = USB_DESCRIPTOR_TYPE_STRING;

		/* 32 characters of serial number, convert to UTF-16LE */
		for (size_t i = 0; i < USB_DESCRIPTOR_STRING_SERIAL_LEN; i++) {
			const uint_fast8_t nibble =
				(iap_cmd_res.status_res.iap_result[i >> 3] >>
				 (28 - (i & 7) * 4)) &
				0xf;
			const char c =
				(nibble > 9) ? ('a' + nibble - 10) : ('0' + nibble);
			usb_descriptor_string_serial_number[2 + i * 2] = c;
			usb_descriptor_string_serial_number[3 + i * 2] = 0x00;
		}
	} else {
		usb_descriptor_string_serial_number[0] = 2;
		usb_descriptor_string_serial_number[1] = USB_DESCRIPTOR_TYPE_STRING;
	}
}

static void m0_rom_to_ram(void)
{
	uint32_t* dest = &__ram_m0_start__;

	// Calculate the base address of ROM
	uint32_t base = (uint32_t) (&_etext_rom - (&_etext_ram - &_text_ram));

	// M0 image location, relative to the start of ROM
	uint32_t src = (uint32_t) &__m0_start__;

	uint32_t len = (uint32_t) &__m0_end__ - (uint32_t) src;
	memcpy(dest, (uint32_t*) (base + src), len);
}

static void rtconfig_rom_to_ram(void)
{
	uint32_t* dest = &__ram_rtconfig_start__;

	// Calculate the base address of ROM
	uint32_t base = (uint32_t) (&_etext_rom - (&_etext_ram - &_text_ram));

	// rtconfig image location, relative to the start of ROM
	uint32_t src = (uint32_t) &__rtconfig_start__;

	uint32_t len = (uint32_t) &__rtconfig_end__ - (uint32_t) src;
	memcpy(dest, (uint32_t*) (base + src), len);
}

#if defined(IS_PRALINE) && !(defined(DFU_MODE) || defined(RAM_MODE))
extern uint32_t _binary_fpga_bin_start;

void fpga_loader_setup(void)
{
	w25q80bv_setup(&spi_flash);
}

void fpga_loader_read(uint32_t addr, uint32_t size, uint8_t* buf)
{
	w25q80bv_read(&spi_flash, addr, size, buf);
}

struct fpga_loader_t fpga_loader = {
	.start_addr = (uint32_t) &_binary_fpga_bin_start,
	.setup = fpga_loader_setup,
	.read = fpga_loader_read,
	.in_buffer = lz4_in_buf,
	.out_buffer = lz4_out_buf,
};
#endif

void radio_changed(const uint32_t changed)
{
	const uint64_t opmode = radio_reg_read(&radio, RADIO_BANK_APPLIED, RADIO_OPMODE);

	if (changed & (1 << RADIO_OPMODE)) {
		switch (opmode) {
		case TRANSCEIVER_MODE_TX:
		case TRANSCEIVER_MODE_SS:
			sgpio_configure(&sgpio_config, SGPIO_DIRECTION_TX);
			hackrf_ui()->set_direction(RF_PATH_DIRECTION_TX);
			break;
		case TRANSCEIVER_MODE_RX:
		case TRANSCEIVER_MODE_RX_SWEEP:
			sgpio_configure(&sgpio_config, SGPIO_DIRECTION_RX);
			hackrf_ui()->set_direction(RF_PATH_DIRECTION_RX);
			break;
		default:
			sgpio_configure(&sgpio_config, SGPIO_DIRECTION_RX);
			hackrf_ui()->set_direction(RF_PATH_DIRECTION_OFF);
			break;
		}
	}
	if (changed & (1 << RADIO_SAMPLE_RATE)) {
		const uint64_t rate =
			radio_reg_read(&radio, RADIO_BANK_APPLIED, RADIO_SAMPLE_RATE);
		hackrf_ui()->set_sample_rate(rate / SR_FP_ONE_HZ);
	}
	if (changed & (RADIO_REG_GROUP_FREQ)) {
		const uint64_t img_reject =
			radio_reg_read(&radio, RADIO_BANK_APPLIED, RADIO_IMAGE_REJECT);
		const uint64_t freq_lo =
			radio_reg_read(&radio, RADIO_BANK_APPLIED, RADIO_FREQUENCY_LO);
		const uint64_t freq_if =
			radio_reg_read(&radio, RADIO_BANK_APPLIED, RADIO_FREQUENCY_IF);
		const bool invert_spectrum =
			((img_reject == RF_PATH_FILTER_LOW_PASS) && (freq_lo > freq_if));
		sgpio_cpld_set_mixer_invert(&sgpio_config, invert_spectrum);
	}
	if (changed & (1 << RADIO_FREQUENCY_RF)) {
		const uint64_t freq =
			radio_reg_read(&radio, RADIO_BANK_APPLIED, RADIO_FREQUENCY_RF);
		if (opmode != TRANSCEIVER_MODE_RX_SWEEP) {
			hackrf_ui()->set_frequency(freq / FP_ONE_HZ);
		}
#ifdef IS_EXPANSION_COMPATIBLE
		if (IS_EXPANSION_COMPATIBLE) {
			operacake_set_range(freq / FP_ONE_MHZ);
		}
#endif
	}
	if (changed & (1 << RADIO_IMAGE_REJECT)) {
		if (opmode != TRANSCEIVER_MODE_RX_SWEEP) {
			const uint64_t img_reject = radio_reg_read(
				&radio,
				RADIO_BANK_APPLIED,
				RADIO_IMAGE_REJECT);
			hackrf_ui()->set_filter(img_reject);
		}
	}
	if (changed &
	    ((1 << RADIO_BB_BANDWIDTH_TX) | (1 << RADIO_BB_BANDWIDTH_RX) |
	     (1 << RADIO_OPMODE))) {
		uint64_t bw;

		switch (opmode) {
		case TRANSCEIVER_MODE_TX:
		case TRANSCEIVER_MODE_SS:
			bw = radio_reg_read(
				&radio,
				RADIO_BANK_APPLIED,
				RADIO_BB_BANDWIDTH_TX);
			break;
		default:
			bw = radio_reg_read(
				&radio,
				RADIO_BANK_APPLIED,
				RADIO_BB_BANDWIDTH_RX);
		}
		hackrf_ui()->set_filter_bw(bw);
	}
	if (changed &
	    ((1 << RADIO_GAIN_TX_RF) | (1 << RADIO_GAIN_RX_RF) | (1 << RADIO_OPMODE))) {
		const uint64_t tx_rf =
			radio_reg_read(&radio, RADIO_BANK_APPLIED, RADIO_GAIN_TX_RF);
		const uint64_t rx_rf =
			radio_reg_read(&radio, RADIO_BANK_APPLIED, RADIO_GAIN_RX_RF);
		bool enable;

		switch (opmode) {
		case TRANSCEIVER_MODE_TX:
		case TRANSCEIVER_MODE_SS:
			enable = tx_rf;
			break;
		case TRANSCEIVER_MODE_RX:
		case TRANSCEIVER_MODE_RX_SWEEP:
			enable = rx_rf;
			break;
		default:
			enable = false;
		}
		hackrf_ui()->set_lna_power(enable);
	}
	if (changed & (1 << RADIO_GAIN_TX_IF)) {
		const uint64_t tx_if =
			radio_reg_read(&radio, RADIO_BANK_APPLIED, RADIO_GAIN_TX_IF);
		hackrf_ui()->set_bb_tx_vga_gain(tx_if);
	}
	if (changed & (1 << RADIO_GAIN_RX_IF)) {
		const uint64_t rx_if =
			radio_reg_read(&radio, RADIO_BANK_APPLIED, RADIO_GAIN_RX_IF);
		hackrf_ui()->set_bb_lna_gain(rx_if);
	}
	if (changed & (1 << RADIO_GAIN_RX_BB)) {
		const uint64_t rx_bb =
			radio_reg_read(&radio, RADIO_BANK_APPLIED, RADIO_GAIN_RX_BB);
		hackrf_ui()->set_bb_vga_gain(rx_bb);
	}
	if (changed & (1 << RADIO_BIAS_TEE)) {
		const uint64_t enable =
			radio_reg_read(&radio, RADIO_BANK_APPLIED, RADIO_BIAS_TEE);
		hackrf_ui()->set_antenna_bias(enable);
	}
}

int main(void)
{
	// Copy M0 image from ROM before SPIFI is disabled
	m0_rom_to_ram();

	// Copy rtconfig image from ROM before SPIFI is disabled
	rtconfig_rom_to_ram();

	// This will be cleared if any self-test check fails.
	selftest.report.pass = true;

	// Detect hardware platform before we do anything else.
	detect_hardware_platform();
	board_id_t board_id = detected_platform();

	i2c_bus_start(&i2c0, &i2c_config_fast_clock);

	pins_shutdown();
	sgpio_pin_shutdown(&sgpio_config);
	rf_path_pin_shutdown();
	if (board_id != BOARD_ID_RAD1O) {
		clock_gen_shutdown();
	}
	delay_ms(10);
	pins_setup();
	cpld_jtag_pin_setup();
	mixer_bus_setup(&mixer);
	sgpio_configure_pin_functions(&sgpio_config);
	rf_path_pin_setup(&rf_path);
#ifdef IS_PRALINE
	if (IS_PRALINE) {
		enable_3v3aux_power();
	#if !defined(DFU_MODE) && !defined(RAM_MODE)
		enable_1v2_power();
		enable_rf_power();
		/*
		 * On Praline, the clock generator power supply comes from 3V3FPGA
		 * which is enabled when 1V2FPGA is turned on.
		 */
		clock_gen_init();
	#endif
	}
#endif
#ifdef IS_NOT_PRALINE
	if (IS_NOT_PRALINE) {
		enable_1v8_power();
	#ifdef IS_NOT_RAD1O
		if (IS_NOT_RAD1O) {
			/*
			 * On rad1o, the clock generator power supply comes from the RF supply
			 * which is enabled later. On H1 and Jawbreaker, the clock generator is
			 * on the main 3V3 supply.
			 */
			clock_gen_init();
		}
	#endif
	}
#endif
	tuning_setup();
#ifdef IS_HACKRF_ONE
	if (IS_HACKRF_ONE) {
		// Set up mixer before enabling RF power, because its
		// GPO is used to control the antenna bias tee.
		mixer_setup(&mixer, RFFC5071_VARIANT);
	}
#endif
#ifdef IS_H1_OR_RAD1O
	if (IS_H1_OR_RAD1O) {
		enable_rf_power();
	}
#endif
#ifdef IS_RAD1O
	if (IS_RAD1O) {
		clock_gen_init();
	}
#endif
	cpu_clock_init();

	/* Clock speed has changed, adjust I2C clock */
	i2c_bus_start(&i2c0, &i2c_config_fast_clock);

	/* Wake the M0 */
	ipc_halt_m0();
	ipc_start_m0((uint32_t) &__ram_m0_start__);

#ifdef IS_NOT_PRALINE
	if (IS_NOT_PRALINE) {
		if (!cpld_jtag_sram_load(&jtag_cpld)) {
			halt_and_flash(1000);
		}
	}
#endif
#ifdef IS_PRALINE
	if (IS_PRALINE) {
	#if defined(DFU_MODE) || defined(RAM_MODE)
		selftest.fpga_image_load = SKIPPED;
		selftest.report.pass = false;
	#else
		fpga_image_load(&fpga_loader, 0);
	#endif
		delay_us(100);
		fpga_spi_selftest();
		fpga_sgpio_selftest();
	}
#endif

	radio.update_cb = radio_changed;
	radio_init(&radio);

#ifdef IS_EXPANSION_COMPATIBLE
	if (IS_EXPANSION_COMPATIBLE) {
		portapack_init();
	}
#endif

#ifndef DFU_MODE
	usb_set_descriptor_by_serial_number();
#endif

	usb_set_configuration_changed_cb(usb_configuration_changed);
	usb_peripheral_reset();

#ifdef IS_HACKRF_ONE
	if (IS_HACKRF_ONE) {
		memcpy(&usb_device,
		       &usb_device_hackrf_one,
		       sizeof(usb_device_hackrf_one));
	}
#endif
#ifdef IS_JAWBREAKER
	if (IS_JAWBREAKER) {
		memcpy(&usb_device,
		       &usb_device_jawbreaker,
		       sizeof(usb_device_jawbreaker));
	}
#endif
#ifdef IS_RAD1O
	if (IS_RAD1O) {
		memcpy(&usb_device, &usb_device_rad1o, sizeof(usb_device_rad1o));
	}
#endif
#ifdef IS_PRALINE
	if (IS_PRALINE) {
		memcpy(&usb_device, &usb_device_praline, sizeof(usb_device_praline));
	}
#endif
	usb_device_init(0, &usb_device);

	usb_queue_init(&usb_endpoint_control_out_queue);
	usb_queue_init(&usb_endpoint_control_in_queue);
	usb_queue_init(&usb_endpoint_bulk_out_queue);
	usb_queue_init(&usb_endpoint_bulk_in_queue);

	usb_endpoint_init(&usb_endpoint_control_out, false);
	usb_endpoint_init(&usb_endpoint_control_in, true);

	nvic_set_priority(NVIC_USB0_IRQ, 255);

	hackrf_ui()->init();

	usb_run(&usb_device);

	rf_path_init(&rf_path);

#ifdef IS_NOT_RAD1O
	rffc5071_lock_test(&mixer.rffc5071);
#endif

#ifdef IS_PRALINE
	if (IS_PRALINE) {
		fpga_if_xcvr_selftest();
	}
#endif

	if (da7219_detect()) {
		operacake_skip_i2c_address(DA7219_ADDRESS);
	}
	bool operacake_allow_gpio;
	if (hackrf_ui()->operacake_gpio_compatible()) {
		operacake_allow_gpio = true;
	} else {
		operacake_allow_gpio = false;
	}
	operacake_init(operacake_allow_gpio);

	// FIXME: clock detection on r9 only works when calling init twice
	if (detected_platform() == BOARD_ID_HACKRF1_R9) {
		clkin_detect_init();
		clkin_detect_init();
	}

	while (true) {
		transceiver_request_t request;

		// Briefly disable USB interrupt so that we can
		// atomically retrieve both the transceiver mode
		// and the mode change sequence number. They are
		// changed together by request_transceiver_mode()
		// called from the USB ISR.

		nvic_disable_irq(NVIC_USB0_IRQ);
		request = transceiver_request;
		nvic_enable_irq(NVIC_USB0_IRQ);
		radio_update(&radio);

		switch (request.mode) {
		case TRANSCEIVER_MODE_OFF:
			off_mode(request.seq);
			break;
		case TRANSCEIVER_MODE_RX:
			rx_mode(request.seq);
			break;
		case TRANSCEIVER_MODE_TX:
			tx_mode(request.seq);
			break;
		case TRANSCEIVER_MODE_RX_SWEEP:
			sweep_mode(request.seq);
			break;
		case TRANSCEIVER_MODE_CPLD_UPDATE:
#ifdef IS_NOT_PRALINE
			if (IS_NOT_PRALINE) {
				cpld_update();
			}
#endif
			break;
		default:
			break;
		}
	}

	return 0;
}

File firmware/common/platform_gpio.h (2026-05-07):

/*
 * Copyright 2012-2026 Great Scott Gadgets <info@greatscottgadgets.com>
 *
 * This file is part of HackRF.
 *
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
 * You should have received a copy of the GNU General Public License
 * along with this program; see the file COPYING.  If not, write to
 * the Free Software Foundation, Inc., 51 Franklin Street,
 * Boston, MA 02110-1301, USA.
 */

#pragma once

#ifdef __cplusplus
extern "C" {
#endif

#include "gpio.h"
#include "gpio_lpc.h"

typedef struct {
	/* LEDs */
#ifdef IS_FOUR_LEDS
	gpio_t led[4];
#else
	gpio_t led[3];
#endif

	/* Power Supply Control */
	gpio_t gpio_1v8_enable;
#ifdef IS_PRALINE
	gpio_t gpio_1v2_enable;
	gpio_t gpio_3v3aux_enable_n;
#endif

	/* MAX283x GPIO (XCVR_CTL / CS_XCVR) PinMux */
	gpio_t max283x_select;
	gpio_t max283x_enable;
	gpio_t max283x_rx_enable;
	gpio_t max283x_tx_enable;
#ifdef IS_PRALINE
	gpio_t max2831_rxhp;
	gpio_t max2831_ld;
#endif

	/* MAX5864 SPI chip select (AD_CS / CS_AD) GPIO PinMux */
	gpio_t max5864_select;

	/* RF supply (VAA) control */
	gpio_t vaa_disable;
#ifdef IS_RAD1O
	gpio_t vaa_enable;
#endif

	/* W25Q80BV Flash */
	gpio_t w25q80bv_hold;
	gpio_t w25q80bv_wp;
	gpio_t w25q80bv_select;

	/* RF switch control */
#ifdef IS_HACKRF_ONE
	gpio_t hp;
	gpio_t lp;
	gpio_t tx_mix_bp;
	gpio_t no_mix_bypass;
	gpio_t rx_mix_bp;
	gpio_t tx_amp;
	gpio_t tx;
	gpio_t mix_bypass;
	gpio_t rx;
	gpio_t no_tx_amp_pwr;
	gpio_t amp_bypass;
	gpio_t rx_amp;
	gpio_t no_rx_amp_pwr;
	gpio_t h1r9_no_ant_pwr; // HACKRF_ONE r9
	gpio_t h1r9_rx;         // HACKRF_ONE r9
#endif
#ifdef IS_RAD1O
	gpio_t tx_rx_n;
	gpio_t tx_rx;
	gpio_t by_mix;
	gpio_t by_mix_n;
	gpio_t by_amp;
	gpio_t by_amp_n;
	gpio_t mixer_en;
	gpio_t low_high_filt;
	gpio_t low_high_filt_n;
	gpio_t tx_amp;
	gpio_t rx_lna;
#endif
#ifdef IS_PRALINE
	gpio_t tx_en;
	gpio_t mix_en_n;
	gpio_t mix_en_n_r1_0;
	gpio_t lpf_en;
	gpio_t rf_amp_en;
	gpio_t ant_bias_en_n;
#endif

	/* CPLD JTAG interface GPIO pins, FPGA config pins in Praline */
	gpio_t cpld_tck;
#ifdef IS_NOT_PRALINE
	gpio_t cpld_tdo;
	gpio_t cpld_tms;
	gpio_t cpld_tdi;
#endif
#ifdef IS_EXPANSION_COMPATIBLE
	gpio_t cpld_pp_tms;
	gpio_t cpld_pp_tdo;
#endif
#ifdef IS_PRALINE
	gpio_t fpga_cfg_creset;
	gpio_t fpga_cfg_cdone;
	gpio_t fpga_cfg_spi_cs;
#endif

	/* Other CPLD interface GPIO pins */
#ifdef IS_NOT_PRALINE
	gpio_t trigger_enable;
#endif
	gpio_t q_invert;

	/* RFFC5071 GPIO serial interface PinMux */
	gpio_t rffc5072_select;
	gpio_t rffc5072_clock;
	gpio_t rffc5072_data;
	gpio_t rffc5072_reset;
	gpio_t rffc5072_ld;   // PRALINE
	gpio_t rffc5072_enbl; // PRALINE
	gpio_t vco_ce;        // RAD1O
	gpio_t vco_sclk;      // RAD1O
	gpio_t vco_sdata;     // RAD1O
	gpio_t vco_le;        // RAD1O
	gpio_t vco_mux;       // RAD1O
	gpio_t synt_rfout_en; // RAD1O

	/* Praline */
#ifdef IS_PRALINE
	gpio_t p2_ctrl0;
	gpio_t p2_ctrl1;
	gpio_t p1_ctrl0;
	gpio_t p1_ctrl1;
	gpio_t p1_ctrl2;
	gpio_t clkin_ctrl;
	gpio_t aa_en;
	gpio_t trigger_in;
	gpio_t trigger_out;
	gpio_t pps_out;
#endif

#ifdef IS_HACKRF_ONE
	/* HackRF One r9 clock control */
	gpio_t h1r9_clkin_en;
	gpio_t h1r9_clkout_en;
	gpio_t h1r9_mcu_clk_en;

	gpio_t h1r9_1v8_enable;
	gpio_t h1r9_vaa_disable;
	gpio_t h1r9_trigger_enable;
#endif

	/* RAD1O */
#ifdef IS_RAD1O
	gpio_t lcd_cs;
	gpio_t lcd_bl_en;
	gpio_t lcd_reset;
#endif

	/* Portapack */
#ifdef IS_EXPANSION_COMPATIBLE
	gpio_t io_stbx;
	gpio_t addr;
	gpio_t lcd_rdx;
	gpio_t lcd_wrx;
	gpio_t dir;
#endif
} platform_gpio_t;

// Detects and returns the global platform gpio instance of the active board id and revision.
const platform_gpio_t* platform_gpio(void);

/* LPC43xx GPIO pre-declarations - we use these instead of the GPIO()
   macro so that we can assign them at runtime. */
static const struct gpio GPIO0_0 = GPIO(0, 0);
static const struct gpio GPIO0_1 = GPIO(0, 1);
static const struct gpio GPIO0_2 = GPIO(0, 2);
static const struct gpio GPIO0_3 = GPIO(0, 3);
static const struct gpio GPIO0_4 = GPIO(0, 4);
static const struct gpio GPIO0_5 = GPIO(0, 5);
static const struct gpio GPIO0_6 = GPIO(0, 6);
static const struct gpio GPIO0_7 = GPIO(0, 7);
static const struct gpio GPIO0_8 = GPIO(0, 8);
static const struct gpio GPIO0_9 = GPIO(0, 9);
static const struct gpio GPIO0_10 = GPIO(0, 10);
static const struct gpio GPIO0_11 = GPIO(0, 11);
static const struct gpio GPIO0_12 = GPIO(0, 12);
static const struct gpio GPIO0_13 = GPIO(0, 13);
static const struct gpio GPIO0_14 = GPIO(0, 14);
static const struct gpio GPIO0_15 = GPIO(0, 15);

static const struct gpio GPIO1_0 = GPIO(1, 0);
static const struct gpio GPIO1_1 = GPIO(1, 1);
static const struct gpio GPIO1_2 = GPIO(1, 2);
static const struct gpio GPIO1_3 = GPIO(1, 3);
static const struct gpio GPIO1_4 = GPIO(1, 4);
static const struct gpio GPIO1_5 = GPIO(1, 5);
static const struct gpio GPIO1_6 = GPIO(1, 6);
static const struct gpio GPIO1_7 = GPIO(1, 7);
static const struct gpio GPIO1_8 = GPIO(1, 8);
static const struct gpio GPIO1_9 = GPIO(1, 9);
static const struct gpio GPIO1_10 = GPIO(1, 10);
static const struct gpio GPIO1_11 = GPIO(1, 11);
static const struct gpio GPIO1_12 = GPIO(1, 12);
static const struct gpio GPIO1_13 = GPIO(1, 13);
static const struct gpio GPIO1_14 = GPIO(1, 14);
static const struct gpio GPIO1_15 = GPIO(1, 15);

static const struct gpio GPIO2_0 = GPIO(2, 0);
static const struct gpio GPIO2_1 = GPIO(2, 1);
static const struct gpio GPIO2_2 = GPIO(2, 2);
static const struct gpio GPIO2_3 = GPIO(2, 3);
static const struct gpio GPIO2_4 = GPIO(2, 4);
static const struct gpio GPIO2_5 = GPIO(2, 5);
static const struct gpio GPIO2_6 = GPIO(2, 6);
static const struct gpio GPIO2_7 = GPIO(2, 7);
static const struct gpio GPIO2_8 = GPIO(2, 8);
static const struct gpio GPIO2_9 = GPIO(2, 9);
static const struct gpio GPIO2_10 = GPIO(2, 10);
static const struct gpio GPIO2_11 = GPIO(2, 11);
static const struct gpio GPIO2_12 = GPIO(2, 12);
static const struct gpio GPIO2_13 = GPIO(2, 13);
static const struct gpio GPIO2_14 = GPIO(2, 14);
static const struct gpio GPIO2_15 = GPIO(2, 15);

static const struct gpio GPIO3_0 = GPIO(3, 0);
static const struct gpio GPIO3_1 = GPIO(3, 1);
static const struct gpio GPIO3_2 = GPIO(3, 2);
static const struct gpio GPIO3_3 = GPIO(3, 3);
static const struct gpio GPIO3_4 = GPIO(3, 4);
static const struct gpio GPIO3_5 = GPIO(3, 5);
static const struct gpio GPIO3_6 = GPIO(3, 6);
static const struct gpio GPIO3_7 = GPIO(3, 7);
static const struct gpio GPIO3_8 = GPIO(3, 8);
static const struct gpio GPIO3_9 = GPIO(3, 9);
static const struct gpio GPIO3_10 = GPIO(3, 10);
static const struct gpio GPIO3_11 = GPIO(3, 11);
static const struct gpio GPIO3_12 = GPIO(3, 12);
static const struct gpio GPIO3_13 = GPIO(3, 13);
static const struct gpio GPIO3_14 = GPIO(3, 14);
static const struct gpio GPIO3_15 = GPIO(3, 15);
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

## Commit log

2017-02-19 fix(rad1o): Restore old clock behaviour for now.
    [hackrf_core.c]
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2017-02-22 Change RFFC5071 clock from 40MHz to 50MHz and invert it Now the MAX2837 and RFFC5071 clocks are out of phase with each other Hopefully this reduces some noise
    [hackrf_core.c]
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2017-02-28 Power down CLK3 (CLKOUT) at boot, don't reset it when clocks are reset
    [hackrf_core.c]
2017-05-16 Hardware (CPLD-based) synchronisation =======================================
    This commit allows to synchronise multiple HackRFs with a synchronisation error **below 1 sampling period**
    > WARNING: Use this at your own risk. If you don't know what you are doing you may damage your HackRF.
    > The author takes no responsability for potential damages
    Usage example: synchronise two HackRFs
    ======================================
    1. Chose the master HackRF which will send the synchronisation pulse (HackRF0). HackRF1 will represent the slave hackrf.
    2. Retreive the serial number of both HackRFs using `hackrf_info`
    3. Use a wire to connect `SYNC_CMD` of HackRF0 to `SYNC_IN` of HackRF0 and HackRF1
    4.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
    [hackrf_core.c, sgpio.c]
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2017-05-19 Avoid hackrf-transfer to abort if no samples are received within one second, when hardware sync mode is enabled.
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2017-08-05 fix(rad1o): TX_RX_N is on GPIO1_11
    [hackrf_core.c]
2017-08-09 Add check for correct firmware when flashing to a devices
    It's using the product string for now, but there are other
    things that we could check too. Use -i to ignore the check.
    rad1o badge will always pass the check because it uses
    "HackRF" as the product string, whichis a substring of both
    other devices..
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2017-10-18 Fixed unconnected traces
    [operacake.kicad_pcb]
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2017-12-07 libhackrf: counts the open devices, prevents exit if not all closed
    fixes #435, osmosdr calls hackrf_exit for the last sink and the last
    source. If both are in one flow graph the desctructor of the source
    fails as the sink already closed the usb context.
    This prevents hackrf_exit to close the context if not all devices are closed
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2018-01-28 eliminated minor glitch caused by enabling a GPIO output before setting its value
    [hackrf_core.c]
2018-01-28 short pulses when enabling VAA to avoid a big voltage glitch
    [hackrf_core.c]
2018-02-17 libhackrf: stop_tx() put HackRF in to idle mode before killing transfer thread This is what we do for RX and appears to prevent HackRF remaining in TX mode. This mirrors commit 693c262
2018-02-27 Open device counting: increment when opening a device Previously it incremented when the library was initialised, this worked for GNU Radio flowgraphs, but broke elsewhere
2018-02-28 HackRF One: replaced U20 with Winbond W25Q80JVSSIQ
    [mcu.sch]
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2018-03-28 DFU serial number - avoid reading serial from flash chip Set a DFU mode specific serial number
    [hackrf_usb.c]
2018-04-14 replaced Murata LXES1TBCC2-004 (End of Life) with Vishay VBUS54CV-HSF-G4-08 (U15)
    [mcu.sch]
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2018-04-14 replaced AVX/Kyocera 2500BL14M100T (NRND) with Abracon ABM8-25.000MHZ-10-D1G-T (X1), added load capacitors (C169 and C170)
    [baseband.sch]
2018-05-01 HackRF One: replaced U20 with Winbond W25Q80DVSSIG
    [baseband.sch, frontend.sch, hackrf-one.kicad_pcb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]
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2018-12-06 Add Windows build art(e|i)facts (#561)
    This includes:
    * Cmake clean up - thanks @Qyriad
    * Windows binaries saved after each appveyor build
    * A bump to the Visual Studio version that we use to build it
    * An appveyor cygwin script for building firmware, it doesn't work but it seems like someone might pick it up and make it work, or blow it away if we switch to Travis firmware artefacts
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2018-12-21 Travis artefacts (#564)
    * Try artefacts deployed to gh_pages
    * Try to use gh_pages from the travis_artefacts branch
    * Try deploying to a different repo
    * Try to organise files deployed to github pages
    * Test pushing a local dir to master
    * Try pushing to original repo
    * Be verbose so I can debug it
    * Setting env variables
    * Oops, environment variables aren't what I thought
    * Try to push to nightly repo
    * Remove unused cp command
    * Copy firmware to archive directory
    * Fix pathing to artefacts
    * Use TRAVIS_BUID_DIR instead of assuming path
    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
2018-12-28 Pin setup: Make GPIO direction reset the *first* step.
    [hackrf_core.c]
2018-12-28 Set VAA_ENABLE# state before setting GPIO to output.
    ...to avoid glitching the output voltage.
    [hackrf_core.c]
2018-12-28 Set 1V8 enable state before configuring pin function or to output mode
    ...to avoid glitching 1V8 enable voltage.
    [hackrf_core.c]
2018-12-28 Pin setup: Break out JTAG configuration, rework to consider PortaPack.
    [cpld_jtag.c, hackrf_core.c]
2018-12-28 I2C: Device probe function I wrote, didn't need, but thought might be useful in the future.
    [i2c_lpc.c]
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2019-01-03 Fix communications failures on USB suspend. (#97)
    Linux issues a `GET_STATUS` request to validate that a USB device has
    correctly resumed after an idle suspend; but HackRF has thus far not
    implemented `GET_STATUS`. As a result, Linux assumes our USB devices
    are failing to resume, and winds up resetting them. Oops. ^-^
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2019-01-15 PortaPack: Replace OperaCake handlers, they were tripping up host tools. Skip operacake_init if PortaPack compiled in, letting operacake_boards be all zero. Should be safe, right?
    [hackrf_usb.c]
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2019-01-19 CPLD: Rework timing between ADC, CPLD, SGPIO
    Capture ADC and codec clock state with sufficient timing margin.
    Increase drive strength on codec clock and invert CPLD capture clock to provide margin for capturing codec clock (I vs. Q channel).
    [sgpio.c]
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2019-03-02 LED: Refactor halt function from CPLD update to core API.
    Also call if CPLD load fails.
    [hackrf_core.c, hackrf_usb.c]
2019-03-02 UI: Move ui_portapack.* to common.
    Otherwise blinky won't build.
    TODO: Tried to tease apart all the dependencies to get blinky to build without, but it's such a twisted knot...
2019-03-02 PortaPack: Remove conditional PortaPack code.
    TODO: DFU mode returns. I fear HackRF mode in PortaPack/HAVOC will not work.
    [cpld_jtag.c, hackrf_core.c]
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2019-03-03 Build rad1o UI wrapper to patch the portapack one
    Also, fix building of blinky.
    [hackrf_usb.c]
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2019-03-07 Fix mismatched ifdefs of my making
    [hackrf_core.c]
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2019-10-30 replaced acrylic case .dxf file with rev2 .dxf file
    [HackRF_One_Case.dxf, HackRF_One_Case_v2.dxf]
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2020-01-06 Modified hackrf_stop_tx and hackrf_stop_rx to first join the transfer thread before setting the receiver to OFF mode (cf. issue #650)
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2020-01-20 cpld/sgpio_debug: Add TX/RX counters to check SGPIO
    For RX, this replaces received samples with an 8-bit incrementing counter.
    This allows for identification of any dropped or repeated samples across the
    SGPIO interface.
    For TX, this compares transmitted samples against another 8-bit incrementing
    counter, and raises pin B2AUX1 if they don't match. This should be used with
    a tool on the host-side that transmits a matching counter.
2020-01-22 remove specific sample rate recommendations HackRF One supports arbitrary sample rates from 2 Msps to 20 Msps. In early development we had ideas about preferred sample rates that we no longer conside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
2020-01-22 Fix Operacake GPIO mode initialisation
    [hackrf_usb.c]
2020-01-22 Add option to disable HackRF UI
    Fixes #608
    [hackrf_usb.c]
2020-02-10 Don't re-init bulk endpoints on every set_transceiver_mode call
    Previously the firmware would re-initialise the bulk endpoints on
    every transceiver mode change including a USB data toggle reset,
    which could cause the first bulk packet (512-bytes) to be dropped
    by the host if the PID no longer matched.
    [hackrf_usb.c]
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2020-06-21 LNA915: correct minor layout errors
    [LNA915.kicad_pcb]
2020-06-23 LNA915: redesign around GRF6011 failsafe switch
    fits in SMA-KIT-1.5MF inline SMA enclosure
    [LNA915.kicad_pcb, LNA915.sch]
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2020-10-13 HackRF One: replace obsolete SKY13350-385LF RF switch with SKY13453-385LF
    [baseband.sch, frontend.sch, hackrf-one.kicad_pcb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]
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2020-11-09 Fix libusb usage for at least freebsd around the worker thread and transfer cancellation
    On at least freebsd-13 trying to cancel a transfer whilst the libusb thread
    is not running results in the transfers not completing cancellation.
    The next time they're attempted to be re-added the libusb code thinks
    they're still active, and returns BUSY on the buffers.
    This causes gqrx to error out when one makes DSP changes or stops/starts it.
    You have to restart gqrx to fix it.
    After digging into it a bit, the libusb code expects that you're actively
    running the main loop in order to have some deferred actions run in the
    context of said main loop thread. This includes processing cancelled
    transfers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
2020-11-09 Fix streaming hangs in consumers
    * Update device->streaming to reflect whether we're streaming data,
    rather than just whether the streaming thread is active.
    The streaming thread is now always active!
2020-11-09 add 10ms sleep after stop
    This seems to stop consumers that are doing quick back to back stop/start
    (eg gqrx changing decode mode / filter bandwidth) from hanging the
    device.
    I now don't have any weird hangs on hackrf with gqrx/freebsd/libusb!
    When things hang it isn't erroring out in any way; it just doesn't
    start receive. It doesn't look like a libusb issue; I'd have to get
    some USB bus sniffing to see what's going on behind the scenes.
2020-12-10 Handle hackrf_close() being called without TX or RX being started.
    My previous commits didn't handle the specific case of hackrf_close()
    being called without the transfers being active.
    In this instance the transfers haven't been setup, so calling
    cancel_transfers() returned an error.
    Instead:
    * refactor out the tx/rx stop command from canceling transfers
    * send the tx/rx stop command without canceling transfers, since ..
    * ... we can then destroy the transfer thread.
    I may also need to put an explicit cancel_transfers() before the
    call to send the tx/rx stop commands; I'll look at doing that
    in a subsequent commit.
2021-03-17 Disable USB interrupts during sweep set_freq call
    Previously, a USB vendor request could interrupt in the middle of
    set_freq and make conflicting changes, leaving the HackRF in an
    undefined state.
    fixes #772
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2021-03-18 hackrf_sweep: switch main loop timing back to 1Hz
    fixes #850
    fixes #851
2021-06-13 Report amplitude once per second during receive (#890)
    * Report amplitude once per second during receive
    * Added missing M_LN10 for Windoze, fixed short frame detection for RSSI
    * Tweaks to math expressions
    * Tweaks to math expressions
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2021-10-06 Copy M0 image directly from ROM, instead of shadow region.
    This changes m0_rom_to_ram to read directly from the ROM region, rather
    than copying from where .text has been copied to RAM.
    Previously the second .text section would be merged with the first one,
    so the M0 image would be copied to RAM during `pre_main`. However, on
    newer linkers the sections are not merged together so the second .text
    section did not get copied to RAM.
    fixes #936
    [hackrf_usb.c]
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2021-11-14 hackrf_sweep: eliminate time stamp adjustment
    We previously attempted to adjust the output time stamp according to the
    sample rate and placement of the samples within the USB transfer data,
    but the end result was a fixed time offset with respect to the time of
    USB transfer completion. We are using only those samples closest to the
    end of the transfer, so it makes sense to simply use the time the USB
    transfer ends and not try to correct that fixed offset.
    It may be possible in the future to have a more accurate time stamp
    generated in firmware, but I don't think it is worth complicating the
    host code with minor time adjustments until and unless firmware-based
    time stamps become available.
2021-12-02 fix stream glitch on rate change
    [hackrf_core.c]
2021-12-03 Cleanup of host software CMake build system (#664)
    * Clean up the CMake build system and improve the FindFFTW3 module.
    * Fixes for Linux build
    * Include winsock.h to get struct timeval
    * Couple more fixes for MSVC, also add new FindMath module
    * Update host build README for new CMake changes (esp. Windows)
    * Try to fix Travis OS X build error
    * Add docs about pthread-win32
    * Whoops, AppVeyor caught a bug in FindFFTW where the includes not being found weren't generating a fatal error.
    * Travis rebuild bump
    * One more fix: replace hardcoded include paths with a PATH_SUFFIX to standard include paths
    * Invert Windows preprocessor flag so it's only needed when using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
2021-12-12 start Opera Cake frequency mode correctly
    When switching to frequency mode or modifying the frequency ranges,
    ensure that the Opera Cake is switched to the correct port on the very
    next tuning.
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2022-01-03 Use stack pointer to hold base address of state structure.
    Keeping the base address of this structure in a register allows us to
    use offsets to load individual fields from it, without needing their
    individual addresses.
    However, the ldr instruction can only use immediate offsets relative to
    the low registers (r0-r7), or the stack pointer (r13).
    Low registers are in short supply and are needed for other instructions
    which can only use r0-r7, so we use the stack pointer here.
    It's safe to do this because we do not use the stack. There are no
    function calls, interrupt handlers or push/pop instructions in the M0
    code.
    This change saves four cycles by eliminating loads of the addresses for
    th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
2022-01-03 Correct a misleading comment.
    The effect of the lsr instruction here is to shift the LSB of r0 into
    the processor's carry flag. The subsequent bcc instruction ("branch if
    carry clear") will then branch if this bit was zero.
    The LSB corresponds to the exchange interrupt flag for slice A only. The
    other interrupt flag bits are not checked here, contrary to the comment.
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2022-02-03 Increment a sequence number when transceiver mode changes.
    This fixes bug #1042, which occured when an RX->OFF->RX sequence
    happened quickly enough that the loop in rx_mode() did not see the
    change. As a result, the enable_baseband_streaming() call at the start
    of that function was not repeated for the new RX operation, so RX
    progress stalled.
    To solve this, the vendor request handler now increments a sequence
    number when it changes the transceiver mode. Instead of the RX loop
    checking whether the transceiver mode is still RX, it now checks whether
    the current sequence number is the same as when it was started. If not,
    there must have been at least one mode change, so the loop exits, and
    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
    [hackrf_usb.c]
2022-02-08 Move transceiver mode changes out of USB ISR.
    This is a defensive change to make the transceiver code easier to reason
    about, and to avoid the possibility of races such as that seen in #1042.
    Previously, set_transceiver_mode() was called in the vendor request
    handler for the SET_TRANSCEIVER_MODE request, as well in the callback
    for a USB configuration change. Both these calls are made from the USB0
    ISR, so could interrupt the rx_mode(), tx_mode() and sweep_mode()
    functions at any point. It was hard to tell if this was safe.
    Instead, set_transceiver_mode() has been removed, and its work is split
    into three parts:
    - request_transceiver_mode(), which is safe to call from ISR context.
    All t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
    [hackrf_usb.c]
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2022-02-13 Add USB requests and host support to set TX/RX shortfall limits.
    This adds `-T` and `-R` options to `hackrf_debug`, which set the TX
    underrun and RX overrun limits in bytes.
    [hackrf_usb.c]
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2022-09-14 Detect hardware platform at run-time.
    Firmware now detects the hardware it is running on at startup and
    refuses to run if it is compiled for the wrong platform. The board ID
    returned by firmware to the host is now derived from run-time detection
    rather than a compile-time value. A separate method to retrieve
    compile-time supported platform is added.
    On HackRF One, pin straps are checked to determine hardware revision.
    This is informational to aid troubleshooting and does not affect any
    function.
    [hackrf_usb.c]
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2022-09-26 firmware: fix duration of delay_us_at_mhz()
    [hackrf_core.c]
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2022-10-26 m0: reset M0 before starting it
    The rad1o was not starting the M0 when powered up by inserting a USB
    cable. Interestingly the M0 does start when toggling the power switch.
    Resetting the M0 before starting it in `main()` solves this issue.
    [hackrf_usb.c]
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2023-01-06 HackRF One: update trace widths for new stack-up
    correct or ignore ERC/DRC errors
    [baseband.kicad_sch, frontend.kicad_sch, hackrf-one.kicad_sch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]
2023-01-06 HackRF One: correct or ignore ERC errors
    [baseband.kicad_sch, hackrf-one.kicad_sch, mcu.kicad_sch]
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2023-01-06 HackRF One: update hardware detection pin straps
    Additionally swap:
    - EN_1V8, P6_10, U23 pin 100 (pull-down)
    - !RX_AMP_PWR, P2_12, U23 pin 106 (pull-up)
    Detecting which has the pull-up and which has the pull-down enables
    version detection that may be more reliable than the ADC method.
    [mcu.kicad_sch]
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2023-01-06 HackRF One: swap pins for platform detection
    - move EN_1V8 to P5_0, U23 pin 37
    - move !VAA_ENABLE to P6_10, U23 pin 100
    - move !RX_AMP_PWR back to P2_12, U23 pin 106
    Platform detection is now performed using P5_0 and P6_10 which avoids
    the complication of having to detect a pull-up to VAA which may not yet
    be switched on.
    [mcu.kicad_sch]
2023-01-06 HackRF One: change CLKIN_DETECT pin
    - move CLKIN_DETECT to U23 pin 15, P4_8, CTIN_5
    - move SGPIO13 to U23 pin 91, P2_5, GPIO5[5]
    - rename SGPIO13 to TRIGGER_EN
    This allows TIMER1/TIMER2 instead of TIMER3/TIMER0 to be used for CLKIN
    detection, avoiding conflicts with PortaPack firmware.
    SGPIO13 was never used for SGPIO, so it is renamed to reflect current
    usage.
    [mcu.kicad_sch]
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2023-01-06 HackRF One: correct RXBB net names
    [baseband.kicad_sch]
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2023-01-06 h1r9: swap RX Q inversion
    [sgpio.c]
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2023-01-06 h1r9: fix inverted spectrum on TX
    Unify and clean up the firmware spectrum inversion handling for all
    hardware platforms.
    [hackrf_core.c, sgpio.c]
2023-01-08 h1r9: use single SSP configuration for MAX283x
    During r9 hardware development it was thought that the MAX2839 would use
    a different GPIO pin for chip select, but it ended up being the same pin
    as is used for MAX2837 on other hardware revisions.
    This takes the MAX283x abstraction a bit further and fixes a bug with
    hackrf_debug -m.
    [hackrf_core.c, hackrf_usb.c]
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2023-09-13 Firmware updates to allow fine-grained control of biast from command line (#1314)
    * Initial commit of hackrf_biast
    * Cleaned up hackrf_biast
    * Cleaned up usage info
    * Include getopt.h for non-GNU systems
    * Add support for overriding HackRF's default antenna power behavior in firmware. Add support for specifying antenna power behavior in libhackrf.
    * Moved bias tee config routines into user_config.c, cleaned up operation of hackrf_biast
    * hackrf_biast now calls usage() and exits when invoked with no arguments
    * Fixed minor documentation error in usage()
    * minor syntax cleanup
    * Add some documentation to the host API call
    * Add proper declaration magic in hackrf.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
    [hackrf_usb.c]
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2024-02-07 HackRF One: revert hardware design to 8727449
    This commit is between r8 and r9 and will be used as the basis for r10.
    It includes some of the changes in r9 but predates the major changes to
    the clock generator and IF transceiver ICs.
    [baseband.kicad_sch, clock.kicad_sch, frontend.kicad_sch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]
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2024-02-07 HackRF One: correct T3 and T4 balun symbol
    - Swap GND pins to reflect correct internal wiring
    - Remove obsolete and apparently incorrect substitution
    [baseband.kicad_sch]
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2024-02-07 HackRF One: correct fabrication attributes and DNP
    [baseband.kicad_sch, frontend.kicad_sch, hackrf-one.kicad_sch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]
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2025-11-26 Remove 32 kHz oscillator self-test
    Reliable oscillator start-up requires several hundred milliseconds which
    is longer than we are willing to wait at every boot. We could add an
    on-demand test in the future instead of an automatic self-test.
    [hackrf_core.c]
2025-11-26 Do not halt when FPGA configuration fails: update report instead.
    [hackrf_usb.c]
2025-11-27 New method to test RTC oscillator.
    [hackrf_usb.c]
2025-12-03 firmware: fix zlp bug when IN transfer length falls on a packet boundary
    [hackrf_usb.c]
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2025-12-17 Add pin_shutdown()
    Portions of pin_setup() that establish a safe, low-power state are moved
    into the new pin_shutdown(). Use pin_shutdown() to prepare for sleep or
    reset or prior to calling pin_setup().
    [hackrf_core.c, hackrf_usb.c]
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2025-12-19 firmware: move fpga selftest to a separate file to resolve blinky linker issues
    [hackrf_core.c]
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2025-12-23 Revert "gateware: generic SGPIOInterface, simpler capture management, fix SB_MAC16 resamplers"
    [board.py, sgpio.py]
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2025-12-31 Rename hw_sync to trigger
    Replace hw_sync_mode_t with bool.
    [hackrf_core.c, sgpio.c]
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2026-01-06 Fix clock generator initialisation on rad1o.
    On the CCC 2015 rad1o badge, the Si5351C clock generator is powered
    by the RF section supply (named VDD on the schematic).
    So clock_gen_init() must be called after enable_rf_power().
    Since the Si5351C is off when the RF power is off, there should be
    no need for the shutdown/init calls at startup.
    [hackrf_usb.c]
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2026-02-19 Rename gpio.not to gpio.inv to avoid conflict with C++ keyword.
    [gpio_lpc.c]
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2026-03-03 Add 40.24 fixed-point type
    [fixed_point.h]
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2026-03-19 firmware: replace static gpio & scu definitions
    [hackrf_core.c, ice40_spi.c, platform_gpio.h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]
2026-03-23 Skip detection of conflicting Opera Cake board if a DA7219 is detected
    [da7219.c, hackrf_usb.c]
2026-03-24 Always use PLL A
    On most platforms, we previously set PLL A to use XTAL input and PLL B
    to use CLKIN, switching from one PLL to the other to change clock
    source. Now we use PLL A at all times, switching the PLL input to change
    clock source.
    This avoids output clock phase inconsistencies that can happen when
    switching output multisynths from one PLL to another. It also makes it
    possible in the future to use one PLL for sample rate and the other PLL
    for reference clocks.
    [hackrf_core.c]
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2026-03-27 Remove unused includes and avoid transitive dependencies.
    [adc.c, cpld_jtag.c, cpld_xc2c.c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]
2026-04-02 Reset only sample clock outputs when changing rate
    [hackrf_core.c]
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2026-04-10 Fixed-point format for sample rate with 36 fractional bits
    Fix overflowing division in sample_rate_set
    Avoid overflows in round_sample_rate
    [fixed_point.h, hackrf_core.c]
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2026-04-11 Add macros to clarify fixed-point constants.
    [fixed_point.h, hackrf_core.c]
2026-04-15 Correct GPIO pin assignments for CPLD JTAG on Jawbreaker.
    [hackrf_core.c, platform_gpio.c, platform_gpio.h]
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2026-05-18 Fix up IWYU issues in cpld_jtag.{c,h}.
    [cpld_jtag.c]
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2026-08-21 Allow FPGA loader functions to fail.
    [hackrf_usb.c]
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2026-08-21 Enable loading FPGA bitstream from Flash in DFU and RAM builds.
    This is a best-effort approach. If a valid bitstream address is not
    found in the flash, loading fails similarly to how it is skipped now.
    [hackrf_usb.c]
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

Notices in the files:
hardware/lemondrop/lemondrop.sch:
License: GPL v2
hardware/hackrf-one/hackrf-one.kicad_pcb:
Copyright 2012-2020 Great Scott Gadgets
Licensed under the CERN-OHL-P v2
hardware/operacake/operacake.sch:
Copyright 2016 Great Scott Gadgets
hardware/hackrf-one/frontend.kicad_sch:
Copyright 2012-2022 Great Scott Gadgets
